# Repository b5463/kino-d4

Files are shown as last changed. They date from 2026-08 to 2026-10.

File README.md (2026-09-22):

<div align="center">
  <picture>
    <source media="(prefers-color-scheme: dark)" srcset="docs/assets/brand/kino-d4-white-on-dark.png">
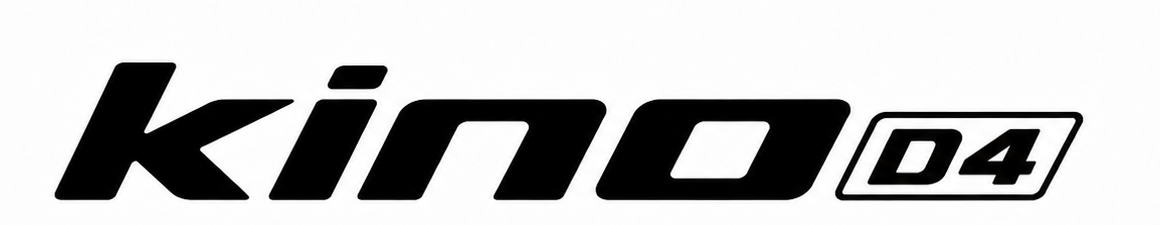
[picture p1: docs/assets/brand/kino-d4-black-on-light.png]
KINO D4
    
  </picture>

  <h3>Four cameras. One button. One moving photograph.</h3>

  <p>
    
    
    
  </p>

  <p>
    <a href="#try-studio">Try Studio</a> ·
    <a href="docs/HARDWARE.md">Hardware</a> ·
    <a href="firmware-contract/README.md">Firmware contract</a> ·
    <a href="https://github.com/users/b5463/projects/3">Project</a> ·
    <a href="docs/DEVELOPMENT.md">Build notes</a> ·
    <a href="docs/VERSIONING.md">Versions</a>
  </p>
</div>

KINO D4 is a handmade four-lens camera built for house parties. Press the shutter and four cameras fire from slightly different positions. The result can stay as four photographs or become a short, looping wiggle with real parallax.

Direct flash. 4:3 frames. Originals saved first. No cloud anywhere near the shutter.

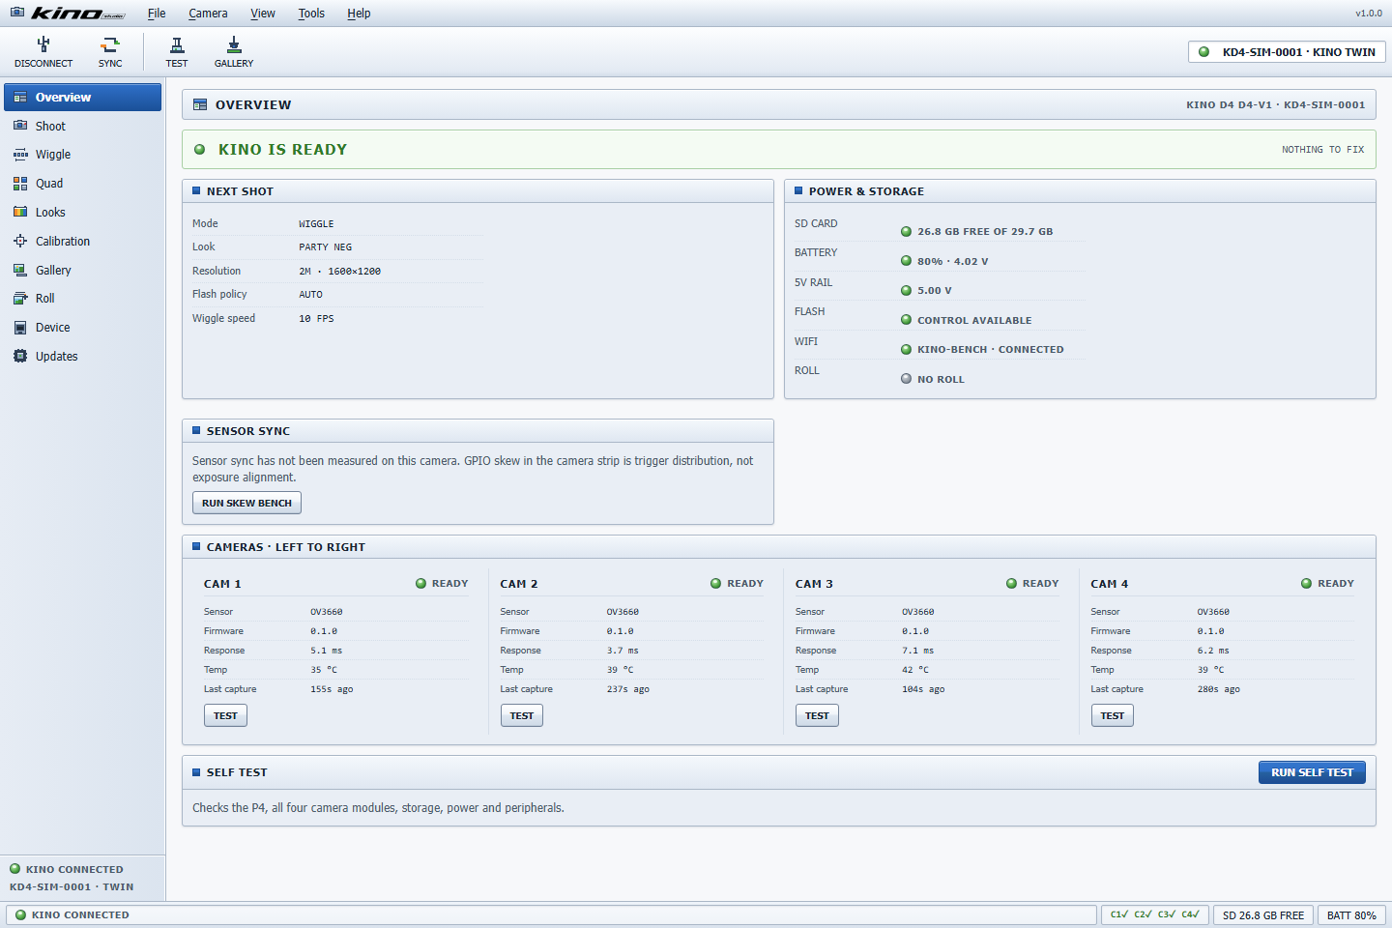
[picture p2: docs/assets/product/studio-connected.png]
KINO Studio connected to a simulated D4


<p align="center"><sub>The actual Studio overview, connected to KINO Twin — the simulated camera that ships in this repository.</sub></p>

## Why this repository exists

A five-controller camera is miserable to service with an IDE, five serial logs, and hand-edited JSON. KINO Studio puts the whole machine behind one USB cable: all four sensors, power, storage, recipes, calibration, firmware, logs, and recovery.

The repository contains that workbench, the wire protocol it speaks, the Roll backend used after capture, shared document schemas, and a reference camera that can fail on command.

> **Honest build status.** The software works against the simulated camera and is covered by tests that need no hardware. That is Studio, the protocol, the Roll backend and its workers, the guest client, and KINO Twin.
>
> There is a real camera now. Firmware 0.4.55 captures on all four cameras and writes the originals to the card. It draws its own screens. Since 0.4.4 it has uploaded to a Roll over Wi-Fi from the body itself. The body is released too: design 0.1.4, a printable PETG slab, measured rather than estimated.
>
> Three things are not finished, and it is worth naming them here rather than leaving a reader to find out.
>
> The camera has **no flash**. [`ECN-0003`](hardware/changes/ECN-0003-shutter-on-jp1-21.md) dropped the assembly and gave its enable pin to the shutter. A replacement module has not been chosen.
>
> **Exposure skew between the four cameras has never been measured.** That is the number the wiggle's quality actually rests on. Firmware reports the two skews it can observe and returns `null` for this one, with a reason.
>
> **There is no public front door yet.** The operator's line sits behind O2 carrier NAT, so `kino.acronym.sk` cannot point at the PC, and no ingress has been selected — see [the standing decision](docs/runbooks/public-ingress-options.md#standing-decision-2026-09-09). A party still works: the camera writes to its card first and uploads when it can.

## Try Studio

You need Node.js 22 or newer.

```bash
npm ci
npm run build -w @kino/studio -w @kino/twin
npm run preview:all
```

Open <http://localhost:4400/studio/>, then open <http://localhost:4400/dev/twin/> in a second tab and press **CONNECT KINO TWIN** back in Studio. KINO Twin is the simulated camera: it speaks the same protocol as hardware, so Studio exercises its full interface without a D4 on the bench.

Both apps must be served from one origin, as `preview:all` does — the bridge between them is a `BroadcastChannel`. To run them on separate dev servers instead, start `npm run twin:relay` and open Twin with `?ws=1`; Studio offers the bridge automatically in a dev build.

A physical D4 needs desktop Chrome or Edge for Web Serial.

Run the checks:

```bash
npm run lint
npm run test -w @kino/studio -w @kino/kdp -w @kino/schemas -w @kino/test-fixtures -w @kino/hardware-profiles -w @kino/simulator-engine -w @kino/three-assets -w @kino/twin -w @kino/design-system -w @kino/media -w @kino/roll-web
npm run build
```

That is every JavaScript suite that runs without Docker, and the same line CI runs. The API and worker also need PostgreSQL, Redis, and S3-compatible storage; their local stack and ports are documented in [the development guide](docs/DEVELOPMENT.md#api-stack).

Two suites are outside that line on purpose. The firmware's are C, built and run with `make -C firmware/p4/host_tests test-all` and `make -C firmware/components/kdp_core/host_tests` — 6,246 checks that need no camera, and the two that link cJSON need the IDF container. KINO Print's are Python (`npm run test -w @kino/print`), so a bare `npm test` at the root fails on a machine without Python.

## The three tools

Every screen below is a capture of the running application against the included simulator. No hardware was attached.

### KINO Studio

The workbench behind one USB cable: all four sensors, power, storage, recipes, calibration, firmware, logs, and recovery. Shown at the top of this page connected to KINO Twin.

### KINO Twin

A working 3D copy of the D4. It speaks the same KDP as real hardware: power it on, fire the shutter, watch the display, click any part for its dimensions and clearances. Measurement findings gate the enclosure lock.

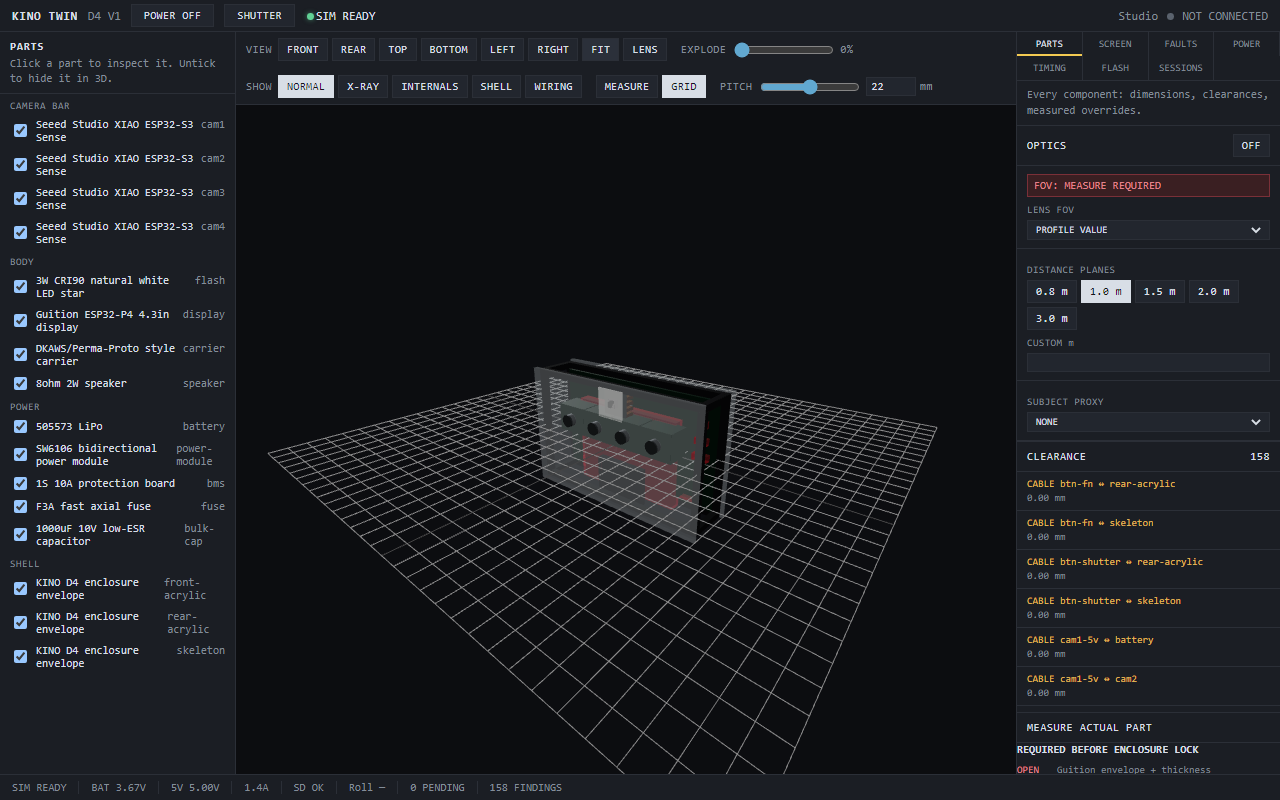
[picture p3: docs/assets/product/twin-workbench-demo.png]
KINO Twin with the simulated D4 powered on


<p align="center"><sub>KINO Twin, simulator powered on. Everything shown is simulated and labelled as such.</sub></p>

### KINO Roll

The shared album after the party. The camera uploads over Wi-Fi; guests open a link, watch photos arrive live, view the four frames behind each one, favourite and download. The client is a PWA that works on a phone at the event.

The host gets a separate surface on the same link: a dashboard that says which camera is uploading and which is stuck, hides or restores a photograph, clears the roll, and exports the lot as a ZIP. A roll can carry a PIN, and a trashed photograph stays recoverable for seven days. There is a third surface for a screen at the party — a projector page that cycles the newest captures and keeps the display awake.

The Roll is run for an event rather than hosted permanently: the origin is a laptop, reached through an outbound tunnel for the night, with no port forwarded. [`docs/runbooks/event-day.md`](docs/runbooks/event-day.md) is the procedure, and it ends by taking the tunnel down.

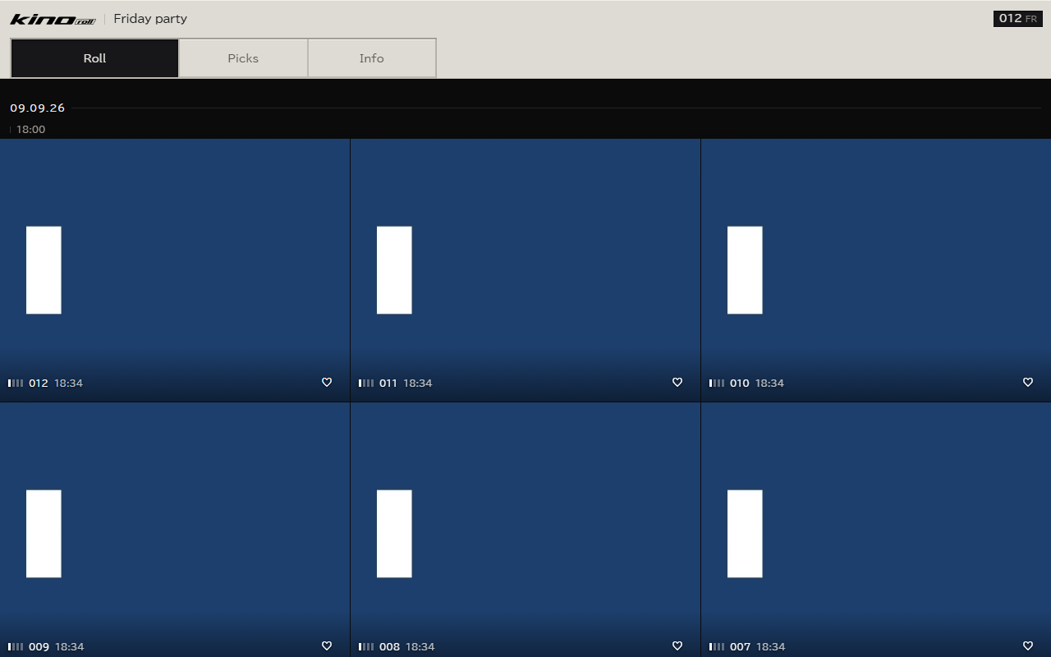
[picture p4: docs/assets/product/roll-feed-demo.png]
KINO Roll guest gallery with demo captures


<p align="center"><sub>The guest gallery with demo captures from the test uploader.</sub></p>

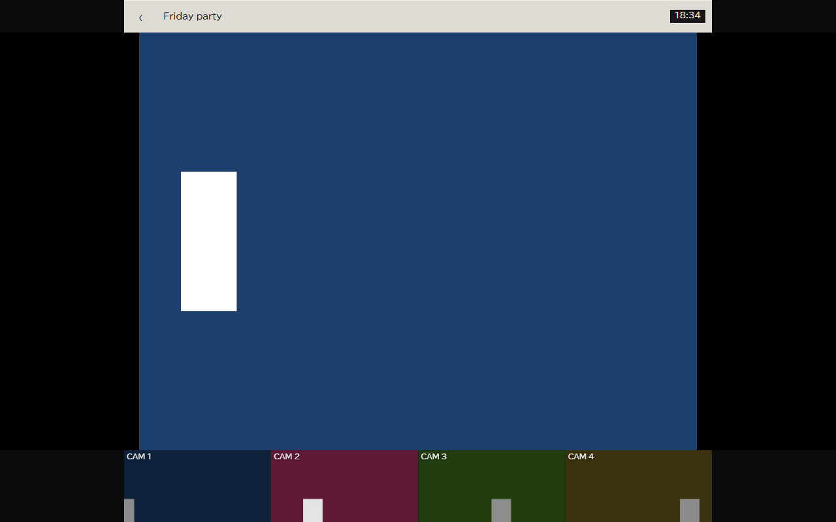
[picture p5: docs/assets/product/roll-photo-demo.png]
KINO Roll photo page with demo captures


<p align="center"><sub>One photo: the D4 frame strip switches the preview. Simulated captures.</sub></p>

### And one workshop tool

[KINO Print](apps/prusa-print-98/README.md) is not part of the camera. It is a local print host for the MK3S that prints the body, and it is here because the bodies in this repository kept failing on the bed for reasons a slicer does not warn about. It reads the PrusaSlicer metadata out of a `.gcode`, refuses to start until a person confirms the printer is physically clear, and streams the job itself. Its PETG preflight is the point: it catches a first layer that is too hot, full-temperature probing, a profile mismatch, and a nozzle that heats before the bed wait, then holds the nozzle at 170 °C through bed heating and mesh levelling and raises it just before the prime line. The source file is never modified.

## What comes out of the camera

### WIGGLE

Four matched frames play `1 → 2 → 3 → 4 → 3 → 2`. Nothing is synthesized between them. The movement comes from the four real viewpoints.

### QUAD

Each camera can use a different recipe on the same shutter press. A single capture might produce PARTY NEG, MOTION, RAW DIGI, and ACROS-ISH together.

Both modes obey the same boring, important rule: the microSD card gets the originals before anything is rendered, uploaded, cropped, or shared. Derivatives are disposable. Originals are not.

## The camera

| Part | D4 V1 hardware |
|---|---|
| Main unit | Guition JC4880P443C-I-W, ESP32-P4 + ESP32-C6, 4.3-inch 480 × 800 touch display |
| Camera row | 4 × Seeed XIAO ESP32-S3 Sense |
| Sensors | 4 × OV3660 rolling-shutter sensors, up to 2048 × 1536 |
| Storage | 32 GB microSD |
| Battery | 1S 3000 mAh LiPo |
| Flash | **Not fitted.** `ECN-0003` dropped the direct-flash assembly and gave its enable pin to the shutter; an external module will replace it and is not chosen |
| Sound | 8 Ω / 2 W speaker |
| Camera wiring | Four UART pairs plus one shared sync line |
| Body | Printed PETG slab, 131 × 90 × 65.5 mm, design 0.1.4 — two-part chassis, glued face shell, sliding lens cover, dovetail rear door |

The boards are ordinary, replaceable parts. The exact power limits, wire gauges, battery constraints, mechanical stack, and confidence level of every measurement live in [`docs/HARDWARE.md`](docs/HARDWARE.md).

Two printable bodies are released, and they are alternatives rather than versions of each other. [`KINO_FIELD_BODY`](hardware/cad/KINO_FIELD_BODY/README.md) is the one above: PETG on a desktop printer, support-free, and its release is gated by 82 automated checks over the actual meshes — that every part prints flat, and that both print jobs fit a 250 × 210 bed. [`KINO_RESIN_BODY`](hardware/cad/KINO_RESIN_BODY/README.md) is printed entirely through JLCPCB in three parts, with an MJF nylon skeleton carrying everything and a clear SLA shell that touches nothing electrical, so it can be reprinted in another colour without re-qualifying an optical dimension.

The camera knows when its cover is shut without a switch. The Hall sensor the shell used to be drilled for had to be fitted before the face shell was glued on — the one irreversible step in the assembly — so it is gone. Closed, all four lenses face an opaque plate 0.2 mm away; firmware reads a mean luminance off the frames the viewfinder already decodes and decides from all four together. It ships observing only: the two thresholds have to be read at the bench, because the sensors run auto-exposure and a covered one reports amplified noise rather than zero.

### The screen on the camera

The camera runs its own interface on the 4.3-inch panel. No phone, no laptop, nothing to pair. A card for the thing you came to do, and five rows for everything else.

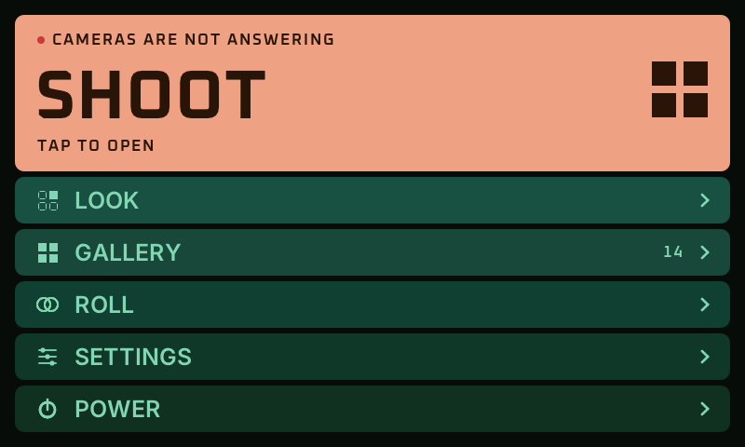
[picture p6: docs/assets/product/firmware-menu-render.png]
The D4 home screen, rendered by the firmware


<p align="center"><sub>The home screen at 800 × 480. Drawn by the firmware's own code through <code>firmware/p4/host_preview</code> — not a photograph of the panel. The chip above SHOOT is the conditions list: this render has two of its four camera stubs silent, and the screen says so before you ask it anything.</sub></p>

SHOOT is a card three times the height of anything else because the camera is not a sibling of SETTINGS. The geometry says the hierarchy, so the screen needs no status strip at all — the card carries the worst condition when there is one and how many photographs are left when there is not.

Type is Inter and Oxanium, rasterised to 8-bit coverage: Inter for everything a person reads as language, Oxanium for everything the camera says as a machine. Every corner, disc and chevron is drawn with per-pixel coverage rather than stamped from a bitmap, so no curve on the panel has a hard edge on it. The six menu marks are drawn too. No raster artwork is left in the interface.

#### It boots by showing you the camera

The startup screen is not a logo. It is a field of small glyphs on a square lattice, and both of the things it does carry a fact about the machine that is waking up.

<p align="center">
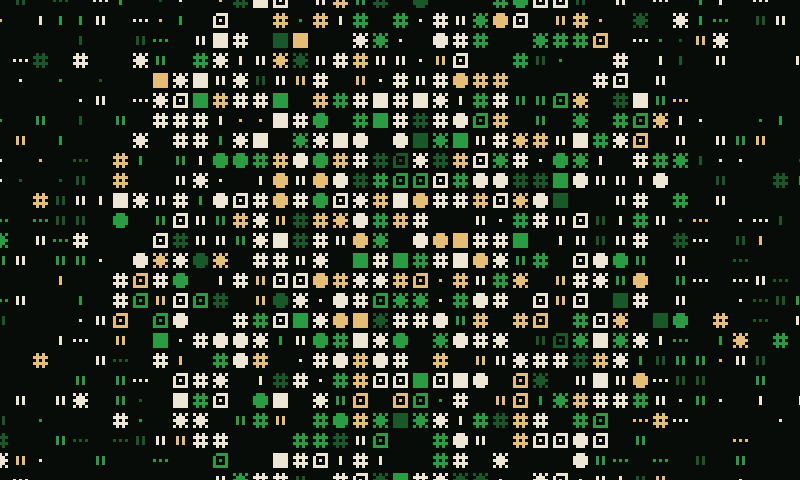
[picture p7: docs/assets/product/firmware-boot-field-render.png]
The boot field with all four cameras answering
  
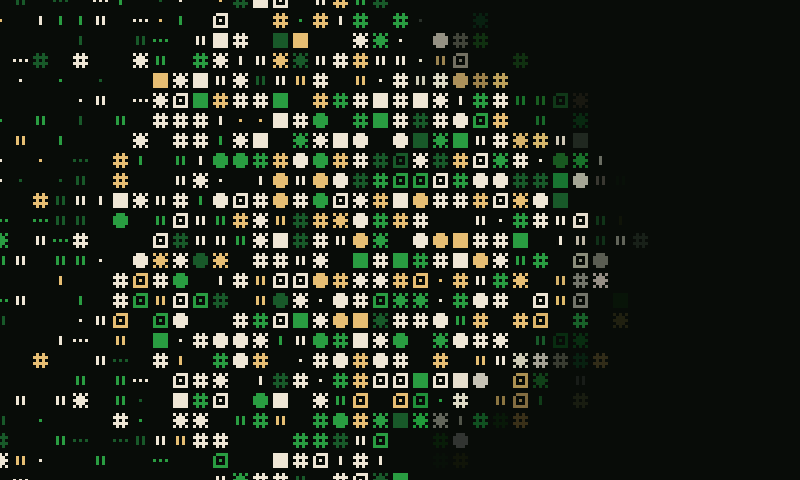
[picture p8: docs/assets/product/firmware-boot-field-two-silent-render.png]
The boot field with two cameras silent
  
</p>

<p align="center"><sub>Left: four cameras answering. Right: the same body with cameras 2 and 4 silent. Both are firmware renders.</sub></p>

**How far the field reaches is how many of the four cameras have answered** — one quadrant each, cam 1 top left, the way the four sit on the viewfinder and on the body. A node that answers part-way through the boot opens its quarter out instead of appearing. So a camera with a dead node says so on the first screen it shows, without a word of type, in the product's own mark.

**What colour it is, is the look it will shoot with.** The field comes up cold and travels to the look's own colours as the cameras answer. A given look brings the same colour up every time, so the way your camera starts becomes something you know about it.

#### The rest of it

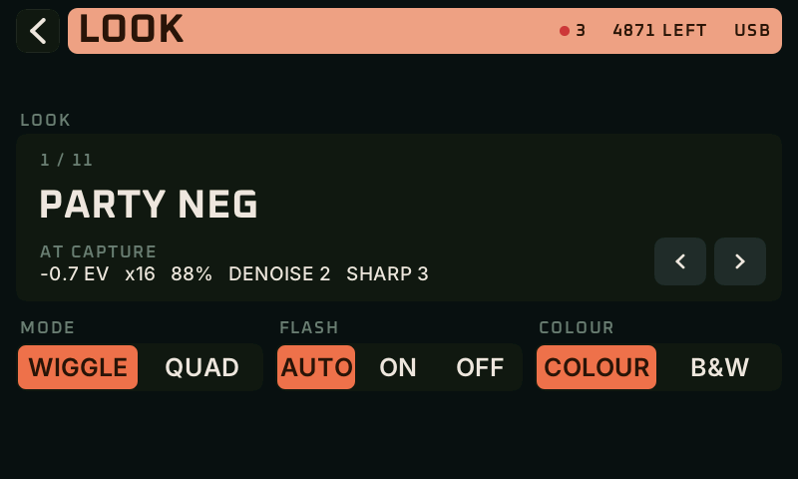
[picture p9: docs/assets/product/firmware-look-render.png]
The LOOK screen


<p align="center"><sub>LOOK: the recipe in force, what it does at capture, and the three things you can change about it.</sub></p>

ROLL is the screen that matters at a party. It shows the QR a guest scans, the address for anyone who would rather type it, one word for the connection, and a count that comes from the card rather than from the server.

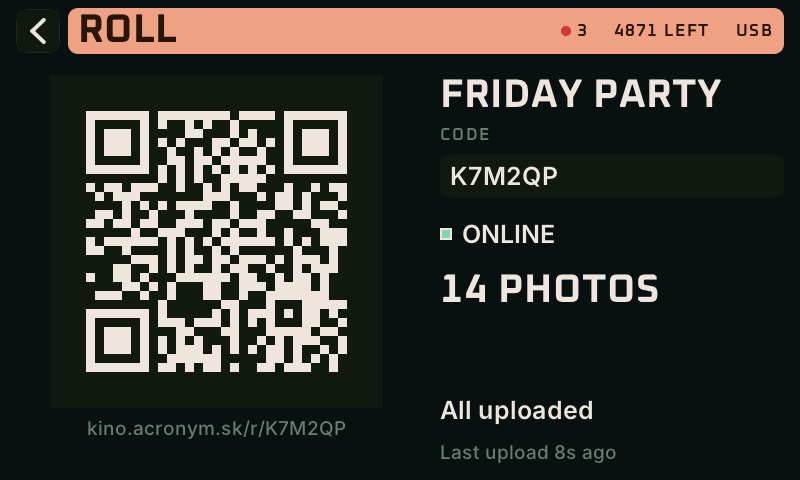
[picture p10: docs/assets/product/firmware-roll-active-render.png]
The ROLL screen with a QR code and upload state


<p align="center"><sub>Also a firmware render. The roll name and code are invented for the render.</sub></p>

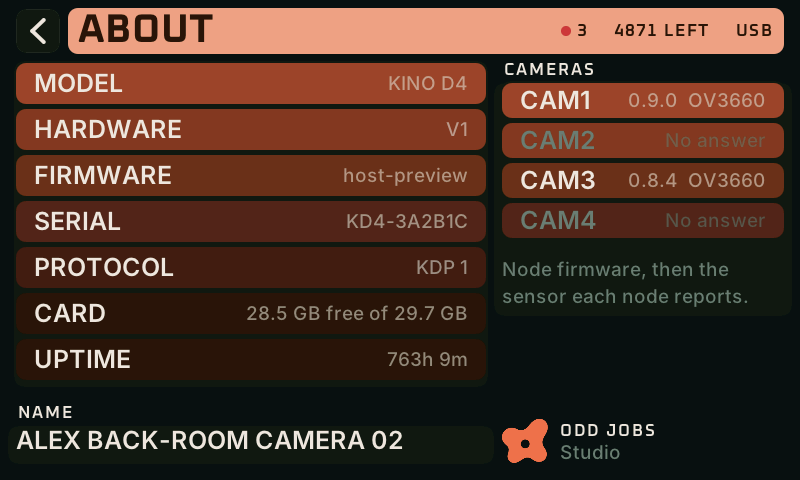
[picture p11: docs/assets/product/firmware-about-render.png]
The ABOUT screen


<p align="center"><sub>ABOUT: what this unit is, what each of the four cameras is running, and who made it.</sub></p>

All of these come out of a program that compiles `ui.c` and draws the screens on a workstation. It renders 190 of them, including every failure state — a card that will not mount, a server that has stopped answering, a capture that saved three frames out of four. Looking at the interface used to mean a build, a flash and a serial capture; now it is one command:

```bash
make -C firmware/p4/host_preview && firmware/p4/host_preview/preview out/
```

The same program is a gate, not just a viewer: it fails the run if any screen sets type outside the page margin. Clipping is the obvious fault, but the one an interface actually has is a sentence ending two pixels from the bezel — that does not look broken, it looks cheap, and it is much harder to catch by eye. It found four screens doing it the day it was written.

## One cable, five controllers

```mermaid
flowchart LR
    C1["CAM 1"] -->|"UART"| P4["ESP32-P4"]
    C2["CAM 2"] -->|"UART"| P4
    C3["CAM 3"] -->|"UART"| P4
    C4["CAM 4"] -->|"UART"| P4
    P4 --> SD["microSD originals"]
    P4 <-->|"KDP / USB"| Studio["KINO Studio"]
    P4 -->|"Wi-Fi after capture"| Roll["KINO Roll"]
    Twin["KINO Twin"] -.->|"the same KDP"| Studio
```

Feature code in Studio never reaches around the device API to poke a serial port. Real hardware, the test camera, and KINO Twin all go through the same framing, CRC checks, timeouts, commands, and capability negotiation.

That boundary matters. A simulator that gets special treatment is only a mockup. A simulator that speaks the real protocol can expose real bugs.

## The hard part is time

A shared GPIO edge does not make four rolling shutters expose at the same instant. KINO keeps three different measurements separate:

| Measurement | What it actually tells us |
|---|---|
| GPIO distribution skew | When each camera node handled the trigger |
| VSYNC phase skew | Where each sensor was in its rolling frame cycle |
| Effective exposure skew | When the scene was recorded |

A trigger spread under 100 µs can still hide 10 to 30 ms between real exposures. Studio reports the three values separately. If firmware cannot measure one of them, it returns `null` and says why.

## Repository map

| Path | Owns |
|---|---|
| [`firmware`](firmware/README.md) | What runs on the camera: the ESP32-P4 application, the four camera nodes, the C6 radio image, and the host test suites |
| [`apps/studio`](apps/studio) | Camera setup, shooting, looks, media, firmware, recovery, diagnostics |
| [`apps/api`](apps/api) | Rolls, authentication, uploads, object storage, live events |
| [`apps/worker`](apps/worker) | Derivative jobs, recaps, exports, trash purge |
| [`apps/roll-web`](apps/roll-web) | Public Roll guest PWA and private host dashboard |
| [`apps/twin`](apps/twin) | KINO Twin: 3D assembly, simulation, measurement, engineering exports |
| [`apps/prusa-print-98`](apps/prusa-print-98/README.md) | KINO Print: the local USB print host that prints the body, with the PETG preflight that stops a bad job |
| [`packages/kdp`](packages/kdp) | The KINO Device Protocol: frames, CRC, commands, transports, request lifecycle |
| [`packages/schemas`](packages/schemas) | Versioned `kino.*` documents shared across processes |
| [`packages/test-fixtures`](packages/test-fixtures) | Reference camera, recipes, media, and injected failures |
| [`packages/media`](packages/media) | Wiggle sequencing and playback, shared by the worker and the clients |
| [`packages/design-system`](packages/design-system) | The shared interface vocabulary |
| [`packages/hardware-profiles`](packages/hardware-profiles) | Board and sensor profiles the simulator and Studio read |
| [`packages/simulator-engine`](packages/simulator-engine) | The device simulation behind KINO Twin |
| [`packages/three-assets`](packages/three-assets) | Geometry and materials for the 3D twin |
| [`firmware-contract`](firmware-contract) | The contract camera firmware must implement, and every recorded deviation from it |
| [`hardware`](hardware) | BOM, wiring, assembly, acceptance tests, two released printable bodies, and the Rev1 mainboard schematic |
| [`infra`](infra/README.md) | Compose files, the deploy script, backups, and the load and latency harnesses |
| [`kino_dev_spec_pack`](kino_dev_spec_pack) | Permanent Studio and Roll product specifications |
| [`kino_twin_spec`](kino_twin_spec) | The 3D twin and virtual-device specification |

## Read the right thing

This project has history, and some old planning material is still useful. It is not always current. Start with [`docs/README.md`](docs/README.md), which says which source wins when code and prose disagree.

- [Hardware reference](docs/HARDWARE.md): parts, dimensions, power, wiring, and what still needs measuring
- [Architecture](docs/ARCHITECTURE.md): process boundaries, state ownership, uploads, and package relationships
- [Development](docs/DEVELOPMENT.md): setup, services, migrations, tests, and protocol changes
- [Troubleshooting](docs/TROUBLESHOOTING.md): browser, USB, protocol, power, sync, media, recovery, and API failures
- [Firmware contract](firmware-contract/README.md): the handoff extracted from working protocol source, and every deviation the firmware is allowed
- [Firmware](firmware/README.md): what runs on the camera, how to build all three configurations, and what each host suite covers
- [Hardware build package](hardware/README.md): BOM, wiring, assembly order, and acceptance sheet
- [Field body](hardware/cad/KINO_FIELD_BODY/README.md) and [resin body](hardware/cad/KINO_RESIN_BODY/README.md): the two printable bodies, their measured inputs, and the gates each release passes
- [Running an event](docs/runbooks/event-day.md): the whole night, from bringing the stack up to taking the tunnel down
- [Restoring from backup](docs/runbooks/restore.md) and [what to watch](docs/runbooks/observability.md): the two things needed when a party is already underway
- [Host guide](docs/roll/HOST_GUIDE.md): the Roll dashboard, written for whoever is running the camera rather than for a developer
- [Contributing](CONTRIBUTING.md): required contracts, tests, measurements, and pull request rules
- [Roadmap](ROADMAP.md): current work and the deliberately unfinished edges
- [Releasing](docs/RELEASING.md): independent versions, compatibility review, artifacts, and publishing
- [Versioning](docs/VERSIONING.md): software, protocol, schema, database, and hardware revision rules
- [Security](SECURITY.md): private reporting and the high-risk surfaces
- [Brand assets](docs/assets/brand/README.md): the four split D4 marks and where each belongs
- [Product media](docs/assets/product/README.md): real and simulated asset rules plus the physical shot list

The short version: tested protocol source beats old prose, unknown hardware measurements stay unknown, originals are immutable, and firmware changes are finished only when the contract and tests move with them.

## License

KINO software and general documentation use the [MIT License](LICENSES/MIT.txt). Physical design source uses [CERN-OHL-S-2.0](LICENSES/CERN-OHL-S-2.0.txt), which keeps distributed hardware modifications open. Logos, wordmarks, product media, and the unaudited recovery archive remain reserved.

[`LICENSE`](LICENSE) explains the boundary, [`REUSE.toml`](REUSE.toml) records it for SPDX tooling, and [`TRADEMARKS.md`](TRADEMARKS.md) keeps compatible forks distinct from official KINO releases.

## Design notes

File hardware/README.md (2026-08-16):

# KINO D4 hardware package

This directory holds the files needed to turn the D4 V1 parts list into a repeatable physical build.

## Build files

| File | Purpose |
|---|---|
| [`BOM.csv`](BOM.csv) | Parts, quantities, confidence, and unresolved purchasing details |
| [`WIRING.md`](WIRING.md) | Power topology, camera harnesses, signal directions, and the open GPIO map |
| [`ASSEMBLY.md`](ASSEMBLY.md) | Mechanical and electrical build order with checkpoints |
| [`TESTING.md`](TESTING.md) | Bring-up, load, sync, thermal, and final acceptance record |
| [`cad/`](cad/) | Mechanical source and exports once dimensions are measured |
| [`pcb/`](pcb/) | Carrier-board source if D4 moves beyond perfboard |

The maintained narrative reference remains [`docs/HARDWARE.md`](../docs/HARDWARE.md). The structured component list in [`kino_twin_spec/component-manifest.json`](../kino_twin_spec/component-manifest.json) feeds the digital twin. Keep all three aligned.

## Revision and license

[`REVISION`](REVISION) names the physical compatibility line. [`manifest.json`](manifest.json) gives the independently moving design-package version and artifact revisions. Every design change needs an [engineering change notice](changes/README.md) and a matching entry in [`CHANGELOG.md`](CHANGELOG.md).

This hardware source is licensed under CERN-OHL-S-2.0. The source location is <https://github.com/b5463/kino-d4>. See the root [`LICENSE`](../LICENSE), the unmodified [license text](../LICENSES/CERN-OHL-S-2.0.txt), and the machine-readable [`REUSE.toml`](../REUSE.toml).

## Confidence

A row in the BOM is not proof that a dimension fits. Dimensions and limits must carry one of the confidence labels from the hardware reference. `PROVISIONAL`, `CONFLICT`, and `MEASURE_REQUIRED` block final CAD.

## Revision rule

These files describe D4 V1. A change that breaks enclosure, wiring, firmware pin mapping, or replacement-part compatibility needs a new hardware revision. Do not edit V1 into a different camera while keeping the same name.

## Missing physical records

The repository still needs measured photographs, caliper records, final GPIO assignments, a locked carrier layout, and electrical test sheets from the assembled camera. The checklists here make those gaps visible. They do not claim the tests have been run.

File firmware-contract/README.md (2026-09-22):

# KINO firmware contract

The canonical reference the firmware team implements against.

Everything in these four files is **extracted from working source**, not designed here. Where the
implementation and the spec pack disagree, the implementation wins and the difference is recorded
under [Deviations](#deviations). No document in this directory introduces new protocol behavior.

| File | Contents |
|---|---|
| [`kdp-framing.md`](kdp-framing.md) | Byte layout, CRC, flags, sequence IDs, decoder requirements, payload limits |
| [`commands.md`](commands.md) | Every command and event with its numeric value, direction and payload shape; HELLO, NACK, session and job semantics |
| [`schemas.md`](schemas.md) | Portable document schemas (`kino.*`), envelope and migration rules, the timing-block contract |

## Source of truth

The prose here can rot. These files cannot — they are compiled, tested and shipped:

| Authority | Path | Covers |
|---|---|---|
| Framing | `packages/kdp/src/protocol/packet.ts` | Encoder, decoder, `MAX_PAYLOAD` |
| CRC | `packages/kdp/src/protocol/crc32.ts` | CRC-32 implementation |
| Command / event / flag values | `packages/kdp/src/protocol/commands.ts` | `Cmd`, `Evt`, `FrameFlags`, `PROTOCOL_VERSION` |
| Wire payload types | `packages/kdp/src/protocol/types.ts` | TypeScript interfaces for command payloads |
| Client semantics | `packages/kdp/src/protocol/KinoProtocolClient.ts` | Handshake, timeouts, event routing, job lifecycle |
| Timing vocabulary | `packages/kdp/src/protocol/timing.ts` | The three skew metrics and their grading bands |
| Portable document schemas | `packages/schemas/src/*.ts` | `kino.*` zod schemas, versions, migrations |
| Reference device | `packages/test-fixtures/src/MockKinoDevice.ts` | A working device-side implementation of everything below |

**If a payload shape appears in this contract but not in `types.ts`, it is marked "reference mock
only".** That means the shape is what `MockKinoDevice` produces and what Studio consumes today, but
it has no compile-time type behind it. Firmware should match it; treat it as slightly softer than
the typed surface.

Two distinct type systems are in play and must not be confused:

- **Wire payloads** (`@kino/kdp` `types.ts`) — what travels inside a KDP frame. Plain TypeScript
  interfaces, not versioned individually, covered by `PROTOCOL_VERSION`.
- **Portable documents** (`@kino/schemas`) — what gets persisted, exported, uploaded or backed up.
  Each carries `schema` + `version` and has its own migration path. See [`schemas.md`](schemas.md).

Firmware produces both. They overlap in subject (a capture, a device, a config) and differ in shape.

## What is not here: the camera's HTTP upload API

This directory covers **KDP only** — the framed protocol the camera speaks over USB-C and the
`kino.*` documents it produces. It does not describe how a capture reaches the KINO Roll server.

The camera's server-facing contract is HTTP, it is normative, and it lives in
[`docs/roll/ROLL_DEVICE_CONTRACT.md`](../docs/roll/ROLL_DEVICE_CONTRACT.md). Read it for device
registration and the bearer token, joining a roll, the multipart `init` / `part` / `complete`
sequence and its part size, the `<captureUuid>:<role>:<frameIndex>` idempotency key, resume after a
power loss, and which HTTP status the firmware must retry versus refuse.

Which document answers what:

| Question | Document |
|---|---|
| Frame layout, CRC, sequence ids, payload cap | [`kdp-framing.md`](kdp-framing.md) |
| Command and event ids, payload shapes, job semantics | [`commands.md`](commands.md) |
| `kino.*` document fields, versions, migrations | [`schemas.md`](schemas.md) |
| Any HTTP request the camera makes to a Roll server | [`docs/roll/ROLL_DEVICE_CONTRACT.md`](../docs/roll/ROLL_DEVICE_CONTRACT.md) |
| Whether a Roll upload behaviour is implemented, and where it stops | [`docs/roll/PHYSICAL_DEVICE_FLOW.md`](../docs/roll/PHYSICAL_DEVICE_FLOW.md) |

The upload contract is not copied here, and must not be: two copies of a retry rule is one copy
that is wrong. Its authority is the same as this directory's — `apps/api/src` and the committed
migrations — and it records its own deviations. The overlap between the two is only the
vocabulary: a role, a `frameIndex` and a `captureUuid` mean the same thing on both sides, and
[`schemas.md`](schemas.md) is where those are defined.

## Versioning

| Constant | Value | Where |
|---|---|---|
| `PROTOCOL_VERSION` | `1` | `commands.ts` — goes in the `VERSION` header byte and is negotiated by HELLO |
| `CONFIG_SCHEMA_VERSION` | `1` | `types.ts` — the config envelope's `schemaVersion` on the wire |
| All `kino.*` document schemas | `1` | `packages/schemas/src/*.ts` |

Rules:

- A **compatible** addition (new optional field, new command id, new capability flag) does not bump
  `PROTOCOL_VERSION`. Every parser on both sides tolerates unknown fields; unknown command ids get a
  `UNSUPPORTED_COMMAND` NACK. Gate new behavior behind a capability flag, never behind a version bump.
- A **breaking** change to framing or to an existing payload's meaning bumps `PROTOCOL_VERSION`, and
  the device must then accept the older version too for as long as it advertises it in HELLO's
  selected range.
- Document schema versions bump independently of `PROTOCOL_VERSION` and carry a migration function
  per step. See [`schemas.md`](schemas.md).

## Deviations

Recorded, not resolved. The implementation column is normative.

### D1 — Recipe vs Look: one concept, two names, split by layer

Spec 04§7 names the commands `GET_LOOKS` / `SET_LOOK` / `UPLOAD_LOOK` / `DELETE_LOOK`. Source names
them `GET_RECIPES` (0x22) / `SET_RECIPE` (0x23) / `UPLOAD_RECIPE` (0x24) / `DELETE_RECIPE` (0x25).

**The two names are not interchangeable — which one is correct depends on the layer:**

| Layer | Name | Where |
|---|---|---|
| KDP wire commands | **`*_RECIPE`** | `Cmd.GET_RECIPES` … `Cmd.DELETE_RECIPE`, `commands.ts` |
| KDP wire payload fields | **`recipe`** | `DeviceInfo.activeRecipe`, `CaptureSummary.recipeIds`, `WiggleConfig.recipeId`, `QuadSlotConfig.recipeId` — `types.ts` |
| `kino.capture` portable document | **`look`** | `look: z.string().optional()`, `packages/schemas/src/media.ts` |

Same value, two field names, and **crossing them fails silently.** `kino.capture` is a
`.passthrough()` schema and `look` is optional, so a device that writes `"recipe": "party-neg"` into a
capture document parses **clean** — no error, no warning. The unknown key is preserved verbatim, `look`
is simply absent, and every consumer that reads `look` sees a capture with no look reference. This is
a data-loss bug that validation cannot catch for you.

Firmware rules:

- Send `*_RECIPE` command ids and `recipe*` field names **on the wire**.
- Write `look` — never `recipe` — in a **`kino.capture`** document.
- The numeric command values are unambiguous either way; the document field name is not.

### D2 — `kino.device-info` vs `kino.device`

01§3 lists the schema identifier as `kino.device-info`; 05§19 prints the same example under
`"schema": "kino.device"`. `packages/schemas/src/device.ts` implements `kino.device-info`.

**Normative string: `kino.device-info`.** 05§19 is a spec inconsistency, not a second schema.

### D3 — Network / Roll / upload-queue numeric values

Spec 04§7 lists ten of these commands by name only and assigns no values. This repo allocated them,
plus `UPLOAD_ENQUEUE`, which 04§7 does not list at all — 02§16 requires a "push to Roll" gallery
action and no command existed to carry it, so it took the next free slot in the same block:

| Command | Value |
|---|---|
| `NETWORK_LIST` | `0xa0` | Optional request `{ "scan": true }` runs one bounded scan and adds `available[]` (`ssid`, `bssid`, `rssi`, `channel`, `security`, `hidden`), `scanMs` and `scanComplete` to the reply. Without it the reply is the saved `networks[]` only, unchanged. |
| `NETWORK_SET` | `0xa1` |
| `NETWORK_DELETE` | `0xa2` |
| `NETWORK_STATUS` | `0xa3` | Optional request `{ "probe": true }` adds `probe`: a timed DNS lookup of the API host (`dnsMs`, `dnsOk`, `family`) and one unauthenticated `GET /api/healthz` through the Roll HTTP client (`httpMs`, `httpStatus`, `totalMs`, `tls`, `detail`) - certificate verified, trusted clock required, no registration. Without it the reply is the saved status only, unchanged. |
| `SET_CONFIG` / `GET_CONFIG` | `network.apiBase` | Optional stored development override for the Roll API base, `http://host[:port]` or `https://host[:port]`, no path, no credentials. When set and valid it replaces the compiled production default (`https://kino.acronym.sk`) for every API request; `GET_CONFIG` shows it; `SAVE_CONFIG` persists it. This is the only way an `http://` base can reach the HTTP client. `C6_TLS` is never marked validated over an `http://` base, whatever the request succeeds at. |
| `ROLL_STATUS` | `0xa4` |
| `ROLL_CREATE` | `0xa5` |
| `ROLL_JOIN` | `0xa6` |
| `ROLL_LEAVE` | `0xa7` |
| `UPLOAD_QUEUE_STATUS` | `0xa8` |
| `UPLOAD_QUEUE_RETRY` | `0xa9` |
| `UPLOAD_ENQUEUE` | `0xaa` |

**These values are normative.** They sit deliberately above the `0x80`–`0x89` event range so a
command id and an event id can never collide in a protocol trace.

### D4 — `SYNC_BENCH` numeric value

Spec 04§7 lists `SYNC_BENCH` in the Diagnostics group and assigns no value. This repo allocated the
next free slot in KDP's diagnostics range (`0x40`–`0x45` were taken): `Cmd.SYNC_BENCH = 0x46` in
`packages/kdp/src/protocol/commands.ts`.

**`0x46` is normative.** Firmware implements `SYNC_BENCH` at `0x46`.

### D5 — Async job model additions

Spec 04§15 defines the job model in three bullets. Source adds concrete lifecycle rules that firmware
must respect on the wire — no events after `JOB_COMPLETE`/`JOB_FAILED`, no jobId reuse within a
session. Full wire expectations in [`commands.md § Async job model`](commands.md#async-job-model).

### D6 — Timing telemetry: all three keys required when the block is present

04§13 says "return null + reason" if a skew is unavailable. Source hardens this: when a
`kino.capture.timing` block is present, **all three** of `gpioTriggerSkewUs`, `vsyncPhaseSkewUs`,
`effectiveExposureSkewUs` must be present as `number | null`. Omitting a key is not a substitute for
`null` — an absent field reads as "this build has no such concept", `null` reads as "measured,
unavailable here". Only the whole block is optional. `unavailableReason` is optional and explains the
nulls. See [`schemas.md § Timing block`](schemas.md#timing-block).

### D7 — Payload cap is 16384, not ~4096

04§3 says "routine payload max ~4096 bytes" and "firmware chunk 4096–8192". `packet.ts` sets
`MAX_PAYLOAD = 16384` and the decoder rejects any declared length above it.

**16384 is the normative decoder limit.** The spec's figures are budget guidance, not a wire limit.
The reference device negotiates an 8192-byte chunk size for firmware and sound uploads.

### D8 — Command surface differs from spec 04§7's name lists

04§7 lists intended command groups. The implemented surface differs. Source is normative.

Spec commands **not implemented** — a firmware build may answer these with `UNSUPPORTED_COMMAND`
until they are added to `commands.ts`:

| Spec 04§7 name | Status in source |
|---|---|
| `GET_CONFIG_SCHEMA` | Not a command. `GET_CAPABILITIES` returns `configSchemaVersion` instead |
| `PATCH_CONFIG` | Not a command. `SET_CONFIG` takes a partial config and deep-merges it |
| `CAMERA_DISARM` | Absent (`CAMERA_ARM` 0x31 exists) |
| `CAMERA_PREVIEW_START` / `CAMERA_PREVIEW_STOP` | Replaced by a single-frame pull, `CAMERA_PREVIEW` 0x34 |
| `CAMERA_GET_TIMING` | Replaced by `CAMERA_CAPTURE` 0x33 with `{"action":"timing-test"}` |
| `GET_PROFILES` / `SET_PROFILE` | Absent |
| `GALLERY_LIST`, `CAPTURE_GET`, `ASSET_GET`, `ASSET_DELETE`, `CAPTURE_DELETE` | Replaced by the `MEDIA_*` group, `0x70`–`0x75` |
| `STORAGE_CHECK` / `STORAGE_FORMAT` | Absent (`GET_STORAGE_STATUS` 0x05 reports, does not act) |
| `UART_STRESS_TEST` | Named `LINK_BENCH` 0x44 |
| `FLASH_TEST` | Replaced by `CAMERA_CALIBRATE` 0x35 with `{"action":"flash-test"}` |
| `SPEAKER_TEST` / `BUTTON_TEST` | Absent — both are checks inside `SELF_TEST` 0x42 |
| `FW_ROLLBACK` | Allocated as `Cmd.FW_ROLLBACK` = `0x66` in `commands.ts` and reserved, but no firmware implements it — the D4 V1 P4 answers `UNSUPPORTED_COMMAND` from the dispatcher's default case (see [D15](#d15--targetid-gained-c6-and-fw_query-is-implemented-without-the-rest-of-fw_)). The reserved request/response shape is in `docs/RELEASE_TRUST.md`; `ROADMAP.md` carries it as future work. **The opcode is not free.** |

Source commands **not in spec 04§7** — repo additions, normative. Every opcode
here is allocated; none of them is a free slot:

| Command | Value | Note |
|---|---|---|
| `GET_SOUNDS` … `SOUND_DELETE` | `0x26`–`0x2b` | Custom shutter-sound storage, chunked upload |
| `CAMERA_PHASE` | `0x36` | VSYNC phase measurement and re-phasing (04§14 calls for it in prose) |
| `GET_RUNTIME_STATS` | `0x43` | Heap, temps, protocol counters |
| `SET_LINK_BAUD` | `0x45` | Camera UART baud switching |
| `SYNC_BENCH` | `0x46` | SYNC-line edge counter. Blocking, and it reports no skew — see [`commands.md`](commands.md#sync_bench--0x46) and [D4](#d4--sync_bench-numeric-value). Implemented |
| `STORAGE_SELF_TEST` | `0x47` | Non-destructive card round trip with a named failing phase. Milestone 1B (#66). Implemented |
| `CAMERA_LINK_STATS`, `CAMERA_LINK_STATS_RESET` | `0x48`, `0x49` | Per-channel UART counters. Milestone 1B (#66). Implemented |
| `CAMERA_SOAK_TEST` | `0x4a` | Async capture soak run. Milestone 1B (#66). Implemented |
| `GET_HW_VALIDATION` | `0x4b` | The runtime hardware-validation registry, 56 items. Milestone 1B (#66). Implemented |
| `STORAGE_BENCH` | `0x4c` | Sustained throughput and per-block write latency; `worstBlockMs` is the figure that decides a four-frame burst. Milestone 1B (#66). Implemented |
| `C6_RESET_BENCH` | `0x4d` | **Bench only, private.** One reset pulse to the C6 while the P4 keeps running, so ROLL-C test 3 can be run. Only a P4 built with `-DKINO_C6_RESET_BENCH=1` handles it; every other build NACKs `UNSUPPORTED_COMMAND` and moves no pin. Not gated by a capability, because no product client may send it |
| `MEDIA_THUMB`, `MEDIA_FAVORITE` | `0x72`, `0x75` | |
| `NETWORK_*`, `ROLL_*`, `UPLOAD_*` | `0xa0`–`0xaa` | Network, Roll membership and the upload queue (04§7 prose). Above the event range so a command id and an event id can never collide in a trace |

### D9 — Gallery cursor is a number, not an opaque string

04§9's example shows `"nextCursor": "opaque_cursor"` and a `filters` object in the request.
`MediaListResponse` in `types.ts` types `nextCursor` as `number | null`, and `MediaListRequest` has
`cursor?: number` and `limit?: number` with no `filters`. **Source is normative.** The reference
device caps `limit` at 100 and reports `total` and `hasMore` alongside.

### D10 — `PowerStatus.batteryV` / `batteryPct` are null on D4 V1: there is nothing to measure

`PowerStatus` in `types.ts` typed `batteryV: number` and `batteryPct: number` as required, and made
`busV`, `chargingA` and `fuse` optional with the note that a firmware without a rail ADC omits them
so *"Studio shows '—' rather than inventing 5.00"*.

**Resolved in the type, 2026-08-31.** Both fields are now `number | null`, and `batteryMeasured` and
`displayStage` are declared beside them. The deviation was one-sided: the firmware sent `null`, the
type promised a `number`, and every consumer that wrote `power.batteryV.toFixed(2)` compiled clean
and threw on a real body. A contract entry recording that the type is wrong is worth less than a
type that is right — the note stays because the *hardware* gap it describes has not closed.

**D4 V1 cannot measure the cell either.** The 505573 LiPo reaches the board through a protection
board and an SW6106 charger/boost carrier, and neither the pack nor the carrier routes a sense
divider or a fuel-gauge bus to the P4 — `docs/HARDWARE.md` §Battery and power describes the path and
no GPIO in the 2×13 header carries battery telemetry. Nothing in the camera knows the voltage.

The P4 firmware therefore sends **`null`** for both, not `0`:

| Field | 0.1.x value | Why |
|---|---|---|
| `batteryV` | `null` | `0` is a number a client draws as a flat battery. A wrong reading is worse than an absent one. |
| `batteryPct` | `null` | Same. |
| `batteryMeasured` | `false` | Added field, so a client need not infer intent from a null. |
| `state` | `"usb"` \| `"battery"` | Derived from whether a host is talking to us, **not** from the power path — the SW6106 feeds the same 5 V rail either way. |
| `charging` | `false` | Not sensable. Never reported true on this hardware. |

Clients must check `capabilities.powerTelemetry` before reading either field; 0.1.x reports it
`false`. `capabilities.powerManagement` is separately `true`, because the *other* half — `autoDimS`,
`sleepS` and `camIdleTimeoutS` from `BodyConfig` — is implemented and does work. Two flags, because
a client that wants to draw a battery and a client that wants to set a sleep timeout are asking
different questions.

This is a hardware gap, not a protocol one. It closes when the V2 carrier routes a divider or a
gauge; the field types do not need to change.

### D11 — `BodyConfig.brightness` and the dim stage have no hardware on D4 V1

`BodyConfig.brightness` is `1..10` and `autoDimS` implies a dimmed state between awake and asleep.
The Guition carrier drives the panel backlight from a plain GPIO, not a PWM channel, so the only
achievable states are lit and dark.

0.1.x therefore honours `sleepS` (backlight off) and `camIdleTimeoutS` (camera bank off via
`CAM_PWR_EN`) exactly, tracks and reports the `dim` stage in `GET_POWER_STATUS.displayStage` so a
client can show where the timeout has got to, and **ignores `brightness`**. The setting is stored and
returned unchanged rather than silently rewritten, so it is ready the moment the pin gets a
transistor.

### D12 — `jpegQuality` is a percentage on the wire and the inverse on the sensor

`jpegQuality` is documented `// 60..95` in `types.ts` and `recipeTypes.ts`, and Studio's sliders
present it that way: higher is better. `esp32-camera`'s `set_quality()` takes **5..63, where lower is
better**, and the camera node clamps to that range.

Nothing converted between them. A value of 85 sent down the node link arrived as a request for
quality 63 — the *worst* JPEG the sensor can produce — and 95 did the same. Both numbers are inside
the other scale's range, so neither end could detect it; the only symptom was that asking for better
quality made the picture worse.

0.3.0 converts in one place, `capture_quality_to_sensor()`, mapping 60..95 onto 20..5. The wire
contract is unchanged: the percentage is what Studio sends and what the settings envelope stores.

### D13 — the shared trigger wire is driven, and coordinates nothing yet

`GPIO32` (`BOARD_SYNC_OUT`, JP1 pin 19) is pulsed for 200 µs at the start of every capture, and the
pulse is timed and logged. **The camera nodes do not arm on that edge.** They expose when their
`NL_CMD_CAPTURE` arrives over their own UART, exactly as they did before the wire was driven.

The pulse exists so the trace is proven and the node-side arm becomes a node change alone. Until it
does, the four frames of a capture are separated by however long it takes to wake four workers and
put four commands on four UARTs. `kino.capture.timing` reports that figure as `dispatchSpreadUs`,
under its own name, and reports all three of `gpioTriggerSkewUs`, `vsyncPhaseSkewUs` and
`effectiveExposureSkewUs` as `null` with an `unavailableReason`.

Dispatch spread is not exposure skew and must never be presented as it: the sensors free-run with a
rolling shutter, so when a command arrived says nothing certain about when light was integrated (04
§14). `CAMERA_CAPTURE` with `action: "timing-test"` is refused with `UNSUPPORTED_COMMAND` rather than
answered, and `GET_CAPABILITIES` reports `vsyncTelemetry: false`.

`SYNC_OUT` is its own net (`GPIO32`, JP1 pin 19, in
`packages/hardware-profiles/src/profiles/d4-v1.json`). The C6 pins on JP1 (20, 22, 24, 26) stay
reserved and undriven. `FLASH_EN` **has no P4 GPIO in D4-V1**: since ECN-0003 `GPIO28`, JP1 pin 21,
carries `BTN_SHUTTER`, and `BOARD_FLASH_EN` in `firmware/p4/main/board_d4v1.h` is
`BOARD_GPIO_NONE`. Twelve P4 GPIOs reach the header — 52, 51, 50, 49, 35, 34, 32, 28 on the left
column and 33, 31, 30, 29 on the right — carrying eleven signals: the four TX/RX pairs, `SYNC_OUT`
(`GPIO32`, pin 19), `CAM_PWR_EN` (`GPIO31`, pin 10, since ECN-0002) and `BTN_SHUTTER` (`GPIO28`,
pin 21). GPIO35 on pin 15 is the one spare and must stay unconnected; it is the P4's
serial-bootloader strap, which is why the button could not have it.

A pin is not a flash, and this one was never anything else. `capture.c` configured `GPIO28` as an
output and held it low; no capture ever asserted it, so no meter ever caught an edge on it, and
`HWV_FLASH_EN_GPIO28` in `firmware/p4/main/hardware_validation.h` stayed **UNVALIDATED**. The
registry is append-only, so that row remains — as a record that the line was assigned and never
proven. It can no longer flip: nothing drives `GPIO28` as an output any more. The built-in
constant-current flash assembly is dropped from D4-V1 and an external module replaces it, with no
P4 pin in this revision and no chosen interface.

`flashControl` stays `true` and `flashHardware` stays `false`. `flashControl` describes the command
surface, which is unchanged; `flashHardware` describes a fitted flash, and there is none — now for
the plainer reason that there is no enable line either. The intended timing is recorded and not
implemented: asserted before the trigger and released as soon as every node reports its capture
finished, bounded at 900 ms, because without exposure sync a flash has to cover a window rather
than an instant, and at 350–500 mA the difference is worth bounding. Whatever the external module
turns out to be, it inherits that requirement.

### D14 — `capturedAt` is required, and the body has no clock

`kino.capture` requires `capturedAt`, an ISO 8601 timestamp. The D4 V1 has no RTC, no battery-backed
clock, and no network. A body that has never been told the time cannot produce a true timestamp, and
a *plausible* false one is worse than an obviously false one: it survives import, sorts into the
wrong place in someone's roll, and is never questioned.

So the timestamp always travels with its source. `HELLO` gained two optional additive request fields,
`hostEpochMs` and `hostUtcOffsetMin`, and answers with `clockSource`; `META.JSON` and
`CAMERA_CAPTURE` carry the same field:

| `clockSource` | What the timestamp is worth |
| --- | --- |
| `host` | A host set it this session. Trust it. |
| `persisted` | Restored across a power cycle as a lower bound. The shot happened at or after this. |
| `unset` | Never told. The reading is uptime since the epoch and is visibly not a date. |

Firmware refuses a host time outside 2020–2100, which is what a seconds-for-milliseconds mix-up
looks like, and only persists a time it was actually given.

### D15 — `TargetId` gained `c6`, and `FW_QUERY` is implemented without the rest of `FW_*`

Two changes, one cause: the D4 carries a sixth firmware image and the version model could not name
it.

`TargetId` was `CamId | 'p4'` — five images. The Guition carrier's ESP32-C6 runs a hosted-slave
image of its own, which is a second thing that can be stale in the field, and issue #133 requires it
to be reportable "alongside the P4 and nodes". So `TargetId` is now `CamId | 'p4' | 'c6'` and
`ALL_TARGETS` has six members. Purely additive: nothing reads a specific target by position, and
`ALL_TARGETS` had no consumers outside its own declaration.

`FW_QUERY (0x60)` is now implemented. Every other command in the group —
`FW_BEGIN`/`CHUNK`/`END`/`ABORT`/`STATUS`/`ROLLBACK` — still returns `UNSUPPORTED_COMMAND`, because
the shipped units still run the single `factory` slot. Since firmware 0.4.9
the repository carries `firmware/p4/partitions.csv` (issue #143): two 3072 KB
OTA slots (`ota_0` at 0x10000, where `factory` was, so older images still
flash there), `otadata`, a 256 KB NVS and a coredump partition — flashing it
erases NVS and is a bench decision, so a unit is on the new table only when
its `HARDWARE_VALIDATION.md` session says so. The FW_* transfer path now has
a real slot to land in once that flash happens. That split is deliberate: a
query is not an update path, `GET_CAPABILITIES` advertises no update capability, and version
discovery is useful long before an update mechanism exists.

Two conventions this establishes for the response:

- An empty `version` means the device could not read one — a node that has never answered, or a C6
  with no transport. It is **not** version zero and must not be rendered as one.
- `state` describes an update in progress, so an unreachable target is `idle` rather than `error`:
  nothing failed and nothing was attempted. `error` there would send someone to re-flash a chip that
  is merely unwired.

**Resolved at firmware 0.4.58: the transfer path exists.** `FW_BEGIN`, `FW_CHUNK`, `FW_END`,
`FW_ABORT` and `FW_STATUS` answer for `p4` and `cam1`..`cam4` (`firmware/p4/main/fw_update.c`), with
the shapes in [commands.md](commands.md#firmware--0x600x66) and Studio's updater as the client they
were written against. What the D4-V1 does differently from the reference device:

- No maintenance mode exists, so `MAINT_REQUIRED` is never sent. A `BEGIN` during a capture gets
  `INVALID_STATE`; a second `BEGIN` while a session is open gets `BUSY`.
- `chunkSize` is 8192 for every target. A camera image is forwarded down the node's UART in 2 KB
  `NL_CMD_FW_*` frames (`node_link.h`), each acknowledged, inside the host's 8 KB chunk.
- The P4 answers `FW_END` and restarts 0.8 s later; the link drops, which the updater already
  expects. A camera node verifies its own copy, answers, and restarts itself; the P4 reports it
  `rebooting` until its `HELLO` returns the version named at `BEGIN` (`ready`), and after 40 s of
  silence cycles the camera bank once so the node's bootloader can roll back; 95 s is `error`.
- Both images boot with rollback armed (`CONFIG_BOOTLOADER_APP_ROLLBACK_ENABLE`). The P4 confirms
  itself once the panel and the host link are up; a node confirms itself when it answers its first
  `HELLO`. An image that never gets there is rolled back on the next reset.
- `GET_CAPABILITIES` now reports `xiaoProxyUpdate: true` and, additively, `firmwareUpdate: true`.
- A node still on the single-app partition table has no slot to write and refuses `BEGIN` with
  `HARDWARE_ERROR`; the P4 relays that. Such a node is flashed once over its own USB with
  `firmware/camnode/partitions.csv`, and is updatable over the link from then on.
- `FW_ROLLBACK` stays reserved and unimplemented: the bootloader's rollback covers the case it was
  for, and a host-driven return to the previous slot is a release decision (`docs/RELEASE_TRUST.md`).
- `FW_QUERY` reported the nodes shifted by one (a 1-based loop against a 0-based accessor); fixed in
  the same change.

The `c6` target carries two additive booleans, `fitted` and `reachable`, for the same reason
`flashControl` and `flashHardware` are two flags. Without them a host sees an empty version and
cannot tell an absent chip from an unrouted one — which on the D4 V1 is exactly the distinction that
matters, since the chip is fitted and no P4-side transport pin for it is recorded anywhere
(`firmware/C6_HARDWARE_MAP.md`).

The reference device (`packages/test-fixtures/src/MockKinoDevice.ts`) reports all six targets. It
simulates no C6, so its `c6` entry carries an empty `version` and `state: "idle"` — the two
conventions above, applied: nothing could be read and nothing was attempted. (It reported five for a
while, which is why this paragraph once called that a known divergence.) Studio's `FW_QUERY`
conformance check asserts only that the five it knows are *present*, so an older body that omits
`c6` still passes; a host must therefore treat a missing `c6` key as "this body has no radio", not
as a protocol error.

### D16 — `clockSource` gains `network` in the radio build only

`types.ts` types `clockSource` as `'host' | 'persisted' | 'unset'` in both `HelloResponse` and
`DeviceInfo`, and `apps/studio/src/developer/conformance.ts` throws `ShapeError` on anything else.

The radio build adds a fourth value, `network`, because SNTP is a real and distinct source: it is
better than a value carried across a power cycle and worse than a time a bench operator typed in, and
`clock.c` needs the distinction to decide whether a certificate may be validated against the clock at
all. Collapsing it into `host` would claim a person set the time; collapsing it into `persisted` would
claim it drifts.

**Resolved in the type, 2026-09-01.** The union is `'host' | 'network' | 'persisted' | 'unset'` in
both `HelloResponse` and `CameraCaptureResult`, Studio's HELLO shape check accepts all four, and
`MockKinoDevice.setClockSource` can report `network` so a host is testable without a radio on the
bench. It was overdue rather than early: KD4-D121BC running 0.4.17 sends `clockSource: network` on
first association, and the shape check failed HELLO on a body that was behaving correctly
(`SHAPE HELLO — HELLO: unknown clockSource network`, 2026-09-01).

A consumer must keep the four distinct. Collapsing `network` into `host` claims a person set the
time; collapsing it into `persisted` claims it drifts. The default build still never emits it.

### D17 — 16 commands in `commands.ts` are not implemented by the D4 V1 P4 build

`commands.ts` declares **72** commands. The shipping P4 firmware dispatches
**56** and answers the rest with an `UNSUPPORTED_COMMAND` NACK from the
dispatcher's default case. That is the documented degradation path, and it is
exercised: no unimplemented command hangs, times out, or returns a malformed
frame.

Audited by comparing the `Cmd` enum against the `case KDP_CMD_*` labels in
`firmware/p4/main/kdp_server.c`. The count was 27 at 0.4.2; the looks and sounds
families left the table in 0.4.8 (see
[D18](#d18--set_recipe-takes-a-cam-and-the-two-families-that-left-d17)), and
`SYNC_BENCH` and `STORAGE_BENCH` left it after that. Re-count from the two
sources rather than trusting these numbers — they have been stale twice.

| Family | Commands | Roadmap |
|---|---|---|
| Camera control beyond capture | `CAMERA_ARM` `0x31`, `CAMERA_PREVIEW` `0x34`, `CAMERA_CALIBRATE` `0x35`, `CAMERA_PHASE` `0x36`, `CAMERA_FOCUS` `0x37` | Yes |
| Firmware update | `FW_ROLLBACK` `0x66` only. `FW_BEGIN`..`FW_STATUS` are implemented since 0.4.58 — see [D15](#d15--targetid-gained-c6-and-fw_query-is-implemented-without-the-rest-of-fw_) | Yes |
| Maintenance | `ENTER_MAINTENANCE` `0x50`, `EXIT_MAINTENANCE` `0x51`, `FACTORY_RESET` `0x53` | Yes |
| Bench | `LINK_BENCH` `0x44` | Yes |
| Link | `SET_LINK_BAUD` `0x45` | Yes |

`SYNC_BENCH` (`0x46`) is **dispatched** and used to sit in the Bench row above.
It is a blocking edge counter, not the async job the contract once described —
see [`commands.md`](commands.md#sync_bench--0x46). `STORAGE_BENCH` (`0x4c`) is
dispatched too.

Every family above is on `firmware/FIRMWARE_ROADMAP.md`. None is an accidental
omission, and none is a protocol disagreement — the wire contract is agreed,
the behaviour is simply not built yet.

**No capability flag covers the families that are left.** `GET_CAPABILITIES`
advertises `benchDiagnostics`, `configStore`, `customSounds`, `flashControl`,
`flashHardware`, `gallery`, `mediaIndex`, `network`, `powerManagement`,
`powerTelemetry`, `quad`, `radioFitted`, `radioRouted`, `recipes`, `roll`,
`rollUpload` and `wiggle`; there is still no `firmwareUpdate`, `maintenance`,
`calibration` or `preview` flag. A client discovers those four by sending and
reading the NACK rather than by asking first, which contradicts the rule in
[Versioning](#versioning) that new behaviour is gated behind a capability flag.

The fix was stated here as "a flag per family, with the first family to be
implemented" and that is what 0.4.8 did: `recipes` is new and `customSounds`
went true, both read off the same two predicates the dispatcher gates on
(`kdp_recipes_capable()`, `kdp_sounds_capable()`), so neither flag can claim
what the handler will refuse. `recipes` is optional in `Capabilities` because
firmware older than 0.4.8 omits it; an absent flag means the commands NACK,
not that the answer is unknown. The four families still listed above take the
same treatment when they land.

`benchDiagnostics` is honest: it gates `GET_STORAGE_STATUS`,
`CAMERA_LINK_STATS`, `CAMERA_LINK_STATS_RESET`, `GET_HW_VALIDATION`,
`STORAGE_SELF_TEST`, `STORAGE_BENCH`, `CAMERA_TEST` and `CAMERA_SOAK_TEST`, all
of which are implemented. `LINK_BENCH` and `SYNC_BENCH` are not behind it —
`LINK_BENCH` is the one `*_BENCH` command with no handler.

**Four cases in Studio's own conformance suite cannot pass against 0.4.17.**
Measured on KD4-D121BC, P4 0.4.17, 2026-09-01: 32 cases (8 active, 24 passive),
25 pass, 4 `UNSUPPORTED`, and one camera channel skipped because only CAM1 is
fitted on that unit.

| Case | Opcode | Why it cannot pass |
|---|---|---|
| `CAMERA_CALIBRATE (get)` | `0x35` | Not dispatched. Per-camera alignment calibration is not built; the D4 V1 body has no stored calibration to read back. |
| `CAMERA_PREVIEW frame` | `0x34` | Not dispatched, and **nothing replaces it**. There is no KDP way to get a preview frame off this body. |
| `MAINTENANCE enter/exit` | `0x50` | Not dispatched — the whole Maintenance family is on the roadmap, not in the build. |
| `FW_BEGIN gate (outside maintenance)` | `0x61` | Not dispatched. A near miss worth noting: the case expects a refusal citing maintenance and gets `UNSUPPORTED_COMMAND`, so the gate it tests is satisfied in substance while the assertion still fails. |

**There is no live-viewfinder KDP command.** This entry named
`CAMERA_VIEWFINDER` as "the live viewfinder path"; no such identifier exists in
`packages/kdp/src/protocol/commands.ts`, in
`firmware/components/kdp_core/include/kdp/protocol.h`, or in the dispatcher. The
viewfinder is **body-local**: `firmware/p4/main/viewfinder.c` pumps frames from
one camera over the node link's own `NL_CMD_CAPTURE` and draws them on the
panel. What reaches KDP is a read-only `camera.viewfinder` block in
`GET_CAMERA_INFO` (`{ frames, fpsX10, drops }`, firmware 0.4.18+) plus
`viewfinderFpsX10` — statistics, not pixels. `shoot.viewfinder` in the config
store chooses which camera feeds it. A host cannot start, stop or read the
finder, and `CAMERA_PREVIEW` — the one command that would hand over a frame —
is not dispatched. Do not build a Studio preview against this body.

All four are dispatcher-default NACKs, which is the documented degradation
path, so the run is what a correct 0.4.17 body looks like. A fifth status —
`error`, not `unsupported` — is a regression signal and not expected here: an
`UNSUPPORTED` case whose opcode is on the table above is an expected gap, and
anything else at those four names is new.

`CAMERA_TEST (CAM2)` used to report `ERROR — Camera node not connected` on a
one-camera bench unit. That was the hardware being honest, so the per-camera
cases now skip and name the channel (`camMissing` in `conformance.ts`, fed by
`GET_CAMERA_INFO`); an unfitted camera is not a firmware failure and must not
be printed as one. `CAMERA_PREVIEW frame` aims at the first fitted channel
instead of at CAM2 by name — the opcode is what it is testing, and on a
one-camera unit the hardcoded channel hid the `UNSUPPORTED_COMMAND` answer
behind "CAM2 is offline". `CAMERA_CAPTURE timing-test` skips on a body that
advertises `vsyncTelemetry` with fewer than four channels fitted: a spread
across four cameras cannot be measured with three, and 0.4.17 reports
`vsyncTelemetry: false` and takes the refusal branch whatever is populated.

`GET_RECIPES` left this list at 0.4.8 and a `GET_SOUNDS` case joined the suite
beside it; both are read-only, so both stay `active: false` — the flag marks a
case that changes device state, not a case that is switched on.

### D18 — `SET_RECIPE` takes a `cam`, and the two families that left D17

Firmware 0.4.8 implements the ten looks and sounds commands with the request
and response shapes `MockKinoDevice.ts` has always answered, so nothing on the
wire changed for a host that was already speaking to the mock. Four things are
decided here rather than inherited.

**`SET_RECIPE` gains an optional `cam`.** `SetRecipeRequest` in `types.ts` is
`{ id, cam? }` where `cam` is `CamId | 'all'`. Absence is the original
behaviour and not a default to be filled in: no `cam` writes
`wiggle.recipeId`, `"cam1"`..`"cam4"` write `quad.slots.<cam>.recipeId`, and
`"all"` writes all four slots and wiggle. The reply is
`{ ok: true, id, cam }`, echoing `cam` as sent so a host can see which target
was written. An unknown `id` — checked against factory and custom together —
is `NOT_FOUND` rather than stored; a config naming a look the device does not
have is how a slot ends up rendering as the wrong picture at import. A `cam`
that is neither a camera nor `all` is `INVALID_ARGUMENT`. `DELETE_RECIPE` of an
id the camera does not hold is `NOT_FOUND`. `NOT_FOUND` means the document is
not on the card. A delete that fails for any other reason — a card gone
read-only, a pulled card, an I/O error — is `STORAGE_ERROR` naming the errno
(firmware **0.4.10**), because the look is still there and a host told
`NOT_FOUND` would drop it from its list and see it return at the next
`GET_RECIPES`. A malformed id is `BAD_REQUEST`;
the mock answers `{ ok: true }` to any delete, and the firmware is the one to
follow — a retry after a lost ACK sees `NOT_FOUND` and knows the first delete
landed. Firmware older than
0.4.8 ignores the field, so a host that needs a per-slot write on an older
body sends `SET_CONFIG` instead.

**`SOUND_END` may NACK `BAD_FORMAT`.** The mock checks length only, and length
is not a format: it accepts any 44-byte-or-larger blob and stores it. Firmware
parses the RIFF/WAVE header and refuses anything that is not PCM, mono,
16-bit, 16 kHz, because the playback path has one sample rate and no
converter, and a clip that fails there fails at a shutter press rather than at
upload. This is a firmware code the mock does not raise; a host must handle
it, and the mock cannot be used to prove it never happens.

**The factory looks are one document with two copies, and they have to be
equal.** `firmware/p4/main/factory_recipes.json` is compiled into the P4
image; `packages/test-fixtures/src/factoryRecipes.ts` `FACTORY_RECIPES` is
what Studio and every test read. Neither is normative alone.
`packages/test-fixtures/tests/factoryRecipeParity.test.ts` compares them id by
id — eleven entries, `factory: true` on each, deep equality, order-insensitive
— so editing one and not the other is a red test. Without it the difference
would show as a picture on the bench that is not the picture in the app, which
is not a failure anything reports.

**Card paths.** Custom looks are `/sdcard/KINO/RECIPES/<id>.json`, custom
clips `/sdcard/KINO/SOUNDS/<id>.wav` with a sidecar for name and duration. An
upload is written to a temporary file and renamed at the end, so a power cut
mid-transfer leaves nothing half-written rather than a truncated look the
validator would then have to reject on every boot. Limits are the mock's:
eight custom clips, 128 KB each, 8192-byte chunks. Sound ids match
`^snd-[a-z0-9-]{1,19}$`; look ids are whatever `validateDeviceRecipe`
accepts (`^[a-z0-9][a-z0-9-]{0,47}$`), because the firmware validator mirrors
that function rather than restating it.

**What none of this does.** The camera stores and selects a look. It does not
apply one: no capture block reaches a sensor register, and a look is still
applied at import. `wiggle.recipeId` defaults to `party-neg`, which is the
mock's default and now the firmware's.

> **Superseded in part by [D19](#d19--nl_cmd_sensor-and-the-settings-that-finally-do-something)
> (firmware 0.4.9).** "No capture block reaches a sensor register" was true of 0.4.8 and is not true
> now: `NL_CMD_SENSOR` carries exposure bias, gain ceiling, denoise, sharpness and quality to the
> node, which clamps them and reports back what it set. What survives unchanged is the rest of the
> sentence — grading is still applied at import, and the sensor knobs a look can move are the five
> the driver exposes, not the look's colour science.

**`SOUND_BEGIN` validates the id and bounds the name.** The id must match
`^snd-[a-z0-9-]{1,19}$` (`BAD_ID`) because it becomes a path under
`/sdcard/KINO/SOUNDS`. The name is 1..32 characters (`SOUND_NAME_MAX` in
`types.ts`) and a longer one is `BAD_NAME`, not a truncation: a silently
shortened name returns on the next `GET_SOUNDS` as a clip the host did not
upload, and the host cannot tell that from a name it got wrong itself. The
mock enforced neither and now enforces both.

### D19 — `NL_CMD_SENSOR`, and the settings that finally do something

Firmware 0.4.9 changes no KDP command and no KDP payload. Everything here is
either behaviour behind a field that was already on the wire, or traffic on the
node link, which is not KDP and is not part of the host contract. A host that
was speaking to 0.4.8 needs no change to speak to 0.4.9; what changes is that
seven settings it could already write stop being decoration.

**`NL_CMD_SENSOR` (`0x15`) is a node-link command, not a KDP one.** Request
`{aeLevel?, gainCeiling?, denoise?, sharpness?, quality?}` — every field
optional, absence meaning "leave that knob alone", which is what the P4's
change-only cache depends on — reply
`{ok, applied:{…}}`. The node clamps each value to the driver's range and
reports what it set, not what it was asked for; `NL_CMD_STATUS` carries the
last applied set so a bench can read the sensor's state without taking a
photograph. The numbering is the node link's own and has no relationship to
the KDP command ids — `0x15` is `MEDIA_LIST` over KDP and means nothing here.

**The merge order is fixed and has three steps.** Before each capture the P4
builds one sensor request per camera: the mode's own defaults first, then the
active look's capture block (`jpegQuality`, `exposureBias`, `gainLimit`,
`denoise`, `sharpness`) where the look sets one, then — in QUAD only — that
slot's `exposureBias` and `gain` from `quad.slots.camN`. The slot wins because
it is the per-camera control and the look is the shared one; a look that sets
nothing changes nothing rather than resetting to a default. WIGGLE has no
slots, so the wiggle look's capture block is the last word there.

**The mappings are lossy in one direction and say so.** `exposureBias` is an EV
in `-2..+2` with one decimal; `set_ae_level()` takes an integer `-2..2`, so the
EV is rounded to the nearest step and -1.5 EV and -1.4 EV reach the same
sensor. `gain` is `auto` / `low` / `high`: `auto` leaves AGC untouched, `low`
sets a gain ceiling of 4x, `high` sets 32x. Both mappings are pure C and
host-tested; neither is applied on the P4's side of the link, so what a
photograph got is what the node reported back.

**`META.JSON` records what was applied, per frame.** Each entry in `frames[]`
gains an optional `sensor` object — `{aeLevel, gainCeiling, denoise,
sharpness, quality?}` — holding the node's echoed values. `quality` is on the
sensor's own 5..63 scale, not the 60..95 wire percentage; D12 is the conversion
and it happens before the link, not after. `quality` is the one field that
records what the frame was ENCODED at rather than what a sensor apply echoed:
`NL_CMD_CAPTURE` writes that register too when the request carries the field,
and so does every viewfinder frame, so the value META carries is the value the
register held at the exposure — the node's echo when `NL_CMD_SENSOR` still owns
it, otherwise the quality this capture's own command sent, after the node's
5..63 clamp.

**A sensor failure never blocks a capture.** A NACK, a clamp the P4 did not
expect, or a timeout on `NL_CMD_SENSOR` is logged and the trigger goes out
anyway. The frame's `sensor` object then records the sensor's STANDING values
— the last apply that camera accepted — because the sensor really does still
hold them, and recording them beats recording nothing.

The exception is `quality`, and the reason is the preview. The viewfinder has no
sensor command of its own: each preview frame is an `NL_CMD_CAPTURE` carrying
the finder's own quality, which the node applies before it exposes. So a preview
between two photographs leaves the preview's value standing, the P4's
change-only cache forgets its quality for that camera and re-sends it before the
next trigger, and if that send fails the frame records the quality its own
CAPTURE carried instead of the look's. Firmware 0.4.9 did neither: the second
and later captures after a preview were encoded at preview quality while META
reported the look's, and it never self-healed. Fixed in **0.4.10**.

The object is absent
only when nothing has ever been applied to that camera since its node booted,
or on firmware older than 0.4.9; neither means the frame is bad. The
alternative — refusing the capture over a settings write — is the wrong trade
in a camera.

**What still does not happen.** The rest of a look — contrast, saturation,
temperature, and the other grading fields — stays Studio's at import. No
grading runs on the camera. `colorMode: 'mono'` is still not applied on the
body: the slot stores it, `META.JSON` carries it, and the mono conversion
happens at import as it always has. That is a product decision still open, not
an oversight.

**`capabilities.brightnessControl`.** Optional boolean, `false` on D4-V1 for
the reason D11 already records: the backlight is on a plain GPIO and the only
states are lit and dark. It exists so a host can grey the slider honestly
instead of offering a control that writes a value nothing reads. Firmware older
than 0.4.9 omits the flag, and a host must read absence as "unstated", not as
"no" — Studio's `supports()` leaves the control live on a missing flag and
disables it only on an explicit `false`.

**`body.name`.** A string, 0..24 characters, default `""`, written with
`SET_CONFIG` like every other body field and shown on the body's About screen.
`config.device` is the serial and remains the identifier; this is the name a
person gives the unit. It is optional in `BodyConfig` because a `GET_CONFIG`
from a body older than 0.4.9 returns a `body` block without it; absent and `""`
mean the same thing.

### D20 — `CaptureFile.sha256` and `CaptureInfo.meta` are omitted by MEDIA_INFO

`CaptureFile` typed `sha256: string` and `CaptureInfo` typed `meta` as a required object. The P4
never sends the first and does not always send the second, so every `MEDIA_INFO` reply from real
firmware was a lie the compiler endorsed — the same shape as D10, and the same outcome: Studio's
`file.sha256.toLowerCase()` and `info.meta.batteryV.toFixed(2)` compiled clean and threw on the
first capture off a real card.

**Resolved in the type, 2026-09-01.** Both are optional now. The behaviour they describe is not a
bug and does not change:

| Field | 0.1.0+ | Why |
|---|---|---|
| `files[].sha256` | always absent | Hashing four multi-megabyte JPEGs on request blocks the KDP link for seconds. The key is omitted rather than filled with a wrong or empty digest — see the comment at `handle_media_info` in `firmware/p4/main/kdp_server.c`. |
| `meta` | absent when the capture's `META.JSON` did not parse | The handler attaches the block only when it read one (`if (meta)`). A folder written by a body that lost power mid-write, or assembled by hand, has frames and no document. |

A host must therefore:

- treat a missing digest as **unverified**, never as verified. `downloadCaptureFile` in Studio
  returns `{ data, verified }` and checks the bytes only against a digest that arrived; the
  inspector's TRANSFER CHECK row and the tether notice say which of the two happened. A download
  refused for want of a digest would make the gallery unusable on every shipped body, and a
  download called verified without one is worse than the crash it replaced.
- print a dash and the reason for every row `meta` would have filled. `0` there is not a neutral
  value: it reads as a simultaneous trigger and a flat cell.
- accept a `META.JSON` with neither field. Studio's folder import required both and reported the
  metadata of every tethered capture as unreadable; a malformed digest is still rejected, because a
  wrong digest is worse than none.

Verifying a transfer needs a digest the body can afford to produce — a CRC over the file as it is
read, or a digest computed once at capture and stored in `META.JSON`. Neither exists yet, and
neither is a protocol change: `sha256` stays optional and starts arriving when something computes it.

The reference device omitted nothing, which is why no test caught this. `scenarios.mediaInfoAsShipped`
answers `MEDIA_INFO` the way the firmware does — no digests, no `meta`, and `META.JSON` refused on
`MEDIA_READ` so the two agree.

## Decided — was "firmware team decision required"

Issue #5 closed the six open questions this section used to list. They were open because physical
firmware cannot guess them, and a bench is a bad place to discover a design question. Each decision
below is now source: `commands.ts`, `types.ts`, `packet.ts` and the reference device implement it,
and a test pins it.

Three of the six are ratifications rather than inventions. Where the client, the reference device
and the P4 dispatcher already agreed on a behavior, the decision is to keep that behavior and forbid
firmware from being stricter — changing it would break a host that is entitled to the old one.

1. **`STATUS` (0x81) and `FW_PROGRESS` (0x82) — reserved, not emitted.** Neither has a producer or a
   consumer, and neither is on the 1B path: firmware update is gated behind `xiaoProxyUpdate`, which
   0.1.x reports `false`. A 0.x device **must not** emit either id. The shape stays undefined on
   purpose — defining it now would be guessing at a payload for a feature whose flow does not exist,
   and a wrong guess is worse than a gap. When the update path lands, `FW_PROGRESS` takes the shape
   `FwStatusResponse` already has, and that is the moment to write it down. The host drops unknown
   events, so a stray one is survivable but out of contract.
2. **Sequence-ID wraparound — wrap to 1, never to 0.** `nextSeq()` in `packet.ts` is the rule, and
   firmware mirrors that one function. Sequence 0 is the events' sentinel; a uint32 counter left to
   overflow naturally would start minting requests that look like events to anything reading the
   field literally. No session runs long enough to reach it, which is exactly why both sides have to
   agree in advance instead of meeting the overflow separately.
3. **HELLO is not mandatory — and firmware must not make it so.** The client does not enforce
   ordering, the reference device answers any command without one, and `kdp_server.c` dispatches
   without checking. Three implementations already agree; a stricter firmware would reject hosts that
   are within contract. HELLO stays the only way to obtain a `sessionId`, and commands that need
   session state (sound upload, firmware sessions) keep answering `NO_SESSION` — that is a
   per-command precondition, not a connection-wide one. Because there is no such thing as a rejected
   pre-HELLO command, no rejection code is needed.
4. **Binary media resume — offset restart is the whole mechanism.** 04§10 asked for per-chunk CRC and
   a completion hash. The per-chunk CRC is the frame CRC, which already covers every byte of every
   chunk and is checked before the payload is handed up. There is no completion hash in v1: `MEDIA_INFO`
   carries the size, a short read is visible without one, and hashing a 4 MB JPEG on the P4 costs
   more than it proves. Resume is "ask for a different offset", and firmware must serve any valid
   offset into a file it listed.
5. **`GET_MODES` (0x20) and `CAMERA_ARM` (0x31) — the reference payloads are now the spec.**
   `GetModesResponse` = `{ modes: ShootMode[] }` and `CameraArmResponse` = `{ ok, armWindowMs }` live
   in `types.ts`, and the reference device is typed against them. `armWindowMs` is not optional: with
   no CAMERA_DISARM, the window is the only thing that tells a host when the sensors fall back to
   `ready`. Neither command is in the 1B set, so 0.1.x NACKs both `UNSUPPORTED_COMMAND` — the payload
   is decided for the firmware that implements them, not smuggled into this one.
6. **`JOB_PROGRESS` for a job this session never started — sanctioned, but only after a reconnect.**
   A host that reconnects mid-job legitimately receives progress for a job it did not start, so the
   client's bounded orphan map is contract, not tolerance. What a device must not do is invent jobs:
   every `jobId` it reports has to correspond to work some host asked for. Unbounded orphan traffic
   is a firmware bug, and the host's bound is what keeps it from being a host bug too.

**Compatibility.** None of the six bumps `PROTOCOL_VERSION`. Four are documentation of behavior that
already shipped, one adds response types for commands no 0.1.x device answers, and the wrap rule is
unreachable in any real session. KDP stays at **1** for all of 0.x, and `versions.json` keeps
`protocol.kdp: 1`. New behavior goes behind a capability flag; the version byte changes only when the
framing or an existing payload's meaning does.

### D21 — `GET_MODES` answered a shape this file never described, and lied about availability

Two defects in one reply, found on 2026-09-01 by the first run of the
conformance suite against real hardware (KD4-D121BC, P4 0.4.17) — the suite
was browser-only until issue #155 gave it a terminal runner, so nothing had
compared this reply to the contract since the capture pipeline shipped.

**The shape.** `GetModesResponse` in `packages/kdp/src/protocol/types.ts`
declared `{ modes: ShootMode[] }`, a bare array of strings. The P4 has answered
`{ active, modes: [{ id, name, available, unavailableReason }] }` since 0.3.0.
Nothing caught it: `MockKinoDevice` matched the stale type, so every test
passed, and the only reader was the conformance case, which failed with
`MODES: missing wiggle` the first time it met a real camera. **Resolved by
widening the type to the shape the firmware sends** — the richer form carries
the availability, which is the point — and by making the mock answer it too.

**The lie.** `available` and `unavailableReason` were compile-time constants:
`false` and `"No capture pipeline in this build"`, a string from the M1B era
that nobody revisited when capture landed. Measured in a single conformance
run: `GET_MODES` reported both modes unavailable for want of a capture
pipeline, and eleven cases later `CAMERA_CAPTURE` stored `CAP_000629`,
1 frame, `complete`, in 2980 ms. Every host asking this camera what it could
do was told it could not shoot.

**From firmware 0.4.18** both fields are derived from the predicate
`capture_fire()` itself uses, in its order — a mounted card first, then a
camera node that answered — so `available: true` means a capture requested at
that instant would be taken. `unavailableReason` is `null` when available and
always present. `SD_FULL` and `BUSY` are deliberately excluded: the first is
arithmetic about a capture nobody has requested, the second is a sample of a
state `capture_request()` re-checks, and either would make the field flicker.

**Both modes report identically, and that is the truth rather than the old
shortcut.** `capture_fire()` never consults the mode when deciding whether it
may shoot — only which look and exposure to send each sensor. A quad with one
camera stores one frame and commits `complete`. Availability is a property of
the body, not of the mode. Advertising "quad needs four cameras" would be the
same class of lie pointing the other way; a host that wants the pane count
reads `GET_CAMERA_INFO`.

`active` remains a stored selection that survives a reboot and may name an
unavailable mode. That pair is coherent — it is what the camera will shoot
once the reason clears — and the conformance case now asserts the coherence
in both directions.

### D22 — two additive fields the camera now reports about itself

Firmware 0.4.18, both optional, both absent on older bodies.

`GET_CAMERA_INFO` / `CAMERA_STATUS` gain `camera.viewfinder`
(`frames`, `fpsX10`, `drops` keyed by reason and cumulative for the session).
A preview frame the finder refused used to vanish silently, which made a
refused frame indistinguishable from a slow camera. `noLink` is counted and
never logged, because three channels are unwired on a V1 body and logging
them would flood the ring it exists to protect.

`GET_RUNTIME_STATS` gains `ui` (`passes`, `lastPassAgeMs`, `stalled`). There
is no watchdog on the display task, so a wedged UI was invisible to a host —
every other field answers from the KDP task and looks healthy. `stalled` is
not derived from the age: a loop that turns over without presenting has a
healthy age and a frozen panel, and separating those two is the point.

Both replace the same firmware's previous diagnostic, a once-a-second
`ui ... STALLED` klog line that fired on every idle screen and evicted real
evidence from a fixed-size ring. It now reports on the edge only, and only
when a frame was actually owed.

### D23 — `frameIndex` is the camera slot, and a capture's frames may be sparse

Firmware 0.4.29 (#164). `docs/roll/ROLL_DEVICE_CONTRACT.md` said original
frames carry `frameIndex` 1..N contiguous. The capture path never promised
that: a grouped capture stores the frames of the cameras that answered,
named by camera (`C3.JPG` is camera 3), and META.JSON's `frames` lists
exactly those, with `frameCount` their number. With camera 2 dark the set is
frames 1, 3 and 4 and `frameCount` is 3.

The Roll queue used to enumerate 1..`frameCount` from a count, so that set
was asked for `C2.JPG` until it parked (bench 2026-09-03, CAP_000263). It now
carries the camera list in `UPLOAD.JSON` (`frameSlots`, beside `frameDone`,
both positional and read together), takes it from the capture report at the
shutter and from META.JSON's `frames` at reconciliation, and never from a
count or a scan of the card. On the wire `frameIndex` is the camera slot;
the server's identity `captureUuid + role + frameIndex` and its
`alreadyComplete` replay are unchanged, and it accepts any positive
`frameIndex`. Records written before 0.4.29 have no `frameSlots`; the
reconciler adopts the list from META (an old `frameDone[i]` meant camera
i+1 and is read that way) and rewrites the record. A META with no usable
frame list parks the job with the reason, rather than guessing.

### D24 — the node reports the shared sync edge, and `META.JSON` frames carry it

Firmware 0.4.30 (#165). Additive, measurement only. `NL_CMD_CAPTURE`'s reply
gains `syncSeq` (rising edges the node has counted on `SYNC_IN` since its
boot - the generation id), and `syncEdgeUs`, `syncToCmdUs`, `syncToFrameUs`,
each null until that node has ever seen an edge. `NL_CMD_HELLO` and
`NL_CMD_STATUS` gain `syncSeq` and `syncInput`. All values are that node's own
`esp_timer` microseconds and share no epoch with the P4 or with another node;
only `syncToFrameUs = frameStartUs - syncEdgeUs` is comparable across nodes,
because every node measures its own frame against the same physical pulse.

`kino.capture` frame entries gain `syncClass` (`ok` | `unverified` |
`stale-generation` | `none`), `syncSeq`, `syncEdgeUs`, `syncToCmdUs`,
`syncToFrameUs` and `frameBeforeEdge`, the last four null when the node
reported no edge. A reader that ignores them still gets a valid
`kino.capture`. `frameBeforeEdge` true means the returned frame's DMA arm
preceded the pulse, which is the expected case with a free-running sensor and
marks the frame stale for timing purposes.

None of this is exposure timing. `timing.gpioTriggerSkewUs`,
`vsyncPhaseSkewUs` and `effectiveExposureSkewUs` stay null with their
`unavailableReason`, and `vsyncTelemetry` stays false: the edge is a common
time reference for frame-start measurement, not a trigger, and a rolling
shutter integrates per row where this firmware cannot observe.

### D25 — `body.hand` and `body.firstRunSeen` are firmware-only config keys

Firmware 0.4.58 (#177). `BodyConfig` in `packages/kdp/src/protocol/types.ts`
does not declare it, and `kino.device-config` (`packages/schemas/src/config.ts`)
passes unknown keys through, so it travels in `GET_CONFIG` / `SET_CONFIG`
untyped. Value `"right"` (default) or `"left"`: which hand holds the body, which
is the side the on-device UI puts its chrome on (`firmware/p4/main/ui.c`,
`from_hand()`). Studio shows no control for it. `body.firstRunSeen` (0.4.58) is the same kind of key: `false` until the
 `body.lastVersion` (0.4.58, #190) is the same kind: the firmware version the body last booted, so the first boot after an update shows one UPDATED note. Not a setting; Studio shows no control for it.
first boot's note has been shown once, then `true`; the UI writes it, nothing reads it but the UI. The key is written into
`default_config()` so a fresh camera reports it; an older stored envelope reads
as `right` through the accessor's fallback. Promote it into `BodyConfig` when a
Studio control exists.

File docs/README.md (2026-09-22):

# KINO documentation

Start with the question you need answered. The repository contains working contracts, current product notes, design specifications, and old implementation plans. They do not carry equal authority.

## Find the answer

| Question | Read |
|---|---|
| What is KINO? | [Project README](../README.md) |
| What hardware is in D4 V1? | [Hardware reference](HARDWARE.md) |
| How do I wire, assemble, and accept a physical unit? | [Hardware build package](../hardware/README.md) |
| How do the applications and packages fit together? | [Architecture](ARCHITECTURE.md) |
| How do I install, run, test, or change it? | [Development guide](DEVELOPMENT.md) |
| Something failed. Where do I start? | [Troubleshooting](TROUBLESHOOTING.md) |
| How should I contribute a change? | [Contributing](../CONTRIBUTING.md) |
| What is being built next? | [Roadmap](../ROADMAP.md) |
| What is actively planned or in progress? | [GitHub Project workflow](PROJECT.md) |
| How is a version released? | [Release guide](RELEASING.md) |
| How is KINO Roll deployed to a server, backed up, restored? | [Infrastructure](../infra/README.md), [relay deployment](runbooks/production-relay-deploy.md), [restore runbook](runbooks/restore.md), [observability](runbooks/observability.md) |
| A change landed that only new captures benefit from. How is the backlog re-derived? | [Thumbnail backfill](runbooks/thumbnail-backfill.md) |
| Which version changes when? | [Versioning](VERSIONING.md) |
| Which license applies to a path? | [Root license map](../LICENSE) and [`REUSE.toml`](../REUSE.toml) |
| How do I report a vulnerability? | [Security policy](../SECURITY.md) |
| What must camera firmware implement? | [Firmware contract](../firmware-contract/README.md) |
| How is the D4 firmware built and what exists? | [Firmware tree](../firmware/README.md) and [start plan](../firmware/FIRMWARE_START_PLAN.md) |
| What does the camera say on its own screen, and when? | [Device copy](DEVICE_COPY.md) |
| How do Studio, Twin and the firmware work as one system? | [Integration audit](audit/STUDIO_TWIN_FIRMWARE_INTEGRATION_AUDIT.md), [device integration](STUDIO_DEVICE_INTEGRATION.md), [acceptance tests](STUDIO_TWIN_ACCEPTANCE_TESTS.md) |
| How does Studio build and flash firmware? | [Firmware builder](FIRMWARE_BUILDER.md) |
| How does Twin model firmware and photograph a scene? | [Twin firmware model](TWIN_FIRMWARE_MODEL.md), [Twin virtual camera](TWIN_VIRTUAL_CAMERA.md) |
| What should Studio and Roll become? | [Platform spec pack](../kino_dev_spec_pack/00_README.md) |
| How does a camera upload to Roll, and how does Twin stand in today? | [Device contract](roll/ROLL_DEVICE_CONTRACT.md), [Twin integration](roll/ROLL_TWIN_INTEGRATION.md), and the other guides in [`docs/roll/`](roll/) |
| What happens on an event day, from starting the PC to shutting it down? | [Event day](runbooks/event-day.md) |
| How does kino.acronym.sk get a public front door from a machine behind carrier NAT? | [Public ingress options](runbooks/public-ingress-options.md) |
| What would the Pinggy paid plan actually give us, and what would we be agreeing to? | [Pinggy plan facts](runbooks/pinggy-plan-facts.md) |
| How does production move to a dedicated machine without changing the URL? | [Origin machine move](runbooks/origin-machine-move.md) |
| How does someone run a party with KINO Roll, from provisioning to the export? | [Host guide](roll/HOST_GUIDE.md); when photographs are not appearing, the Roll ladder in [Troubleshooting](TROUBLESHOOTING.md) |
| How is the guest app accepted on a real phone? | [Roll mobile PWA acceptance](roll/ROLL_PWA_MOBILE_ACCEPTANCE.md) |
| What does the physical camera's Roll path look like, and where does it stop? | [Physical device flow](roll/PHYSICAL_DEVICE_FLOW.md) |
| Why has the ESP32-C6 radio not been brought up? | [C6 hardware map](../firmware/C6_HARDWARE_MAP.md) for the blocking evidence, [C6 bring-up](../firmware/C6_BRINGUP.md) for the procedure once it is unblocked |
| How should the digital twin behave? | [Twin simulator spec](../kino_twin_spec/KINO_TWIN_SIMULATOR_SPEC.md) |
| Which product voice and UI rules apply to Studio? | [Product register](../PRODUCT.md) |
| What remains out of line with the Studio specification? | [Studio spec audit](studio-spec-audit.md) |
| How compliant is the system with the master hardware/software spec? | [Master audit](audit/AUDIT.md) and the per-domain documents in [`docs/audit/`](audit/) |
| What must be measured on the physical D4? | [Hardware validation plan](audit/HARDWARE_VALIDATION_PLAN.md) |

## Authority order

When two documents disagree, use this order:

1. Tested source in `packages/kdp/src/protocol/` and `packages/schemas/src/` defines the current protocol and portable schemas.
2. `firmware-contract/` explains that source for firmware work and records known deviations from the original spec.
3. `apps/*/src` and committed database migrations define current application behavior.
4. `docs/HARDWARE.md` and `kino_twin_spec/SOURCES.md` hold the current hardware snapshot and source confidence.
5. `kino_dev_spec_pack/` defines product intent and acceptance goals.
6. `docs/superpowers/plans/` records implementation history. A plan can explain a decision. It cannot overrule shipped code.

`PRODUCT.md` began as the Studio product register. Its local-first rule still governs direct device work. Its sentence saying that no backend exists describes Studio's device path, not the whole repository. KINO Roll now has an API and storage stack.

## Document families

### Maintained guides

- `README.md`
- `docs/README.md`
- `docs/HARDWARE.md`
- `docs/ARCHITECTURE.md`
- `docs/DEVELOPMENT.md`
- `docs/PROJECT.md`
- `docs/TROUBLESHOOTING.md`
- `docs/RELEASING.md`
- `docs/VERSIONING.md`
- `docs/FIRMWARE_BUILDER.md`
- `docs/TWIN_FIRMWARE_MODEL.md`
- `docs/TWIN_VIRTUAL_CAMERA.md`
- `docs/STUDIO_DEVICE_INTEGRATION.md`
- `docs/STUDIO_TWIN_ACCEPTANCE_TESTS.md`
- `CONTRIBUTING.md`
- `ROADMAP.md`
- `CHANGELOG.md`
- `SECURITY.md`
- `hardware/*`
- `LICENSE`, `LICENSES/*`, `REUSE.toml`, and `TRADEMARKS.md`
- `firmware-contract/*`
- `firmware/README.md`
- `apps/api/README.md`
- `docs/roll/*`
- `infra/README.md` and `docs/runbooks/*`

Update these when behavior changes.

### Product specifications

The files under `kino_dev_spec_pack/` describe the intended permanent platform. They include features that have not landed on the current branch. Preserve the distinction between a specified behavior and an implemented one.

### Twin specifications

The files under `kino_twin_spec/` contain the mechanical model, component manifest, source notes, and simulator handoff. Dimensions carry confidence labels. A provisional body size cannot become a measured fact through repetition.

### Historical plans

The files under `docs/superpowers/plans/` are dated work records. Keep them intact unless a link is broken. Write current instructions in a maintained guide instead of editing history into a new shape.

## Writing rules

Use the names KINO D4, KINO Studio, KINO Roll, KINO Twin, and KINO Device Protocol. Keep units attached to values. Use `µs`, `mm`, `V`, `A`, `mAh`, and `Wh` where they belong.

State whether a feature exists, is specified, or is provisional. Skip launch copy. Skip vague praise. A useful sentence names the part, the behavior, and the limit.

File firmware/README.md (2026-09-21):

# KINO D4 firmware

Production firmware for the KINO D4 camera: one ESP32-P4 main controller
(`p4/`), one ESP32-S3 binary shared by all four camera nodes (`camnode/`), and
the ESP32-C6 radio coprocessor image (`c6/`).
Both implement the contract in [`firmware-contract/`](../firmware-contract/README.md).
The plan and audit behind this tree is [`FIRMWARE_START_PLAN.md`](FIRMWARE_START_PLAN.md);
the current milestone is [`MILESTONE_1B_PLAN.md`](MILESTONE_1B_PLAN.md), its bench
procedure [`BENCH_M1B.md`](BENCH_M1B.md), and the bench record
[`HARDWARE_VALIDATION.md`](HARDWARE_VALIDATION.md).

## Layout

| Path | Contents |
|---|---|
| `components/kdp_core/` | Portable C99 KDP framing: CRC-32, encoder, stream decoder. No ESP-IDF dependency |
| `components/kdp_core/host_tests/` | Contract-fixture tests, run under plain gcc |
| `p4/host_tests/` | Nine host test binaries for P4 logic that needs no board: pure helpers, the Roll upload queue, the C6 state model, the radio report seam, the QR encoder, the META.JSON and UPLOAD.JSON mappings, `board_d4v1.h` against the measured JP1 header, and the hardware-validation predicates |
| `p4/host_preview/` | Renders the P4's UI screens to a file on the host, so layout and the QR can be looked at without a panel |
| `components/node_link/` | P4↔XIAO command namespace on the same framing |
| `p4/` | ESP-IDF app, target `esp32p4` — Guition JC4880P443C-I-W |
| `camnode/` | ESP-IDF app, target `esp32s3` — XIAO ESP32-S3 Sense |
| `c6/` | ESP-IDF app, target `esp32c6` — the radio coprocessor on the Guition carrier. Espressif's official ESP-Hosted coprocessor image, not KINO networking code: the C6 is a radio, not a second application brain. Flashed and running on `KD4-D121BC` since 2026-08-29 — read [`c6/README.md`](c6/README.md) before writing C6 flash on any other board |
| `uvc-preview/` | Bench tool, target `esp32s3` — makes one XIAO a USB webcam so a camera module can be judged before any harness exists. Never ships in a camera |
| `VERSION` | The firmware version, checked by `npm run version:check` |
| `C6_HARDWARE_MAP.md` | The P4↔C6 routing, its evidence chain, and what is still unmeasured |
| `C6_BRINGUP.md` | The order to bring the radio up in, and the recovery drills that get skipped |

Pin maps live in exactly two files: `p4/main/board_d4v1.h` and
`camnode/main/board_xiao_s3.h`. `c6/` declares none — the C6's SDIO slave pads
are fixed in silicon and its own transport config comes from the ESP-Hosted
component, so a second copy would only be somewhere to drift. `uvc-preview` includes the latter rather than
declaring pins of its own — a bench tool that disagreed with the product
firmware about a GPIO would be worse than no bench tool. Assignments are PROVISIONAL until issue #2
locks them electrically.

## Build

Toolchain: ESP-IDF v5.5.1. Building needs no local install — the Docker image
is the canonical build environment (run from the repo root):

```
docker run --rm -v "$PWD:/project" -w /project/firmware/p4      espressif/idf:v5.5.1 idf.py build
docker run --rm -v "$PWD:/project" -w /project/firmware/camnode espressif/idf:v5.5.1 idf.py build

# The radio coprocessor image. Flashed and running on KD4-D121BC since
# 2026-08-29 — see the table above and c6/README.md. Read c6/README.md before
# writing C6 flash on any OTHER board: the module's flash size is not known
# for every carrier, and an oversized FLASHSIZE flashes and then fails to boot.
docker run --rm -v "$PWD:/project" -w /project/firmware/c6      espressif/idf:v5.5.1 idf.py build

# Bench tool, same container (see uvc-preview/README.md before flashing it: the
# USB-C port becomes a webcam, so reflashing needs BOOT + RESET).
docker run --rm -v "$PWD:/project" -w /project/firmware/uvc-preview espressif/idf:v5.5.1 idf.py build
```

On Linux add `--user "$(id -u):$(id -g)"` or `build/` ends up root-owned.
Studio can drive the same build through `npm run firmware:daemon`
(docs/FIRMWARE_BUILDER.md).

`p4` and `camnode` build at `-O2` (`CONFIG_COMPILER_OPTIMIZATION_PERF`). For a
debugger-friendly `-Og` image add the overlay; nothing else differs:

```
idf.py -DSDKCONFIG_DEFAULTS="sdkconfig.defaults;sdkconfig.debug" build
```

A `sdkconfig` generated before firmware 0.4.2 keeps `-Og` until it is
regenerated (`idf.py fullclean`, or delete `sdkconfig`). Timing measured on a
debug build is not product timing; say which one a bench record came from. The
same applies to the partition table: a `sdkconfig` generated before 0.4.9 still
selects the old built-in single-app table. Since 0.4.10 the build refuses that
state (`CONFIG_PARTITION_TABLE_CUSTOM` guard in `p4/main/CMakeLists.txt`)
instead of silently putting the app in a `factory` partition. Delete
`sdkconfig` after pulling the repartition and rebuild.

`camnode` pulls `espressif/esp32-camera` (pinned 2.1.7, resolved versions in
the committed `dependencies.lock`) from the component registry on first build
(network required once; `managed_components/` is git-ignored).

## Flashing the P4

Flashing DOES need a local ESP-IDF (or esptool) install — the container
cannot reach the serial port on Windows/macOS. From a machine with the board
attached and IDF v5.5.1 installed:

```
idf.py -p <port> flash monitor
```

or with a standalone esptool: `esptool.py --chip esp32p4 -p <port> write_flash
"@build/flash_args"` from `firmware/p4/build`.

### Offsets

`firmware/p4/partitions.csv` (16 MB part) puts four images on the chip:

| Offset | Image |
|---|---|
| `0x2000` | `bootloader/bootloader.bin` |
| `0x8000` | `partition_table/partition-table.bin` |
| `0xa000` | `ota_data_initial.bin` |
| `0x10000`  | `kino-p4.bin` |

Written out, from `firmware/p4/build`:

```
esptool.py --chip esp32p4 -p <port> write_flash \
  0x2000 bootloader/bootloader.bin \
  0x8000 partition_table/partition-table.bin \
  0xa000 ota_data_initial.bin \
  0x10000 kino-p4.bin
```

`0xa000` is new. The old built-in table had no `otadata`; the new one has two
OTA slots and the bootloader reads `otadata` to pick between them.
`ota_data_initial.bin` is 8 KB of `0xff` — "neither slot selected", which makes
the bootloader fall through to `ota_0`. Skip it on a unit that has been flashed
before and the bootloader reads whatever bytes were already at `0xa000` (on
this board, old NVS) and may refuse to boot.

The app offset did not change. `ota_0` starts at `0x10000`, where the old
`factory` partition started, so a `kino-p4.bin` built before the repartition
still flashes and boots there.

### Updating over KDP, and the nodes' one-time flash

Since 0.4.58 the P4 writes its own updates (`FW_BEGIN`..`FW_END`, `main/fw_update.c`)
and forwards a node's image down its UART. From the bench:

```
npx tsx scripts/kino-fw-update.mjs --port COM8 --target p4 --image firmware/p4/build-hand-radio/kino-p4.bin
npx tsx scripts/kino-fw-update.mjs --port COM8 --target cam2 --image firmware/camnode/build/kino-camnode.bin
```

Both images boot with rollback armed; the P4 confirms itself once the panel and the
host link are up, a node when it answers its first HELLO. `--corrupt` flips a byte
after hashing: `FW_END` must answer `CHECKSUM_FAILED` and the old slot keeps booting.

A node can only be updated over the link once it is on `camnode/partitions.csv` (two
OTA slots; the app moves from `0x10000` to `0x20000`). That first flash is over the
node's own USB, from `firmware/camnode/build`:

```
esptool.py --chip esp32s3 -p <port> write_flash   0x0 bootloader/bootloader.bin   0x8000 partition_table/partition-table.bin   0x10000 ota_data_initial.bin   0x20000 kino-camnode.bin
```

A node still on the single-app table refuses `FW_BEGIN` with `HARDWARE_ERROR`, and the
P4 relays that verbatim.

### A partition table change erases NVS

Not a warning about what might happen — it is what happens. The old table put
NVS at `0x9000`; the new one puts `phy_init` and `otadata` there and NVS at
`0x610000`. Everything the camera had stored is gone:

- **config** — the whole config document (`kino` namespace), plus the boot and
  capture counters.
- **hwv rows** — all 56 validation items, both keys each (`hwv`).
- **saved Wi-Fi networks** — up to 8 SSIDs and passphrases (`kino_wifi`).
- **the Roll device credential** — the identity this unit registered with on
  the LAN backend (`kino_roll`).
- **the clock** — last known epoch and UTC offset (`clock`). The unit comes up
  without a wall clock until something sets it.

What brings each back:

- config, sounds and recipes: Studio's backup/restore. Take the backup BEFORE
  flashing; there is no way to read it off the unit afterwards.
- hwv rows: re-earned, not restored. Each item is a measurement and has to be
  taken again on the bench. Record the session in `HARDWARE_VALIDATION.md`.
- Wi-Fi: `NETWORK_SET` per network. Passphrases are not in the Studio backup by
  design (`main/wifi_creds.h`), so have them to hand.
- Roll: the unit re-registers with the LAN backend on its next connection and
  gets a new device credential. The old registration is stale on the backend
  side; clean it up there.

### Does it need a full erase?

`erase_flash` is not required by ESP-IDF. Writing the four images above is the
complete set: the new NVS region at `0x610000` was never addressed by the old
table so it reads as erased, and `nvs_flash_init()` in `main.c` already erases
and re-initialises on `ESP_ERR_NVS_NO_FREE_PAGES`.

Do it anyway on the first unit. The old NVS occupied `0x9000`–`0xf000`, which
is now `phy_init` and `otadata`. `ota_data_initial.bin` covers `0xa000`, but
nothing in the four-image set writes `0x9000`, so `phy_init` would be left
holding stale NVS bytes. That is recoverable — the PHY checks the format
version and the MAC in its stored calibration and recalibrates on a mismatch —
but NVS is lost either way, so the erase costs nothing that was not already
gone and removes the question:

```
esptool.py --chip esp32p4 -p <port> erase_flash
```

then the four-image write above.

## Protocol tests

Runs on the host with make + gcc (Windows: inside WSL), from the repo root:

```
make -C firmware/components/kdp_core/host_tests test
```

Runs the framing contract fixtures (HELLO CRC `0x149bdd86`, minimum-frame CRC
`0x82d816e4`), split/coalesced frames, boot spew, CRC corruption, oversized
length, and trailing-magic resync cases under plain gcc.

## P4 host tests

The same shape, one level up: P4 logic that needs no board, nine binaries.

```
make -C firmware/p4/host_tests test-all
```

`test`, `test-queue`, `test-net`, `test-report`, `test-qr`, `test-pins` and
`test-hwv` need only a C compiler. `test-meta` and `test-store` compile against
ESP-IDF's own cJSON rather than a vendored copy that could drift from the one
the firmware links, so they want `IDF_PATH` set — run them inside the
`espressif/idf:v5.5.1` container, which is where CI builds the firmware anyway.
`make -C firmware/p4/host_tests test` is the subset that runs with nothing
installed. The Makefile header says what each target covers and why it is its
own target.

`firmware/p4/host_preview/` is next to them and is half a test: `make -C
firmware/p4/host_preview && ./preview out/` renders all 190 of the camera's
screens with the firmware's own drawing code - every failure state, and the
frames of every transition - so a layout, a join QR or a move can be looked at
without a panel.

The half that IS a test is the safe-area audit: the run exits non-zero if any
screen sets type outside the page margin, naming the string and the screen it
was on. Clipping is the obvious fault, but the one an interface actually has is
a sentence ending two pixels from the bezel - it does not look broken, it looks
cheap, and it is much harder to see than a missing word. It found four screens
doing it on the day it was written.

## Milestone state

This section described Milestone 1B (issue #66) and was left at it: seven
commands plus the bench group, "everything else answers
`UNSUPPORTED_COMMAND`", "every other capability flag is `false`", and "CAM1 is
the only wired node". None of that is the shipping firmware. Read
[`firmware-contract/README.md`](../firmware-contract/README.md#d17--72-commands-declared-56-dispatched)
for the authoritative allocation, and `GET_CAPABILITIES` on a body for what
that body can do — a count in prose here is a number that rots.

Where it actually stands at 0.4.55: the dispatcher answers **56** of the 72
commands `commands.ts` declares, and NACKs the rest from its default case. The
config store, the whole `MEDIA_*` group, `CAMERA_CAPTURE`, the `SOUND_*` group
and the eleven `0xa0`–`0xaa` network and Roll commands are all served. Eleven
capability flags report true. All four camera nodes are wired and answer;
captures land in `/KINO/CAPTURES/<uuid>/` with a `kino.capture` META.JSON, and
since 0.4.4 they reach a Roll from the body itself.

The bench diagnostics group, gated by the `benchDiagnostics` capability, is
`CAMERA_TEST` (measured stages, three agreeing CRC-32 checksums, memory
stats), `STORAGE_SELF_TEST`, `STORAGE_BENCH`, `CAMERA_LINK_STATS(_RESET)`,
`CAMERA_SOAK_TEST` (async job) and `GET_HW_VALIDATION` (per-unit runtime
registry, 56 items, persisted in NVS). `GET_RUNTIME_STATS` (real on-chip
temperatures or null, live protocol counters), `GET_LOGS`/`CLEAR_LOGS` + `LOG`
events (200-entry structured ring) and a six-check `SELF_TEST` with events are
implemented outside that gate.

Much of this is bench-validated. [`HARDWARE_VALIDATION.md`](HARDWARE_VALIDATION.md)
is the record and the only authority on which row is which; as of 2026-08-29 it
carries the panel, touch, I²C bus and audio codec; the whole CAM1 path from
`CAM1_TX_GPIO52`/`CAM1_RX_GPIO51` at 921600 through sensor detect, capture,
JPEG transfer and SD write with matching CRCs; the SD card on slot 0; KDP over
USB-Serial-JTAG; and the C6 transport — SDIO enumeration, the `GPIO54` enable
line on the meter, the version gate at 3.0.6, Wi-Fi scan, association, DHCP,
DNS and SNTP, and `ROLL_CREATE` against a real backend.

What stays **UNVALIDATED**: inter-camera
exposure skew and everything else behind the sync gate, `SYNC_TRIGGER_GPIO32`
(driven, and since node firmware 0.4.30 the nodes DO count edges and report
`syncSeq`/`syncEdgeUs`, which `handle_sync_bench` polls — what no node does is
*arm* on the edge), `FLASH_EN_GPIO28` (no longer routed at all:
`board_d4v1.h` leaves `BOARD_FLASH_EN` as `BOARD_GPIO_NONE` and gives
GPIO28/JP1-21 to `BOARD_BTN_SHUTTER` under ECN-0003, so probing that pin for a
flash enable finds a button), the shutter and Fn buttons (no switch fitted),
`C6_TLS` (the API is not deployed) and `SD_C6_COEXIST`.

CAM2–CAM4 came off that list: all four nodes are wired and answer. The record
below has a pre-check reading 4x READY, grouped shutters carrying all four
frames, and a controlled-loss test that powers CAM2 down mid-session and
brings it back — which is also what proved nothing is hard-coded to camera 2,
because the same test on CAM3 leaves a different hole with the same result.

`C6_ROLL_UPLOAD` is no longer in that list: 0.4.4 is the first firmware whose
photographs reached a Roll from the body, 0.4.6 closed the local gate
(**LOCAL ROLL E2E GO**, **GATE F GO** for the connected single-camera path),
and every ROLL session since has uploaded. It was still written here as "no
capture has reached a Roll from this body".

These are per-unit runtime rows, so what a given body has validated is what
`GET_HW_VALIDATION` says about that body. Read the validation file, or the
camera, rather than this paragraph before making a claim.

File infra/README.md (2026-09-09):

# KINO environments

KINO keeps development, staging, and production isolated. They do not share credentials, databases, object buckets, Compose project names, or persistent volumes.

## Local development

The development stack exposes PostgreSQL, Redis, and MinIO to the host for the test suite:

```sh
docker compose -f infra/docker-compose.dev.yml up -d
npm run db:migrate --workspace @kino/api
```

Its committed credentials are disposable and must never be reused elsewhere.

## Staging

1. Copy `infra/.env.staging.example` to `infra/.env.staging`.
2. Replace every `change-me` value with independently generated credentials.
3. Ensure passwords used inside `DATABASE_URL` and `REDIS_URL` are URL-safe or percent encoded.
4. Point the staging DNS name at the host.
5. Start the isolated stack:

```sh
docker compose --env-file infra/.env.staging -f infra/docker-compose.prod.yml up -d --build
```

The `KINO_ENV=staging` value gives the stack its own Compose project and therefore its own volumes. The sample maps staging to ports 8080/8443 so it cannot take over production listeners on the same host.

## Windows server (deploy.ps1)

`infra/deploy.ps1` wraps the production Compose stack for a Windows server running Docker with Compose v2. PowerShell 5.1 is enough.

```powershell
powershell -ExecutionPolicy Bypass -File infra\deploy.ps1 init    # env file + generated secrets
# edit infra\.env.production: KINO_SITE_ADDRESS, PUBLIC_BASE_URL
powershell -ExecutionPolicy Bypass -File infra\deploy.ps1 check   # docker, placeholders, interpolation
powershell -ExecutionPolicy Bypass -File infra\deploy.ps1 up      # build, start, wait for healthy
powershell -ExecutionPolicy Bypass -File infra\deploy.ps1 update  # git pull --ff-only + up
powershell -ExecutionPolicy Bypass -File infra\deploy.ps1 status
powershell -ExecutionPolicy Bypass -File infra\deploy.ps1 logs -Service api
powershell -ExecutionPolicy Bypass -File infra\deploy.ps1 backup  # pg_dump to infra\backups\
powershell -ExecutionPolicy Bypass -File infra\deploy.ps1 drain -Roll amber-001 -Expect 137
powershell -ExecutionPolicy Bypass -File infra\deploy.ps1 event-backup -Roll amber-001 -BackupRoot D:\kino-backups
powershell -ExecutionPolicy Bypass -File infra\deploy.ps1 down    # volumes preserved
```

`drain` and `event-backup` exist for the on-demand event model below. `drain`
answers "is it safe to shut this PC down yet" in one command: it reads each
camera's last heartbeat and this server's own rows out of PostgreSQL, counts the
objects in the bucket, and exits 0 only on `SAFE TO SHUT DOWN`. `event-backup`
takes one snapshot of **both** stores into
`<BackupRoot>\events\<yyyy-MM-dd>-<slug>` and verifies it — it is
`backup-task.ps1 run` plus `verify` with a per-event root, not a third backup
implementation. Both are documented step by step in
[`docs/runbooks/event-day.md`](../docs/runbooks/event-day.md).

`init` replaces every `change-me` placeholder with a generated secret, keeping the same token identical everywhere it appears (so `DATABASE_URL`/`REDIS_URL` stay consistent with the passwords). `-EnvName staging` targets `infra/.env.staging` instead. `backup` covers the database only; the MinIO volume follows `infra/scripts/backup.sh`.

`-Relay` adds `infra/relay/docker-compose.relay.yml` to the file list and must be passed on **every** action of a relay deployment, `down` and `logs` included. Without it the file list is the production file alone: the frpc container is dropped and 80/443 are republished on the host, which is exactly what the relay exists to avoid. `check` also refuses to be quiet about a port that is already held - see "Ports 80 and 443 on the PC are taken" below.

## Production (manual steps)

1. Copy `infra/.env.prod.example` to `infra/.env.production`.
2. Replace every placeholder with production-only credentials. Generate `COOKIE_SECRET` from at least 32 random bytes.
3. Point `KINO_SITE_ADDRESS` and `PUBLIC_BASE_URL` at the production DNS name.
4. Start the stack:

```sh
docker compose --env-file infra/.env.production -f infra/docker-compose.prod.yml up -d --build
```

Only Caddy publishes host ports. PostgreSQL, Redis, MinIO, the API, the worker, and the static web service remain on the private Compose network. Caddy obtains and renews TLS automatically for a public hostname, streams server-sent events without buffering, sends `/api/*` to the API, and serves Studio at `/studio/` with Roll everywhere else. Roll invitation and host pages receive an `X-Robots-Tag: noindex, nofollow, noarchive` header.

Server-sent events need two things from every Caddy hop, not one. `flush_interval -1` on the `/api/*` proxy is the first. The second is that `text/event-stream` is never compressed: Caddy's default `encode` match includes `text/*`, which covers SSE, and a compressor in front of a long-lived stream delivers a batch of events minutes late instead of one event now. All three Caddyfiles (`Caddyfile`, `Caddyfile.tunnel`, `relay/vps/Caddyfile`) therefore replace the default with an explicit eight-entry Content-Type allow list that omits it. Verified by adapting each file with the pinned `caddy:2.10.2-alpine` image: the JSON matcher lists the eight types and the string `event-stream` does not appear anywhere in the adapted config.

Production sets `OBJECT_DELIVERY=proxy`: media and firmware bytes pass through the authorized API rather than exposing an internal MinIO URL. Local development retains short-lived presigned URLs.

Production also defaults to `DEVICE_REGISTRATION_MODE=first-write-wins`. Re-submitting a serial can never rotate a deployed device's credential. If a physically verified device loses its token, first restrict public access to the registration endpoint, set `DEVICE_REGISTRATION_MODE=rotate` for a maintenance restart, register that one device, then restore `first-write-wins` and public access immediately. Never leave rotation enabled on an internet-reachable API.

The migration container must finish successfully before the API and worker start. A failed migration leaves the application stopped instead of booting against a partial schema.

`JOB_QUEUE_PREFIX` must have the same value in the API and worker. Compose supplies it through their shared environment; changing it on only one process writes jobs to a queue no worker consumes.

## Verification

Validate interpolation without starting services:

```sh
docker compose --env-file infra/.env.prod.example -f infra/docker-compose.prod.yml config --quiet
```

After startup, verify `https://<host>/api/healthz`, `/`, and `/studio/`. The complete upload-to-gallery staging exercise is automated by the Task 37 test uploader.

### Camera-simulating uploader

The uploader exercises the same HTTP contract as a camera, including multipart resume semantics and the real background worker. It never prints device or host credentials.

For a fresh disposable device and Roll:

```sh
npm run test:uploader -- --base-url https://staging.kino.acronym.sk --serial KD4-STAGING-0001 --drop-part 3 --dup-retry --slow 200ms --close
```

`--drop-part 3` treats the third successful part response as lost and sends that numbered part again. `--dup-retry` replays capture creation, upload completion, completed asset initialization, and capture completion. The command succeeds only after every capture is `ready`, appears in the guest feed, and—when `--close` is set—the Roll is closed.

For an already registered device, keep its bearer token out of shell history and process listings:

```sh
export KINO_DEVICE_ID=dev_example
export KINO_DEVICE_TOKEN=kdt_example
npm run test:uploader -- --base-url https://staging.kino.acronym.sk --join ABC123
```

Load mode uses the same upload path and can add concurrent, fully paginated guest readers. Start below the production budgets and increase deliberately while watching queue depth and error rate:

```sh
npm run test:uploader -- --base-url https://staging.kino.acronym.sk --serial KD4-LOAD-0001 --captures 4 --viewers 24 --viewer-polls 2
```

The upload budget is 120 requests per minute per device token **per route** for a registered camera (`deviceUpload` in `apps/api/src/plugins/rateLimits.ts`; 60 is only the fallback for a bearer the `devices` table does not know). The counter is keyed by method and route pattern, so the five upload routes each carry their own 120 and the budgets are not pooled. One four-frame capture spends seventeen mutations — 1 capture create, 5 `assets/init`, 5 part `PUT`, 5 upload complete, 1 capture complete — so the busiest route is 5 per capture and the sustained ceiling is 24 captures a minute, one every 2.5 s.

For a hundreds-of-captures endurance run, pace one camera with `--slow 1s` or run multiple physically distinct test-device credentials. Do not weaken the production budget merely to make a benchmark finish sooner.

`--concurrency N` runs N captures in flight at once (default 1, clamped to `--captures`). It multiplies the per-route spend, so raise it only when you are measuring the limiter itself. `--title TEXT` names the Roll the run creates; the default is `KINO uploader acceptance`, so set it when a staging run has to be findable afterwards on the host dashboard.

Run `npm run test:uploader -- --help` for fixture, timeout, and pacing options. Production registration is first-write-wins, so reuse `KINO_DEVICE_ID` and `KINO_DEVICE_TOKEN` after the initial physically controlled registration instead of attempting to register the serial again.

### Per-camera thumbnail backfill

`infra/scripts/backfill-thumbnails.ts` re-queues `generate-thumbnail` for captures processed before the worker started writing one thumbnail per camera. Those captures still make a capture page fetch four full originals — 754 kB instead of 293 kB. Nothing is migrated: the job is idempotent, so the tool only queues work.

```sh
npx tsx infra/scripts/backfill-thumbnails.ts --roll RRG8AZ            # dry run, writes nothing
npx tsx infra/scripts/backfill-thumbnails.ts --roll RRG8AZ --apply    # queue it, 100 captures at a time
```

Dry run is the default and reports how many captures are affected and how much storage the run would add. It is safe to run twice, and re-running it is the resume. A backfill raises the host dashboard's Pending count for as long as it runs, so do not start one during a live party. Procedure, measured costs and the interruption behaviour are in [the thumbnail backfill runbook](../docs/runbooks/thumbnail-backfill.md).

## PC-hosted production behind a tunnel (first production phase)

> **This phase is ON-DEMAND EVENT HOSTING, not a 24/7 service.** The stack runs
> on event days and long enough afterwards for the upload queue to drain and one
> backup to finish; then the PC may sleep or be shut down. The event workflow —
> the twelve-check pre-event list, what to say when the origin disappears
> mid-party, the drain gate, the event backup, and how to disable sleep for one
> evening and put the setting back — is
> [`docs/runbooks/event-day.md`](../docs/runbooks/event-day.md). The move to a
> dedicated always-on machine is
> [`docs/runbooks/origin-machine-move.md`](../docs/runbooks/origin-machine-move.md),
> and that is where a permanent sleep disable, unattended availability and
> constant Docker uptime become requirements. They are not requirements here.

> **Deployment day is written out step by step in
> [`docs/runbooks/production-relay-deploy.md`](../docs/runbooks/production-relay-deploy.md)**:
> what to provision, the one Websupport record, the commands on the VPS and on
> the PC in order, verification through the canonical URL, how to tell a dead
> tunnel from a dead stack, rollback, the Windows sleep/reboot remedies, and a
> gate list that ends in a yes/no. This section is the design; that document is
> the procedure.

The canonical product URL is `https://kino.acronym.sk`. For the first
production phase the stack runs on the operator's Windows PC, and the public
hostname reaches it through an **outbound** tunnel. Clients never learn a LAN
address, a PC name or a temporary IP: the D4's stored `network.apiBase`, the
PWA's same-origin API and `PUBLIC_BASE_URL` all say `kino.acronym.sk`, so a
later move to a server is a DNS/tunnel change and nothing else.
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

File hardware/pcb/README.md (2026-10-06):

# Carrier-board source

D4 V1 currently uses a perfboard or Perma-Proto-style carrier. No production PCB is released.

A component-level [carrier A0.2 draft](kino-d4-carrier-a0/README.md) now exists, with four sockets at 22 mm pitch and the P4 mounting pattern. Its working PCB has components on both faces and partial routing. The [strict release review](kino-d4-carrier-a0/A02-REVIEW.md) rejects it for fabrication pending electrical, routing and mechanical resolution.

Before a PCB release, commit:
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

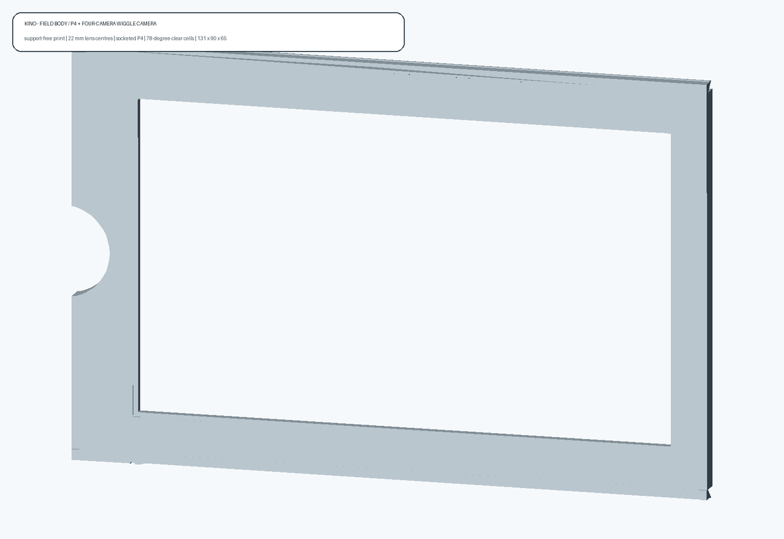
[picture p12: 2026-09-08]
hardware/cad/KINO_FIELD_BODY/previews/KINO_FIELD_BEZEL_FRONT.png

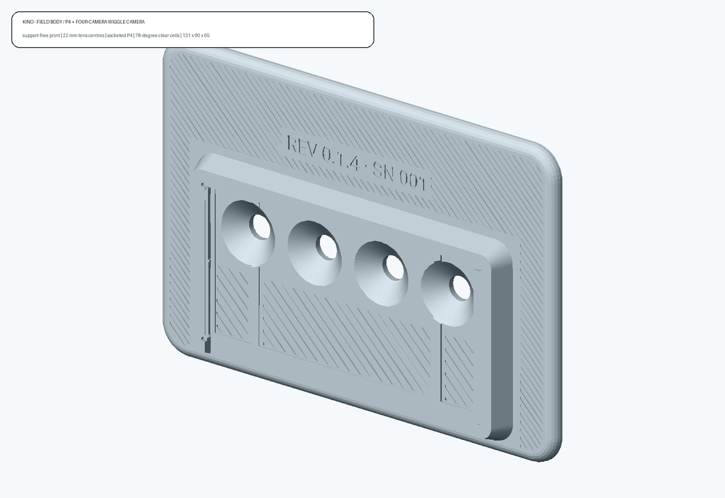
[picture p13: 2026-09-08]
hardware/cad/KINO_FIELD_BODY/previews/KINO_FIELD_FACE_PREVIEW.png

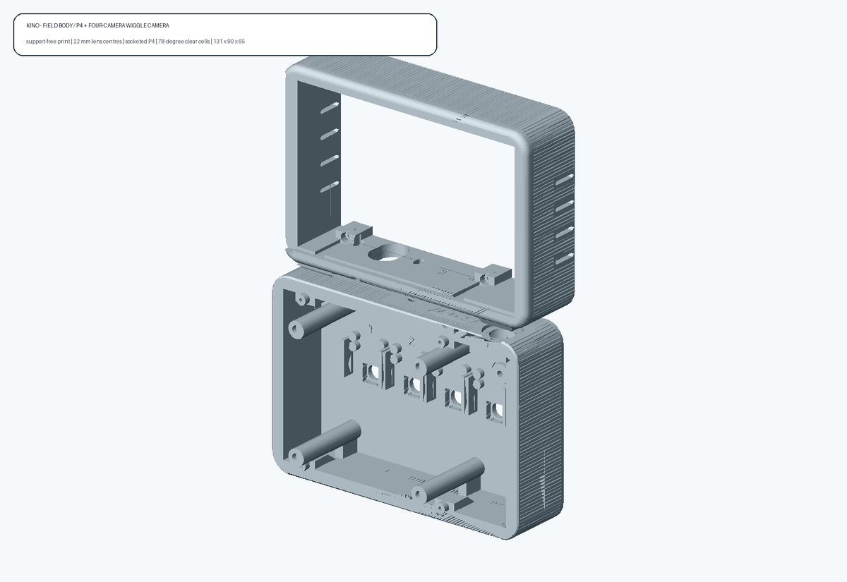
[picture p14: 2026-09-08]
hardware/cad/KINO_FIELD_BODY/previews/KINO_PLATE_1_CHASSIS_PREVIEW.png

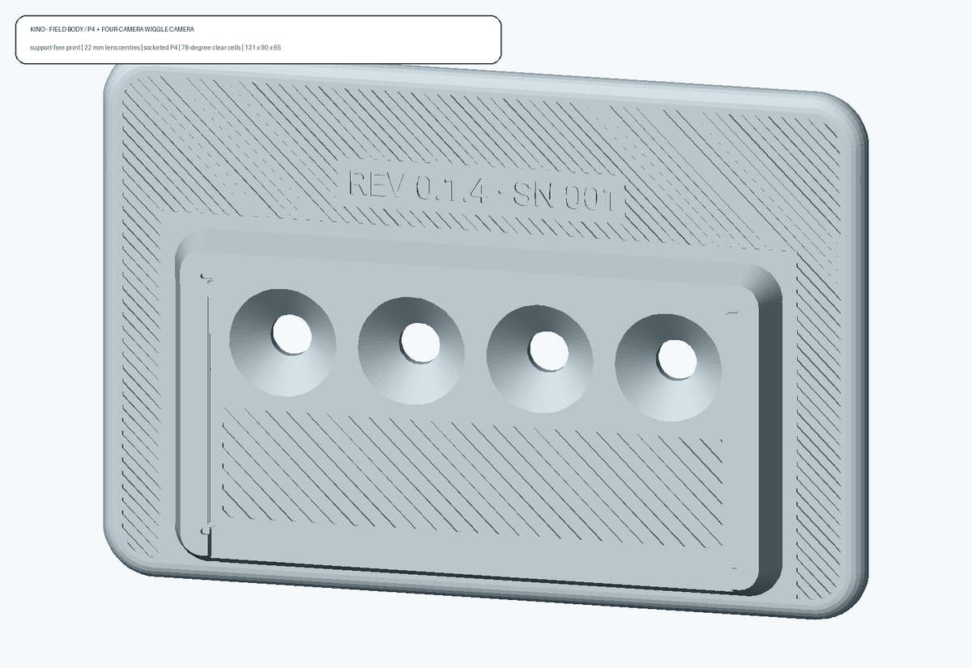
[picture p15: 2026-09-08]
hardware/cad/KINO_FIELD_BODY/previews/KINO_FIELD_FACE_FRONT.png

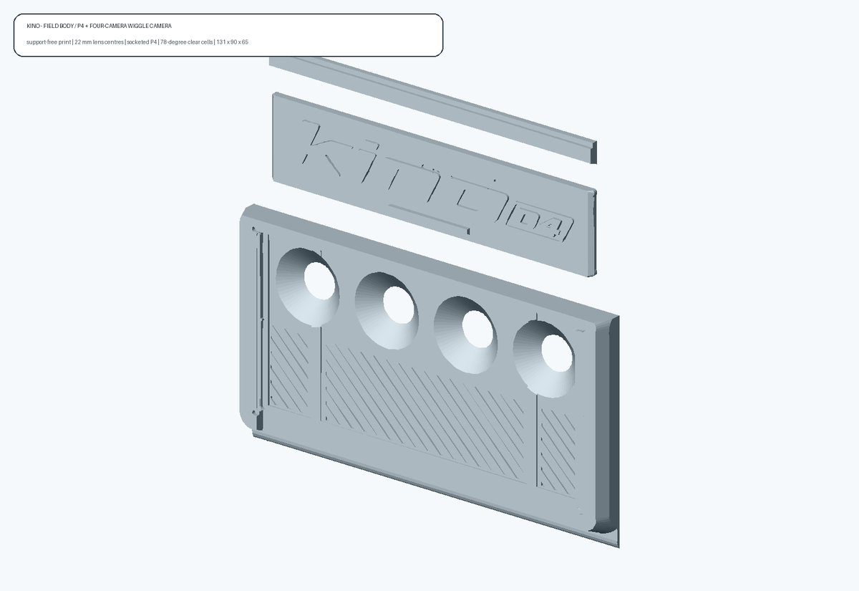
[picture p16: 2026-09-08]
hardware/cad/KINO_FIELD_BODY/previews/KINO_SLIDER_TRACK_COUPON_PREVIEW.png

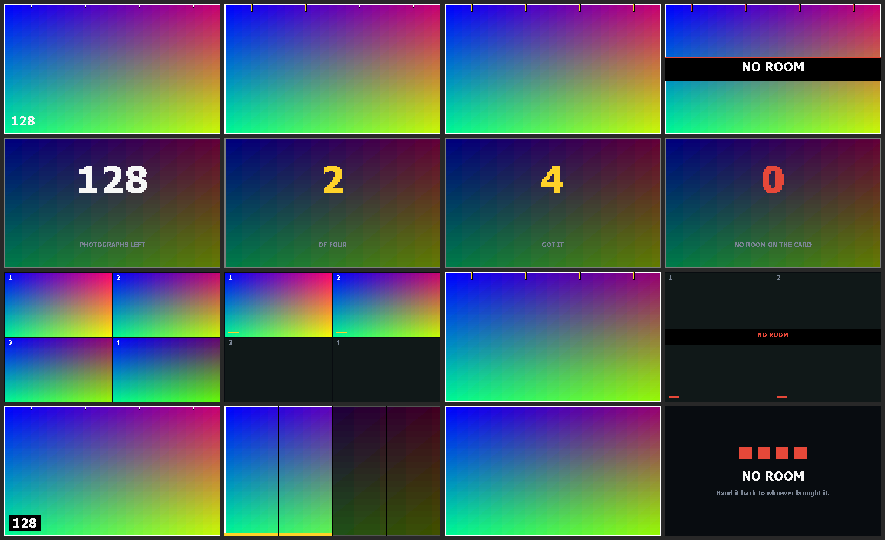
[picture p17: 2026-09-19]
firmware/p4/host_preview/specimen/SPECIMEN.png

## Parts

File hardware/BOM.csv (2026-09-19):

id | qty | part | model_or_value | confidence | notes
main-display | 1 | ESP32-P4 display module | Guition JC4880P443C-I-W | OFFICIAL_SPEC_CONFLICT | ESP32-P4 + ESP32-C6; 4.3in 480x800; measure exact board envelope
camera-node | 4 | Camera controller and sensor | Seeed XIAO ESP32-S3 Sense with OV3660 | OFFICIAL_SPEC | 21.0x17.8x15.0mm module envelope
battery | 1 | LiPo battery | 505573 1S 3.7V 3000mAh 11.1Wh | PROVISIONAL_SIZE_CODE_MEASURE_ACTUAL | PH2.0-3P; 3A sustained harness limit; measure pouch and lead exit
fuse | 1 | Fast axial fuse | F3A 3A | SELLER_SPEC | Place near battery positive
bms | 1 | LiPo protection board | 1S 10A | MEASURE_REQUIRED | System sustained rating remains limited by battery harness
power-module | 1 | Bidirectional charger and boost module | SW6106 18W class | SELLER_SPEC_PROVISIONAL | Approx. 28x28x11.36mm; produces 5V rail
camera-switch | 4 | High-side camera power channel | AO4407 or AO4407A + 2N3904 | PCB_LAYOUT_DEPENDENT | Per channel: SOP8 adapter; 4.7k; 100k gate pull-up; 100k base pull-down; 1N5819
speaker | 1 | Speaker | 8ohm 2W approx. 25x35mm | SELLER_SPEC_MEASURE_THICKNESS | 1.25mm 2-pin plug
micro-sd | 1 | microSD card | SanDisk Ultra 32GB | STANDARD | Central original-frame storage
p4-ribbon | 1 | IDC ribbon | 26-pin 2x13 2.54mm approx. 100mm | SELLER_SPEC | Mark pin 1 and preserve bend radius
camera-harness | 4 | Detachable camera harness | PH2.0 4-pin approx. 100mm | SELLER_SPEC | 5V; GND; P4 TX to XIAO RX; P4 RX from XIAO TX
sync-wire | 4 | Shared-sync branch wire | 28AWG | KNOWN_WIRE_GAUGE | One separate branch per camera node
main-power-wire | as-routed | Silicone power wire | 20AWG | KNOWN_WIRE_GAUGE | Battery; 5V rail; main ground
bulk-cap | design-dependent | Bulk capacitor | 1000uF 10V low-ESR | MEASURE_REQUIRED | Quantity and placement depend on measured rail transients
bypass-cap | design-dependent | Ceramic bypass capacitor | 100nF 50V | PACKAGE_MEASURE_REQUIRED | Place locally at switched loads
tact-switch | design-dependent | Tactile switch | 6x6x4.3mm | SELLER_SPEC | Controls pending final carrier layout
slide-switch | 1 | SPDT slide switch | MSK-22D14 | MEASURE_REQUIRED | Logic input only
perfboard | 1 | Main carrier | DKAWS or Perma-Proto style | MEASURE_REQUIRED | V1 carrier; do not carry high current on thin traces
field-body | 1 | Camera body | KINO_FIELD_BODY 0.1.4 (PETG; two chassis halves; face shell; sliding lens cover + keeper; rear door; XIAO clamps; shutter button) | OFFICIAL_CAD | hardware/cad/KINO_FIELD_BODY; 131x90x65.5mm; USB-C powered fixture - no pack bay (ECN-0004)

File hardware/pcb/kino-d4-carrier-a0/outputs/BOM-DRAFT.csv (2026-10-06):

Reference | Value | MPN_candidate | Footprint | DNP | Status | Design_note | Source
J100 | P4 JP1 - 26 pin IDC | Wurth Elektronik 61202621621 | Connector_IDC:IDC-Header_2x13_P2.54mm_Vertical | False | A02_RELEASE_CANDIDATE | 1:1 electrical pin numbering; verify cable and mating views. | https://www.we-online.com/components/products/datasheet/61202621621.pdf
J101 | C6 service - 3V3 sense only | Wurth Elektronik 61300611121 | Connector_PinHeader_2.54mm:PinHeader_1x06_P2.54mm_Vertical | False | A02_RELEASE_CANDIDATE |  | https://www.we-online.com/components/products/datasheet/61300611121.pdf
U100 | TCA9517ADGKR | TCA9517ADGKR | Package_SO:VSSOP-8_3x3mm_P0.65mm | False | A02_RELEASE_CANDIDATE | A side is local: its hard low suits the STUSB4500 (VIL 0.35 V), BQ25798 (0.4 V), DRV2605L and BQ27441. B side (buffered low 0.45-0.6 V) faces the P4 bus (P4 VIL 0.825 V). No other offset buffer or rise-time accelerator on the P4 bus. | https://www.ti.com/lit/ds/symlink/tca9517a.pdf
R100 | 2.2k | RC0603FR-072K2L | Resistor_SMD:R_0603_1608Metric | False | A02_RELEASE_CANDIDATE | With R101: EN 3.0 V with the P4 on; 0.66 V worst case with JP1 pin 1 open against the TCA9517 EN pull-up (30 uA max), under its 0.99 V VIL and the TXU0304 OE 0.89 V VT- min. | https://www.yageogroup.com/component-documentation/download/specsheet/RC0603FR-072K2L
R101 | 22k | RC0603FR-0722KL | Resistor_SMD:R_0603_1608Metric | False | A02_RELEASE_CANDIDATE |  | https://www.yageogroup.com/component-documentation/download/specsheet/RC0603FR-0722KL
R102 | 4.7k | RC0603FR-074K7L | Resistor_SMD:R_0603_1608Metric | False | A02_RELEASE_CANDIDATE |  | https://www.yageogroup.com/component-documentation/download/specsheet/RC0603FR-074K7L
R103 | 4.7k | RC0603FR-074K7L | Resistor_SMD:R_0603_1608Metric | False | A02_RELEASE_CANDIDATE |  | https://www.yageogroup.com/component-documentation/download/specsheet/RC0603FR-074K7L
R105 | 100k | RC0603FR-07100KL | Resistor_SMD:R_0603_1608Metric | False | A02_RELEASE_CANDIDATE | P4 GPIO32 is Hi-Z from reset until firmware drives it; holds the shared sync (and the J601 flash option) low. ODD JOBS 116/117. | https://www.yageogroup.com/component-documentation/download/specsheet/RC0603FR-07100KL
C100 | 100n 50V | YAGEO CC0603KRX7R9BB104 | Capacitor_SMD:C_0603_1608Metric | False | A02_RELEASE_CANDIDATE |  | https://www.yageogroup.com/component-documentation/download/specsheet/CC0603KRX7R9BB104
R104 | 100k | RC0603FR-07100KL | Resistor_SMD:R_0603_1608Metric | False | A02_RELEASE_CANDIDATE |  | https://www.yageogroup.com/component-documentation/download/specsheet/RC0603FR-07100KL
J102 | 3V3 I2C accessory | JST BM04B-GHS-TBT(LF)(SN) | Connector_JST:JST_GH_BM04B-GHS-TBT_1x04-1MP_P1.25mm_Vertical | False | A02_RELEASE_CANDIDATE |  | https://www.jst-mfg.com/product/pdf/eng/eGH.pdf
F100 | PTC 100mA | Bel Fuse 0ZCJ0010FF2E | Fuse:Fuse_1206_3216Metric | False | A02_RELEASE_CANDIDATE | Accessory protection and ESD review open. | https://www.belfuse.com/media/datasheets/products/circuit-protection/ds-cp-0zcj-series.pdf
TP100 | P4_3V3_TEST | PCB feature - no fitted component | TestPoint:TestPoint_Pad_D1.5mm | False | A02_RELEASE_CANDIDATE
TP101 | SYNC_MASTER | PCB feature - no fitted component | TestPoint:TestPoint_Pad_D1.5mm | False | A02_RELEASE_CANDIDATE
TP102 | P4_5V | PCB feature - no fitted component | TestPoint:TestPoint_Pad_D1.5mm | False | A02_RELEASE_CANDIDATE
J200 | XIAO ESP32-S3 Sense socket | 2 x Wurth Elektronik 61300711821 | KINO_A0:XIAO_Socket_15.24mm | False | A02_RELEASE_CANDIDATE | Two 1x07 sockets; 22 mm camera pitch. 5V shared with node USB; isolate via the 0 ohm link for USB service. | https://www.we-online.com/components/products/datasheet/61300711821.pdf
J201 | GPIO breakout - SD/strap restrictions | Wurth Elektronik 61301021121 | Connector_PinHeader_2.54mm:PinHeader_2x05_P2.54mm_Vertical | False | A02_RELEASE_CANDIDATE |  | https://www.we-online.com/components/products/datasheet/61301021121.pdf
JP200 | 0R LINK - REMOVE FOR NODE USB | Vishay CRCW12060000Z0EAHP | KINO_A0:R_1206_3216Metric_Vishay_CRCW-HP | False | A02_RELEASE_CANDIDATE | 0 ohm link, fitted for camera operation. Desolder before connecting node USB; refit after. Flat on the front: the XIAO stays the tallest part there. | https://www.vishay.com/docs/20043/crcwhpe3.pdf
U200 | TXU0304PWR | TXU0304PWR | Package_SO:TSSOP-14_4.4x5mm_P0.65mm | False | A02_RELEASE_CANDIDATE |  | https://www.ti.com/lit/ds/symlink/txu0304.pdf
R200 | 33 | RC0603FR-0733RL | Resistor_SMD:R_0603_1608Metric | False | A02_RELEASE_CANDIDATE |  | https://www.yageogroup.com/component-documentation/download/specsheet/RC0603FR-0733RL
R201 | 33 | RC0603FR-0733RL | Resistor_SMD:R_0603_1608Metric | False | A02_RELEASE_CANDIDATE |  | https://www.yageogroup.com/component-documentation/download/specsheet/RC0603FR-0733RL
R202 | 33 | RC0603FR-0733RL | Resistor_SMD:R_0603_1608Metric | False | A02_RELEASE_CANDIDATE |  | https://www.yageogroup.com/component-documentation/download/specsheet/RC0603FR-0733RL
C200 | 100n 50V | YAGEO CC0603KRX7R9BB104 | Capacitor_SMD:C_0603_1608Metric | False | A02_RELEASE_CANDIDATE |  | https://www.yageogroup.com/component-documentation/download/specsheet/CC0603KRX7R9BB104
C201 | 100n 50V | YAGEO CC0603KRX7R9BB104 | Capacitor_SMD:C_0603_1608Metric | False | A02_RELEASE_CANDIDATE |  | https://www.yageogroup.com/component-documentation/download/specsheet/CC0603KRX7R9BB104
U201 | TPS2553DBVR | TPS2553DBVR | Package_TO_SOT_SMD:SOT-23-6 | False | A02_RELEASE_CANDIDATE |  | https://www.ti.com/lit/ds/symlink/tps2553.pdf
R203 | 25.5k 1% | RC0603FR-0725K5L | Resistor_SMD:R_0603_1608Metric | False | A02_RELEASE_CANDIDATE | Approx. 1A target; verify min/max and startup before release. | https://www.yageogroup.com/component-documentation/download/specsheet/RC0603FR-0725K5L
R204 | 10k | RC0603FR-0710KL | Resistor_SMD:R_0603_1608Metric | False | A02_RELEASE_CANDIDATE |  | https://www.yageogroup.com/component-documentation/download/specsheet/RC0603FR-0710KL
R205 | 100k | RC0603FR-07100KL | Resistor_SMD:R_0603_1608Metric | False | A02_RELEASE_CANDIDATE |  | https://www.yageogroup.com/component-documentation/download/specsheet/RC0603FR-07100KL
RS200 | 0.020 1% 1W | Vishay Dale WSLP1206R0200FEA | Resistor_SMD:R_1206_3216Metric | False | A02_RELEASE_CANDIDATE | Kelvin pair to U700 from the pad inner corners (route_a02_kelvin.py). | https://www.vishay.com/docs/30122/wslp.pdf
D200 | SS34 | Diodes Incorporated B340A-13-F | Diode_SMD:D_SMA | False | A02_RELEASE_CANDIDATE | Reverse node USB-to-carrier isolation; does not prevent carrier-to-host VBUS feed without removing the link. | https://www.diodes.com/datasheet/download/B340A.pdf
C202 | 1u 50V | Samsung Electro-Mechanics CL10A105KB8NNNC | Capacitor_SMD:C_0603_1608Metric | False | A02_RELEASE_CANDIDATE |  | https://weblib.samsungsem.com/mlcc/mlcc-ec-data-sheet.do?partNumber=CL10A105KB8NNN
C203 | 22u 10V | Samsung Electro-Mechanics CL21A226MAQNNNE | Capacitor_SMD:C_0805_2012Metric | False | A02_RELEASE_CANDIDATE |  | https://weblib.samsungsem.com/mlcc/mlcc-ec-data-sheet.do?partNumber=CL21A226MAQNNN
C204 | 100n 50V | YAGEO CC0603KRX7R9BB104 | Capacitor_SMD:C_0603_1608Metric | False | A02_RELEASE_CANDIDATE |  | https://www.yageogroup.com/component-documentation/download/specsheet/CC0603KRX7R9BB104
TP200 | CAM1_5V | PCB feature - no fitted component | TestPoint:TestPoint_Pad_D1.5mm | False | A02_RELEASE_CANDIDATE
TP201 | CAM1_SYNC | PCB feature - no fitted component | TestPoint:TestPoint_Pad_D1.5mm | False | A02_RELEASE_CANDIDATE
J300 | XIAO ESP32-S3 Sense socket | 2 x Wurth Elektronik 61300711821 | KINO_A0:XIAO_Socket_15.24mm | False | A02_RELEASE_CANDIDATE | Two 1x07 sockets; 22 mm camera pitch. 5V shared with node USB; isolate via the 0 ohm link for USB service. | https://www.we-online.com/components/products/datasheet/61300711821.pdf
J301 | GPIO breakout - SD/strap restrictions | Wurth Elektronik 61301021121 | Connector_PinHeader_2.54mm:PinHeader_2x05_P2.54mm_Vertical | False | A02_RELEASE_CANDIDATE |  | https://www.we-online.com/components/products/datasheet/61301021121.pdf
JP300 | 0R LINK - REMOVE FOR NODE USB | Vishay CRCW12060000Z0EAHP | KINO_A0:R_1206_3216Metric_Vishay_CRCW-HP | False | A02_RELEASE_CANDIDATE | 0 ohm link, fitted for camera operation. Desolder before connecting node USB; refit after. Flat on the front: the XIAO stays the tallest part there. | https://www.vishay.com/docs/20043/crcwhpe3.pdf
U300 | TXU0304PWR | TXU0304PWR | Package_SO:TSSOP-14_4.4x5mm_P0.65mm | False | A02_RELEASE_CANDIDATE |  | https://www.ti.com/lit/ds/symlink/txu0304.pdf
R300 | 33 | RC0603FR-0733RL | Resistor_SMD:R_0603_1608Metric | False | A02_RELEASE_CANDIDATE |  | https://www.yageogroup.com/component-documentation/download/specsheet/RC0603FR-0733RL
R301 | 33 | RC0603FR-0733RL | Resistor_SMD:R_0603_1608Metric | False | A02_RELEASE_CANDIDATE |  | https://www.yageogroup.com/component-documentation/download/specsheet/RC0603FR-0733RL
R302 | 33 | RC0603FR-0733RL | Resistor_SMD:R_0603_1608Metric | False | A02_RELEASE_CANDIDATE |  | https://www.yageogroup.com/component-documentation/download/specsheet/RC0603FR-0733RL
C300 | 100n 50V | YAGEO CC0603KRX7R9BB104 | Capacitor_SMD:C_0603_1608Metric | False | A02_RELEASE_CANDIDATE |  | https://www.yageogroup.com/component-documentation/download/specsheet/CC0603KRX7R9BB104
C301 | 100n 50V | YAGEO CC0603KRX7R9BB104 | Capacitor_SMD:C_0603_1608Metric | False | A02_RELEASE_CANDIDATE |  | https://www.yageogroup.com/component-documentation/download/specsheet/CC0603KRX7R9BB104
U301 | TPS2553DBVR | TPS2553DBVR | Package_TO_SOT_SMD:SOT-23-6 | False | A02_RELEASE_CANDIDATE |  | https://www.ti.com/lit/ds/symlink/tps2553.pdf
R303 | 25.5k 1% | RC0603FR-0725K5L | Resistor_SMD:R_0603_1608Metric | False | A02_RELEASE_CANDIDATE | Approx. 1A target; verify min/max and startup before release. | https://www.yageogroup.com/component-documentation/download/specsheet/RC0603FR-0725K5L
R304 | 10k | RC0603FR-0710KL | Resistor_SMD:R_0603_1608Metric | False | A02_RELEASE_CANDIDATE |  | https://www.yageogroup.com/component-documentation/download/specsheet/RC0603FR-0710KL
R305 | 100k | RC0603FR-07100KL | Resistor_SMD:R_0603_1608Metric | False | A02_RELEASE_CANDIDATE |  | https://www.yageogroup.com/component-documentation/download/specsheet/RC0603FR-07100KL
RS300 | 0.020 1% 1W | Vishay Dale WSLP1206R0200FEA | Resistor_SMD:R_1206_3216Metric | False | A02_RELEASE_CANDIDATE | Kelvin pair to U700 from the pad inner corners (route_a02_kelvin.py). | https://www.vishay.com/docs/30122/wslp.pdf
D300 | SS34 | Diodes Incorporated B340A-13-F | Diode_SMD:D_SMA | False | A02_RELEASE_CANDIDATE | Reverse node USB-to-carrier isolation; does not prevent carrier-to-host VBUS feed without removing the link. | https://www.diodes.com/datasheet/download/B340A.pdf
C302 | 1u 50V | Samsung Electro-Mechanics CL10A105KB8NNNC | Capacitor_SMD:C_0603_1608Metric | False | A02_RELEASE_CANDIDATE |  | https://weblib.samsungsem.com/mlcc/mlcc-ec-data-sheet.do?partNumber=CL10A105KB8NNN
C303 | 22u 10V | Samsung Electro-Mechanics CL21A226MAQNNNE | Capacitor_SMD:C_0805_2012Metric | False | A02_RELEASE_CANDIDATE |  | https://weblib.samsungsem.com/mlcc/mlcc-ec-data-sheet.do?partNumber=CL21A226MAQNNN
C304 | 100n 50V | YAGEO CC0603KRX7R9BB104 | Capacitor_SMD:C_0603_1608Metric | False | A02_RELEASE_CANDIDATE |  | https://www.yageogroup.com/component-documentation/download/specsheet/CC0603KRX7R9BB104
TP300 | CAM2_5V | PCB feature - no fitted component | TestPoint:TestPoint_Pad_D1.5mm | False | A02_RELEASE_CANDIDATE
TP301 | CAM2_SYNC | PCB feature - no fitted component | TestPoint:TestPoint_Pad_D1.5mm | False | A02_RELEASE_CANDIDATE
J400 | XIAO ESP32-S3 Sense socket | 2 x Wurth Elektronik 61300711821 | KINO_A0:XIAO_Socket_15.24mm | False | A02_RELEASE_CANDIDATE | Two 1x07 sockets; 22 mm camera pitch. 5V shared with node USB; isolate via the 0 ohm link for USB service. | https://www.we-online.com/components/products/datasheet/61300711821.pdf
J401 | GPIO breakout - SD/strap restrictions | Wurth Elektronik 61301021121 | Connector_PinHeader_2.54mm:PinHeader_2x05_P2.54mm_Vertical | False | A02_RELEASE_CANDIDATE |  | https://www.we-online.com/components/products/datasheet/61301021121.pdf
JP400 | 0R LINK - REMOVE FOR NODE USB | Vishay CRCW12060000Z0EAHP | KINO_A0:R_1206_3216Metric_Vishay_CRCW-HP | False | A02_RELEASE_CANDIDATE | 0 ohm link, fitted for camera operation. Desolder before connecting node USB; refit after. Flat on the front: the XIAO stays the tallest part there. | https://www.vishay.com/docs/20043/crcwhpe3.pdf
U400 | TXU0304PWR | TXU0304PWR | Package_SO:TSSOP-14_4.4x5mm_P0.65mm | False | A02_RELEASE_CANDIDATE |  | https://www.ti.com/lit/ds/symlink/txu0304.pdf
R400 | 33 | RC0603FR-0733RL | Resistor_SMD:R_0603_1608Metric | False | A02_RELEASE_CANDIDATE |  | https://www.yageogroup.com/component-documentation/download/specsheet/RC0603FR-0733RL
R401 | 33 | RC0603FR-0733RL | Resistor_SMD:R_0603_1608Metric | False | A02_RELEASE_CANDIDATE |  | https://www.yageogroup.com/component-documentation/download/specsheet/RC0603FR-0733RL
R402 | 33 | RC0603FR-0733RL | Resistor_SMD:R_0603_1608Metric | False | A02_RELEASE_CANDIDATE |  | https://www.yageogroup.com/component-documentation/download/specsheet/RC0603FR-0733RL
C400 | 100n 50V | YAGEO CC0603KRX7R9BB104 | Capacitor_SMD:C_0603_1608Metric | False | A02_RELEASE_CANDIDATE |  | https://www.yageogroup.com/component-documentation/download/specsheet/CC0603KRX7R9BB104
C401 | 100n 50V | YAGEO CC0603KRX7R9BB104 | Capacitor_SMD:C_0603_1608Metric | False | A02_RELEASE_CANDIDATE |  | https://www.yageogroup.com/component-documentation/download/specsheet/CC0603KRX7R9BB104
U401 | TPS2553DBVR | TPS2553DBVR | Package_TO_SOT_SMD:SOT-23-6 | False | A02_RELEASE_CANDIDATE |  | https://www.ti.com/lit/ds/symlink/tps2553.pdf
R403 | 25.5k 1% | RC0603FR-0725K5L | Resistor_SMD:R_0603_1608Metric | False | A02_RELEASE_CANDIDATE | Approx. 1A target; verify min/max and startup before release. | https://www.yageogroup.com/component-documentation/download/specsheet/RC0603FR-0725K5L
R404 | 10k | RC0603FR-0710KL | Resistor_SMD:R_0603_1608Metric | False | A02_RELEASE_CANDIDATE |  | https://www.yageogroup.com/component-documentation/download/specsheet/RC0603FR-0710KL
R405 | 100k | RC0603FR-07100KL | Resistor_SMD:R_0603_1608Metric | False | A02_RELEASE_CANDIDATE |  | https://www.yageogroup.com/component-documentation/download/specsheet/RC0603FR-07100KL
RS400 | 0.020 1% 1W | Vishay Dale WSLP1206R0200FEA | Resistor_SMD:R_1206_3216Metric | False | A02_RELEASE_CANDIDATE | Kelvin pair to U700 from the pad inner corners (route_a02_kelvin.py). | https://www.vishay.com/docs/30122/wslp.pdf
D400 | SS34 | Diodes Incorporated B340A-13-F | Diode_SMD:D_SMA | False | A02_RELEASE_CANDIDATE | Reverse node USB-to-carrier isolation; does not prevent carrier-to-host VBUS feed without removing the link. | https://www.diodes.com/datasheet/download/B340A.pdf
C402 | 1u 50V | Samsung Electro-Mechanics CL10A105KB8NNNC | Capacitor_SMD:C_0603_1608Metric | False | A02_RELEASE_CANDIDATE |  | https://weblib.samsungsem.com/mlcc/mlcc-ec-data-sheet.do?partNumber=CL10A105KB8NNN
C403 | 22u 10V | Samsung Electro-Mechanics CL21A226MAQNNNE | Capacitor_SMD:C_0805_2012Metric | False | A02_RELEASE_CANDIDATE |  | https://weblib.samsungsem.com/mlcc/mlcc-ec-data-sheet.do?partNumber=CL21A226MAQNNN
C404 | 100n 50V | YAGEO CC0603KRX7R9BB104 | Capacitor_SMD:C_0603_1608Metric | False | A02_RELEASE_CANDIDATE |  | https://www.yageogroup.com/component-documentation/download/specsheet/CC0603KRX7R9BB104
TP400 | CAM3_5V | PCB feature - no fitted component | TestPoint:TestPoint_Pad_D1.5mm | False | A02_RELEASE_CANDIDATE
TP401 | CAM3_SYNC | PCB feature - no fitted component | TestPoint:TestPoint_Pad_D1.5mm | False | A02_RELEASE_CANDIDATE
J500 | XIAO ESP32-S3 Sense socket | 2 x Wurth Elektronik 61300711821 | KINO_A0:XIAO_Socket_15.24mm | False | A02_RELEASE_CANDIDATE | Two 1x07 sockets; 22 mm camera pitch. 5V shared with node USB; isolate via the 0 ohm link for USB service. | https://www.we-online.com/components/products/datasheet/61300711821.pdf
J501 | GPIO breakout - SD/strap restrictions | Wurth Elektronik 61301021121 | Connector_PinHeader_2.54mm:PinHeader_2x05_P2.54mm_Vertical | False | A02_RELEASE_CANDIDATE |  | https://www.we-online.com/components/products/datasheet/61301021121.pdf
JP500 | 0R LINK - REMOVE FOR NODE USB | Vishay CRCW12060000Z0EAHP | KINO_A0:R_1206_3216Metric_Vishay_CRCW-HP | False | A02_RELEASE_CANDIDATE | 0 ohm link, fitted for camera operation. Desolder before connecting node USB; refit after. Flat on the front: the XIAO stays the tallest part there. | https://www.vishay.com/docs/20043/crcwhpe3.pdf
U500 | TXU0304PWR | TXU0304PWR | Package_SO:TSSOP-14_4.4x5mm_P0.65mm | False | A02_RELEASE_CANDIDATE |  | https://www.ti.com/lit/ds/symlink/txu0304.pdf
R500 | 33 | RC0603FR-0733RL | Resistor_SMD:R_0603_1608Metric | False | A02_RELEASE_CANDIDATE |  | https://www.yageogroup.com/component-documentation/download/specsheet/RC0603FR-0733RL
R501 | 33 | RC0603FR-0733RL | Resistor_SMD:R_0603_1608Metric | False | A02_RELEASE_CANDIDATE |  | https://www.yageogroup.com/component-documentation/download/specsheet/RC0603FR-0733RL
R502 | 33 | RC0603FR-0733RL | Resistor_SMD:R_0603_1608Metric | False | A02_RELEASE_CANDIDATE |  | https://www.yageogroup.com/component-documentation/download/specsheet/RC0603FR-0733RL
C500 | 100n 50V | YAGEO CC0603KRX7R9BB104 | Capacitor_SMD:C_0603_1608Metric | False | A02_RELEASE_CANDIDATE |  | https://www.yageogroup.com/component-documentation/download/specsheet/CC0603KRX7R9BB104
C501 | 100n 50V | YAGEO CC0603KRX7R9BB104 | Capacitor_SMD:C_0603_1608Metric | False | A02_RELEASE_CANDIDATE |  | https://www.yageogroup.com/component-documentation/download/specsheet/CC0603KRX7R9BB104
U501 | TPS2553DBVR | TPS2553DBVR | Package_TO_SOT_SMD:SOT-23-6 | False | A02_RELEASE_CANDIDATE |  | https://www.ti.com/lit/ds/symlink/tps2553.pdf
R503 | 25.5k 1% | RC0603FR-0725K5L | Resistor_SMD:R_0603_1608Metric | False | A02_RELEASE_CANDIDATE | Approx. 1A target; verify min/max and startup before release. | https://www.yageogroup.com/component-documentation/download/specsheet/RC0603FR-0725K5L
R504 | 10k | RC0603FR-0710KL | Resistor_SMD:R_0603_1608Metric | False | A02_RELEASE_CANDIDATE |  | https://www.yageogroup.com/component-documentation/download/specsheet/RC0603FR-0710KL
R505 | 100k | RC0603FR-07100KL | Resistor_SMD:R_0603_1608Metric | False | A02_RELEASE_CANDIDATE |  | https://www.yageogroup.com/component-documentation/download/specsheet/RC0603FR-07100KL
RS500 | 0.020 1% 1W | Vishay Dale WSLP1206R0200FEA | Resistor_SMD:R_1206_3216Metric | False | A02_RELEASE_CANDIDATE | Kelvin pair to U700 from the pad inner corners (route_a02_kelvin.py). | https://www.vishay.com/docs/30122/wslp.pdf
D500 | SS34 | Diodes Incorporated B340A-13-F | Diode_SMD:D_SMA | False | A02_RELEASE_CANDIDATE | Reverse node USB-to-carrier isolation; does not prevent carrier-to-host VBUS feed without removing the link. | https://www.diodes.com/datasheet/download/B340A.pdf
C502 | 1u 50V | Samsung Electro-Mechanics CL10A105KB8NNNC | Capacitor_SMD:C_0603_1608Metric | False | A02_RELEASE_CANDIDATE |  | https://weblib.samsungsem.com/mlcc/mlcc-ec-data-sheet.do?partNumber=CL10A105KB8NNN
C503 | 22u 10V | Samsung Electro-Mechanics CL21A226MAQNNNE | Capacitor_SMD:C_0805_2012Metric | False | A02_RELEASE_CANDIDATE |  | https://weblib.samsungsem.com/mlcc/mlcc-ec-data-sheet.do?partNumber=CL21A226MAQNNN
C504 | 100n 50V | YAGEO CC0603KRX7R9BB104 | Capacitor_SMD:C_0603_1608Metric | False | A02_RELEASE_CANDIDATE |  | https://www.yageogroup.com/component-documentation/download/specsheet/CC0603KRX7R9BB104
TP500 | CAM4_5V | PCB feature - no fitted component | TestPoint:TestPoint_Pad_D1.5mm | False | A02_RELEASE_CANDIDATE
TP501 | CAM4_SYNC | PCB feature - no fitted component | TestPoint:TestPoint_Pad_D1.5mm | False | A02_RELEASE_CANDIDATE
U600 | TCA9539PWR | TCA9539PWR | Package_SO:TSSOP-24_4.4x7.8mm_P0.65mm | False | A02_RELEASE_CANDIDATE | TCA9539 PW pin map verified against TI; address 0x74 candidate. Port 1 (pins 13-20, P1.0-P1.7): IMU_INT, RTC_INT_N, SOFT_KILL, unused, POWER_INT_N, FN_N, HAPTIC_EN, COVER_N; P1.3 (pin 16) is not connected (no layout path from the charger on the far side of the board): firmware reads the charge state from the BQ25798 status registers over I2C; configure P1.3 as an input. Order set by the layout: the lines leaving south take pins 13-17 in the order they reach their parts. | https://www.ti.com/lit/ds/symlink/tca9539.pdf
R600 | 10k | RC0603FR-0710KL | Resistor_SMD:R_0603_1608Metric | False | A02_RELEASE_CANDIDATE |  | https://www.yageogroup.com/component-documentation/download/specsheet/RC0603FR-0710KL
C600 | 100n | YAGEO CC0603KRX7R9BB104 | Capacitor_SMD:C_0603_1608Metric | False | A02_RELEASE_CANDIDATE |  | https://www.yageogroup.com/component-documentation/download/specsheet/CC0603KRX7R9BB104
C601 | 100n 50V | YAGEO CC0603KRX7R9BB104 | Capacitor_SMD:C_0603_1608Metric | False | A02_RELEASE_CANDIDATE |  | https://www.yageogroup.com/component-documentation/download/specsheet/CC0603KRX7R9BB104
U601 | SN74LVC08APWR | SN74LVC08APWR | Package_SO:TSSOP-14_4.4x5mm_P0.65mm | False | A02_RELEASE_CANDIDATE |  | https://www.ti.com/lit/ds/symlink/sn74lvc08a.pdf
C602 | 100n 50V | YAGEO CC0603KRX7R9BB104 | Capacitor_SMD:C_0603_1608Metric | False | A02_RELEASE_CANDIDATE |  | https://www.yageogroup.com/component-documentation/download/specsheet/CC0603KRX7R9BB104
R601 | 100k | RC0603FR-07100KL | Resistor_SMD:R_0603_1608Metric | False | A02_RELEASE_CANDIDATE |  | https://www.yageogroup.com/component-documentation/download/specsheet/RC0603FR-07100KL
R602 | 100k | RC0603FR-07100KL | Resistor_SMD:R_0603_1608Metric | False | A02_RELEASE_CANDIDATE |  | https://www.yageogroup.com/component-documentation/download/specsheet/RC0603FR-07100KL
R603 | 100k | RC0603FR-07100KL | Resistor_SMD:R_0603_1608Metric | False | A02_RELEASE_CANDIDATE |  | https://www.yageogroup.com/component-documentation/download/specsheet/RC0603FR-07100KL
R604 | 100k | RC0603FR-07100KL | Resistor_SMD:R_0603_1608Metric | False | A02_RELEASE_CANDIDATE |  | https://www.yageogroup.com/component-documentation/download/specsheet/RC0603FR-07100KL
J600 | POGO TEST - SENSE ONLY | PCB feature - no fitted component | KINO_A0:Pogo_12_Asymmetric | False | A02_RELEASE_CANDIDATE | 1.5mm ENIG pads, no paste. Pad 1 offset for fixture orientation. Measure enables; do not drive against U601. Rails are sense points, not a power injection connector. Pads 9-11 are unconnected: CAM2-CAM4_EN have no layout path down to the field, so they are probed at TP600-TP602 beside their lines at the top of the board.
TP600 | CAM2_EN | PCB feature - no fitted component | TestPoint:TestPoint_Pad_D1.5mm | False | A02_RELEASE_CANDIDATE
TP601 | CAM3_EN | PCB feature - no fitted component | TestPoint:TestPoint_Pad_D1.5mm | False | A02_RELEASE_CANDIDATE
TP602 | CAM4_EN | PCB feature - no fitted component | TestPoint:TestPoint_Pad_D1.5mm | False | A02_RELEASE_CANDIDATE
J601 | EXTERNAL FLASH LOGIC | JST BM05B-GHS-TBT(LF)(SN) | Connector_JST:JST_GH_BM05B-GHS-TBT_1x05-1MP_P1.25mm_Vertical | True | A02_RELEASE_CANDIDATE | Logic-only internal interface. External driver must arm via I2C and gate shared SYNC. No dedicated FLASH_EN is available in the retained P4 map. Flash load requires its own qualified supply; AUX_3V3 is behind the accessory PTC. | https://www.jst-mfg.com/product/pdf/eng/eGH.pdf
R605 | 33 | RC0603FR-0733RL | Resistor_SMD:R_0603_1608Metric | True | A02_RELEASE_CANDIDATE | Fit with J601 only after external flash-driver timing/loading review. | https://www.yageogroup.com/component-documentation/download/specsheet/RC0603FR-0733RL
U700 | PAC1954T-E/4MX | PAC1954T-E/4MX | KINO_A0:VQFN-16-1EP_3x3mm_P0.5mm_EP1.1x1.1mm_Pin1Corner | False | A02_RELEASE_CANDIDATE | ADDRSEL tied to GND (pin 6 to the exposed pad) gives 7-bit 0x10 (Microchip evaluation guide section 4.6); the only PAC1954 on the bus, so no strap resistor. PWRDN high enables; SLOW low gives default sample rate. | https://ww1.microchip.com/downloads/en/DeviceDoc/PAC195X-Data-Sheet-20006539.pdf
C700 | 100n 50V | YAGEO CC0603KRX7R9BB104 | Capacitor_SMD:C_0603_1608Metric | False | A02_RELEASE_CANDIDATE |  | https://www.yageogroup.com/component-documentation/download/specsheet/CC0603KRX7R9BB104
C701 | 1u | Samsung Electro-Mechanics CL10A105KB8NNNC | Capacitor_SMD:C_0603_1608Metric | False | A02_RELEASE_CANDIDATE |  | https://weblib.samsungsem.com/mlcc/mlcc-ec-data-sheet.do?partNumber=CL10A105KB8NNN
U701 | BQ27441DRZR-G1A | BQ27441DRZR-G1A | Package_SON:Texas_S-PDSO-N12 | False | A02_RELEASE_CANDIDATE | TI SLUSBH1C pin table: SRP (8) Kelvin to RS700 pack side, SRN (7) Kelvin to RS700 system side, BAT (6) Kelvin to pack positive. GPOUT must not float. | http://www.ti.com/lit/ds/symlink/bq27441-g1.pdf
C702 | 470n | Samsung Electro-Mechanics CL10B474KA8NNNC | Capacitor_SMD:C_0603_1608Metric | False | A02_RELEASE_CANDIDATE |  | https://weblib.samsungsem.com/mlcc/mlcc-ec-data-sheet.do?partNumber=CL10B474KA8NNN
C703 | 1u 50V | Samsung Electro-Mechanics CL10A105KB8NNNC | Capacitor_SMD:C_0603_1608Metric | False | A02_RELEASE_CANDIDATE | TI: 1 uF from BAT to VSS, close to the gauge.
R701 | 10k | RC0603FR-0710KL | Resistor_SMD:R_0603_1608Metric | False | A02_RELEASE_CANDIDATE | Embedded pack: BIN 10k to VSS per TI. | https://www.yageogroup.com/component-documentation/download/specsheet/RC0603FR-0710KL
R702 | 10k | RC0603FR-0710KL | Resistor_SMD:R_0603_1608Metric | False | A02_RELEASE_CANDIDATE | TI: GPOUT must not float; 10k pull-up to the gauge VDD, which stays up with the camera off. | https://www.yageogroup.com/component-documentation/download/specsheet/RC0603FR-0710KL
RS700 | 0.005 1% 1W | Vishay Dale WSLP12065L000FEA | Resistor_SMD:R_1206_3216Metric | False | A02_RELEASE_CANDIDATE | High side after F1100. 4.4 A = 22 mV (gauge range 25 mV), 97 mW. Kelvin taps from the pad inner edges. | https://www.vishay.com/en/product/30122/
U800 | LSM6DSOXTR | LSM6DSOXTR | Package_LGA:LGA-14_3x2.5mm_P0.5mm_LayoutBorder3x4y | False | A02_RELEASE_CANDIDATE |  | https://www.st.com/resource/en/datasheet/lsm6dsox.pdf
C800 | 100n 50V | YAGEO CC0603KRX7R9BB104 | Capacitor_SMD:C_0603_1608Metric | False | A02_RELEASE_CANDIDATE |  | https://www.yageogroup.com/component-documentation/download/specsheet/CC0603KRX7R9BB104
C801 | 100n 50V | YAGEO CC0603KRX7R9BB104 | Capacitor_SMD:C_0603_1608Metric | False | A02_RELEASE_CANDIDATE |  | https://www.yageogroup.com/component-documentation/download/specsheet/CC0603KRX7R9BB104
U801 | RV-3028-C7 | Micro Crystal RV-3028-C7 32.768kHz 1ppm TA QC | Package_SON:MicroCrystal_C7_SON-8_1.5x3.2mm_P0.9mm | False | A02_RELEASE_CANDIDATE |  | https://www.microcrystal.com/fileadmin/Media/Products/RTC/Datasheet/RV-3028-C7.pdf
C802 | 100n 50V | YAGEO CC0603KRX7R9BB104 | Capacitor_SMD:C_0603_1608Metric | False | A02_RELEASE_CANDIDATE |  | https://www.yageogroup.com/component-documentation/download/specsheet/CC0603KRX7R9BB104
R800 | 10k | RC0603FR-0710KL | Resistor_SMD:R_0603_1608Metric | False | A02_RELEASE_CANDIDATE |  | https://www.yageogroup.com/component-documentation/download/specsheet/RC0603FR-0710KL
J800 | 3V PRIMARY RTC BACKUP | JST BM02B-GHS-TBT(LF)(SN) | Connector_JST:JST_GH_BM02B-GHS-TBT_1x02-1MP_P1.25mm_Vertical | False | A02_RELEASE_CANDIDATE | Insulated remote backup cell holder; disable RTC trickle charging in hardware configuration/firmware. | https://www.jst-mfg.com/product/pdf/eng/eGH.pdf
U802 | TMP117AIDRVR | TMP117AIDRVR | Package_SON:WSON-6-1EP_2x2mm_P0.65mm_EP1x1.6mm | False | A02_RELEASE_CANDIDATE |  | https://www.ti.com/lit/ds/symlink/tmp117.pdf
C803 | 100n 50V | YAGEO CC0603KRX7R9BB104 | Capacitor_SMD:C_0603_1608Metric | False | A02_RELEASE_CANDIDATE |  | https://www.yageogroup.com/component-documentation/download/specsheet/CC0603KRX7R9BB104
U900 | DRV2605LDGSR | DRV2605LDGSR | Package_SO:TSSOP-10_3x3mm_P0.5mm | False | A02_RELEASE_CANDIDATE |  | http://www.ti.com/lit/ds/symlink/drv2605l.pdf
C900 | 1u | Samsung Electro-Mechanics CL10A105KB8NNNC | Capacitor_SMD:C_0603_1608Metric | False | A02_RELEASE_CANDIDATE |  | https://weblib.samsungsem.com/mlcc/mlcc-ec-data-sheet.do?partNumber=CL10A105KB8NNN
C901 | 1u | Samsung Electro-Mechanics CL10A105KB8NNNC | Capacitor_SMD:C_0603_1608Metric | False | A02_RELEASE_CANDIDATE |  | https://weblib.samsungsem.com/mlcc/mlcc-ec-data-sheet.do?partNumber=CL10A105KB8NNN
C902 | 10u | Samsung Electro-Mechanics CL21A106KAYNNNE | Capacitor_SMD:C_0805_2012Metric | False | A02_RELEASE_CANDIDATE |  | https://weblib.samsungsem.com/mlcc/mlcc-ec-data-sheet.do?partNumber=CL21A106KAYNNN
R900 | 100k | RC0603FR-07100KL | Resistor_SMD:R_0603_1608Metric | False | A02_RELEASE_CANDIDATE |  | https://www.yageogroup.com/component-documentation/download/specsheet/RC0603FR-07100KL
J900 | HAPTIC MOTOR | JST BM02B-GHS-TBT(LF)(SN) | Connector_JST:JST_GH_BM02B-GHS-TBT_1x02-1MP_P1.25mm_Vertical | False | A02_RELEASE_CANDIDATE | Matched LRA/ERM selection and calibration open. | https://www.jst-mfg.com/product/pdf/eng/eGH.pdf
J901 | COVER HALL SENSOR | JST BM03B-GHS-TBT(LF)(SN) | Connector_JST:JST_GH_BM03B-GHS-TBT_1x03-1MP_P1.25mm_Vertical | False | A02_RELEASE_CANDIDATE | External 3.3V open-drain Hall sensor; select magnet/threshold and serviceable mount. | https://www.jst-mfg.com/product/pdf/eng/eGH.pdf
R901 | 1k | RC0603FR-071KL | Resistor_SMD:R_0603_1608Metric | False | A02_RELEASE_CANDIDATE |  | https://www.yageogroup.com/component-documentation/download/specsheet/RC0603FR-071KL
R902 | 10k | RC0603FR-0710KL | Resistor_SMD:R_0603_1608Metric | False | A02_RELEASE_CANDIDATE |  | https://www.yageogroup.com/component-documentation/download/specsheet/RC0603FR-0710KL
C903 | 10n | Samsung Electro-Mechanics CL10B103KB8NNNC | Capacitor_SMD:C_0603_1608Metric | False | A02_RELEASE_CANDIDATE |  | https://weblib.samsungsem.com/mlcc/mlcc-ec-data-sheet.do?partNumber=CL10B103KB8NNN
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

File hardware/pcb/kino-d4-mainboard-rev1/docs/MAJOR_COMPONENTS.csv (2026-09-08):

Function | Manufacturer | Preferred_MPN | Package_or_family | Status | Rationale | Freeze_gate
USB_PD_sink | STMicroelectronics | STUSB4500QTR | QFN-24 | PROVISIONAL_SELECTED | Standalone dead-battery PD sink with NVM PDO profiles | NVM image and 5V/9V interoperability test
Battery_charger_power_path | Texas Instruments | BQ25798RQMR | VQFN-HR-29_4x4mm | PROVISIONAL_SELECTED | 1-4S buck-boost charger with NVDC BATFET TS input ADC and 5A class path | Final cell data thermal layout and autonomous defaults
Main_5V_boost | Texas Instruments | TPS61288LRQQR | VQFN-HR-11_2p5x3mm | PROVISIONAL_SELECTED | 15A switch class gives 5V 4A rail design margin | WEBENCH/datasheet component calculation and thermal test
Mainboard_3V3 | Texas Instruments | TPS62162DSGR | WSON-8_2x2mm | PROVISIONAL_SELECTED | Fixed 3.3V 1A efficient rail from SYS_5V | Logic load calculation and PCBWay assembly
Fuel_gauge | Texas Instruments | BQ27441DRZR-G1A | VSON-12_4x2p5mm | PROVISIONAL_SELECTED | 4.2V 1S system-side impedance-track gauge with 10mR shunt | Production cell chemistry and gauge learning cycle
Total_SYS5V_monitor | Texas Instruments | INA228AIDGSR | VSSOP-10 | PROVISIONAL_SELECTED | 20-bit bidirectional power energy and charge monitor | Address and 5mR Kelvin shunt review
Four_camera_monitors | Microchip Technology | PAC1954T-E/4MX | VQFN-16_3x3mm | PROVISIONAL_SELECTED | Four high-side channels with power accumulator | Address and 20mR Kelvin shunt review
Camera_load_switch_x4 | Texas Instruments | TPS2553DRVR | WSON-6_2x2mm | PROVISIONAL_SELECTED | Adjustable current limit reverse blocking and FAULT output | Measured inrush and ILIM resistor
Camera_enable_AND | Texas Instruments | SN74LVC08APWR | TSSOP-14 | PROVISIONAL_SELECTED | Combines GPIO31 global gate with four expander enables | Truth-table and reset-state review
GPIO_expander | Texas Instruments | TCA9539PWR | TSSOP-24 | PROVISIONAL_SELECTED | 16 I2C GPIO with RESET for enables faults and power-control status | Shared-bus address and firmware driver
SYNC_fanout | Texas Instruments | SN74LVC125APWRG3 | TSSOP-14 | PROVISIONAL_SELECTED | Four independently isolatable 3.3V buffers | Edge integrity and branch resistor test
Board_ID_EEPROM | Microchip Technology | 24AA025E48T-I/OT | SOT-23-6 | PROVISIONAL_SELECTED | 2Kbit EEPROM plus factory EUI-48 | Record format and write-protect plan
Power_button_controller | Analog Devices | LTC2955CTS8-1#TRMPBF | TSOT-23-8 | PROVISIONAL_SELECTED | Graceful firmware shutdown plus capacitor-set forced off | 1.8uF timer tolerance and 8-10s bench test
Side_power_switch | C&K | KT11B0SAM35LFG | Right_angle_SMT_6p3x6p3mm | PROVISIONAL_SELECTED | Side actuated IP57 3N and 100k-cycle class | Controlled mechanical drawing and enclosure opening
P4_mainboard_header | Molex | 5054482651 | Micro-Lock_Plus_1p25_dual_row_RA_26 | PROVISIONAL_SELECTED | Keyed latched 1.5A/contact 26-circuit compact header | Mating 5054322601 harness availability and continuity sample
P4_harness_housing | Molex | 5054322601 | Micro-Lock_Plus_1p25_dual_row_26 | PROVISIONAL_SELECTED | Positive-lock housing for motherboard end | Contact crimp and Guition 2x13 transition drawing
Battery_mainboard_header | Molex | 5055780341 | Micro-Lock_Plus_2p0_RA_3 | PROVISIONAL_SELECTED | Keyed positive-lock 3-circuit battery entry | Mating 5055700301 and final pack supplier approval
Battery_harness_housing | Molex | 5055700301 | Micro-Lock_Plus_2p0_3 | PROVISIONAL_SELECTED | Supports 22-26AWG family and locked polarity | Crimp/contact current and production harness qualification
Shutter_header | JST | SM02B-SRSS-TB(LF)(SN) | SH_1p0_side_entry_2 | PROVISIONAL_SELECTED | Compact polarized short signal harness | Mating SHR-02V-S-B and enclosure routing
Camera_connector_x4 | TBD | JST_GH_or_Molex_Micro-Lock_10pos | Locking_10_position | UNRESOLVED | Two 5V and two GND contacts plus UART sync reset boot | Placement wire gauge and node interposer review
USB_C_receptacle | TBD | GCT_USB4105-GF-A_or_equivalent | USB-C_24pin_mid_or_top_mount | UNRESOLVED | Common compact 3A family candidate | Enclosure datum durability and PCBWay sourcing
USB_CC_ESD | TBD | TBD | Two_line_low_capacitance_ESD | UNRESOLVED | Protect both CC pins without disturbing PD signalling | STUSB4500 reference design and surge review
USB_VBUS_TVS | TBD | TBD | At_least_12V_standoff_TVS | UNRESOLVED | Must survive normal 9V PD and clamp connector transients | Surge target and BQ25798/STUSB limits
Battery_reverse_and_protection | TBD | TBD | Bidirectional_low_loss_FET_solution | UNRESOLVED | Coordinate reverse connection OVP UVP OCP and pack PCM | Final production pack/PCM datasheet

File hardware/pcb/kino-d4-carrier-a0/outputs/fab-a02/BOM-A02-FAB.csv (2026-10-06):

Quantity | Comment | Designator | Footprint | Manufacturer Part | LCSC Part #
27 | 100n 50V | C100,C1106,C1110,C1116,C1119,C1205,C1300,C200,C201,C204,C300,C301,C304,C400,C401,C404,C500,C501,C504,C601,C602,C700,C800,C801,C802,C803,C905 | C_0603_1608Metric | YAGEO CC0603KRX7R9BB104 | C14663
1 | 1u 50V | C1000 | C_0805_2012Metric | Samsung Electro-Mechanics CL21B105KBFNNNE | C28323
5 | 1u | C1001,C1002,C701,C900,C901 | C_0603_1608Metric | Samsung Electro-Mechanics CL10A105KB8NNNC | C15849
1 | 1n 50V | C1100 | C_0603_1608Metric | Samsung Electro-Mechanics CL10B102KB8NNNC | C1588
1 | 4.7u 10V | C1101 | C_0805_2012Metric | Samsung Electro-Mechanics CL21A475KAQNNNE | C1779
2 | 47n 16V | C1102,C1103 | C_0603_1608Metric | Samsung Electro-Mechanics CL10B473KB8NNNC | C1622
12 | 10u 50V X7R | C1104,C1105,C1107,C1108,C1109,C1111,C1112,C1113,C1114,C1115,C1117,C1118 | C_1206_3216Metric | Samsung Electro-Mechanics CL31B106KBHNNNE | C89632
1 | 3.3n 50V | C1200 | C_0603_1608Metric | Samsung Electro-Mechanics CL10B332KB8NNNC | C1613
1 | 4.7u 16V | C1202 | C_0603_1608Metric | Samsung Electro-Mechanics CL10A475KO8NNNC | C19666
3 | 100n | C1203,C600,C904 | C_0603_1608Metric | YAGEO CC0603KRX7R9BB104 | C14663
7 | 22u 10V | C1204,C1206,C1207,C1208,C1209,C1210,C1211 | C_1206_3216Metric | Samsung Electro-Mechanics CL31A226KAHNNNE | C12891
2 | 10u | C1212,C902 | C_0805_2012Metric | Samsung Electro-Mechanics CL21A106KAYNNNE | C15850
1 | 22u | C1213 | C_0805_2012Metric | Samsung Electro-Mechanics CL21A226MAQNNNE | C45783
1 | 1.5u 16V | C1301 | C_0603_1608Metric | Samsung Electro-Mechanics CL10A155KO8NNNC
5 | 1u 50V | C202,C302,C402,C502,C703 | C_0603_1608Metric | Samsung Electro-Mechanics CL10A105KB8NNNC | C15849
4 | 22u 10V | C203,C303,C403,C503 | C_0805_2012Metric | Samsung Electro-Mechanics CL21A226MAQNNNE | C45783
1 | 470n | C702 | C_0603_1608Metric | Samsung Electro-Mechanics CL10B474KA8NNNC | C1623
1 | 10n | C903 | C_0603_1608Metric | Samsung Electro-Mechanics CL10B103KB8NNNC | C1589
1 | BZT52C10 | D1000 | D_SOD-123 | Diodes Incorporated BZT52C10-7-F | C155227
1 | SMF22A | D1001 | D_SOD-123F | Vishay General Semiconductor SMF22A-E3-08
2 | PESD24VL1BA | D1002,D1003 | D_SOD-323 | Nexperia PESD24VL1BA,115
5 | SS34 | D1200,D200,D300,D400,D500 | D_SMA | Diodes Incorporated B340A-13-F | C85098
1 | LED GREEN | D1300 | LED_0603_1608Metric | Wurth Elektronik 150060VS75000 | C6848499
4 | PESD5V0S1BA | D900,D901,D902,D903 | D_SOD-323 | Nexperia PESD5V0S1BA,115 | C19224
1 | PTC 100mA | F100 | Fuse_1206_3216Metric | Bel Fuse 0ZCJ0010FF2E | C194142
1 | 7A fast 1206 | F1100 | Fuse_1206_3216Metric | Bourns SF-1206F700-2 | C1972769
1 | P4 JP1 - 26 pin IDC | J100 | IDC-Header_2x13_P2.54mm_Vertical | Wurth Elektronik 61202621621 | C17586777
1 | USB4105-GF-A | J1000 | USB_C_GCT_USB4105_KINO_GND0.05 | GCT USB4105-GF-A | C3020560
1 | C6 service - 3V3 sense only | J101 | PinHeader_1x06_P2.54mm_Vertical | Wurth Elektronik 61300611121 | C5444523
1 | 3V3 I2C accessory | J102 | JST_GH_BM04B-GHS-TBT_1x04-1MP_P1.25mm_Vertical | JST BM04B-GHS-TBT(LF)(SN) | C161692
1 | PROTECTED 1S PACK / NTC | J1100 | JST_VH_B3P-VH_1x03_P3.96mm_Vertical | JST B3P-VH(LF)(SN) | C160316
1 | POWER PUSHBUTTON | J1300 | JST_GH_BM02B-GHS-TBT_1x02-1MP_P1.25mm_Vertical | JST BM02B-GHS-TBT(LF)(SN) | C161690
4 | GPIO breakout - SD/strap restrictions | J201,J301,J401,J501 | PinHeader_2x05_P2.54mm_Vertical | Wurth Elektronik 61301021121 | C5343117
1 | 3V PRIMARY RTC BACKUP | J800 | JST_GH_BM02B-GHS-TBT_1x02-1MP_P1.25mm_Vertical | JST BM02B-GHS-TBT(LF)(SN) | C161690
1 | HAPTIC MOTOR | J900 | JST_GH_BM02B-GHS-TBT_1x02-1MP_P1.25mm_Vertical | JST BM02B-GHS-TBT(LF)(SN) | C161690
1 | COVER HALL SENSOR | J901 | JST_GH_BM03B-GHS-TBT_1x03-1MP_P1.25mm_Vertical | JST BM03B-GHS-TBT(LF)(SN) | C161691
1 | LOCAL SHUTTER | J902 | JST_GH_BM02B-GHS-TBT_1x02-1MP_P1.25mm_Vertical | JST BM02B-GHS-TBT(LF)(SN) | C161690
1 | REMOTE DRY CONTACT | J903 | JST_GH_BM02B-GHS-TBT_1x02-1MP_P1.25mm_Vertical | JST BM02B-GHS-TBT(LF)(SN) | C161690
1 | FUNCTION BUTTON | J904 | JST_GH_BM02B-GHS-TBT_1x02-1MP_P1.25mm_Vertical | JST BM02B-GHS-TBT(LF)(SN) | C161690
1 | 0R LINK - REMOVE FOR P4 USB SERVICE | JP1200 | R_1206_3216Metric_Vishay_CRCW-HP | Vishay CRCW12060000Z0EAHP | C844862
4 | 0R LINK - REMOVE FOR NODE USB | JP200,JP300,JP400,JP500 | R_1206_3216Metric_Vishay_CRCW-HP | Vishay CRCW12060000Z0EAHP | C844862
1 | 1.0uH 14.1A Isat | L1100 | L_TDK_SPM6530 | SPM6530T-1R0M120
1 | 2.2uH 19.6A Isat | L1200 | L_Coilcraft_XAL7070-XXX | XAL7070-222MEC
1 | 2.2uH 1.5A | L1201 | L_Taiyo-Yuden_NR-30xx | Taiyo Yuden LSXND3030QKT2R2MNG | C6980123
4 | AO4409 | Q1000,Q1001,Q1200,Q1201 | SOIC-8_3.9x4.9mm_P1.27mm | Alpha & Omega Semiconductor AO4409 | C347462
1 | PMV16UN | Q1202 | SOT-23 | Nexperia PMV16UN
2 | 2N7002 | Q1300,Q900 | SOT-23 | Nexperia 2N7002,215 | C65189
2 | 2.2k | R100,R1303 | R_0603_1608Metric | RC0603FR-072K2L
19 | 100k | R1000,R1003,R104,R105,R1102,R1203,R1204,R1300,R1301,R205,R305,R405,R505,R601,R602,R603,R604,R900,R905 | R_0603_1608Metric | RC0603FR-07100KL
1 | 470 | R1001 | R_0603_1608Metric | RC0603FR-07470RL
2 | 1k | R1002,R901 | R_0603_1608Metric | RC0603FR-071KL
13 | 10k | R1004,R1302,R204,R304,R404,R504,R600,R701,R702,R800,R902,R903,R906 | R_0603_1608Metric | RC0603FR-0710KL
1 | 22k | R101 | R_0603_1608Metric | RC0603FR-0722KL
2 | 4.7k | R102,R103 | R_0603_1608Metric | RC0603FR-074K7L
1 | 3.00k 1% | R1100 | R_0603_1608Metric | RC0603FR-073KL
1 | 100 | R1101 | R_0603_1608Metric | RC0603FR-07100RL
2 | 30.1k 1% | R1104,R1107 | R_0603_1608Metric | RC0603FR-0730K1L
1 | 10k 1% | R1105 | R_0603_1608Metric | RC0603FR-0710KL
1 | 5.23k 1% | R1106 | R_0603_1608Metric | RC0603FR-075K23L
1 | 0 | R1108 | R_0603_1608Metric | RC0603JR-070RL
1 | 110k 0.1% | R1200 | R_0603_1608Metric | RT0603BRD07110KL
1 | 15k 0.1% | R1201 | R_0603_1608Metric | RT0603BRD0715KL
1 | 20.5k 1% | R1202 | R_0603_1608Metric | RC0603FR-0720K5L
12 | 33 | R200,R201,R202,R300,R301,R302,R400,R401,R402,R500,R501,R502 | R_0603_1608Metric | RC0603FR-0733RL
4 | 25.5k 1% | R203,R303,R403,R503 | R_0603_1608Metric | RC0603FR-0725K5L
1 | 47k | R904 | R_0603_1608Metric | RC0603FR-0747KL
4 | 0.020 1% 1W | RS200,RS300,RS400,RS500 | R_1206_3216Metric | Vishay Dale WSLP1206R0200FEA | C441558
1 | 0.005 1% 1W | RS700 | R_1206_3216Metric | Vishay Dale WSLP12065L000FEA
1 | TCA9517ADGKR | U100 | VSSOP-8_3x3mm_P0.65mm | TCA9517ADGKR
1 | STUSB4500QTR | U1000 | QFN-24-1EP_4x4mm_P0.5mm_EP2.7x2.7mm | STUSB4500QTR
1 | BQ25798RQMR | U1100 | Texas_RQM0029A_VQFN-29_4x4mm_P0.4mm | BQ25798RQMR
1 | TPS61288LRQQR | U1200 | TPS61288_RQQ0011A_DRAFT | TPS61288LRQQR
1 | TPS62162DSGR | U1201 | Texas_DSG0008A_WSON-8-1EP_2x2mm_P0.5mm_EP0.9x1.6mm_ThermalVias | TPS62162DSGR
1 | LTC2955ITS8-1 | U1300 | TSOT-23-8 | Analog Devices LTC2955ITS8-1#TRMPBF
4 | TXU0304PWR | U200,U300,U400,U500 | TSSOP-14_4.4x5mm_P0.65mm | TXU0304PWR
4 | TPS2553DBVR | U201,U301,U401,U501 | SOT-23-6 | TPS2553DBVR
1 | TCA9539PWR | U600 | TSSOP-24_4.4x7.8mm_P0.65mm | TCA9539PWR
1 | SN74LVC08APWR | U601 | TSSOP-14_4.4x5mm_P0.65mm | SN74LVC08APWR
1 | PAC1954T-E/4MX | U700 | VQFN-16-1EP_3x3mm_P0.5mm_EP1.1x1.1mm_Pin1Corner | PAC1954T-E/4MX
1 | BQ27441DRZR-G1A | U701 | Texas_S-PDSO-N12 | BQ27441DRZR-G1A
1 | LSM6DSOXTR | U800 | LGA-14_3x2.5mm_P0.5mm_LayoutBorder3x4y | LSM6DSOXTR
1 | RV-3028-C7 | U801 | MicroCrystal_C7_SON-8_1.5x3.2mm_P0.9mm | Micro Crystal RV-3028-C7 32.768kHz 1ppm TA QC | C3019759
1 | TMP117AIDRVR | U802 | WSON-6-1EP_2x2mm_P0.65mm_EP1x1.6mm | TMP117AIDRVR
1 | DRV2605LDGSR | U900 | TSSOP-10_3x3mm_P0.5mm | DRV2605LDGSR
1 | SN74LVC1G14DBVR | U901 | SOT-23-5 | SN74LVC1G14DBVR

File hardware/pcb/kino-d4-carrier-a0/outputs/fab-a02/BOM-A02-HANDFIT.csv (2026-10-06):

Quantity | Comment | Designator | Manufacturer Part | Fit
8 | XIAO ESP32-S3 Sense socket | J200,J300,J400,J500 | Wurth Elektronik 61300711821 | two 1x07 sockets per position, hand-soldered from the front after assembly

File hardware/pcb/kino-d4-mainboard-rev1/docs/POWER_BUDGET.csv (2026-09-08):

Category | Load_or_scenario | Voltage_V | Typical_current_A | Design_current_A | Typical_power_W | Design_power_W | Assumption_or_action | Status
Load | Guition_JC4880P443C-I-W | 5.0 | 0.320 | 1.000 | 1.600 | 5.000 | 1A is transient allocation not measured steady state | MEASURE_REQUIRED
Load | CAM1_XIAO_S3_plus_OV3660 | 5.0 | 0.140 | 0.350 | 0.700 | 1.750 | Branch supports 0.6A continuous and about 1A short fault limit | MEASURE_REQUIRED
Load | CAM2_XIAO_S3_plus_OV3660 | 5.0 | 0.140 | 0.350 | 0.700 | 1.750 | Branch supports 0.6A continuous and about 1A short fault limit | MEASURE_REQUIRED
Load | CAM3_XIAO_S3_plus_OV3660 | 5.0 | 0.140 | 0.350 | 0.700 | 1.750 | Branch supports 0.6A continuous and about 1A short fault limit | MEASURE_REQUIRED
Load | CAM4_XIAO_S3_plus_OV3660 | 5.0 | 0.140 | 0.350 | 0.700 | 1.750 | Branch supports 0.6A continuous and about 1A short fault limit | MEASURE_REQUIRED
Load | Mainboard_logic_and_monitors | 5.0 | 0.100 | 0.200 | 0.500 | 1.000 | Allowance excludes conversion loss | ESTIMATE
Total | Typical_system | 5.0 | 0.980 | 0.980 | 4.900 | 4.900 | Sum of typical allocations | ESTIMATE
Total | Simultaneous_capture_allocation | 5.0 | 2.600 | 2.600 | 13.000 | 13.000 | Guition transient plus four 350mA captures plus mainboard | ESTIMATE
Total | Conservative_continuous_design | 5.0 | 3.650 | 3.650 | 18.250 | 18.250 | 1A Guition plus four 0.6A branches plus 0.25A board | DESIGN_CAPACITY
Rail | SYS_5V_converter_capability | 5.0 | 0.000 | 4.000 | 0.000 | 20.000 | Silicon and copper target; not battery-harness continuous capability | DESIGN_TARGET
Source | USB_PD_preferred | 9.0 | 2.000 | 2.000 | 18.000 | 18.000 | About 16.2W after representative 90 percent whole-path efficiency | REQUIRED
Source | USB_C_fallback_max | 5.0 | 3.000 | 3.000 | 15.000 | 15.000 | Only after 3A advertisement or PD contract | REQUIRED
Charge | Cell_charge_target_at_4p2V | 4.2 | 1.000 | 1.500 | 4.200 | 6.300 | Reduce dynamically as system load rises | CELL_DATASHEET_BLOCKER
Battery | Battery_harness_continuous_nominal | 3.7 | 3.000 | 3.000 | 11.100 | 11.100 | About 10W SYS_5V after 90 percent boost efficiency | CONNECTOR_AND_CELL_BLOCKER
Battery | Battery_harness_short_pulse_nominal | 3.7 | 6.000 | 6.000 | 22.200 | 22.200 | Duration and temperature require cell/PCM/harness validation | CONNECTOR_AND_CELL_BLOCKER
Estimate | Typical_runtime_3Ah | 3.7 | 1.505 | 1.505 | 5.568 | 5.568 | About 1.8h using 90 percent usable energy and 88 percent conversion; values are battery-side input | ESTIMATE

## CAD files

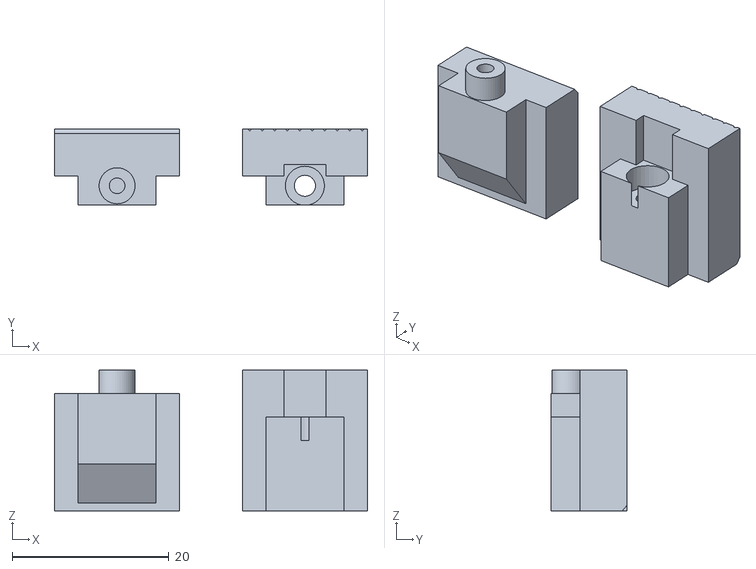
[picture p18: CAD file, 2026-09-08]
hardware/cad/KINO_FIELD_BODY/coupons/KINO_SPLIT_JOINT_COUPON.stl
40.0 x 9.70 x 18.0

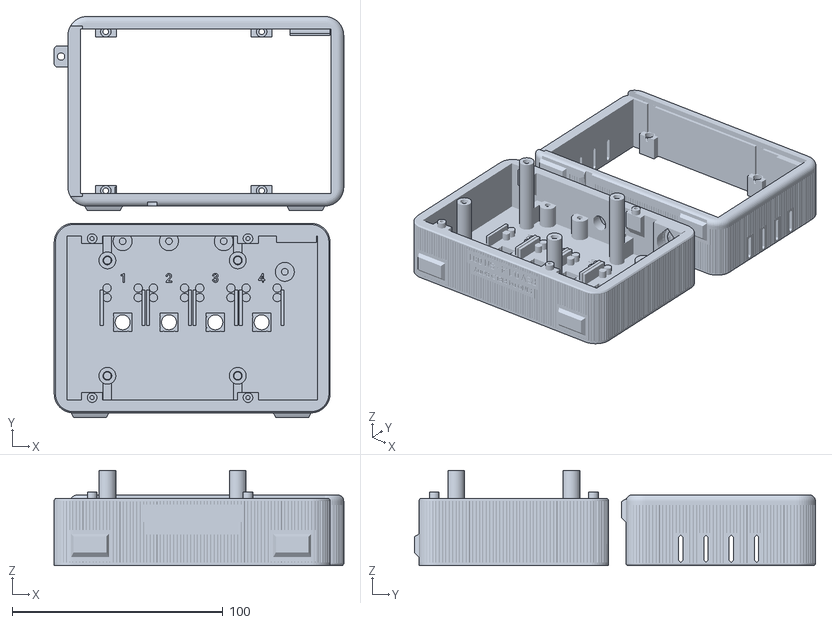
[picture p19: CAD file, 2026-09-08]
hardware/cad/KINO_FIELD_BODY/plates/KINO_PLATE_1_CHASSIS.stl
137.5 x 190.4 x 45.2

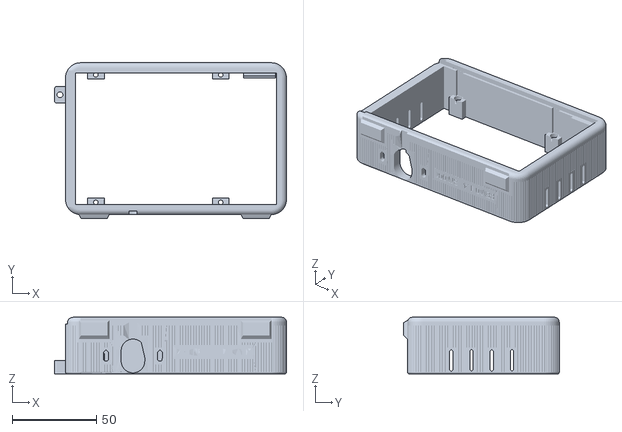
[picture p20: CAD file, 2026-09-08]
hardware/cad/KINO_FIELD_BODY/print/KINO_FIELD_BODY_REAR_PRINT.stl
137.5 x 92.2 x 33.6

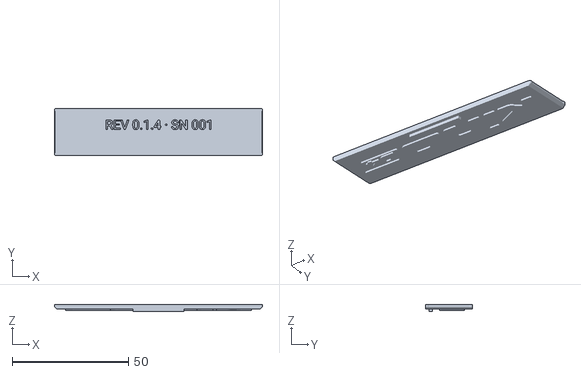
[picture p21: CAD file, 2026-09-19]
hardware/cad/KINO_FIELD_BODY/twin/KINO_TWIN_LENS_COVER.stl
89.4 x 20.4 x 3.00

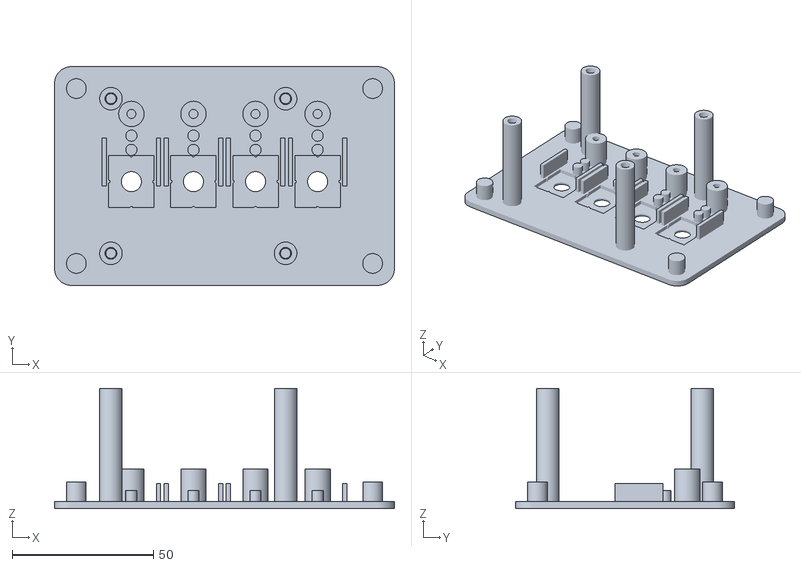
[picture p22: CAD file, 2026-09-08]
hardware/cad/KINO_RESIN_BODY/print/KINO_RESIN_SKELETON.stl
120.5 x 77.5 x 42.7

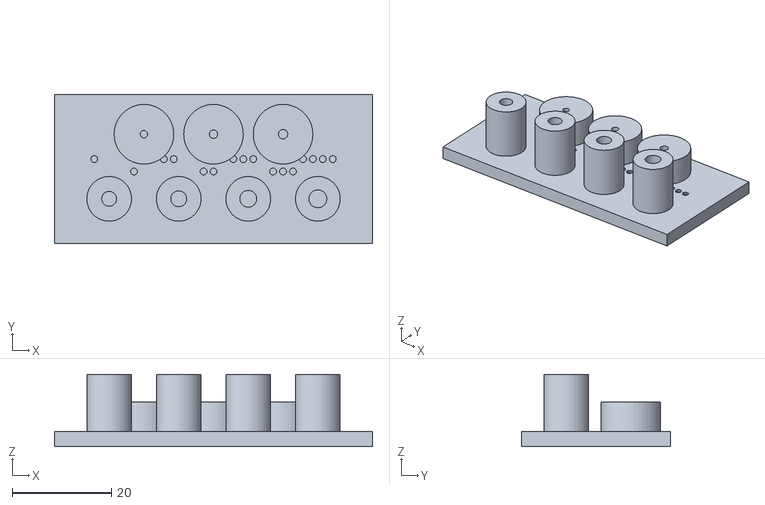
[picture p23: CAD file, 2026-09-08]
hardware/cad/KINO_FIELD_BODY/coupons/KINO_INSERT_PILOT_COUPON.stl
64.0 x 30.0 x 14.5

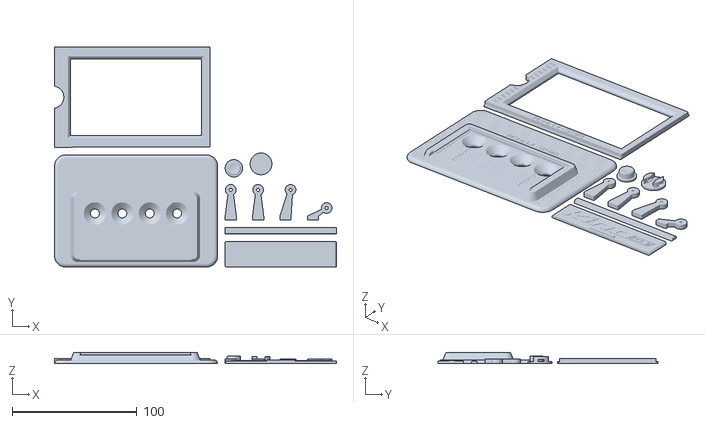
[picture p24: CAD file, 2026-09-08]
hardware/cad/KINO_FIELD_BODY/plates/KINO_PLATE_2_FACE_DOOR_COVER.stl
226.4 x 176.7 x 9.00

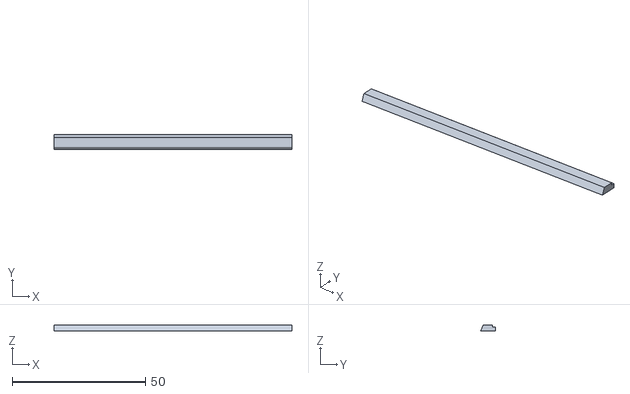
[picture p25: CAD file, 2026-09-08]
hardware/cad/KINO_FIELD_BODY/print/KINO_FIELD_SLIDER_KEEPER.stl
89.4 x 5.52 x 2.20

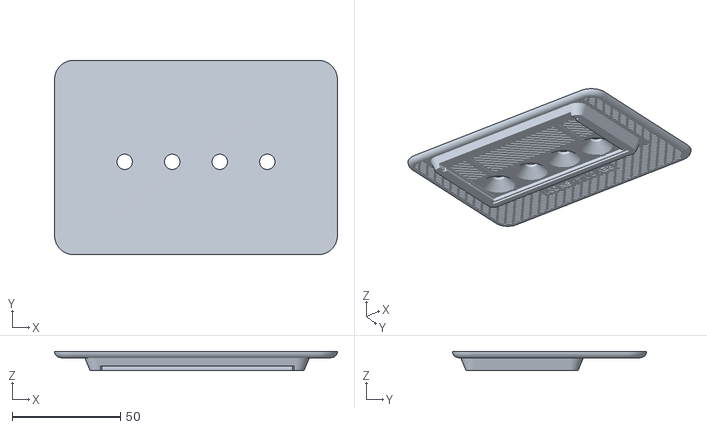
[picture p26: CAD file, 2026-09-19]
hardware/cad/KINO_FIELD_BODY/twin/KINO_TWIN_FACE.stl
131.0 x 90.0 x 9.00

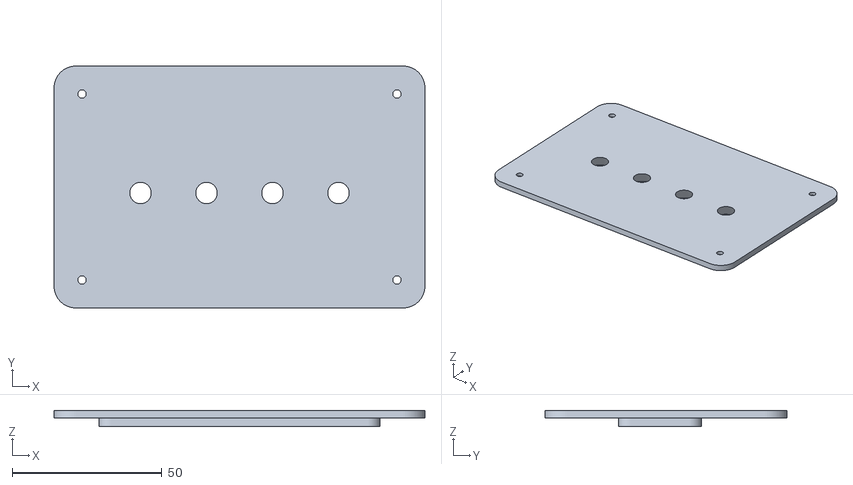
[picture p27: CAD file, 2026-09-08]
hardware/cad/KINO_RESIN_BODY/print/KINO_RESIN_FACE.stl
123.7 x 80.7 x 5.50

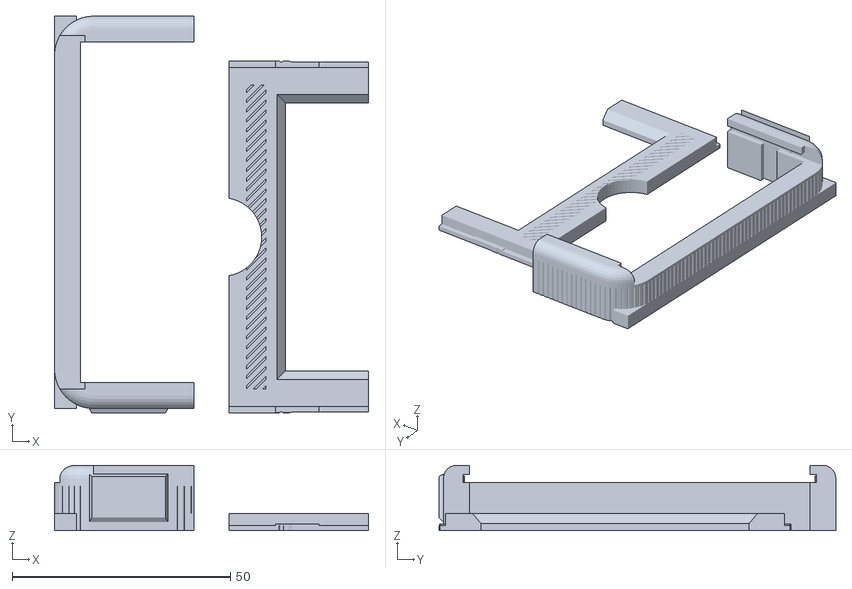
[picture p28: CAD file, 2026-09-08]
hardware/cad/KINO_FIELD_BODY/coupons/KINO_DOOR_JOINT_COUPON.stl
72.0 x 91.0 x 15.0

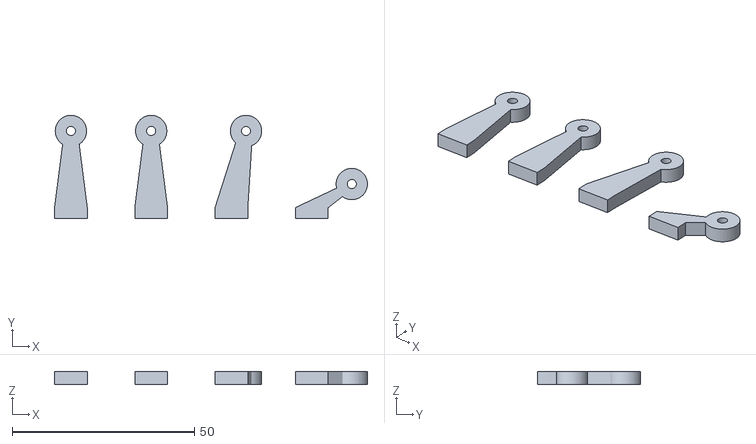
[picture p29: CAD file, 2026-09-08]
hardware/cad/KINO_FIELD_BODY/print/KINO_FIELD_XIAO_CLAMPS.stl
85.8 x 28.4 x 3.60

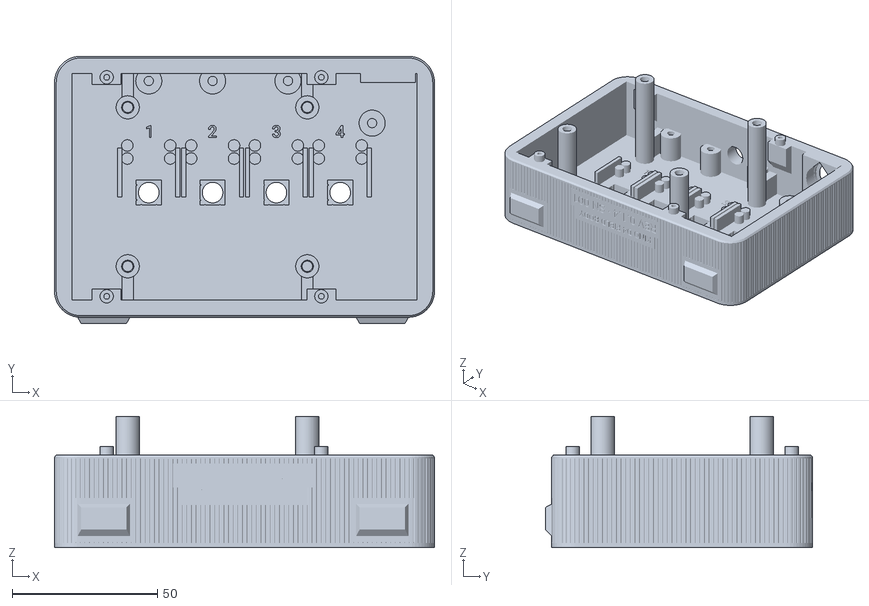
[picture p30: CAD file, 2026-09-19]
hardware/cad/KINO_FIELD_BODY/twin/KINO_TWIN_CHASSIS_FRONT.stl
131.0 x 92.2 x 45.2

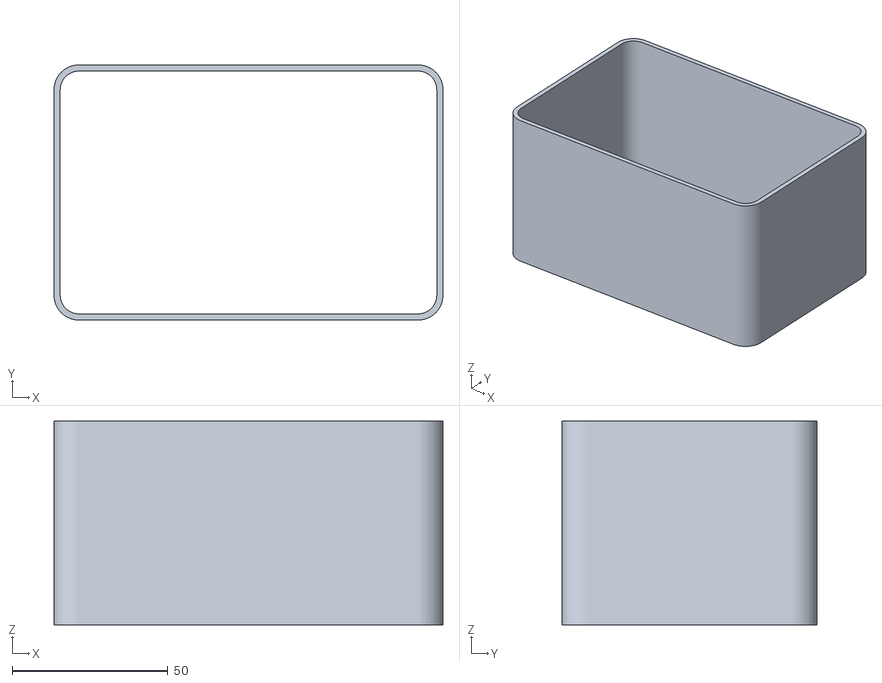
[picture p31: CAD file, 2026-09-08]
hardware/cad/KINO_RESIN_BODY/print/KINO_RESIN_SHELL.stl
125.0 x 82.0 x 65.5

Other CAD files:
hardware/cad/KINO_FIELD_BODY/coupons/KINO_WIGGLE_TEST_RIG.stl
hardware/cad/KINO_FIELD_BODY/print/KINO_FIELD_SHUTTER_BUTTON.stl
hardware/cad/KINO_FIELD_BODY/twin/KINO_TWIN_DOOR.stl
hardware/cad/KINO_FIELD_BODY/coupons/KINO_SHUTTER_COUPON.stl
hardware/cad/KINO_FIELD_BODY/coupons/KINO_CAM_FIT_COUPON.stl
hardware/cad/KINO_FIELD_BODY/coupons/KINO_FACE_ALIGN_TOOL.stl
hardware/cad/KINO_FIELD_BODY/coupons/KINO_P4_POST_SCREW_TEST.stl
hardware/cad/KINO_FIELD_BODY/coupons/KINO_SLIDER_TRACK_COUPON.stl
hardware/cad/KINO_FIELD_BODY/coupons/KINO_WIGGLE_RIG_SKELETAL.stl
hardware/cad/KINO_FIELD_BODY/coupons/KINO_XIAO_STACK_COUPON.stl
hardware/cad/KINO_FIELD_BODY/print/KINO_FIELD_BEZEL_PRINT.stl
hardware/cad/KINO_FIELD_BODY/print/KINO_FIELD_BODY_FRONT_PRINT.stl
hardware/cad/KINO_FIELD_BODY/print/KINO_FIELD_FACE_PRINT.stl
hardware/cad/KINO_FIELD_BODY/print/KINO_FIELD_LENS_SLIDER.stl
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

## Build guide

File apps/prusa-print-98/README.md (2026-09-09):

# KINO Print

A print host for an Original Prusa i3 MK3S, running locally on Windows. It exists because the bodies in this repository kept failing on the bed for reasons the slicer does not warn about.

Electron, React, Tailwind. The interface is Windows 98, scaled to be readable on a 4K monitor.

## Start

Double-click `KINO Print.cmd`, or run `release-final/KINO Print/KINO Print.exe`. The folder is self-contained and can be copied anywhere on this PC.

Open a `.gcode` and it reads the PrusaSlicer metadata out of the file. It finds the Prusa's serial port itself. Before anything heats up it asks a person to confirm the printer is physically clear. Then it streams the job at 115200 baud.

The print worker is a separate process. Close the window and the print carries on, and Windows stays awake until it finishes.

## The PETG detector

This is the part that earns the application. It looks for four things:

- a first layer hotter than it should be;
- probing done at full temperature;
- a printer profile that does not match the machine;
- a nozzle that starts heating before the bed wait.

The repair plan drops a hot PETG job to 230 °C. It holds the nozzle at 170 °C while the bed heats and mesh levelling runs, then raises it just before the prime line.

The source `.gcode` is never modified. Repairs go into the stream.

## Safety

- Keep the PC powered and the cable connected for the whole print.
- Watch the heating, the homing and the first layer.
- Stop sends heaters off, fans off, motors disabled.
- If the stream dies, the worker runs the same cooldown.
- Pause stops sending moves and deliberately leaves the heaters on, so the nozzle does not cool into the part.

The View menu offers 100%, 125% and 150%. The default is 125%.

Runtime state and logs sit in the Electron user-data folder for `KINO Print`.

## Development

```bash
corepack npm run dev   -w @kino/print
corepack npm test      -w @kino/print     # Python, not vitest
corepack npm run build -w @kino/print
corepack npm run dist:win -w @kino/print
```

The test suite is `unittest` over the gcode reader and the printer read-only check, so a machine without Python cannot run it — which also means a bare `npm test` at the repository root fails there.

The bundled W95FA typeface is Alina Sava's, under OFL-1.1. Its notice and licence travel with it in `public/fonts/`; see [`THIRD_PARTY_NOTICES.md`](../../THIRD_PARTY_NOTICES.md).

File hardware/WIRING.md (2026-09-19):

# D4 V1 wiring

This file defines logical connections and wire classes. Final ESP32-P4 GPIO numbers remain unassigned until hardware validation.

## Power path

```text
505573 LiPo positive
  → F3A fuse near the pouch
  → 1S protection board
  → SW6106 charger / boost module
  → 5 V main rail
      → ESP32-P4 display module
      → four switched camera channels
```

Battery return, power-module return, display ground, all camera grounds, and signal ground share the system ground. Route main power in 20 AWG silicone wire. Keep high current off thin perfboard traces.

The battery harness is rated at no more than 3 A sustained. A 10 A marking on the protection board does not raise that system limit.

## Camera harnesses

Each camera node has one detachable four-pin harness and one separate sync wire.

| Net | Direction | Gauge | Provisional color |
|---|---|---:|---|
| `CAMn_5V` | switched 5 V rail to XIAO | 24 AWG | red |
| `CAMn_GND` | system ground to XIAO | 24 AWG | black |
| `CAMn_TX` | P4 TX to XIAO RX | 28 AWG | blue |
| `CAMn_RX` | XIAO TX to P4 RX | 28 AWG | green |
| `CAMn_SYNC` | shared P4 sync output to XIAO sync input | 28 AWG | yellow |

The colors are the current harness convention, not an electrical property. Label both ends. Confirm connector orientation with continuity before plugging in a camera.

## Camera power switch

One high-side channel controls each camera:

```text
P4 CAM_PWR_n high
  → 4.7 kΩ base resistor
  → 2N3904 on
  → P-channel MOSFET gate pulled low
  → camera 5 V on
```

Each channel uses an AO4407 or AO4407A P-channel MOSFET, a 100 kΩ gate pull-up, a recommended 100 kΩ base-to-ground resistor, and a 1N5819 series Schottky diode. Confirm the adapter pinout against the exact MOSFET datasheet before soldering.

## GPIO map

| Function | P4 pin | Status |
|---|---|---|
| `CAM_PWR_1` | `GPIO_TBD` | bench validation required |
| `CAM_PWR_2` | `GPIO_TBD` | bench validation required |
| `CAM_PWR_3` | `GPIO_TBD` | bench validation required |
| `CAM_PWR_4` | `GPIO_TBD` | bench validation required |
| `CAM1_TX` / `CAM1_RX` | `GPIO_TBD` / `GPIO_TBD` | bench validation required |
| `CAM2_TX` / `CAM2_RX` | `GPIO_TBD` / `GPIO_TBD` | bench validation required |
| `CAM3_TX` / `CAM3_RX` | `GPIO_TBD` / `GPIO_TBD` | bench validation required |
| `CAM4_TX` / `CAM4_RX` | `GPIO_TBD` / `GPIO_TBD` | bench validation required |
| `SYNC_OUT` | `GPIO_TBD` | bench validation required |
| `FLASH_EN` | none in D4-V1 | external module, ECN-0003 |
| `CAM_PWR_EN` | `GPIO_TBD` | bench validation required |
| `BTN_SHUTTER` | `GPIO28` / JP1 21 | validated 2026-08-30 — `HWV_BTN_SHUTTER` earned on the first press, `firmware/HARDWARE_VALIDATION.md` |
| `BTN_FN` | `GPIO_TBD` | bench validation required |
| `SLIDE_MODE` | `GPIO_TBD` | unassigned. ECN-0006 proposed it as the guest lock and was withdrawn when the guest half of the interface was dropped; no firmware reads this signal. |

The `PROVISIONAL` candidate for each row lives in `packages/hardware-profiles/src/profiles/d4-v1.json` (`gpio`, with the JP1 pin for each signal) and `firmware/p4/main/board_d4v1.h`. A row here moves off `GPIO_TBD` only with bench evidence.

The P4's `JP1` header (26-pin, 2×13) exposes twelve P4 GPIOs, measured on the board (ECN-0002). Eleven carry signals: the four UART pairs take 8, `SYNC_OUT` takes `GPIO32` on pin 19, `CAM_PWR_EN` takes `GPIO31` on pin 10, and `BTN_SHUTTER` takes `GPIO28` on pin 21 (ECN-0003). `GPIO35` on pin 15 is the twelfth and stays unconnected: it is the serial-bootloader strap. `BTN_FN`, `SLIDE_MODE` and the four `CAM_PWR_n` lines have no header pin on this carrier; their route is an open M2 question, the standing candidate being an I²C GPIO expander on pins 23/25.

`BTN_SHUTTER` is wired as a 6 × 6 × 4.3 mm tactile switch between JP1 pin 21 and GND on JP1 pin 6 or pin 16. No external pull-up and no debounce capacitor: the P4's internal pull-up holds the pin high, the input is active low, and firmware debounces 25 ms. `HWV_BTN_SHUTTER` was earned on the first debounced press on 2026-08-30 (unit `KD4-D121BC`, firmware 0.4.7), and that press took a photograph; with a meter against pin 6 the pin reads 3.3 V idle and 0 V held.

Locking this table requires a pin-capability review, continuity check, single-camera bring-up, and a four-camera load test. Update firmware, the twin profile, and this file in the same change.

## Display ribbon

The main module uses a 26-pin, 2×13, 2.54 mm female-to-female IDC ribbon about 100 mm long. Mark pin 1 at both ends. Keep the red stripe visible after assembly. Do not fold the ribbon hard against the connector body.

## Flash

D4-V1 has no built-in flash. The constant-current direct-flash assembly was dropped in design package 0.1.3 (ECN-0003) when its enable pin, `GPIO28` on JP1 21, went to the shutter button. The P4 controls no flash enable line in this revision.

A separate external flash module is intended instead. Its part, drive current, and control interface are not chosen, so nothing here specifies how it connects. Do not wire a flash enable to JP1 pin 21; that pin is an input with a pull-up on it now.

## Before power

1. Disconnect the battery and USB.
2. Check every rail for a short to ground.
3. Confirm battery, diode, capacitor, and MOSFET polarity.
4. Confirm connector pin 1 and UART direction.
5. Power the unloaded rail from a current-limited bench supply.
6. Add the display, then one camera, then the remaining cameras.

Record the final continuity map and GPIO assignments with the build. A photograph alone is not a wiring record.

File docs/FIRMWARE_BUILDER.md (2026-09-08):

# Firmware builder

How Studio builds the real firmware (issue #72). One canonical environment,
no second build system.

## Pieces

| Piece | Path | Role |
|---|---|---|
| Build daemon | `scripts/firmware-daemon.mjs` | Localhost HTTP service (127.0.0.1:5177) wrapping `docker run espressif/idf:v5.5.1 idf.py build` on `firmware/p4` and `firmware/camnode` — the same pinned image CI uses (CI enters it via `export.sh`, the daemon via the image entrypoint) |
| Studio panel | `apps/studio/src/pages/Updates/FirmwareBuildPanel.tsx` | FIRMWARE BUILDER on the Updates page (developer mode) |
| Daemon client | `apps/studio/src/firmware/daemonClient.ts` | Typed client + package assembly with SHA-256 re-verification |

## Running it

```bash
npm run firmware:daemon     # terminal 1 — requires Docker
npm run dev -w @kino/studio # terminal 2
```

Studio → Updates → FIRMWARE BUILDER (developer mode on). The panel probes the
daemon every 5 s and says plainly when it is offline.

## Build pipeline (per target)

1. `version check` — `node scripts/check-versions.mjs`. **Drift refuses the
   build** (`VERSION_DRIFT`); the only way past is the explicit
   skip-checks override, and the artifact then carries `checksRun: false`
   which the panel prints as `CHECKS SKIPPED`.
2. `kdp host tests` — the framing and protocol contract suite
   (`firmware/components/kdp_core/host_tests/test_kdp.c`) under plain gcc. The
   check count is not quoted here on purpose; it grows with the suite and the
   runner prints it.
3. `idf.py build (espressif/idf:v5.5.1)` — real output streamed to the panel:
   status, per-step elapsed time, warning/error counts, binary size,
   partition usage line, artifact path.
4. `artifact + manifest` — SHA-256 of the binary, and a real
   `kino.firmware-manifest` (channel `dev`, versions from `firmware/VERSION`
   and `versions.json`, never invented) with provenance passthrough fields:
   `espIdfVersion`, `chip`, `sizeBytes`, `partitionUsage`, `gitCommit`,
   `gitDirty`, `builtAt`, `checksRun`. Written next to the binary as
   `kino-<target>-manifest.json`.

One build at a time; a second POST answers 409.

## Artifact library

The daemon serves the latest built artifact + manifest per target
(`/api/artifact/<target>/bin|manifest`); the manifests on disk under
`firmware/<target>/build/` are the local library. `GET /api/builds` lists the
session's build history with manifests.

## Flash

**KINO Twin** — LOAD BUILT PACKAGE assembles both targets (releases must
match; images re-hashed against their manifests) into the standard update
package; the existing UPDATE panel then flashes it over KDP
`FW_BEGIN/CHUNK/END` with device-side SHA-256 verification, reboot, and
health check. Installing a `0.1.0` P4 image switches the Twin to the honest
current-firmware profile (`TWIN_FIRMWARE_MODEL.md`).

**Physical hardware** — BLOCKED_BY_HARDWARE for the in-Studio path: M1B
firmware has no `FW_*` surface (OTA is milestone 7), and this machine has no
host esptool. Direct development flashing stays `idf.py -p <port> flash`
per `firmware/README.md`. When OTA lands, the same package flows through the
same updater.

## Failure behavior (brief §39)

Compiler errors → `BUILD_FAILED` with the real log. Version drift →
`VERSION_DRIFT`, refused. Failing host tests → `HOST_TESTS_FAILED`, refused.
Corrupt/mismatched image → the loader's SHA-256 check or the device's
`SHA256_MISMATCH` NACK. Wrong hardware → `checkCompatibility` blocks the
UPDATE panel. Nothing shows "Done" without the underlying operation.

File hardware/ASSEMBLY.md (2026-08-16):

# D4 V1 assembly

This is the intended build order for a bench prototype. Stop at each checkpoint. A later stage assumes the earlier measurement was recorded.

## Tools

- current-limited bench supply;
- digital multimeter;
- oscilloscope or logic analyser for UART and sync work;
- temperature probe or thermal camera for the flash and power path;
- calipers;
- soldering and rework tools suited to the carrier;
- eye protection and a non-flammable LiPo work surface.

## 1. Record the loose parts

Check every line in [`BOM.csv`](BOM.csv). Photograph both sides of each board beside a scale. Record exact markings, connector orientation, and measured dimensions. Seller photos do not settle the part you received.

Reject a swollen, punctured, hot, or damaged LiPo. Keep its leads insulated while working.

**Checkpoint:** the component manifest identifies the actual parts on the bench and every unresolved dimension remains marked unresolved.

## 2. Dry-fit the mechanical stack

Arrange the display module, battery, power board, carrier, speaker, flash thermal stack, and camera bar without wiring them. Check USB-C access, microSD access, ribbon bend radius, battery lead exit, and service access to connectors.

The acrylic panels are skins and windows. The PETG skeleton carries the camera bar and fasteners.

**Checkpoint:** no board or pouch is forced into the provisional 126 × 80 × 36 mm envelope.

## 3. Build the protected power path

Install the F3A fuse near battery positive, then the 1S protection board and SW6106 module. Use 20 AWG silicone wire for the main path. Keep exposed battery conductors short and insulated.

Leave the display, cameras, and flash disconnected. Power from a current-limited bench supply first. Verify polarity and the unloaded 5 V rail.

**Checkpoint:** record input voltage, rail voltage, idle current, and protection behavior.

## 4. Bring up the main controller

Connect the display module and its ribbon with pin 1 visible. Keep both USB-C ports and the microSD slot accessible. Confirm stable boot, touch input, storage detection, and USB communication before adding camera loads.

**Checkpoint:** Studio can connect, identify the main unit, and read power and storage status without resets.

## 5. Build one camera channel

Assemble one high-side switch and one PH2.0 camera harness. Check MOSFET orientation, NPN pinout, diode direction, pull resistors, UART crossover, and connector polarity.

Fit one XIAO ESP32-S3 Sense to the rigid camera bar. Power-cycle it through the P4-controlled channel. Establish UART communication before adding shared sync.

**Checkpoint:** CAM1 can power on, identify its sensor, answer repeated requests, capture one frame, and power off cleanly.

## 6. Replicate the camera channel

Build CAM2 through CAM4 from the proven channel. Label every harness at both ends. Mount the lenses at the current 22 mm default pitch, keeping the bar adjustable from 20 to 24 mm until the optical setup is measured.

Bring up each camera alone, then all four together. Record rail sag and boot behavior.

**Checkpoint:** all four cameras remain addressable during repeated status reads and parallel transfers.

## 7. Add shared sync

Route one 28 AWG sync branch to each camera node. Keep this line separate from the four-pin UART and power harnesses. Verify the edge at every node with a scope or logic analyser.

Run the sync bench. Record GPIO distribution, VSYNC phase, and effective exposure separately. A tight GPIO result does not pass exposure alignment.

**Checkpoint:** at least 250 triggers complete with the three timing fields reported or explicitly unavailable with reasons.

## 8. Add controls, storage, and sound

Install the tactile switches, mode slide switch, speaker, and final microSD card. Exercise every control in Studio or firmware diagnostics. Format and destructive storage tests require an expendable card.

**Checkpoint:** the self-test and a complete capture-to-card cycle pass without loose connections or unexpected resets.

## 9. Add the flash last

Assemble the LED star, 0.5 mm thermal pad, 20 × 20 × 7 mm copper heatsink, diffuser, and constant-current driver. Set the driver to 350 mA before connecting the LED. Confirm the P4 only controls enable.

Begin with short pulses. Record rail sag, LED current, heatsink temperature, nearby plastic temperature, and recovery between flashes. Do not test 500 mA until the 350 mA record is stable.

**Checkpoint:** the flash test completes without rail collapse, thermal damage, banding claims, or resets.

## 10. Close the enclosure

Add strain relief, insulation, service loops, and labels. Confirm the fuse, battery connector, microSD card, and USB ports remain serviceable. Keep screws and sharp printed edges away from the LiPo pouch.

Run the final acceptance sheet in [`TESTING.md`](TESTING.md) after the enclosure is closed. Thermal and radio behavior can change after the open-bench test.

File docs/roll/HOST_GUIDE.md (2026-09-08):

# Running a party on KINO Roll

For the person throwing the party. Start to finish, in the order the evening happens.

This describes what the software does today. Where it does not do something, the sentence says so. Every behaviour below has been read back out of the code; the file names in brackets are where.

---

## 1. Before anyone arrives

Three things must be true. None of them can be fixed at the party.

**The camera is provisioned.** Connect the D4 to a computer with a data-capable USB-C cable and open KINO Studio. Studio registers the camera against the server and writes the device credential into the camera's NVS. The camera cannot register itself in the field: registration needs the server's provisioning token, and without it the server answers `401 PROVISIONING_TOKEN_REQUIRED`. Registration is first-write-wins per serial in production — a second attempt on the same serial gets `409 DEVICE_ALREADY_REGISTERED`, not a fresh token.

**Wi-Fi is saved on the camera.** The camera joins the network on its own at power-on. Save the network you will actually use at the venue, on the camera, before the day. A guest network with a captive portal will not work: the camera has no browser.

**The server is reachable from that network.** Open `https://<your host>/api/healthz` from a phone on the venue Wi-Fi. It must answer `200` with `db`, `redis` and `storage` all true. A `503` names which of the three is down.

Also check the camera's compiled API base matches the server you intend to use. `GET_CONFIG network.apiBase` in Studio shows it. A bench camera often still points at a development API.

---

## 2. Create the roll

Two ways, same result:

- **From the camera, through Studio.** `ROLL_CREATE` with a name. The camera becomes the host device for that roll.
- **From the web.** `POST /api/host/rolls` from the site.

Either way the answer contains four things: `rollId`, `slug`, `guestUrl`, `hostUrl` — and `hostToken`, once.

### The host link, and the one copy problem

The host link looks like:

```
https://<your host>/host#token=<hostToken>
```

The server stores only a SHA-256 hash of that token. **It cannot be shown to you again.** There is no "resend host link", no email, no account to recover it from. Nothing in the product can reissue it.

What the host link is the only key to:

- the dashboard for that roll;
- hiding, trashing and restoring captures;
- setting or clearing the PIN;
- closing the roll;
- exporting the photographs.

If you lose it, the roll keeps running and guests keep seeing photographs. You lose moderation and export for that roll, permanently, unless an operator with database access intervenes.

So, before you do anything else: copy it out of the browser and paste it somewhere that survives the evening. A note on your own phone, a password manager entry, a message to yourself. Not just the open browser tab.

The dashboard has a **copy host link** button for exactly this (`apps/roll-web/src/components/host/HostLink.tsx`).

There is also an optional **keep me signed in on this device** on the dashboard. Turning it on stores the token in that browser so a reload does not lock you out. It is a convenience on *that* device only; it is not a backup of the token, and it is not a way to get the token back if you never copied it.

---

## 3. Join the cameras

The camera that created the roll is already on it.

**A second camera joins by code.** In Studio, connected to that camera over USB-C, send `ROLL_JOIN` with the roll's six-character code. The camera's own screen has no join control — there is no keyboard on the body — so this is a USB-C step, not a party step. Join the second camera before the party.

Ten wrong codes in a row lock joining for that device (`429 JOIN_LOCKED`).

After a reboot a camera finds its rolls again by itself.

---

## 4. How guests get in

A roll code is **six characters** from `23456789ABCDEFGHJKMNPQRSTUVWXYZ`. There is no `0`, `O`, `1`, `I` or `L` in the alphabet, so a code read off a screen across a room cannot be mistyped into a different roll. Codes are case-insensitive on the way in; the site upper-cases what is typed.

Four routes in, all equivalent:

| Route | What the guest does |
|---|---|
| Camera screen | Scans the QR block on the D4's ROLL screen, under **SCAN TO JOIN**. If the join URL is too long to encode, the camera shows the six-character code large instead, with "Enter this code to join". |
| Printed card | Scans the QR on a card you printed from the dashboard (`apps/roll-web/src/components/host/QrCard.tsx`). |
| TV display | Scans from a screen showing `/r/<CODE>/display` — the display page, meant for a television or a projector, which also shows photographs as they land. |
| Typing | Goes to the site root and types the six characters into the roll-code box. |

The camera screen is the reliable one: it needs no printer, no television, and it is where guests already are.

---

## 5. Setting a PIN

A roll with no PIN is *unlisted*: anyone holding the code can see it. Setting a PIN makes it *pin* privacy — the code alone is no longer enough.

Set or change it from the dashboard.

**Changing the PIN logs every guest out.** This is deliberate and it is not configurable. The guest's session cookie is a fingerprint of the stored PIN hash, and setting a PIN always re-hashes with a fresh salt — even to the same PIN. So every guest currently browsing is bounced back to the PIN gate and must type the new PIN. If you change the PIN at 23:00, forty people have to be told the new one at 23:00.

Clearing the PIN does the same thing: sessions issued under the old hash stop working.

The PIN itself is never written to the audit log — only that it changed.

If the *code* leaked rather than the PIN, rotate the code instead (**regenerate guest link** on the dashboard). Every copy of the old code stops resolving the moment it lands, and any signed media URLs handed out under the old code stop working too. Both cameras and both kinds of link have to be re-shown to guests afterwards.

---

## 6. During the party

You have two screens telling you two different things. They are not redundant.

### The camera's ROLL screen — the truth about the camera

One word for the connection:

| Word | Meaning | What it rules out |
|---|---|---|
| **ONLINE** | Wi-Fi is up and the server answered the last request. | Nothing is wrong with the network path. |
| **OFFLINE** | The camera has no network. | Not a server problem. Wi-Fi, range, or the venue's router. |
| **KINO NOT ANSWERING** | Wi-Fi is up; the server did not answer. | Not the camera's Wi-Fi. The server, the tunnel, or the internet between them. |
| **UPLOAD PAUSED** | The queue has stopped itself. Credentials or roll association were refused. | Not transient. It will not fix itself; the camera says "Check the roll in Studio." |

Under the connection word, the card count as one big number, then at most three lines:

- **"N waiting to upload"** with **"Saved safely on camera"** — the photographs exist on the SD card. They are not lost. They are waiting for a way out.
- **"N waiting to upload"** with a progress bar and "Uploading now" — work is moving right now.
- **"COUNTING THE CARD"** — the camera is still reading the card after boot. It does not yet know how many are waiting. This lasts seconds. A zero seen during this is not a real zero.
- **"All uploaded"** with **"Last upload Ns ago"** (or `Nm`, `Nh`) — nothing is owed.

### The dashboard — the truth about the server

Capture counts, live guest count, the moderation list, and a camera panel showing each joined camera: when it was last heard from, and how much it still owes. A camera that has joined but never sent a heartbeat shows as never heard from rather than as zero pending — those are different facts and the panel keeps them different (`apps/roll-web/src/components/host/CameraPanel.tsx`).

### Which to trust for what

- **"Are the photographs safe?"** — the camera. Originals land on the SD card before anything else. "Saved safely on camera" means exactly that.
- **"Can guests see them?"** — the dashboard. A photograph on the card that has not uploaded does not exist for guests.
- **"Is the network broken?"** — the camera's connection word. It is the only place that distinguishes *no Wi-Fi* from *server not answering*.
- **"Is anybody actually looking?"** — the dashboard's guest count. If Redis is down it reports 0 guests rather than failing; `/api/healthz` is where that outage is visible.

If the two disagree about a count, the camera is ahead of the server, not the other way round. Uploads lag; they do not run backwards.

---

## 7. Moderation

Two different actions on the dashboard, and they are not the same:

**Hide.** The photograph stops appearing to guests. Nothing is deleted. Unhide puts it straight back. Use this for the ordinary case: someone's eyes shut, a bad frame, a photo the subject asked you to take down for now.

**Trash.** The photograph goes into the trash and stops appearing to guests. The bytes are *not* removed immediately: they survive a grace period of **7 days**, and the dashboard shows each trashed capture with the date its bytes will actually go. Within that window, **restore** brings the capture back intact. The control is on the dashboard and it calls `POST /api/host/captures/:captureId/restore` (`apps/api/src/routes/host-captures.ts`). A trashed photograph is recoverable for those 7 days — do not treat one as lost.

After the 7 days a purge job removes the objects. There is no undo past that point.

**Clear roll** trashes every capture not already trashed, in one action. It is the same 7-day grace, applied to everything at once.

---

## 8. Closing the roll

Set the roll to **closed** on the dashboard. What changes:

- The gallery stays readable. Guests keep their link and keep seeing the photographs.
- New uploads are refused with `409 ROLL_CLOSED`.
- An upload session already open when you closed the roll is allowed to finish — closing does not strand half-transferred bytes.

**Close it after the cameras have drained, not before.** A camera still holding captures for a closed roll gets `409` on every attempt, treats it as a transient fault, backs off up to 30 s, and after 12 attempts parks the job as failed. The photographs are still on the SD card and can be recovered, but they will not upload themselves to a closed roll. Watch for **"All uploaded"** on both cameras' ROLL screens first.

From closed you can reopen (back to live) or archive. **Archive is terminal** — an archived roll cannot be reopened.

---

## 9. Exporting

Export gives you one ZIP of the whole roll: every original frame of every capture.

**Size.** Ask the dashboard for the size estimate before you start. A 300-capture party is on the order of four gigabytes. The dashboard reads `GET /api/host/rolls/:rollId/export/estimate` (`apps/api/src/routes/host-export.ts`).

**It is prepared once.** Starting an export queues a background job. While that job is running, asking again joins the same job rather than starting a second one. When it finishes, the dashboard gives you a download.

**Re-exporting makes another copy.** Once an export has finished, a new export request is a new job and a new ZIP, built from the roll as it is *now* — so a photograph you trashed between the two exports is in the first ZIP and not the second. Each ZIP occupies storage on the server.

**Where it goes.** The dashboard hands you a download link. In production the bytes come back through the API rather than from an internal storage URL, so the link works from outside the server's network. The signed link is good for 24 hours; after that, ask the dashboard for the export again. Production runs `OBJECT_DELIVERY=proxy`, which is what routes the bytes through the API (`apps/api/src/routes/host-export.ts`, `apps/api/src/exports/exports.ts`).

Turning off guest downloads does not lock *you* out of your own export.

---

## 10. After the party

Say this plainly, because guests will ask.

**Nothing expires.** There is no retention policy in the product today. A roll does not close itself, does not archive itself, and does not delete itself. Photographs stay on the server until somebody removes them. "Somebody" is an operator with access to the deployment — it is not a scheduled job and it is not something a guest can trigger.

What *is* automatic is one thing only: a capture you put in the trash has its bytes purged 7 days later. Nothing else.

To have a roll's photographs removed:

1. Trash them yourself. **Clear roll** on the dashboard trashes every capture in one action. Seven days later the objects are purged. This is the only self-service path, and it needs the host link.
2. For anything beyond that — the roll row itself, an export ZIP, a roll whose host link was lost — ask the operator of the deployment. It is a manual action against the database and the object store. There is no request form and no automatic route.

Tell guests the honest version: the photographs stay up until the host clears them or the operator removes them, and the host link is what makes the first of those possible. That is why section 2 spends so long on not losing it.

---

## Related

- [Roll device contract](ROLL_DEVICE_CONTRACT.md) — what the camera does on the wire.
- [Troubleshooting](../TROUBLESHOOTING.md) — the "photos are not appearing" ladder.
- [Infrastructure](../../infra/README.md) — deployment, backups, restore.

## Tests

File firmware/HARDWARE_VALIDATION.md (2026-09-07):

# D4-V1 hardware validation record

The source of truth for what has actually been bench-proven on physical D4-V1
hardware. The firmware keeps a live per-unit registry of the same items
(`p4/main/hardware_validation.[ch]`, readable over KDP with
`GET_HW_VALIDATION`); this file is the human record across units and time.

Rules:

- `VALIDATED` means the operation ran on our physical board and was observed.
  A datasheet, a community field note, or a compiling `#define` is never
  validation.
- Firmware auto-marks only `UNVALIDATED → VALIDATED`, from real events. It
  never auto-marks `FAILED` — software cannot tell a wrong pin from an empty
  SD slot or an unplugged harness. A failure is diagnosed at the bench and
  recorded here with the measured replacement.
- Do not rewrite history. A failed assumption keeps its row, marked `FAILED`,
  with the replacement in a new row.

## Status — updated 2026-09-02, firmware 0.4.28

One D4 shutter produces a truthful, durable four-frame set: 20 of 20 grouped
captures complete 4/4 on the fixed image, every frame CRC-checked to the card,
unique per set, correctly named, with the partial-status invariant holding
("One shutter, four frames", below). A four-way transfer defect found there -
the largest frame abandoned to 1000 ms tail-loss retry stalls - is fixed in
e08fb47. Two things block a full four-camera transport GO: C6 reset now panics
the P4 (issue #162, a radio internal-DMA regression, not the capture path), and
the connected/upload/Roll sections need an operator re-provision after a
partition-table reflash wiped NVS. The 0.4.19 status paragraph follows.

All four camera nodes are wired and proven: each XIAO+OV3660 answers on its
own UART, captures a checksummed 1600x1200 frame to the card individually,
and all four stay visible together across 23 discovery sweeps with zero link
errors - the basic four-camera hardware proof ("Four nodes on four wires",
below). The grouped shutter (#132) and exposure quality (#156) remain open.

0.4.11-0.4.13 landed in one bench day. 0.4.11 gives the gallery a persisted
order index and DELETE ALL PHOTOS; its first session on the 527-capture card
found three interleaving defects no host test could reach, fixed in 0.4.12
("The quality flip", below, carries the session). The same session surfaced
the real defect behind a "glitched, horrid" photograph: a quality register
write landing mid-readout corrupts the bottom of the frame the sensor is
encoding at that moment - present since the sensor path went live at 0.4.9,
invisible until someone looked at the pixels. 0.4.13 fixes it on the node:
a photograph is served only from a frame armed after the last encoding
register change. Reproduced and verified end to end over KDP, no hands on
the unit. The P4 on the bench runs 0.4.12 (no P4 code changed in 0.4.13);
the CAM1 node runs 0.4.13.

## Status — updated 2026-08-30, firmware 0.4.9

0.4.9 makes the settings real: per-camera exposure, gain and look quality
reach the sensors over `NL_CMD_SENSOR` and META records what was applied,
including the `recipeIds` nothing had ever stamped ("The sensor obeys the
slot", below); previewQuality, hold-after-shot, the warning tone, favourites
on the body, `body.name` and the new DISPLAY rows all act. The custom
partition table (#143) is in the repository and both variants build against
it; it is deliberately on no unit yet, because flashing it erases NVS.

0.4.8 holds looks and custom sounds on the card and answers every recipe and
sound command Studio sends; proving it on the bench found and fixed the
reason no KDP reply over 4 KB had ever reached a host ("Looks and sounds on
the card", below).

0.4.7 is the first firmware with a physical shutter: GPIO28 on JP1 21, the
pin ECN-0003 took back from the flash, validated on the bench the same day
with two photographs taken by the button ("The shutter has a pin", below).
0.4.7 also takes the background node sweep off the shutter's lock: 200 idle
`CAMERA_CAPTURE` requests, 0 false BUSY, a genuine second capture still
refused ("Shutter availability", below).

0.4.4 is the first firmware whose photographs have reached a Roll on a real
backend: capture, thumbnail-first upload, byte-identical original, worker jobs
settled, one row per photograph - on the repository's own API over the LAN, not
the production host. The session is recorded below ("The first photographs reach
a Roll"). Two application defects were found and fixed on the way; both are
measured there. 0.4.5 added a bench-only C6 reset and with it the finding
that a C6 reset was not recovered without a P4 reboot; 0.4.6 recovers it -
five times in a row on the bench, and under a pending upload - and closes
the local Roll gate: **LOCAL ROLL E2E GO** ("The radio recovers from a C6
reset", below). The same day, 0.4.6 was measured against Gate F on the one
camera attached: capture timing and CRC unchanged within noise with the
radio idle, uploading, draining a backlog and recovering, every accepted
photograph byte-identical on the card, in the object store and in the
database - **GATE F GO for the connected single-camera path** ("Gate F -
photography wins", below), with the four-camera case, the radio-off
baseline and current draw still unmeasured. Two upload-queue defects that
parked good photographs were found and fixed on the way. The 0.4.0
paragraph that follows is history.

## Status — updated 2026-08-27, firmware 0.4.0

0.4.0 added the network, Roll and upload-queue surface. It earned **no rows**:
the ESP32-C6 has no recorded transport route from the P4, so nothing in it has
been exercised on hardware. The rows it owes are listed in
[`C6_HARDWARE_MAP.md`](C6_HARDWARE_MAP.md) so they exist before the bench run
rather than after it. The live bench session below is 0.3.0's and is unaffected.

**Nothing below was inferred from code.** A row moves on an observed event on a
physical unit, and the firmware auto-marks only `UNVALIDATED → VALIDATED`. The
registry grew from 23 to 41 items in 0.3.0 (CAM2–4, sync trigger, `FLASH_EN`,
shutter) so the four-camera bring-up has somewhere to record its answers; all
18 new rows are `UNVALIDATED` and will stay so until the harness exists.

### The one thing to read first

**No camera node has ever been connected to a P4.** Everything in the camera
column below is either standalone-module evidence or unvalidated. The entire
capture pipeline — four-camera coordination, CRC verification, card write,
thumbnails, gallery, `EVT_CAPTURE`, `MEDIA_READ` — is `CODE DONE` and has never
photographed anything.

### Firmware 0.2.0 / 0.3.0 evidence, recorded late

The 0.1.0 sections below were written at the time. The display and touch runs
were recorded only in commit messages and are transcribed here now; that gap
was itself a process failure, since this file is the declared source of truth
and it sat two minor versions behind the firmware.

| Subsystem | Evidence | Source | Status |
|---|---|---|---|
| ST7701S panel over MIPI-DSI | *"First light… five colour bands on the screen, confirmed on hardware"* — after three faults each hiding the next: PSRAM at 20 MHz (DPI underrun), 800 async draw calls, and a panel-specific init table | commit `b8dff7a` | **VALIDATED** |
| Backlight GPIO23 | Driven with the panel; plain GPIO, not LEDC | commit `b8dff7a` | **VALIDATED** |
| GT911 touch | *"GT911 touch and a first on-screen UI, both verified on hardware"* | commit `8b4ddf3` | **VALIDATED** |
| Shared I²C bus | Scan reported 0x14, 0x18, 0x5d; codec must be brought up before the touch poll or every transaction NACKs | commit `8b4ddf3` | **VALIDATED** |
| ES8311 codec + NS4150 amp | Answered at 0x18; amp enable GPIO11 drives a speaker. Shutter/tick levels chosen from measured output | 0.2.0 audio work | **VALIDATED** |
| MSM381 microphone | reg 0x44 `ADCDAT_SEL` = 5 is a digital DAC loopback, not the mic; a volume sweep produced bit-identical output. Analog front end unconfigured | 0.2.0 audio work | **FAILED — not usable** |
| `CAM_PWR_EN` GPIO31 | Pin driven both ways for the camera bank. Whether the AO4407 channels downstream follow it is still a scope job | 0.2.0 power work | ~~VALIDATED (pin only)~~ **VOID** — GPIO31 is not a JP1 header pin (silkscreen check, commit `944b68e`). Toggling it proved the GPIO cell works and nothing about the camera bank, which was never connected. `CAM_PWR_EN` is now `BOARD_GPIO_NONE`; registry row `CAM_PWR_EN_GPIO31`, UNVALIDATED |
| Config persistence | A setting survived a real power cycle over the live link | 0.2.0 | **VALIDATED** |
| UI on the panel | 8 screens render on hardware; boot dissolve measured at 26 frames in 452 ms (≈57 fps) via the PPA | 0.2.0/0.3.0 | **VALIDATED** |
| Icon expansion | 575 ms for six icons, streamed; icons ready at t=2984 ms against a boot dissolve at t=4974 | commit `5768d3c` | **VALIDATED** |

### First camera on the wire, 2026-08-28

A XIAO ESP32-S3 (MAC `68:EE:8F:47:0B:6C` — a different unit from the module in
the 0.1.0 section) with an OV3660, wired to CAM1 on the measured header:
GND on JP1 5, `CAM1_TX` GPIO52 on JP1 7 to the node's D7, `CAM1_RX` GPIO51 on
JP1 9 from the node's D6. Both boards on their own USB; ground shared through
the single GND wire. `SYNC_OUT`, `FLASH_EN` and `CAM_PWR_EN` unwired.

| Item | Evidence | Status |
|---|---|---|
| `CAM1_TX_GPIO52` / `CAM1_RX_GPIO51` (JP1 7/9) | First traffic on the link: `rxBytes` 285, `crcErrors` 0, `decoderResyncs` 0, `connected: true`. The pins the per-pin scan measured are the pins a node answers on | **VALIDATED** |
| `CAM1_BAUD_921600` | The whole session ran at 921600 with 0 CRC errors and 0 resyncs | **VALIDATED** |
| `CAM1_NODE_LINK` | The P4 read the node's own session, firmware 0.4.1, reset reason, heap 8076 KB, PSRAM 7808 KB and chip revision across the UART | **VALIDATED** |
| `CAM1_SENSOR_DETECT` | `sensorPid 0x3660`, `sensor: OV3660`, `state: ready`, reported through the P4 rather than from the node's own console | **VALIDATED** |
| `CAM1_CAPTURE` | `CAMERA_TEST` repeatedly returns a frame; UXGA at quality 95 measured 108,567 B | **VALIDATED** |
| `CAM1_JPEG_TRANSFER` | Node CRC == transfer CRC on every completed capture, 5/5 in a controlled run | **VALIDATED** |
| `CAM1_SD_WRITE` | Stored-file CRC read back off the card == node CRC, 5/5. `MEDIA_READ` then reassembled 49,740 B host-side, SOI/EOI intact, and the image opened as a correct coherent scene | **VALIDATED** |

Node standalone before wiring: `Detected OV3660 camera`, SCCB `0x3c`, 8 MB
octal PSRAM at 80 MHz with `SPI SRAM memory test OK`, and the driver's own PLL
report — `VCO 128 MHz, PLLCLK 128 MHz, SYSCLK 32 MHz, PCLK 8 MHz` — which is
the arithmetic the Phase 1 audit derived from source and the driver's own
"40MHz SYSCLK / 10MHz PCLK" comment contradicts. The silicon agrees with the
audit.

### THUMB.JPG is written, 2026-08-29

`thumb_write` had never once succeeded in this project. It does now, at both
capture sizes, and `MEDIA_THUMB` reads the file back off the card in ~13.7 ms.

**Why it never worked.** `ppa_do_scale_rotate_mirror` checks the destination
against the cache line and rejects both a misaligned pointer and a size that
is not a multiple of it:

    ((uint32_t)out.buffer & 63) == 0 && (out.buffer_size & 63) == 0

The scale target came from `jpeg_alloc_encoder_mem(..., JPEG_ENC_ALLOC_INPUT_BUFFER)`,
and IDF's input branch is a plain `heap_caps_calloc` - no alignment, no
rounding, because the encoder only ever READS that buffer. The PPA writes it.
A PSRAM block lands on 64 about one time in sixteen, so the call returned
`ESP_ERR_INVALID_ARG` almost always. `thumb_load` had worked all along because
its destination is a gallery tile allocated with `heap_caps_aligned_calloc(64,
...)` and sized by `THUMB_TILE_BYTES`.

This is the third time PPA alignment has cost this project a bug. The rule is
now in one place: `ensure_ppa_dst()`.

**The second fault, behind the first.** With the scale fixed, the encoder step
ran for the first time. It is configured `JPEG_DOWN_SAMPLING_YUV420`, whose MCU
is 16x16, and IDF neither validates nor pads the dimensions. 2048x1536 reduces
to 256x192 and is whole; 1600x1200 reduces to 300x225 and is whole in neither
axis.

Trimming the output to a multiple of 16 alone does not work, and the bench said
so: 2048x1536 wrote and 1600x1200 did not. The PPA also checks the SCALED
source block against the destination picture - `(uint32_t)(scale_x *
in.block_w) <= out.pic_w` - and a full 1600-wide block at 3/16 still scales to
300, which no longer fits the 288 the rounding left. The source block is now
cropped to match the trimmed output, satisfying both rules.

| Capture size | reduction | thumbnail |
|---|---|---|
| 2048x1536 | 2/16 -> 256x192 | **written, readable** |
| 1600x1200 | 3/16 -> 300x225, trimmed to 288x224 | **written, readable** |

A `MEDIA_THUMB` immediately after a capture can time out; the device is
finishing its gallery refresh. Re-read a moment later and it is 13.5-13.8 ms.

### Capture works: the compositor was blacking out the link ISR, 2026-08-29

The product capture path is **VALIDATED**. It had never completed reliably.

| Configuration | Result |
|---|---|
| `CAMERA_CAPTURE`, 1600x1200 | **5/5**, 1.7-2.5 s, zero retries |
| `CAMERA_CAPTURE`, 2048x1536 (sensor native) | **6/6**, 2.5-3.5 s, zero retries |
| `CAMERA_TEST`, 1600x1200 (control) | 12/12, zero read timeouts |

**The fault.** A capture lost 14-73 bytes out of nearly every chunk, with zero
CRC errors, while `CAMERA_TEST` moved the same frame over the same wire
perfectly. The arithmetic identified it: past a 128-byte FIFO at 921600 baud,
losing that many bytes means interrupts were off for **1.5-2.2 ms**. Far too
short for a flash erase, which would have cost thousands of bytes, and exactly
the length of a cache writeback.

`capture_fire` sets `s_stage`; `run_capture` never does. `ui_task` treats a
non-idle capture stage as busy and repaints and presents every 60-90 ms for the
whole transfer, where `CAMERA_TEST` leaves it idle presenting nothing.
`gfx_present` does a blocking PPA rotate and a DPI handoff across two 768 KB
PSRAM framebuffers, and the cache maintenance under it runs in a critical
section - interrupts off on the running core. Tasks were unpinned and
`camlink_init` runs from `app_main` on CPU0, so about half the presents landed
on the core owning the link interrupts. The retry landed in a different phase
on a different core and succeeded, which is why every chunk after the first
failed exactly once.

Pinning `ui_task` to CPU1 fixes it with no trade-off: preview and shutter both
run at full rate.

Two contributing faults were fixed with it. `cam_probe` greets cam0..cam3
serially at 3000 ms each holding the channel mutex, walks the same order
`capture_fire` does so the two could lockstep, and slipped HELLO frames -
each opening with `uart_flush_input` - between chunk reads; it now stands down
while a capture runs. And `camlink_get_info_ch` read a cached struct under that
same mutex with `portMAX_DELAY`, turning "which cameras are online" into a
multi-second wait on the shutter path.

### Tried and rejected, so it is not tried again

Everything below was measured, not reasoned about, and none of it is kept.
Several were measured while the compositor fault was still present, which is
the honest reason they looked inconclusive at the time.

| Change | Result |
|---|---|
| `CONFIG_UART_ISR_IN_IRAM=y` | **Made it worse.** 0/5 with, 12/12 without. The stated reason in `sdkconfig.defaults` was later shown wrong; the measurement stands, the explanation does not |
| UART driver event queue | Added to name the overrun, which it did; more ISR work is the wrong direction and it is removed |
| Capture workers at priority 8 instead of 5 | No change. Task starvation cannot lose bytes - the RX ring is 33 KB, about 360 ms of wire. Only an ISR blackout can |
| `NL_CHUNK_MAX` 8192 -> 2048 | Worse: overruns track request turnarounds, not bytes. 4 overruns became 30 |
| `NL_DEFAULT_BAUD` 921600 -> 460800 | Fewer overruns, not zero, and doubles every transfer |
| `LINK_RX_BUF` 33 KB -> 66 KB | No change. This is what ruled out the reader being outrun |
| Node `fb_count` 2 -> 1 | No change to the link; brings back the preview beat |
| Drain-to-silence after a timeout | Markedly worse; written for a cascade the measurements contradicted |
| `CHUNK_READ_TIMEOUT_MS` 800 | Captures failed. Sized against a link that was already broken |

Budgets after the fix, sized for the wire rather than the fault: chunk timeout
1000 ms (eleven times a chunk's 89 ms), 2 retries, 8000 ms per frame.

### Capture at 2048x1536, and the UART overrun that limits it, 2026-08-29

One camera on CAM1, stills at the sensor's native 2048x1536 - the largest size
the OV3660 produces without interpolation, so the largest that does not cost
image quality. Frames measured 91-170 KB.

The product capture path completes where it previously never did: **2 of 5**,
about 20 s each, carried over lost chunks by retries. The remaining failures
are all one fault.

| Configuration tried | Overruns per capture | Result |
|---|---|---|
| 8 KB chunks, 921600, 4000 ms | 4-5 (good runs), ~30 (bad) | **2/5 pass** — kept |
| 8 KB chunks, 921600, 800 ms | same | 0/4 — budget too short for a retry to be worth taking |
| 2 KB chunks, 460800 | ~30 | 1/4 — four times the requests, four times the overruns |
| 8 KB chunks, 460800 | 1-4 | 0/4 — fewer overruns, still fatal |
| RX ring 33 KB -> 66 KB | unchanged | no effect |

**The fault.** `UART_FIFO_OVF` on the P4's link UART. The RX FIFO is 128 bytes,
which at 921600 baud is 1.39 ms of tolerance, and the ESP-IDF driver resets the
FIFO when it overflows - so the entire frame in flight is lost, not corrupted.
A whole 8210-byte chunk dies to one momentary window. The link carried 452 KB
with **zero CRC errors** across the same session, so this is not signal
integrity and not the cable.

Two measurements pin down what it is not:

- Doubling the driver's ring buffer changed nothing, which rules out the reader
  being outrun and leaves the ISR being held off.
- Overruns scale with the number of request/response turnarounds rather than
  with bytes carried: quartering the chunk size quadrupled the request count
  and took a capture from 4 overruns to 30.

`CONFIG_UART_ISR_IN_IRAM=y` is set and did help - it moved the first failure
from chunk 0 to chunk 1 - so a disabled flash cache was part of it but is not
the whole story. Roughly a fifth of chunk requests still lose bytes.

**Hardware flow control is not available.** It would end this outright, but JP1
has twelve free GPIOs and eleven are committed (eight CAM TX/RX, `SYNC_OUT`,
`FLASH_EN`, `CAM_PWR_EN`). The twelfth is GPIO35, a boot strapping pin that
must stay unconnected. There is no room for four RTS/CTS pairs, so the four-
camera rig should not be wired differently on account of this.

The remaining lead is UART DMA. The ESP32-P4 has UHCI, which moves UART RX into
a DMA descriptor chain and removes the per-byte ISR deadline that this fault is
made of. That is the fix worth trying next; everything above only manages the
symptom.

### No camera attached at all, 2026-08-28

The state every unit boots into on a bench, and the one most likely to be met
by someone who has not wired anything yet. P4 alone on COM8, no node on any
channel.

| Check | Result |
|---|---|
| `CAMERA_CAPTURE` with nothing attached | NACK `CAMERA_OFFLINE` "No camera answered" in **1.7 s**, plus a `LOG` event. Refused, not hung |
| Sanity sweep — `HELLO`, `GET_DEVICE_INFO`, `GET_CAPABILITIES`, `GET_STORAGE_STATUS`, `GET_RUNTIME_STATS`, `GET_HW_VALIDATION`, `GET_LOGS` | 7/7 OK, 1.1–9.3 ms each |
| Framing across the session | 8 frames, **0 CRC failures, 0 resyncs** |
| Task watchdog | None. `resetReason: power-on`, uptime 75 s, free heap 23408 KB |
| `taskmon` | 18 tasks, `tasksUnmeasured: 0` |
| Host clock | `clock set to 2026-08-28T22:02:46+02:00 by host (moved +88865 s)`, `t` a real epoch — the clock unification holding |

Four channels each cost `DEFAULT_TIMEOUT_MS` on the probe, serialised, so a
full probe round with nothing attached is about 12 s and repeats. It starves
nothing since the poll was fixed, but it is a lot of link time spent proving
absence, and it delays boot.

Note for the open `xfer` jitter question: the runtime reports **eight**
camera-related tasks, `cap1`–`cap4` in cam_link and `vf_cam1`–`vf_cam4` in the
viewfinder, not the four assumed when the priority-3 round-robin was proposed
as the cause. Whatever that contention is, there is twice as much of it.
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

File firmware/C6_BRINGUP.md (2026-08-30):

# ESP32-C6 bring-up

How to take the KINO D4's radio from "fitted but unreachable" to "uploading to
Roll", and what is already done.

Read [`C6_HARDWARE_MAP.md`](C6_HARDWARE_MAP.md) first. Step 1 below is a
hardware task and everything after it is blocked on it.

## Where this stands

| Stage | State |
|---|---|
| C6 slave image builds reproducibly | see [`c6/README.md`](c6/README.md) |
| P4 transport routing known | **BENCH DONE 2026-08-29** — slot 1 on GPIO14–19 enumerated the C6, three boots, two witnesses; GPIO54 confirmed as `CHIP_PU` on the meter (B2 PASS) — [`C6_HARDWARE_MAP.md`](C6_HARDWARE_MAP.md) |
| P4 transport driver | **BENCH DONE 2026-08-29** — `net_hosted.c`; it had been calling `esp_hosted_init()` without `esp_hosted_connect_to_slave()`, so enumeration was never attempted (`a2ab8ef`). Still a build-time opt-in, OFF by default |
| Version gate | **BENCH DONE 2026-08-29** — refused the factory 2.3.2 (`C6_BAD_FIRMWARE`, no reset loop), then **passed the rewritten 3.0.6**: `link ready, C6 3.0.6 against host 3.0.6`, `C6_SLAVE_VERSION` validated, state `WIFI_IDLE`. Compared the wrong constant at first (`ESP_HOSTED_VERSION_*_1` = 2.12.6); now uses `PROJECT_VERSION_*_1` like the component |
| Network state model | CODE DONE, host-tested (127 + 75 checks) |
| Wi-Fi scan / associate / DHCP | **BENCH DONE 2026-08-29** — six networks scanned, `BRCD` joined at -77 dBm, lease `10.20.80.181`, wrong passphrase refused with `AUTH_FAILED`, reconnect after reboot |
| SNTP as a clock source | **BENCH DONE 2026-08-29** — `clockSource network` on first association; the stale `CLOCK_UNTRUSTED` hold that would have blocked TLS is released on adoption (`172966f`) |
| Wi-Fi credential store | CODE DONE |
| `NETWORK_*` KDP commands | CODE DONE — answer honestly, refuse what needs a radio |
| `ROLL_*` KDP commands | **BENCH DONE 2026-08-29** — `ROLL_CREATE` registered the device and created roll `RRG8AZ` on the local backend; `ROLL_DEVICE_REGISTER` earned |
| Durable upload queue | **BENCH DONE 2026-08-30** — a capture reaches a Roll on the LAN backend: document 201, thumbnail first, original byte-identical, one row; survives the API going away (retry landed 13.5 s after it returned) and a P4 reboot with the upload pending (5.9 s, on 0.4.4 — 0.4.3 waited on the previous boot's clock, fixed `ec22ea3`). 34 stale records on the bench card retired, none relabelled. Capture wins the card over an upload. **C6-only reset: on 0.4.5 the link was never re-established (ROLL-C test 3 FAIL); 0.4.6 recovers it without a P4 reboot - `radio_recovery.c`, five consecutive recoveries in 9.8-21.8 s (one 122.9 s in the component's own deinit), and ROLL-C test 3 PASS with the same UUID uploaded once, byte-identical. LOCAL ROLL E2E GO** |
| Roll HTTP client | **BENCH DONE 2026-08-29** — against the production host: DNS, verified TLS, 404 (not deployed). Against the real backend on the LAN (`network.apiBase`, D18): health 200 with body, register 200, create roll 201. It had never read a response body until `90b8d74` |
| Radio variant in CI | CODE DONE — `p4-radio` job, its own 1440 KB guard |
| microSD on slot 0 (prerequisite) | **BENCH DONE 2026-08-28** — the slot move is proven on `KD4-D121BC`; see `HARDWARE_VALIDATION.md` |
| Any of it on hardware | **Transport and version gate, yes.** The coprocessor was rewritten to the pinned 3.0.6 from a verified 4 MB backup (`HARDWARE_VALIDATION.md`), boots cleanly, enumerates, and passes the gate. The link sits in `WIFI_IDLE` waiting for a network. Scan and association are next |

Every "BENCH DONE 2026-08-29" above is a session recorded in
[`HARDWARE_VALIDATION.md`](HARDWARE_VALIDATION.md), which owns the bench state
for this repository: transport, version gate, association, DHCP, SNTP, DNS, a
verified TLS session, and `ROLL_CREATE` against a real backend on the LAN. Every
"CODE DONE" means only that the code exists and compiles — nothing about it has
been observed on a board. Where a row here and `HARDWARE_VALIDATION.md` disagree,
that file wins and this one is stale.

## Bench baseline, 2026-08-28

The exact images for the next attempt. Built from a clean `git archive` of the
commit below plus the pinned `dependencies.lock`, never from a working tree,
and each built twice from scratch to prove the hash is a property of the source
rather than of the build directory.

| Image | Bytes | SHA-256 |
|---|---|---|
| `kino-p4.bin` default, no radio | 822 160 | `8d168da6edff9c049b2aebeb6bfda915bfc20885ee65475a379381562afbf624` |
| `kino-p4.bin` radio | 1 419 920 | `3b07e25e7de98933a0f7930bfe10f6c8c221ceb7f11c4148134f8249a095c49d` |
| `kino-c6.bin` slave | 1 105 872 | `3616fe6e6e6329f7443dce0f19232bb6aded9091801db874f150a18a1baaee61` |

All three are byte-identical across two clean builds. The C6 hash also matches
the one recorded before this session, so the slave image is stable across
environments and not merely repeatable inside one.

Baseline: HEAD `3a1073e`, `espressif/idf:v5.5.1`, `esp_hosted` 3.0.6
(`component_hash 1b1c2aa8…`), `esp_wifi_remote` 1.6.4
(`component_hash 50d3beaf…`). The lockfile now pins the resolved artifacts
by hash rather than only by version constraint, so a clean checkout fetches the
same bytes.

The radio image leaves 116 080 bytes (7.6%) of the 1 536 000-byte `factory`
partition. It fits; it will not fit two OTA slots, which is an M8 input and not
a bench blocker.

**The default image is the recovery baseline.** Keep it flashable: it boots,
mounts the card, runs KDP and answers `STORAGE_SELF_TEST` and `STORAGE_BENCH`
with the radio absent entirely, which is what makes it possible to tell a radio
fault from a board fault.

## Why the order is this order

The camera has to keep working throughout. Networking is additive: a dead
radio, a missing C6, or a failed handshake may cost uploads and must never
cost a photograph. So the transport comes up asynchronously, after the UI and
the capture pipeline are already usable, and every stage below fails into a
reported state rather than a retry loop or a reset.

## 1. Establish the routing — DONE, AND MEASURED

The mapping is in [`C6_HARDWARE_MAP.md`](C6_HARDWARE_MAP.md) with its evidence
chain: SDMMC slot 1 on `GPIO14`-`GPIO19`, `EN` on `GPIO54`, identified from
Guition documentation (E2) and corroborated pin-for-pin by Espressif's own
ESP-Hosted defaults for a P4 host with a C6 coprocessor (E3, E4), where min
equals max for every pin.

That was the paper argument. It has since been measured:
`HARDWARE_VALIDATION.md` records `C6_SDIO_PINS` and `C6_LINK_HANDSHAKE`
**VALIDATED 2026-08-29** — `sdmmc_card_init()` enumerated the C6 on slot 1 with
`rx_ready && tx_ready`, twice, witnessed from the C6's own console — and
`C6_EN_GPIO54` **VALIDATED 2026-08-29** on the meter.

What is still open, and it is what step 5 is for:

- `GPIO54`'s polarity on this carrier. ESP-Hosted defaults to active-low and
  carries an explicit active-high override because boards with a
  transistor-buffered `EN` invert it. Ours is unmeasured.
- whether any P4 GPIO reaches `C6_U0RXD`, `C6_U0TXD`, `C6_IO9` (JP1 pins 20,
  22, 24). None of the eleven P4 GPIOs on JP1 is known to, so C6 flashing is
  an external-adapter operation.
- the C6 SDIO IO power rail, and whether it needs an LDO channel of its own.

Buzz the module out or get the schematic before the first bench run. The SD map
came from a community field note and was still re-measured on our own unit
before its rows moved.

## 2. Add the pin block — DONE

`firmware/p4/main/board_d4v1.h` carries `BOARD_C6_SLOT`, `BOARD_C6_D0`-`D3`,
`BOARD_C6_CLK`, `BOARD_C6_CMD`, `BOARD_C6_EN` and `BOARD_C6_EN_ACTIVE_LOW`.
Every P4 pin assignment lives in that file and nowhere else, which is what
makes a pin change reviewable — `net_hosted.c` hands them to ESP-Hosted at
runtime rather than duplicating them in `sdkconfig.radio`.

Two `_Static_assert`s in `net_hosted.c` hold the invariants a comment cannot:

- `BOARD_C6_SLOT != BOARD_SD_SLOT`. One SDMMC controller serves both slots, and
  a collision presents as a card that stops mounting when the radio comes up.
- `BOARD_C6_EN_ACTIVE_LOW` equals `CONFIG_ESP_HOSTED_SDIO_RESET_ACTIVE_LOW`.
  Two places name that polarity and the bench will flip it; flipping only one
  of them must not compile.

The registry rows exist. Thirteen were appended to `hwv_item_t` — appended, not
inserted, because the enum ordinal is the NVS key and shifting it would make a
unit flashed across the change read its old evidence against the wrong rows.
They are ordered the way this procedure runs, so a bench session that stops
halfway leaves an obvious high-water mark, and a `_Static_assert` keeps the
name table in step with the enum.

Only `SD_SLOT0` can flip in the default build — the other twelve need a radio
that no build links by default.

## 3. Flash the slave image

`firmware/c6/README.md` has the command. The C6's SDIO slave pins are fixed in
silicon (CLK `GPIO19`, CMD `GPIO18`, DAT0–3 `GPIO20`–`GPIO23`), so the slave
image needs nothing from step 1 — which is why it could be built first.

Flashing needs `C6_U0RXD`/`C6_U0TXD`/`C6_IO9`/`C6_CHIP_PU`. Whether the P4 can
drive them — the flashing proxy that would make this a one-cable operation —
depends on the same GPIO numbers step 1 produces. Until then it is an external
USB-serial adapter on the header.

## 3a. The coprocessor image, and the procedure that waits on a divider

Status 2026-08-29. The factory coprocessor was ESP-Hosted 2.3.2 against a
3.0.6 host; the transport worked and the version gate refused, so the
coprocessor had to be updated. **It has been.** `HARDWARE_VALIDATION.md`
records the write on `KD4-D121BC`: a verified full 4 MB factory backup read
twice to the same SHA-256, then the four images written and esptool-verified,
then an independent read-back of 0x0-0x120000 matching byte for byte, with
`nvs` and `phy_init` unchanged against the backup. The C6 now boots, enumerates
and passes the gate at 3.0.6.

The two gates below stood in front of that write, one of them physical. They
are kept because they apply again to any other board.

**The image.** Built from a clean archive of `551e281`, twice, byte-identical:
`kino-c6.bin` **1 105 872 B**,
`3616fe6e6e6329f7443dce0f19232bb6aded9091801db874f150a18a1baaee61` - the same
hash recorded on 2026-08-28, so it is stable across environments as well as
repeatable. `esp_hosted` 3.0.6 (`component_hash 1b1c2aa8...`), ESP-IDF v5.5.1,
4 MB flash, custom table `partitions_eh_cp_ota_4m.csv`:

| Partition | Offset | Size | Factory equivalent |
|---|---|---|---|
| `nvs` | 0x9000 | 16 K | same offset |
| `otadata` | 0xd000 | 8 K | same offset |
| `phy_init` | 0xf000 | 4 K | same offset |
| `ota_0` | 0x10000 | 1792 K | factory: 0x10000, 1536 K |
| `ota_1` | 0x1d0000 | 1792 K | factory: 0x190000, 1536 K |

Generated flash set (`flash_args`): bootloader at 0x0, partition table at
0x8000, `ota_data_initial.bin` at 0xd000, `kino-c6.bin` at 0x10000. **Migration
review:** `nvs`, `otadata` and `phy_init` keep the factory offsets, so the
write set never touches the factory NVS or PHY calibration; only the OTA slots
grow, and the 1.1 MB image ends well inside factory `ota_0`. The factory table
is replaced by ours, which is intended.

**Gate one - physical.** CH340G TXD idles at **4.7 V**, measured. It may not be
connected to `C6_U0RXD` until a 1 k / 2 k divider is fitted and its midpoint is
measured at 3.0-3.3 V with TXD idle. RX-only wiring stays as it is. No adapter
VCC to the board, ever.

**Gate two - the P4 must be inert.** A normal radio build pulses GPIO54 once
for the operator and again inside `connect_to_slave()`, which would pull the
C6 out of its bootloader mid-write. So the recovery image
(`-DKINO_C6_RECOVERY=1`, built: `33a2a9b62dc989eadd9f7b2074660a65407d8a070eea4de9f926fed5db72bd0e`,
1 172 400 B) announces, waits five seconds for the strap, pulses GPIO54 low for
500 ms, releases, and never touches the C6 again - no SDIO pin, no ESP-Hosted.

**The sequence, once both gates clear** (nothing below has been run):

1. Flash the recovery image to the P4 on COM8. Wait for `RECOVERY: hold JP1 pin 24 (C6_IO9) LOW now`.
2. Operator holds pin 24 to GND; the P4 pulses reset; `RECOVERY: released`. Release pin 24 after the ROM banner shows `boot:0x... (DOWNLOAD...)` on COM9, or after ~2 s.
3. Identify, write nothing: `esptool --port COM9 --chip esp32c6 --before no_reset --after no_reset chip_id`. Require ESP32-C6, revision ~v0.2; record MAC.
4. Confirm geometry: `... flash_id`. Require 4 MB. Record manufacturer and device ID.
5. Back up everything: `... read_flash 0 0x400000 factory-c6-kd4-d121bc.bin`; SHA-256 it; keep it local, not in the repository; record size, hash, date, MAC, factory version 2.3.2.
6. Decode the factory table from the backup (`gen_esp32part.py` on the 0x8000 region) and record it beside ours.
7. Write per the generated `flash_args`, `--flash_size 4MB`, then `verify_flash` - or rely on esptool's write verification and read back the app region hash.
8. Release IO9, pulse reset once more (the recovery image is still on the P4 - a P4 `REBOOT` repeats its single pulse), capture the whole COM9 boot. Require a clean boot, our partition table, `ESP-Hosted-MCU Slave FW version :: 3.0.x`, SDIO slave up.
9. Flash the normal radio image back to the P4. Camera-first baseline first; then require rx_ready and tx_ready again, then the version RPC.

## 4. Turn on the host — DONE, and OFF BY DEFAULT

### The command

```
cd firmware/p4
rm -f dependencies.lock
idf.py -DSDKCONFIG_DEFAULTS="sdkconfig.defaults;sdkconfig.radio" \
       -DKINO_ROLL_API_BASE=https://<the API host> \
       build
```

`rm -f dependencies.lock` matters: a lock the component manager considers up to
date makes it download nothing, and the build then fails in confusing ways.
Delete `build/` too when switching between the two variants — the sdkconfig is
cached there.

`KINO_ROLL_API_BASE` has no default. This repository records no public KINO API
hostname, and a plausible wrong one compiled into a binary is worse than a
refusal that says the address is missing; without it every Roll call refuses
with exactly that. `KINO_SNTP_SERVER` overrides `pool.ntp.org` the same way,
for a bench with no route to the public pool.

### Why it is an opt-in and not a `#define`

Espressif's own P4 host configuration sets
`CONFIG_ESP_HOSTED_AUTO_CALL_INIT_BEFORE_APP_MAIN=y`, which installs an
`__attribute__((constructor))` that calls `esp_hosted_init()` **before**
`app_main()`. With `CONFIG_ESP_HOSTED_HOST_CP_RESET_STRATEGY_ALWAYS=y` beside
it, enabling the component drives `GPIO14`-`GPIO19` and `GPIO54` on every boot,
before a single line of KINO firmware runs — before the display, the card and
the capture pipeline exist, so a fault would present as a dead camera rather
than a dead radio.

The routing is corroborated and unmeasured, and `GPIO54`'s polarity is
unconfirmed. Shipping that on by default would drive unproven pins on every
power-up of every unit.

So:

| | default build | `sdkconfig.radio` |
|---|---|---|
| `CONFIG_ESP_HOSTED` | `n`, explicitly in `sdkconfig.defaults` | `y` |
| radio sources | not compiled | `net_hosted.c`, `net_wifi.c`, `net_time.c`, `roll_http.c` |
| `net_link` reports | `NET_C6_NOT_ROUTED` | the real state |
| pins driven | none | GPIO14-19, GPIO54 |
| `kino-p4.bin` | 800 KB | 1384 KB |

`sdkconfig.radio` also sets `AUTO_CALL_INIT_BEFORE_APP_MAIN=n`, so even in the
radio build nothing is driven until `net_hosted_start()` says so — which
`main.c` calls last, after the UI and the capture pipeline are already usable.
That is also what allows the runtime pin configuration: with the constructor on,
ESP-Hosted's shadow config is locked and every setter returns
`ESP_TRANSPORT_ERR_ALREADY_SET`.

The two halves are cross-checked in `main/CMakeLists.txt`. Naming the fragment
without `CONFIG_ESP_HOSTED=y`, or setting `CONFIG_ESP_HOSTED=y` without the
fragment, is a `FATAL_ERROR` — the second case is the dangerous one, because it
would drive the C6 pins with no driver compiled behind them.

Note on CMake: the switch is read from `SDKCONFIG_DEFAULTS`, not from
`CONFIG_ESP_HOSTED`. ESP-IDF processes a component's `CMakeLists.txt` twice —
once to expand `REQUIRES`, once to build — and `CONFIG_*` is not populated in
the first pass. Measured: `if(CONFIG_ESP_HOSTED)` around
`list(APPEND kino_reqs ...)` compiled the radio sources with none of their
include directories and failed on `esp_crt_bundle.h: No such file or directory`
while every other component resolved fine.

### What the sequence does

`net_hosted.c`:

```
hold GPIO54 at the reset level         -> NET_C6_BOOTING   (counts a reset)
release it, settle
hand ESP-Hosted our pins, esp_hosted_init()
    -> SDIO enumerates on slot 1
version exchange (a GATE, see below)   -> NET_C6_LINK_READY
esp_netif + esp_wifi_init + STA start  -> NET_RADIO_READY
                                       -> NET_WIFI_IDLE
auto-join the stored network, if there is one
```

Failures map onto reasons that already existed, so `NETWORK_STATUS`, the RADIO
screen and Studio need no change:

| Failure | Reason |
|---|---|
| SDIO does not enumerate | `NET_REASON_C6_NO_RESPONSE`, state `C6_ABSENT` |
| the version RPC times out | `NET_REASON_C6_NO_RESPONSE` |
| the coprocessor version is incompatible | `NET_REASON_C6_BAD_FIRMWARE` |
| the link drops after coming up | `NET_REASON_C6_LINK_LOST` |
| `esp_wifi_init` fails | `NET_REASON_RADIO_FAILURE` |
| wrong passphrase | `NET_REASON_AUTH_FAILED`, and it does **not** retry |
| no address | `NET_REASON_DHCP_TIMEOUT` |
| no trustworthy clock, so no TLS | `NET_REASON_CLOCK_UNTRUSTED` (new enumerator) |

A wrong passphrase deliberately does not retry: the access point counts the
attempts and a camera that hammers it gets blacklisted, which then looks like a
hardware fault. Everything else lets the driver's own retry do the work rather
than stacking a second loop on top.
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

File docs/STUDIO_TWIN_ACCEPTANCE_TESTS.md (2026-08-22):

# Studio + Twin acceptance tests

Issue #72. Two layers: the automated contract test, and the no-code virtual
walk. Labels: REAL (works now, verified), SIMULATED (works now, simulation
clearly labeled), FUTURE (waits on a later firmware milestone),
BLOCKED_BY_HARDWARE (waits on the physical bench).

## Automated contract test — REAL

`packages/test-fixtures/tests/firmwareIntegration.test.ts` (runs in CI):

1. Pin the device to the current-firmware profile (`d4-m1b`).
2. HELLO — product, protocol, nonce echo, session id.
3. GET_DEVICE_INFO / GET_CAPABILITIES / GET_STORAGE_STATUS /
   GET_CAMERA_INFO — the honest M1B shapes (CAM2–4 offline, one capability).
4. Unimplemented commands NACK with the firmware version.
5. CAMERA_TEST — checksummed capture result.
6. A frame-source capture produces REAL bytes: `MEDIA_READ` returns exactly
   the rendered JPEG, `MEDIA_THUMB` the rendered thumb, `CAMERA_PREVIEW`
   the rendered preview; all four cameras rendered.
7. REBOOT → reconnect → session changed.
8. OTA install of a `0.1.0` image over `FW_BEGIN/CHUNK/END` (SHA-256
   verified) switches the device to the honest M1B profile.

Plus: 42 kdp_core host checks (framing), Twin's 112 unit tests, Studio's 220
(incl. the conformance suite's six capability-gated bench cases).
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

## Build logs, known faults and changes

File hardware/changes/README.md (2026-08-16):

# Engineering change notices

Every accepted change to the BOM, wiring, mechanical interfaces, power limits, GPIO assignments, CAD, PCB, or physical acceptance criteria gets a numbered ECN.

Use [`../ECN_TEMPLATE.md`](../ECN_TEMPLATE.md). Name files `ECN-NNNN-short-name.md`. Numbers never move or get reused. Rejected and superseded notices stay in history with their final status.

An ECN states the design-package bump:

- patch for clarified source or a compatible production correction;
- minor for a backward-compatible physical capability or new artifact;
- major for a compatibility break inside a stable hardware line.

Before design version `1.0.0`, the package is still a prototype. A breaking prototype change may use a minor bump, but the ECN must describe the break.

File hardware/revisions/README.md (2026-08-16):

# Hardware revisions

A hardware revision identifies physical compatibility. It is separate from the design-package version in [`../manifest.json`](../manifest.json).

`D4-V1` means the first D4 electrical and mechanical architecture. The design package can move from `0.1.0` to `0.2.0` while it remains D4 V1. A change becomes D4 V2 when an existing V1 unit cannot accept it without electrical, mechanical, harness, or firmware-pin changes.

Each revision record must state:

- lifecycle status;
- physical interfaces;
- protocol compatibility;
- unresolved measurements;
- accepted engineering change notices;
- first and last design-package versions;
- migration or service implications.

The current record is [`D4-V1.md`](D4-V1.md).

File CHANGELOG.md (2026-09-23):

# Changelog

KINO has no published release yet. Changes intended for the first release collect under **Unreleased**. Git remains the record for work completed before this file existed.

## Unreleased

### Changed

- **Firmware 0.4.59: the log ring keeps evidence instead of telemetry (#202, #207).**
  Measured on a bench body: 158 entries over 148 s, of which 121 were per-camera
  preview timings and 37 were cover brightness means. Not one line was anything
  else. At 1.07 lines a second the 200-entry ring held 3.1 minutes, so any fault
  older than that was gone before anyone could ask about it, and
  `/KINO/LOGS/BOOT-nnnnn.TXT` - the file an owner is asked to send - was the
  same content at length. klog now has two channels: `klog()` for what a person
  needs when a camera misbehaved, and `klog_tel()` for a number that is worth
  having on a bench and is noise in a fault report. Telemetry is off unless
  `body.log.telemetry` is set, which Studio can do without a reflash. The
  viewfinder's timing report, the cover watcher's calibration line, the gallery's
  once-per-photograph index line and the per-press touch line all moved to it.
  Two recovery lines stopped repeating: "viewfinder live" was cleared by any
  failed pump, so a camera dropping one frame in six logged it on every
  recovery, and the link's recovery line fired for a run of one timeout while
  its failure side was throttled to 30 s. The ring is 600 entries now, 72 KB of
  PSRAM. And CLEAR_LOGS no longer stops the field log: it used to reset the
  count while the card writer kept its own cursor, so one press in Studio left
  that cursor permanently past the end and the file never gained another line.
- **Firmware 0.4.59: a warning fails the build, and three NUL bytes are gone (#201).**
  `firmware/p4/host_preview/preview.c`, `firmware/p4/twin_ui/twin_ui.c` and
  `firmware/p4/main/gallery.c` each held a raw zero byte inside a character
  constant that was meant to be an escaped zero. It compiled as zero, so
  nothing misbehaved; what broke was searching, because grep and ripgrep
  classify a file with a NUL in it as binary and skip it without saying so.
  Two audits of this tree were given wrong answers by it, one of them a false
  report that the host preview was broken. Our own components now compile with
  `-Werror`, scoped so that `managed_components` is still not ours to fix - and
  the gate found the third NUL byte on its first run, in a file the host
  preview does not compile. The other three warnings the build had been
  printing for days are gone with it: two dead functions, and the deprecated
  `esp_lcd_touch_get_coordinates`, now `esp_lcd_touch_get_data`.
  Removed with them: five uncalled functions and three orphaned doc comments in
  `gfx.c`, thirteen dead symbols in `ui.c`, five leftovers in the Twin shim, and
  the comments that described a guest mode, an icon builder, a six-tile menu and
  a `tile_rect()` that have not existed since the shell rewrite. Fourteen
  triple-encoded dashes in `ui.c` comments are readable again. The LOOK picker
  and the SOUND volume band now derive their rectangles from one helper each
  instead of computing them once in the draw and again in the hit test, which
  is the convention every other screen already kept; all 206 rendered screens
  are byte-identical before and after.
- **The device copy table is checked, not promised (#204).** `docs/DEVICE_COPY.md`
  opens by saying it holds every line the body says on its own screen, and said
  it was checked against the source when a line changed. Nothing enforced that,
  and it had drifted to 43 of the 93 lines the camera can actually draw. Missing
  were things a person reads and quotes back on a support call: "The camera has
  no complaints.", "Press the shutter to take one.", "No radio on this body.
  Photos leave over USB-C.", the whole of the ROLL screen's empty state, and
  every row of SOUND and POWER. `npm run copy:check` now walks the drawing and
  toast calls in `ui.c`, `conditions.h` and `capture.c` with comments stripped,
  and fails when a line they can draw is not in the table. It runs in CI beside
  `version:check` and `license:check`. The table gained a section per screen; a
  string that is genuinely not copy goes in the script's short NOT_COPY list
  with the reason, so the exceptions are visible rather than assumed.
- **Both rehearsal surfaces compile the build that ships (#203).** The image
  customers get is the radio build, and neither the host preview nor the Twin
  defined `KINO_RADIO`. The only UI-visible thing behind that flag is the STATUS
  row 0.4.59 added for a Roll with no server (#198) - so the two tools whose
  whole purpose is looking at every screen before it ships could not show one of
  them. Turning the flag on was not enough on its own: both stubbed the server
  lookup as present-but-empty and returned true, which is a state no camera can
  be in, and the condition fires when that call returns false. The stub now
  reports an absent base, the preview renders `status_roll_no_server` and
  `roll_no_server`, and the Twin's page can drive it through
  `kui_set_roll_server`.
- **Firmware 0.4.59: one number for the largest preview frame (#208).** The node
  treated anything above 32 KB as a photograph-sized leftover and took the next
  frame; the body refused anything above 24 KB by size. A 320x240 frame of a
  detailed scene at the highest preview quality lands between the two, so the
  node kept it and the body dropped it, and the pane blinked on a camera that
  was working - which is the symptom the node's guard exists to prevent. The
  ceiling is `NL_PREVIEW_MAX_BYTES` in the header both ends read, at the larger
  value, so there is no band where a frame is acceptable at one end and not the
  other. The body's buffer is in PSRAM, so matching costs 8 KB a channel.
- **Firmware 0.4.59: two ways a photograph was lost (#205, #206).** A settings
  write from Studio during a shutter press could panic the capture task:
  `cfg_num()` walked the live cJSON document with no lock, on a different task
  from the one that relinks it, which `config_store.c` describes as a
  use-after-free waiting for its moment and which `config_str()` had already
  been fixed for. It goes through a locked `config_num()` now, and the borrowed
  pointer says in its header that it is only safe on the writing task. And a
  camera node could still be working on a photograph the body had given up on:
  `CAPTURE_BUDGET_MS` was read only at the top of the freshness loop, so it
  bounded neither the first fetch nor the mode-change drain in front of it, and
  each of those blocks for the driver's 4000 ms - the whole of the body's
  `NODE_CAPTURE_TIMEOUT_MS`. The node now waits for the driver to queue a frame
  rather than blocking inside the fetch, so every fetch is bounded by one
  deadline taken at the top of the handler, and the held frame is released
  before the resolution changes so the drain is not waiting on the last free
  buffer.
- **Firmware 0.4.59: the cover watcher has a switch (#169).** `lid_set_acting()`
  was defined, declared and called from nowhere, so the watcher could only ever
  observe and the sleep-on-cover-close behind it could not happen on any body.
  It now reads `body.coverWatch` at boot and on every accepted SET_CONFIG. The
  default is still false, for the reason `lid.h` gives - the two thresholds are
  unmeasured and the mistake this feature makes is putting the camera to sleep
  in the middle of a party - but measuring them and trying the result no longer
  needs a reflash.
- **Firmware 0.4.59: the card self-test stops racing itself (#210).** The card
  watcher runs a write self-test on a card that has just mounted, under the
  card lock. Studio's STORAGE_SELF_TEST took only the capture lock, which says
  nothing about the card, so running it inside that window put two tasks
  through one fixed path and one shared static buffer - and the loser reported
  VERIFY_FAILED on a healthy card, latched the write test to "fail", and the
  camera told its owner the card could not hold a photograph. Both that and
  STORAGE_BENCH now take the card lock, and `storage.c` says why the shared
  buffer is only safe while they do.
- **Firmware 0.4.59: a shutter that cannot work says so (#210).** If
  `capture_init()` failed part way - some workers created, the request queue
  created, and no capture task to drain it - nothing downstream could tell.
  `capture_request()` queued into a queue nobody reads and returned true, so
  the first press was swallowed and every later one was refused as "a capture
  is already running", which was not true. The shutter was dead and the camera
  said nothing. The pipeline now reports whether it came up, a part-built one
  refuses instead of swallowing, and the shutter says "The cameras did not
  start. Restart the camera" rather than inventing a reason.
- **Firmware 0.4.59: the camera link runs at 3 Mbaud by default, and finds its
  nodes wherever they are (#221, #228).** #218 measured the rates and left the
  default at 921600; this is the decision. Once the body has found its nodes it
  drives all four channels to 3000000. Measured on KD4-D121BC, same scene: a
  four-camera capture goes from 4237 ms to 1642 ms, each link from 86.7 KB/s to
  276 KB/s.
  `NL_DEFAULT_BAUD` does not move and is a different thing: a node powers on at
  921600 and both ends fall back to it when a switch fails, so that path has to
  work with no negotiation behind it. `NL_BAUD_PREFERRED` is the new rate, and
  `body.linkBaud` still overrides it; a stored value that is not a rate a node
  accepts means the preferred rate and says so once, rather than being handed to
  every channel to refuse.
  All four together on purpose. A capture ends when its slowest link ends, so
  one camera left at 921600 makes the whole shutter as slow as it was and the
  other three gain nothing. A channel whose node answers and will not hold the
  rate puts all four back on the default and logs it; a channel with nothing
  fitted answers at no rate at all and is not a failure.
  The nodes do not share the body's reset, so after a restart the body's UARTs
  are at 921600 while the nodes are wherever they were left, and nothing
  recovers that on its own - a node's revert arms only when a switch happens, so
  one sitting at 3 Mbaud has no deadline running. `camlink_resync_baud_ch()`
  tries the intended rate first, which is one HELLO on every boot where nothing
  moved, and otherwise walks the other supported rates at a 250 ms probe and
  moves the node it finds. Bench: a body reset comes back with all four at
  3 Mbaud, and a node stranded at another rate is found and moved 1.1 s after
  the first timeout.
  `SET_LINK_BAUD` takes `persist`, default true. `scripts/kino-baud-ramp.mjs`
  sends `persist: false` throughout, including in its own tidy-up, so walking
  the rates changes the wire and never what the body comes up at.
- **Firmware 0.4.59: the camera link can change speed (#218).** Measured on the
  bench, a four-camera capture moves 686 KB in a 2.75 s transfer window with
  every link holding 86.5 to 86.9 KB/s, which is 96% of a 921600-baud wire. The
  body is not the constraint and the four transfers do overlap; what sets the
  shutter-to-ready time is the largest JPEG divided by the line rate, and on
  that capture the four lenses produced 114 KB to 224 KB. So the only lever
  that does not trade picture quality for time is the wire itself.
  `SET_LINK_BAUD` now exists end to end - a new `NL_CMD_SET_BAUD` on the node,
  `camlink_set_baud_ch()` on the body, and the KDP command that was reserved
  at 0x45 and never implemented - accepting 921600, 1.5M, 2M and 3M.
  The link is two wires with no flow control and none is possible on V1, so
  neither end can report that the two disagree about the rate. Both therefore
  treat a switch as provisional: the node returns to 921600 unless a frame
  decodes at the new rate within 2.5 s, and the body waits longer than that
  before giving up, so a failed switch always settles back on its own without a
  power cycle. The finder is held across the change, because it talks to the
  same four channels and a capture lock does not stop it.
  `scripts/kino-baud-ramp.mjs` walks the rates in one session and reports
  throughput and the CRC, resync and timeout counters at each, and puts the
  link back on 921600 whatever happens.
  Measured on KD4-D121BC with all four cameras: 87.0 KB/s per link at 921600,
  139.9 at 1.5M, 185.6 at 2M and 274.9 at 3M, with zero CRC failures, resyncs
  and timeouts at every rate over 24 captures and six switches in both
  directions. Shutter-to-ready goes from 3716 ms to 1755 ms. The FIFO headroom
  argument against 3 Mbaud did not survive contact with the bench.
- **Firmware 0.4.59: the camera stops saying a deleted photograph was saved
  (#210).** When META.JSON would not commit, the capture said "Card error.
  Photo saved without its notes" and then deleted the folder, because a set of
  unexplained JPEGs is worse than none - the right policy, and the words were
  wrong. The outcome is the same as a folder that could not be made, so it says
  the same thing: "Card error. Photo not saved." The error code and the log
  still separate the two causes.
- **Firmware 0.4.59: uploads with nowhere to go are said (#198).** A body with a Roll joined but no Roll server - no compiled API base and no `network.apiBase` from Studio - parked every upload as FAILED while ROLL said Online. STATUS now carries "Uploads have no server. Set the Roll server in Studio. Photos stay on the card." Found on the 0.4.58 release soak: 40 captures, 34 uploads parked for that one reason.
- **Twin: a viewfinder pane that stops receiving frames stops being live.**
  The firmware shim marked a pane live for ever once its buffer pointer had
  been fetched, so SCREEN VIEW showed four black panes under a lit 4/4 when
  the preview feed stalled - the rig's timer stops with a hidden tab, and
  nothing noticed. The page now reports each landed frame (`kui_vf_landed`)
  and the shim ages them on its virtual clock with the driver's own two-second
  rule: NO RECENT FRAME, and out of the strip's count, exactly as
  `viewfinder.c` reports it on the camera.
- **Twin: the stage starts as the party scene, not as a void.** The stage
  store began with no subjects and no room, so the virtual sensors
  photographed nothing: four pure-black panes on SHOOT under a lit 4/4, and a
  black JPEG from every capture, until someone found PARTY TEST SCENE on the
  STAGE tab. The scene the brief asks for as the one useful default is now
  the start state; CLEAR STAGE still empties it. Found by sampling every 2D
  canvas the rig writes - the 320x240 preview was all zeros in both views.
- **A frame is drawn once, and a move is a state rather than a loop.** Four
  things were wrong with the interface's motion and only one of them was the
  easing curve. They were found by counting, not by looking: the renderer now
  reports what each frame costs, in units of full 800x480 screens, and the
  camera's own budget makes that number a time - the canvas is in PSRAM at
  160 MB/s, the DPI panel eats 46 MB/s of that continuously whatever else is
  happening, and 114 MB/s is 1.9 MB per frame at 60 Hz.

  **A blocking move cannot survive the Twin.** Every animation was a `for(;;)`
  that read the clock, drew, and presented until its time was up. The Twin
  runs this same code as WebAssembly and a pass is ONE call: whatever it
  presents lands in a ring of 40 frames and is played back afterwards. The
  boot sequence presented about 119. Seventy-nine of them went into the same
  slot, so the splash played its first third and snapped to its end - the
  frames were computed and thrown away, and no easing curve was ever going to
  fix that. Moves are state now, and `anim_tick()` advances one frame per UI
  pass: measured on the shipping wasm, a menu open is 35 passes of exactly one
  frame each, and the splash never puts more than two in a pass. The camera
  gets the same fix for a different reason - a 2.1 s splash no longer owns the
  UI task while a shutter press waits behind it.

  **A frame that only moves should not be drawn again.** `gfx_layer_keep()` /
  `gfx_layer_blit()` keep a second retained surface, and the menu's open move
  carries its six cards as two blits instead of redrawing them. That took the
  move from 1.38 screens a frame to 1.09, and - the part that matters - its
  spread from 2.1x to 1.5x. Even frames are what the eye reads as smooth, more
  than fast ones, and the old move was slowest at its start, which is exactly
  where the eye is following it.

  **And it ended with a hitch.** Every transition finished by calling
  `draw_screen()` on the destination - up to 3.12 screens on GALLERY against
  about 1.0 for a composited frame - to produce a picture the card was already
  showing. Opening, the last frame is composited now; going back it is still a
  real draw, because going back the stash holds the screen being left.

- **The boot screen is the reference's field, traced frame by frame, and it
  is the only thing on the screen.** The first attempt copied the wrong clip -
  the round device's concentric bloom, which the reference does do and is not
  what its startup is. The startup is a **square lattice of small glyphs**
  that grows out of a seed of about four cells, fills the panel, holds, and
  draws back in. Four things make it read the way it does and only the last is
  a colour choice. Cells sit on a regular pitch in rows and columns, so the
  diagonals you see are the lattice and not something drawn diagonally. Each
  cell holds a mark from an alphabet rather than a dot, which is what stops
  900 cells reading as noise. Weight falls with distance - hashes, discs and
  solid squares in the middle, single dots and short runs at the rim - and
  that gradient is why it looks like something radiating instead of a texture
  somebody tiled. And **every cell changes what it is while you watch**: a
  cell holds a mark for about 190 ms and then is a different one. Not off a
  global counter, which makes the whole panel blink at once and reads as a
  glitch, but off a clock offset per cell, so the changes scatter. Whether a
  cell is lit at all is fixed by position and never re-rolled - a field whose
  cells appear and vanish twinkles, and the reference's does not.

  **Nine glyphs, and they are the reference's nine.** The first read of the
  alphabet had a plus and a pair of HORIZONTAL bars where the reference draws
  vertical ones - a mark turned ninety degrees is a different mark - and folded
  the asterisk into the hash, which are the two commonest things on that screen
  and are not the same shape: the hash has a dark centre and dark corners, the
  asterisk is solid through the middle with its four diagonal points detached.
  Most of the rim turns out to be pairs of short uprights. So: hash, asterisk,
  a square ring broken at one corner with a dot inside, a stepped circle, a
  solid square, two uprights, one upright, a short run of dots and a dot -
  every one of them a 5x5 bitmap at three pixels to the bit.

  **Nothing in the field is a drawn shape.** The circle and the square were
  going through `disc()` and `round_rect()`, which put the one antialiased
  curve in the whole picture - a smooth circle among nine pixel forms, which
  is as wrong as a smooth letter in a bitmap font. Blown up twenty times the
  reference's own circles step: a flat top a few pixels wide, out one, out
  again. It is drawing a pixel circle, so this draws a pixel circle, and the
  two forms differ only by whether the corner bits are set - which at three
  pixels to the bit is the whole difference between a round thing and a square
  one. The arrival is carried entirely in the ink now, which is where a bitmap
  can carry it.

  **And it is drawing this camera, not somebody else's lamp.** The reference
  is a light remote, and both quantities in its display are facts about a
  lamp: the field's size is how bright the light is, and its colour is the
  colour the light is being set to under your finger. That is why it holds
  attention - it is not decoration, it is the instrument's read-out. Copying
  the picture without the meaning would have given us a screensaver.

  A D4 is the opposite instrument: it does not emit light, it gathers it,
  through four lenses. So the two quantities carry the two things that are
  actually true about this machine while it wakes up.

  **How far the field reaches is how many of the four cameras have answered.**
  One quadrant each - cam 1 top left, running across then down, which is how
  the four sit on the viewfinder, in the gallery's mark and on the body -
  eased rather than switched, so a node answering part-way through the boot
  opens its quarter out instead of making it appear. A camera that has not
  answered holds its quarter at 42% rather than blacking it out, so the shape
  stays a field instead of a pie chart with a slice missing, and the
  quadrants blend across their axes because a hard quarter boundary draws a
  cross through the middle and the reference's field has no cross in it. What
  this buys: **a body with a dead node says so on the first screen it shows**,
  without a word of type, in the product's own mark, which is four.

  **What colour it is, is the look it will shoot with.** The lamp's colour is
  the light; a camera's colour is its look, which is the recipe every
  photograph gets graded through - the same role in the same grammar. The
  field comes up cold and travels to the look's own colours as the cameras
  answer: the camera finding what it is shooting with. The look is hashed to
  one of four palettes rather than tabulated, because looks are the operator's
  and are made in Studio, so there is no list here to colour by hand; what
  matters is that it is stable, so a given look brings the same colour up
  every time and the way your camera starts becomes something you know about
  it. The palettes are the camera's own - the reference's hues where they fit
  the product and dropped where they did not, because a camera that boots
  violet is a camera pretending to be somebody else's object.

  **The two snaps were the re-roll clock, not the motion.** The field's
  geometry was provably continuous across its phases - the reach curve, and
  the lit-pixel count measured off the rendered frames, show no step at either
  boundary - and it still visibly hitched twice. Each cell picks its mark from
  a generation counter derived from elapsed milliseconds, staggered by a
  per-cell offset so the changes scatter; but that number was measured from
  the start of the current PHASE, and starting a phase resets it. So at each
  of the two internal boundaries the counter went back to zero and every cell
  in the field re-rolled on the same frame. Three phases, two boundaries, two
  whole-field flashes, in exactly the two places the motion was smoothest. It
  runs off the start of the whole sequence now. Counting the interior pixels
  that change per frame is what found it and is what shows it gone: flat at
  about 1,500 through the hold, where it had been spiking threefold.

  **And the motion itself is one motion.** The growth had been two eased
  beats glued end to end - a seed easing out to a stop at 132 px and a bloom
  easing back in from rest - and smootherstep has zero velocity at both ends,
  so the field visibly stalled a third of the way out and set off again. It is
  one curve now, 0 to 590 px. The retreat used `1 - smootherstep`, which
  flattens as it finishes: the last of the field crept away over a third of a
  second and then the panel sat empty waiting for the phase to end. Something
  leaving should gather speed, so it is `1 - t^2` and hits nothing exactly as
  the menu arrives. The field also starts at a 52 px seed rather than zero,
  because smootherstep has moved six per cent a fifth of the way through and
  the first four hundred milliseconds were a black screen; the reference's
  first frame already has cells in it. The frontier is soft and ragged rather
  than a hard expanding circle - each cell arrives at its own radius and comes
  up out of the ground over 66 px of travel - and the jitter grows with
  distance, because a thing spreading out is tight at its origin and ragged at
  its edge. The whole sequence is 3.76 s, and it is centred on the panel: it
  had been sitting 32 px high, holding a gap for a wordmark that is no longer
  on this screen.

  **Nothing else is on the boot screen.** It had carried the studio's disc at
  its centre and the camera's wordmark under it with a four-cell mark under
  that; the reference's startup carries none of it, and it is one thing
  happening, which is why it holds attention for two seconds. Both marks keep
  the place that is theirs: the studio signs the ABOUT screen, and the
  wordmark is what the camera shows when it is **going away**. Shutting down
  and restarting now put `kino D4` in the middle of the screen and then let go
  of it, fading through the ground rather than cutting to black - the backlight
  is still on for a moment after that returns, and a hard cut leaves an empty
  lit rectangle. The old shutdown took the four cells out one at a time, which
  is a sentence about the four cameras: the right thing to say while a capture
  is happening and the wrong thing to say while the camera is switching off.

- **The renderer fails a run that sets type outside the safe area, and it
  found four screens doing it.** `text()` reports any string drawn outside the
  page margin, deduped and named by the screen it happened on. Clipping is the
  obvious fault, but the one the interface actually had is a sentence ending
  2 px from the bezel: it does not look broken, it looks cheap, and it is much
  harder to catch by eye. The viewfinder's status bar is exempt by saying so
  at the bar, not by a magic range in the checker. What it caught: the About
  screen's camera note running off the right of the panel and over the bezel
  (the break was chosen by hand for the old bitmap face and never revisited
  when the type changed - notes wrap on a measurement now, `text_block()`);
  the ROLL screen's "Wi-Fi is up. They go when KINO answers." doing the same,
  386 px in a 344 px column, on the one screen a guest reads at a party; the
  Storage screen's two readings sitting 1 px past the bottom of the panel with
  their descenders in the bezel, because 406 px of content was being asked to
  fit a 401 px body; and the ABOUT name box overrunning by a pixel while the
  maker's plate opposite it was already on the margin - the two columns of a
  two-column screen were ending on rules 9 px apart. ABOUT lays its left
  column from the margin back up now, and ROLL anchors the block whose height
  depends on the camera's situation to the margin so its slack comes out of
  the middle of the column, where nobody can see it move.

- **The photograph screen's column had two grammars.** Bare type on bare
  ground at the top, three rounded controls at the foot, 114 px of nothing
  between them. The facts go in a well on the same rail as the buttons, and
  CAMERAS sits above the mark it names rather than under it - every other
  label on this interface is over the thing it labels. `PH_LINE` was also
  still 18, the old bitmap face's line height, so the one assert standing
  between the caption and the buttons had been measuring a column a third
  shorter than the one being drawn.

- **The guest half is gone from the records too.** `D4_INTERACTION.md` argued
  for a guest/owner split behind a physical switch and was still telling
  readers the shell is a Windows-era placeholder, the register is undecided,
  and to build a specimen next - none of which is true. It records what
  replaced it, and why the argument lost, and keeps the production-state list,
  which was the most useful page in it and is not about guests. `ECN-0006`
  asked hardware for a pin to switch a UI that no longer exists and is
  withdrawn, with its reasoning kept: a lock that is a config key is not a
  lock, and that should not have to be worked out twice. `hardware/WIRING.md`
  says `SLIDE_MODE` is unassigned again. The renderer's `KINO_GUEST_PREVIEW`
  flag was dead and is removed.

- **The studio is named.** Odd Jobs makes this camera, and the firmware
  carries its mark - baked from the studio's own artwork by `tools/mklogo.swift`
  into a 160x160 coverage map that `ui.c` samples, at the centre of the boot
  bloom and at the foot of ABOUT. It is a trade mark and not source:
  `firmware/**` is MIT and that grant does not reach it, so REUSE.toml, LICENSE
  and THIRD_PARTY_NOTICES all say whose it is, and `license:check` fails if any
  of the three stops saying so.

- **The camera stops being a Windows 98 desktop.** The interface was the 1998 shell - four-tone bevels, a navy title bar, six icon tiles, 1-bit Tahoma baked through a headless browser, and a composite-video filter that band-limited the chroma of anything with colour in it so the artwork would resolve the way it did on a CRT. All of it is gone, and what replaced it is one register with a short vocabulary: a near-black ground, one warm card, one warm accent, one mint, a single 10 px corner on every surface, and no edges at all. `W_FACE`, `W_WINDOW`, `W_SEL` and the rest keep their names because the *structure* those tokens describe - a face, a window, a selection - was never the problem; only what they are worth changed.

  **Nothing is baked any more.** `icons_w98.h` (Microsoft's shell artwork, and the licence question that blocked every firmware release - #134), `ui_labels.h` (eleven screen titles stamped to bitmaps by a tool needing Playwright and a Windows path that only existed on one machine), `icons.c`, `tools/mktext.mjs`, `scripts/bake-w98-icons.mjs` and the Twin's second private wasm variant all go together. A screen title is one word in the interface's own voice; there was never a reason for it to be a different kind of object, and the reason it was is that the type could not draw it well enough.

  **The type is Inter and Oxanium, at coverage rather than one bit.** Inter carries everything a person reads as language - the rows, the values, the sentences - and Oxanium, a chamfered techno face, carries everything the camera says as a machine: the screen titles, the technical caps, the word on the card. Both OFL, rasterised to 8-bit coverage by `tools/mkfont.swift` (CoreText, greyscale, never subpixel), so every glyph blends into whatever is behind it. The old header was thresholded to one bit and every diagonal on the panel was a staircase; at 19 px the difference between a stem 1.4 px wide and one rounded to 1 or 2 is most of what makes a face legible. Rounded rectangles, discs and the chevron are sampled the same way, so nothing on the interface has a hard edge on a curve.

  **And it moves.** `gfx.c` gained three motions that ride the PPA the dissolve already used. `gfx_open()` is a row becoming a screen: the list parts (each row accelerating out of frame, the nearest first), the row lifts and grows in both directions, keeping its own face, its own word and its own corners the whole way, and the destination pours into it from the top edge once the card has been itself long enough to be recognised. `gfx_slide()` pushes one screen off another with the outgoing frame travelling three-eighths as far as the arriving one, because two sheets locked together read as one sheet. `gfx_cascade()` lands a list one row at a time. All three ease on smootherstep - no speed and no acceleration at either end - and run 340-700 ms, which is long enough to read; the first cut ran at 160-220 ms and was over before the eye found what had moved.

  Two bugs in the Twin's own playback were fixed on the way, and they were most of what "choppy" meant. Its frame queue timed a pass's frames from the moment the pass *started*, so every frame computed while the CPU was busy arrived late and was dropped - the first half of every transition was computed and thrown away. And it allocated a 1.5 MB `ImageData` per frame, putting 20 MB through the collector during the animation it was allocating for; there is a pool now.

  **The move is drawn, not composited.** The first cut of `gfx_open()` slid two
  finished frames around each other, which is all a compositor can do, and it
  is why the word on the card stopped following it: a rectangle of pixels cut
  out of a 50 px row cannot become a 40 px title, because by the time it is a
  picture the letters are the size they are. So the renderer keeps the one
  thing it is good at - holding a frame (`gfx_stash`/`gfx_stash_blit`) - and
  `open_anim()` in `ui.c` draws every frame of the move with the real fonts.
  The word travels from where it sat in the row to where the screen's title
  will be, changing face on the way, and arrives a moment before the title is
  drawn there, so the eye follows one continuous object from the row it touched
  to the screen it is looking at. The card's target is carried as an offset
  INSIDE the card rather than as a screen position, which is the bug that had
  the word reach the top of the panel long before the card did and land on the
  menu row above it.

  **And the register reaches the whole product, not the half of it that was
  easy.** `draw_row_at()` is now one row grammar - a position, a name, and what
  the name is set to - and every list on the camera is made of it: SETTINGS,
  DISPLAY, SOUND, CONNECTION, STORAGE, ABOUT and POWER, at each one's own pitch,
  with a one-line fallback for the narrow second column ABOUT keeps. The
  confirmation dialogs and the toast were the last two objects still built out
  of the 1998 grammar - a raised window with a caption bar, and a square
  INFOBK plate - which is the worst place for an inconsistency, because
  "delete this photograph" is the moment a person most needs to know what they
  are looking at. Both are cards now. The last five bevel primitives have no
  callers and are gone; there is no `bevel4` left in the file.

  Three collisions the typeface change caused and the first pass shipped
  unlooked-at are fixed, each at its cause rather than by nudging a number:
  the camera column on ABOUT measured its two columns against the face it used
  to be set in and now truncates against the space it actually has; the sound
  picker was drawn through its own row's title and is now the row's value with
  the buttons at the end; and the photograph's readout ran off the left edge of
  the panel, so `chrome_state()` takes a left bound and drops a reading rather
  than drawing past it - the condition chip is laid last and survives longest,
  because it is the only part of that strip a person has to act on.

  **The open, third time, and the sentence it finally makes: the row IS the
  screen's header.** The destination is revealed inside the growing card,
  cropped to it and hung from its top edge, so the first frame fills the row's
  own rectangle with the top 50 px of the screen it opens - which is that
  screen's header, with its title already in it. Nothing has to travel and
  nothing has to be re-typeset, because the title was always in the right
  place: the card's top edge is where a header lives. The row's colour washes
  off over the first third, so the card visibly starts as the thing that was
  touched and becomes the thing that was opened. The version before this flew
  the word to where the title would be and left a large empty rectangle of the
  pressed row's orange behind it for ten frames, which is the loudest thing an
  interface can put on a panel. The per-row stagger went too: a near row
  starting before a far one overtook it, so the card clipped the menu's own
  card and the gaps went uneven; the list parts as two rigid blocks on the
  card's curve now, because this is one gesture.

  Going back was drawing the wrong frame entirely - the stash was taken after
  the redraw, so the card shrinking into the GALLERY row contained the top of
  the menu. The caller stashes whichever end of the move the card holds.

  **And the animation is a sequence of stills you can hold up against each
  other.** `prev_vclock_us` lets the host renderer own the clock and step it
  once per presented frame, so `anim_open_00..27.ppm` and `anim_back_*` come
  out of `npm run preview` like every other screen. The open could only be
  judged by watching it in a browser before, which meant it could only be
  judged carelessly.

  **One page margin.** Measured on LOOK, a single screen had four left edges
  and four right ones - 7, 16, 19, 24 and 775, 780, 783, 792. Nothing lined up
  with anything, and that wobble down both sides of every detail screen is the
  loudest thing on an interface that says nobody drew it. `PAGE_M` is 16 and
  the header plate, the back button, the list cards, the group fields, the
  segment tracks, the LOOK detail strip, the gallery grid, the viewfinder's
  status panels and the photograph's column and well all sit on it. The
  gallery's gutters gave way instead of its tiles (6 across, 8 down) because
  the tile size is the decoder's; a static assert now fails if that grid stops
  ending on the margin.

  **The menu had no floor.** The row ramp ran to 0B1A15 against an 0B0D0C
  ground - a summed channel distance of 20, where the top row has 129 - so the
  bottom two rows had no container and the list appeared to fade out through
  the foot of the panel. The ramp is shallower and stops well clear of the
  page (68 at the darkest). With it: one left rule and one right rule for the
  card and the rows, `text_ink()` so a 74 px headline and a 17 px caps line
  share a left edge rather than differing by their side bearings, a chevron on
  every row because every row opens a screen and that is what a chevron means
  everywhere else in the product, the gallery count in the face every other
  reading uses, and the severity dot on the card's state line so a fault and
  an instruction are not in the same voice.

  Four more, each measured rather than noticed: the viewfinder's status
  readings were the last Inter on a strip of technical caps; the gallery's
  `quad` badge was set in the near-black an accent plate is written in, on a
  near-black strip, so the one word that tells two kinds of photograph apart
  was the least legible thing on the screen; the photograph's capture id did
  not fit its column at any size worth reading, and cutting it produced
  "CAP_0000..." - the prefix every capture shares - so the number takes the
  billing and the prefix drops to the line below; and `menu_word_at`,
  `bevel4`, `bevel_raised`, `bevel_sunken`, `bevel_sunken_dark` and
  `bevel_etched` have no callers left.

  **The last four Windows 98 constructions, found by looking rather than by
  grepping for the word.** The caption plate on every screen was a `fill()` -
  a square-cornered rectangle, the one surface in the product without the
  product's corner - and the gallery then painted a second square rectangle of
  the page colour back over its right end to make room for the page buttons,
  which left that plate with a rounded left edge and a hard-cut right one.
  Patching a shape to the size you wanted is a habit from an interface made of
  rectangles; `head_plate_right()` draws it at the width it needs instead. The
  keyboard focus mark was a rectangle on alternating pixels - Win98's dotted
  focus - which around a rounded card is two shapes disagreeing about what the
  control is; it is a two-pixel rounded ring now. And the capture banner was a
  full-bleed strip with a square corner, a hairline across the top and a
  five-pixel tab down its left edge, sitting on the one screen whose other
  chrome had just moved onto the page margin; it is a card on that margin, the
  accent kept as a bar at its left end because a colour with no shape to hold
  it is a stripe.

  Two comment blocks went with them: the chrome section still opened with a
  paragraph explaining the two-pixel 3D edge and why it reads as a physical
  control, and the flash glyph still said every other icon came from the
  Windows 98 archive. Both were true and neither is; a comment describing a
  grammar the file no longer speaks is worse than no comment at all.

  **The header bar had no rhythm, and the readout is now one layout with a
  stated priority.** Measured on the gallery: six readings separated by gaps of
  14, 34, 39 and 22 px, where the gap between two WORDS of one reading is 10.
  A 14 px separator is four pixels wider than a word space, so "GALLERY" and
  "2 OF 3" read as a single phrase and the whole bar collapsed into a run of
  type nobody could parse. Two gaps now - `BAR_READ_GAP` between readings and
  `BAR_GROUP_GAP` between the title and the group - and `chrome_state()` lays
  every reading on the bar rather than two functions each spacing by eye.
  It also measures everything first and keeps by importance rather than
  position: the first version dropped whatever it reached when it ran out of
  room, which cost the gallery its photograph count - the one reading that
  screen exists to show - by two pixels. The page position moved to the bar's
  right end, beside the buttons that change it.

  **And three contradictions that rounding the corners had papered over.**
  Making everything the same shape is not a design system; a system is roles
  with consistent treatment, and the product was breaking its own:

  - **Three radii calling themselves one.** 10 everywhere, 14 on the menu, 14
    again on the dialog, under a comment that said "the product's one radius".
    One now, with a stated rule: anything inset by n uses UI_R - n so the
    curves stay concentric, which is geometry rather than a second radius.
  - **`button()` and `well()` were byte-identical** - same fill, same corner -
    so a control and a readout were the same object until you touched one. A
    button carries a keyline one step off its ground; a well stays flat.
  - **The confirm dialog was a rounded outsider.** Two chips side by side in a
    card, which is what a dialog looks like everywhere else and is exactly the
    problem: nothing else on this camera asks you to choose between two things
    laid out that way. Its answers are `draw_row_at()` rows now - the same
    function the settings list is made of - which also replaces a pair of
    148 px targets with full-width ones.

  Building it out of rows exposed a fourth, and it was the serious one:
  **focus and selection rendered identically** (`focused || pressed` filled a
  row with the accent), so the delete confirmation opened with CANCEL painted
  as the brightest object on the panel. A press changes the face; focus only
  adds the ring.

  **And the screens compose.** Measured across all 64 renders: POWER was 54%
  bare ground, the roll's empty state 71%, and DISPLAY, SOUND and CONNECTION
  between 45 and 46% - three rows hanging from the top of a panel with two
  hundred pixels of black under them. A screen that stops halfway down reads
  as unfinished whatever is on it, because the eye takes the void as something
  that failed to load. `body_top()` centres a body that does not fill the page
  and leaves one that does at the top, and each list screen states the height
  of its own content - rows, the block under them, and the line under that -
  rather than being centred by eye.

  It is one variable set by the draw and read by the hit test, the way
  `s_head_state_left` already works, because a layout the touch map derives
  separately is the bug this file keeps finding. `draw_screen()` resets it
  before every screen: ABOUT, DISPLAY and ROLL read the value and never set
  it, so without the reset they would have drawn at the previous screen's
  offset and the hit test with them.

  **The conditions got a screen, because they were information nobody could
  reach.** They lived in a panel at the foot of SETTINGS that had room for two
  of them however many there were, so a body with four things wrong showed two
  and the words "and 2 more" - and there was nowhere in the product to read
  the rest. `D4_INTERACTION.md` called that out before it was built: the
  conditions are a list, and a list belongs on a screen. SETTINGS grows a
  sixth row when there is something to say, carrying the worst one by name
  ("Cameras are not answering, and 2 more") rather than a count somebody has
  to open the screen to understand, and SCR_STATUS lists them all with their
  severity and what to do about each.

  **The focus ring is compiled out until something can move it.** Nothing on
  this body can: the shutter fires, touch acts on what it lands on, and BTN_FN
  has no pin until the expander ECN-0003 deferred arrives. A ring marking a
  position no input can move is not a focus indicator, it is a decoration that
  looks like a selection - and it was appearing on the last row anyone
  touched. The ring, the focus array and all eighteen call sites stay; one
  `#if` turns it back on the day that pin exists.

  **The menu has its six marks, drawn rather than sourced.** The reference
  carries a pictogram beside each row; this menu had none, because the icons
  it used to have were tile artwork drawn for a 250 x 205 tile and at a 50 px
  row they were twice the height of it. They are built here out of the same
  primitives every other shape uses - a filled rectangle, a disc, a stroke -
  so there is no file, no licence and nothing to bake, and they antialias with
  everything else. One construction rule is what makes six drawings read as a
  set: LOOK is the four frames with one picked, GALLERY the four as a grid,
  ROLL two rings, SETTINGS three tracks with their knobs apart, POWER the
  power mark.

  **And the roll's empty state composes.** It was 71% bare ground - the most
  of any screen - with its heading, its two lines and the card fact spaced by
  three separate calculations, leaving 90 px of nothing above the heading and
  95 more below the lines. One measured block, centred like every other body.

  What is NOT here, and why: **undo on delete.** `storage_capture_delete()`
  unlinks the files, so a grace period is a trash in storage.c rather than a
  UI timer - and a UI that delays the call would show a photograph as deleted
  while it is still on the card, with no persistence across a power cut. The
  confirmation says it cannot be undone because it cannot.

  **The unity audit, and the one it found that mattered.** Extracting every
  typeface and colour token used by every draw function turned up five
  all-caps labels set in the reading face, four different sizes for the one
  role "this screen has nothing on it", and four colours outside the palette.
  The last of those was the serious one: **the four-mark was blue.** It is the
  product's signature - on the gallery tiles, the viewfinder's status bar, the
  photograph's column, the capture banner and the boot screen - and it was
  drawn in `2F70C9` with a yellow cell for the frame just taken, in a camera
  whose palette is a near-black ground, one terracotta and one mint. Blue
  appeared nowhere else, which made the one shape that says "this is a KINO"
  the one shape that did not look like it. Mint for a frame in hand, the
  accent for the one that just arrived, red when a lens lost it.

  With it: the favourite star was yellow and is the accent, because a
  favourite is not a warning; the capture banner's accent was blue and the
  "saved" state green, and both are mint; `C_WELL` was a second name for
  `W_WINDOW` and `W_LIGHT` a bevel token doing duty as a tile fill, and both
  are gone with `C_BLUE` and `C_GREEN`. The sound picker's pressed state was
  `MZ_CARD` where every other pressed state in the product is `W_SEL`.

  And the type roles hold now: caps belong to the display face (SCAN TO JOIN,
  CODE, NO IMAGE, RESTARTING were set in Inter), sentences to the reading
  face, and an empty screen states itself at one size everywhere rather than
  at 40, 26, 25 and 19 px on four different screens.

  Still a documented divergence, not an oversight: the guest half
  (`guest.h`) keeps the palette `D4_GUEST.md` specifies - `FFD22A` on near
  black - which was written before this register existed. It is unreachable
  until `SLIDE_MODE` gets a pin, and changing a written spec silently is worse
  than carrying the difference.

  P4 image 0x12a5f0, 61% of the app partition free, no warnings. `license:check`
  and `twin:ui:check` green; all 65 host renders and both 28-frame transitions
  inspected.

- **The reference device answers like firmware 0.4.55 on D4-V1 hardware.** An audit of `packages/test-fixtures/src/MockKinoDevice.ts` against `firmware/p4/main/kdp_server.c` found the mock still describing the demo body in a dozen places; each is now the firmware's answer on every profile that pins a real build, with `d4-sim-full` the only place a simulated future remains (and only where labelled). `GET_POWER_STATUS` sends `batteryV: null`, `batteryPct: null`, `batteryMeasured: false`, `charging: false`, `state` from USB presence, plus `displayStage`, `idleSeconds`, `displayOn`, `cameraBankPowered` — the pack figures go on the wire only when the effective `powerTelemetry` capability is true, which no profile (the firmware hardcodes it false) but a Twin override can make it; the internal pack model stays for the Twin's own POWER tab. `SELF_TEST` runs the firmware's six checks by name and order (`P4 heap`, `PSRAM`, `SD card`, `SD write`, `CAM1 link`, `CAM1 sensor`) with its detail strings, and no gauge/flash/speaker rows. The base capability object states `flashHardware: false` (no emitter since ECN-0003), `powerTelemetry: false`, `configStore`, `mediaIndex`, `powerManagement`, `radioFitted`, `radioRouted`; the top-level `firmwareMismatch` field, which nothing consumed and no firmware sends, is gone. `SYNC_BENCH` on a real profile is one blocking `SyncBenchResponse` of per-camera edge counts (`pulses` 1–200, `gapMs` 20–1000, `poll`; `INVALID_ARGUMENT` / `BUSY`; an unwired camera is `watched: false`, not a refusal) and leaves the network/roll gate; the async-job form survives on `d4-sim-full` only. `CAMERA_TEST` answers `CAMERA_OFFLINE` / `SENSOR_NOT_DETECTED`; `DELETE_RECIPE` of an unknown id is `NOT_FOUND`; `SOUND_END` checks the WAV header (16 kHz mono 16-bit PCM, `BAD_FORMAT` with `wav_probe`'s reason); `GET_RUNTIME_STATS` adds `ui{}` and `protocol.droppedTxFrames` and nulls the die temperature of a node that is not answering; `GET_CAMERA_INFO` / `CAMERA_STATUS` carry `viewfinder{frames,fpsX10,drops}` and `CAMERA_LINK_STATS` `viewfinderFpsX10`; `NETWORK_LIST {scan:true}` and `NETWORK_STATUS {probe:true}` answer the D3 blocks; `ROLL_STATUS` carries `serverState`, `ROLL_CREATE` answers the full `RollView` beside the flat five fields Studio reads; `UPLOAD_QUEUE_STATUS` returns all nine fields; `STORAGE_BENCH` clamps instead of refusing, accepts `sizeKB`, takes the capture lock and returns `ok`/`failedPhase`/`passes`/`totalMs`/`cleanupOk`/`sustained{}`/`small{}`; `GET_HW_VALIDATION` mirrors all 56 rows of `hwv_item_t` (wire ids without the enum's `HWV_` prefix, `FLASH_EN_GPIO28` permanently unvalidated); `SET_CONFIG` validates `network.apiBase` per README D3; `MEDIA_INFO` omits digests and `meta` by default (`mediaInfoAsShipped` now starts ON; switching it off opts a suite into digests). A latent `hex8()` sign bug that could emit a negative "CRC" is fixed on the way.
- `packages/test-fixtures/src/firmwareProfiles.ts`: `d4-settings-0-4-9` (0.4.9..0.4.56) uses a new `SETTINGS_0_4_9_COMMANDS` whitelist — 0.4.8's surface plus `SYNC_BENCH` (0x46, dispatched since 0.4.31) and `STORAGE_BENCH` (0x4c, whose handler has been in the tree since firmware/VERSION 0.3.0) — so the profile stops refusing two commands today's dispatcher answers. `PROFILE_FOR_VERSION` gains `0.4.56`. Real profiles no longer state a `syncBench: false` flag the firmware never emits.
- `@kino/kdp` types: `PowerStatus` gains optional `idleSeconds`/`displayOn`/`cameraBankPowered`; `StorageBenchResult` gains the firmware's additive fields and a `StorageBenchPass` type; `KinoConfig` gains `network?: { apiBase?: string }`.
- `@kino/schemas` `kino.device-config` mirrors the wire envelope — `config.mode` plus passthrough `wiggle`/`quad`/`shoot`/`body` and optional `roll`/`network` — instead of a top-level `resolution` and string `flash` that matched nothing a camera sends.
- `firmware-contract/commands.md`: `SET_RECIPE` row carries `cam` and `{ok,id,cam}`; `DELETE_RECIPE`, `SOUND_END`, `NETWORK_LIST`, `NETWORK_STATUS`, `ROLL_CREATE` rows and the `RuntimeStats` example match the firmware; the `CAMERA_TEST` "known drift" note and the `GET_CAPABILITIES` `firmwareMismatch`/`syncBench` notes are updated. README D15's "five targets" clause is retired (the reference device reports six). `docs/studio-spec-audit.md` D-2 records that 02 §30 time sync is met through `HELLO` `hostEpochMs`/`hostUtcOffsetMin` + `clockSource` (D14), no `SET_TIME` needed.
- **The Twin's cameras sit on the body's lens cells, and the external light is on its stud.** The XIAO envelope was drawn landscape with its lens at the board centre; in the field body the board stands portrait (17.8 across, 21 tall) with the camera 6.95 mm below its centre, so every barrel missed its cell by 7 mm and the virtual sensors photographed from the board centre. The proxy now draws the lens at the instance's optical offset, `sensorPoses()` puts each eye at the lens, and the profile's envelope is the portrait one. The 1/4-20 light stud (measured: 25 mm, 18 mm base) is placed from the CAD datums and carries an external constant light whose envelope is PROVISIONAL until the unit is measured; it is now the flash emitter the virtual sensors see, with a TOP LIGHT mode in STAGE - OFF, FLASH (fires for a capture the device asks a flash for), CONSTANT (on for every preview and capture, the video light that is fitted).
- `kino.hardware-profile` instances gain an optional `opticalCenterConfidence` (a source kind: OFFICIAL_CAD, MEASURED, ...). Schema version unchanged: absent means what it meant before, PROVISIONAL. Studio's bench worksheet keys "measure the optical centres" on it instead of on the offsets being zero, because the CAD-derived offsets are non-zero and still not a measurement.
- **KINO Twin is the field body.** The 3D twin used to be a provisional 126 x 80 x 36 acrylic-and-skeleton box with the boards guessed inside it; the released camera body (ECN-0004) is 131 x 90 x 65.5 with two chassis halves, a face shell, a sliding lens cover and a rear door. The CAD generator now writes those six shells assembled (`hardware/cad/KINO_FIELD_BODY/twin/`) and a datum manifest, the Twin loads the shells as Tier A meshes straight from the release folder, and `npm run twin:body:bake` places the P4 module, the four camera stations, the hub board and the shutter switch from the datums into `d4-v1.json` - the profile is derived from the CAD, not typed. Two consequences worth reading twice: camera 1 is now at +X (the CAD puts the shutter at high body-X, the photographer's right, so camera 1 is on the photographer's left), and the battery, fuse, BMS, SW6106, speaker and bulk capacitor are no longer placed - the field body is a USB-C powered fixture with no bay for them; they stay in the BOM and the power model. The LENS view reads camera 2's lens from the profile instead of a constant.
- **KINO Twin's screen is the camera's own firmware.** The rear display used to be a TypeScript sketch of the 0.4.0 viewfinder; the camera had since grown a launcher, SHOOT, LOOK, GALLERY, PHOTO, ROLL, SETTINGS and POWER, and a Twin next to a camera showed a different product. `firmware/p4/twin_ui` now compiles the P4's `ui.c` to WebAssembly the way `host_preview` compiles it natively - the file is #included, nothing in it knows - and the Twin steps its real loop, feeds it the simulated device's state, hands it the touch point and plays back every frame it presents at the virtual time it was presented. Tap the glass in the 3D view or the SCREEN panel; a setting written on the body reaches the mock's config store, the shutter tile runs the capture pipeline, DELETE deletes, FAVOURITE stars, RESTART reboots. The committed `kino-ui.wasm` carries placeholder menu glyphs, because the menu's Windows 98 artwork is Microsoft's (#134, `THIRD_PARTY_NOTICES.md`); `npm run twin:ui:bake -- --w98` builds the private variant with the real artwork into `apps/twin/public/` (gitignored), which the Twin prefers when present. One firmware refactor made this possible and is behaviour-preserving: `ui_task()`'s loop body is `ui_pass()`, returning the sleep it used to take, and the task is `for (;;) vTaskDelay(ui_pass())`. All 59 `host_preview` renders are byte-identical before and after.
- **The Twin's current-firmware profiles report the current firmware.** `d4-settings-0-4-9` covers every release from 0.4.9 to today's `firmware/VERSION` and was pinned to report `0.4.9`; it and the SIMULATED FUTURE profile now report `0.4.56`, which is what a body flashed with today's build answers. Bump alongside `firmware/VERSION`.
- **The nine-track audit, and what it fixed.** A read-only sweep of the whole platform - API, worker, both web apps, the P4 and camera-node firmware, the KDP core, the contracts and the CI gates - found 84 items; this is the determinate half of them. The one that had been losing data since the first photograph: the camera wrote its active look into `kino.capture` as `recipeIds` while the schema and the API read `look`, and because that document is a passthrough schema it parsed clean every time, so `captures.look` was NULL for every capture ever taken and the guest app printed "KINO standard" over a photograph shot with `party-neg`. `firmware-contract/README.md` (D1) predicted it in those words - "a data-loss bug that validation cannot catch for you" - and the rule was crossed anyway; the document now carries both, because `recipeIds` is what the body's own MEDIA_LIST reads. Two more that could lose a photograph: a capture could be marked `ready` while an asset was still pending, because the recompute read assets and jobs on two connections and wrote unguarded, and `ready` is settled so convergence never revisited it - both reads and the write are one transaction now and the write carries the status it decided on in its WHERE clause; and a job's `queued` row was never retired on success, so the partial unique index that makes a second capture-complete a no-op also blocked every re-render, which meant a frame arriving after `complete` was baked out of the photograph permanently and both documented recovery paths were silent no-ops. Two security fixes: the host-log buffer clamped its copy length against the destination and never against the 192-byte source, so any ESP-Hosted line over 191 characters copied up to 5.9 kB of adjacent stack into a buffer `GET_LOGS` serves; and the production TLS switch the source told you to set did not exist in any build file, so every image accepted an `http://` API base out of NVS and put the device token on the air - it is plumbed now and fails secure, an image has to ask for cleartext with `-DKINO_ALLOW_HTTP_API_BASE=1` and CMake says so while it builds. The host dashboard's thumbnails could not authenticate at all: tile URLs were built as bare strings with no bearer, so every hidden or trashed tile 404'd and every tile on a PIN roll 401'd - the exact photographs the moderation grid exists to show. Upload completion no longer holds a row lock across two S3 round trips and a full sha256 re-stream on a ten-connection pool; the API has an error handler, so record ids stop reaching clients in 500 bodies and every error answers one envelope; Redis roll streams expire; the render endpoint and four unmetered host routes have their own budgets. Firmware: a camera abandoned at its capture timeout is released rather than left holding a frame mid-encode, which is the state that made a camera read offline on the next capture; the KDP decoder stops memmoving its whole buffer onto itself on every partial read, which was 8.5x amplification and ~5 MB of PSRAM traffic per four-camera set generated inside the window the validation record blames for tail loss; it counts one resync per discarded frame the way the normative decoder does, so every link-health figure in the bench record stops reading 2x pessimistic; the CRC table is `static const` rather than lazily built behind an unsynchronised flag; and the card-yield mismatch that charged a correct yield to the shutter as a failed upload attempt is gone, replaced by an out-parameter rather than two string literals that had to agree. Records: `infra/.env.staging.example` was missing the provisioning token that `docker-compose.prod.yml` refuses to start without, so the documented staging bring-up ended in a hard refusal; the device upload limit was documented as 60/minute in four places against a real 120/minute per route - 24 captures a minute, not four - and two reference load runs were sized off the wrong figure; the contract called two closed enums free strings, so a document its own prose endorsed would throw at parse time; and the host guide marked six shipped features "unverified", including restore, which told a host a recoverable photograph was gone. `version:check` now refuses a version that goes backwards, checks the migration journal for a file per entry and contiguous indices, and derives its workspace set from the root `package.json` so a new workspace cannot be silently unchecked - the monotonicity gate caught a real regression on its first run. 1,182 tests green across six workspaces (api 348, studio 301, roll-web 224, worker 132, schemas 95, kdp 82) and 6,246 firmware host checks across fifteen suites. Held for the bench, because they change measured-good behaviour on evidence the audit itself called insufficient: the L2 cache split, the per-channel UART receive ring size, the UHCI DMA migration, execute-in-place from PSRAM, the chunk-size raise, task stacks in PSRAM, and the UI redraw rework.

- **KINO Roll web + backend: the phone test, 2026-09-06.** Four defects from the first real phone session on a 1,900-capture roll and one from the desktop. (1) The capture page on a phone drew a quad as four ~150 px thumbnails in the top-left corner with the look floating beside them: the hero was a row flexbox and the grid, the look and the chip were three of its items. One child now, a column, the quad edge to edge at each frame's own ratio from the asset row, the look a caption row under it; landscape and desktop cap the block by height. (2) "Image quality is horrid": the hero could fall back to the 480 px feed tile and the feed tile itself was the camera's 288 px THUMB.JPG, because a device-uploaded `thumb` suppressed the worker's `generate-thumbnail`. The hero now uses `enhanced-still` → `kino-still` → the middle original and never a thumb; the worker always makes the thumb (720 px, q82, was 480 px q70) and upserts it over the device's placeholder row; the feed tile carries `srcset` so a 3× phone takes the 1280 px still. (3) Order: the feed and its cursor page on `(captured_at, id)` instead of upload time, so a camera that spent an evening offline no longer lands two hundred old shots on top of the party; live arrivals are filed by shutter time too. New index `captures_roll_captured`, migration 0012. (4) A way to clear the roll: `POST /api/host/rolls/:rollId/clear` trashes every live capture in one statement (same `deleted_at` the single delete sets, same 7-day purge), writes one audit row per capture plus `roll.cleared`, emits ONE `roll.cleared` event; the dashboard's Danger panel requires the roll code typed back. (5) On a desktop the whole feed sat in the left third of the page at 159 px a tile: a stale `.k-stream` grid rule from before the virtualised rows made each row one cell of a three-column grid. Removed; a fourth column at 1600 px. Tests: roll-web 145, API 292, worker 102.

- **Release closure, 2026-09-05.** C6 reset resume re-proven on 0.4.43 (two cycles, +17 s and +18 s to IP_READY, same P4 session, capture during recovery, pending upload drained by itself); the recovery reserve is not re-armed after 3.5 h of uptime (largest DMA block 15 KB) and is flagged as a #162 watch item, not redesigned. The host preview renderer builds again (its `upload_queue_enqueue` stub had drifted) and its renders of the 0.4.43 ROLL and STORAGE screens were checked. `infra/README.md` gains a pre-deploy checklist and states plainly that `deploy.ps1 backup` is PostgreSQL only and that no object-storage backup runs on the Windows host until `backup.sh` is scheduled. Operator decision recorded: the Windows 98 icons stay for private builds (#134). Remaining gates are operator gates: destructive delete tests on an expendable card, the panel glance, mobile PWA, production deployment and its E2E. `firmware/HARDWARE_VALIDATION.md`.

- **KINO Roll web: a capture is shown by camera, not by position, and a guest who installs the app lands somewhere.** Frame labels, the frame strip and the playhead now read `frameIndex` (the 1-based camera number) so a sparse capture from cameras 1, 3 and 4 says CAM 1 / CAM 3 / CAM 4 and matches the `cam-NN` download names; the feed's four bars are one per camera slot with the missing one dark, and `capture.status` is finally read: `partial` shows "3 OF 4", `failed` shows FAILED and mounts no player. A landing page at `/` takes a six-character Roll code (normalised to the slug alphabet) and remembers the last Roll; the PWA `start_url` points at it instead of a 404. An error boundary wraps the routes, feed pages drop a malformed capture instead of blanking the gallery, every image has an "Image unavailable" fallback with a one-shot retry on the detail page, the grid no longer preloads full-resolution originals before the bake lands, `WigglePlayer` takes the capture's `direction` (the saved file and the live player could run opposite ways) and renders one frame as a still instead of throwing, the display page passes fps/loop/direction like the other callers, a load failure shows "Could not reach the roll" with Retry and an offline banner follows `navigator.onLine`, and an archived Roll says so. roll-web tests 94 -> 127.

- **KINO Roll backend: statuses that settle, jobs that end, and a sweeper for the row that pinned a capture in `processing`.** A render enqueued lazily from the guest or host routes now recomputes the capture status (the trap `uploads.ts` warned about and both sites fell into); a worker job whose capture row is gone is dropped with one warning instead of failing to record its own failure five times (the dev log showed exactly this for `render-social-formats`); the gallery still is the lower-median stored frame by camera number, so a sparse capture no longer switches viewpoint; a five-minute sweeper re-submits `queued` processing rows with no live BullMQ job (audit API-14, the "stuck in processing" cause when a submit failed after the row committed); device status and current-roll reads carry a 120/min limit; the guest Roll read gets the same ten-misses-then-lock treatment as device join, so a 29.7-bit slug is not an open oracle; incomplete multipart uploads are expired by MinIO's own stale-upload sweep (24 h / 6 h, pinned in both compose files - the pinned release rejects an abort-only lifecycle rule, verified). worker tests 90 -> 102; api 289 tests, of which five in `uploads.test.ts` fail only while a dev worker is consuming the shared queue.

- **V2 hardware accessibility audit: FSIN is not on the Sense board, PWDN and RESET are strapped through 10 k and reachable only at fine pitch or through an FPC adapter.** Documentation only; nothing driven, written or soldered. From the official Seeed v1.0 expansion schematic: the 24-pin camera connector carries RESET on pin 6 (10 k to 3.3 V) and PWDN on pin 8 (10 k to GND), neither crossing the board-to-board connector, which is the physical reason for `pin_pwdn = -1` / `pin_reset = -1`; no FSIN or STROBE net exists, and pin 1 is the only floating pad a module could carry FSIN on. The OV3660 datasheet gives FSIN register bits (0x3835, 0x3836, 0x3016[2], 0x3019[2]) and no timing semantics; its v1.2 revision removed the frame-synchronisation feature claim. Hardware standby via PWDN is documented to reset counters and keep registers; 3.3 V drive on the 2.8 V-domain pads is inside the VDD-IO + 1 V absolute maximum. Classification PATH F (module-side FSIN routing unknown); next gate ACCESS-1, a 24-pin FPC pass-through adapter on one camera to measure pins 1, 6, 8 idle. `firmware/SYNC_HARDWARE_ACCESS.md` (#165).

- **V2-A: the sensor restart primitive is NOT PROVEN, and the audit found a better mechanism the project did not know about.** No code changed and nothing was written to any sensor. Against the OV3660 datasheet (PRELIMINARY SPECIFICATION v1.3), `0x3008` is confirmed as SYSTEM CTROL0 with bit 7 software reset and bit 6 software power down, default **0x02** - so standby entry and exit are `0x42` and `0x02`, not `0x40` and `0x00`. Software standby is documented to be cheap and to keep configuration ("all register content is maintained"), but it is **not** documented to reset the frame timing counters, and the datasheet attributes counter reset only to *hardware* standby ("the internal device clock is halted and all internal counters are reset"). Re-phasing is the entire purpose of the primitive, so its central property is unsupported and the register was left alone. The same audit corrects a figure this study had been quoting: a software reset needs **~2 ms** settling per the datasheet, and the >200 ms is the esp32-camera driver's own two 100 ms delays plus a full default-register reload. **The finding that matters: the OV3660 has a dedicated frame-sync input.** Pin E3 `FSIN`, an input out of reset (`0x3016` default 0x22 leaves the FSIN-output bit clear), enabled by `0x3835[0]` with polarity in `0x3835[1]`, and drivable as an output via `0x3016[2]` plus `0x3836`'s output width - so master/slave frame sync between sensors is a documented configuration. That is purpose-built for what V2 needs, it keeps configuration, and it takes the SCCB write out of the critical path: the write becomes setup and the already-proven `SYNC_OUT` edge (1000/1000 accepted) carries the timing. The blocking question is now hardware and not firmware - whether FSIN is routed to the camera module's FPC, which the standard 24-pin DVP set does not normally carry and neither this repository's DVP record nor Seeed's published material resolves. Also measured rather than estimated: SCCB runs at **100 kHz** (`CONFIG_SCCB_CLK_FREQ=100000` in the node's resolved sdkconfig, range allows 400 kHz), a 16-bit-addressed four-byte register write is about **380 us**, and each node drives its own I2C controller so four writes are genuinely parallel rather than serialised through the P4. V2-B not run, as it is gated on V2-A. `firmware/SYNC_FEASIBILITY.md`.

- **The sensors were never drifting: they are rate-locked to 1.6 ppm, and that changes the V2 plan.** No code changed. The 69 us frame-period spread this study has carried since 0.4.30 - and the three-minute phase-decay conclusion built on it - was measured in the finder-live condition, where the returned frame is chosen by preview-pump timing rather than by the sensor's phase. Measuring the sensors against each other instead, as the difference of their `syncToFrameUs` against the one shared edge, over the 0.4.31 finder-idle run of 99 shutters and 17.6 minutes: **relative rate 0.4 to 1.6 ppm**, split halves agreeing within 0.4 ppm, an outlier-proof median-of-pairwise-slopes estimator reproducing least squares to two decimals, and a worst residual of 243 us against a 112,387 us period. A one-time phase alignment therefore holds 2 ms for about 21 minutes and 10 ms for about 1.7 hours, not three minutes. So **phase alignment is a one-shot problem, not a control problem** - which is also why every rejected idea here (phase-aware scheduling, static delays, VTS chasing, a shutter-sampled loop) had the wrong shape: they tracked something that does not move. The V2 recommendation is no longer a shared XCLK: it is to align once on the `SYNC_OUT` edge that is already wired and already proven at 1000/1000, by arming all four nodes and letting each node's existing sync ISR trigger the sensor restart, which replaces four independent UART commands (212 us median, 412 us worst) with an ISR and an SCCB write. Shared XCLK becomes necessary only if relative rate rises materially when warm or if the restart proves non-deterministic; on the XIAO Sense it would also mean contending with a module-internal XCLK net, since the 16 MHz clock is LEDC-generated on GPIO10 inside the module and no XCLK input is exposed. Recorded with the OV3660 controls that actually exist in the pinned driver - `SYSTEM_CTROL0` 0x3008 bit 7 software reset, `set_reg`/`get_reg` exposed so a node needs no fork, and **no hardware reset or power-down line at all** (`pin_reset = -1`, `pin_pwdn = -1`) - and with the standby bit marked as inference pending the datasheet. Also documented: **freshness currently depends on the viewfinder**, because one `discard_queued()` is one frame short of a guarantee and the preview pump supplies the missing drain, so 98% of finder-idle photographs predate their own shutter edge; the fix belongs in the node's capture predicate, not in a new product state. `firmware/SYNC_FEASIBILITY.md`, `firmware/CAM3_SWAP_MATRIX.md`. Nothing in the sync path ships.

- **CAM3 measured rather than suspected, and it is not a streaming outlier.** 10 minutes of live viewfinder with no captures: about 8,000 preview frames per camera and **zero** shortRead, oversize, noLink, decode, timeout, retry and CRC on all four, cam3 within 1.5% of cam1 on frame count. Then 100 grouped captures: 100 of 100 accepted, 99 sets of four, and cam3 the worst channel but only mildly - 4 shortReads and 8 timeouts against 0-1 and 2-4 - with no CRC error anywhere, no node reset, and every failure recovered by a retry. The lifetime figure that started the hunt (297 against 53-94) is contaminated by a bench error of ours and is withdrawn: opening the four node USB consoles to watch for a dropout reset three nodes, because the XIAO's native USB CDC re-straps on open, and the resulting link storm is in that count. Root cause **not isolated** - separating the P4 UART channel from the XIAO, the module, the ribbon and the connector needs physical swaps one variable at a time, and `firmware/CAM3_SWAP_MATRIX.md` gives the procedure with one command per configuration. `firmware/HARDWARE_VALIDATION.md`.

- **The viewfinder is the synchronization variable, measured at 100 shutters a side.** No code changed: 0.4.37's sync path is 0.4.31's, on camnode 0.4.31, and this is the run that makes the earlier two comparable. With the finder live, **every one of 397 usable frames started after the shutter's own edge** and the frame-start spread across a set is 42.0 ms median / 102.8 ms p95; with it idle, the command lands in 2.1 ms instead of 17.1 ms but **385 of 393 frames started before the edge** - the driver hands back the buffer it already had, so the photograph predates the shutter - and the spread doubles to 85.9 ms. 0.4.37 finder-live reproduces 0.4.30 finder-live (42.0 against 46.6 ms median, 0% stale in both, 17.1 against 18.6 ms to the command), so the session's queue work did not perturb the sync path and the 0.4.31 figures were a different experiment rather than a regression. Dispatch spread is 212 us median and 412 us max against a 100-400 us target, which is 0.2-0.4% of the 112.4 ms frame period, while sensor phase is 37-91% of it: the dominant term was never the command side. Verdict **SYNC BASELINE MEASURED**, and the `gradeSkew()` exposure bands stay unreachable on free-running OV3660s. `firmware/SYNC_FEASIBILITY.md` now records the architecture as SOFTWARE_DISPATCH_ONLY with the three terms sized, and the design-only conclusion on registers: the four sensors' frame periods differ by 69 us, so any one-time alignment decays by a full period in about three minutes, `VTS` phase-chasing should not be built (its error signal arrives only when the user presses the shutter), and the step that attacks the dominant term is one oscillator feeding four XCLK pins - a V2 hardware decision. Nothing in the sync path ships. `firmware/HARDWARE_VALIDATION.md`.

- **A four-camera capture no longer loses its largest frame to a retry stall.** The four-camera transport bench (2026-09-02, #132) found 6 of 20 grouped sets short a frame: under four concurrent transfers the RX FIFO drops the tail of a READ chunk near the 8192-byte boundary (the historical offset-8192 loss, no hardware flow control), and each loss waited out the full 1000 ms per-chunk timeout before a retry that then succeeded - enough 1000 ms stalls on cam2's ~458 KB frame to blow the 8000 ms whole-frame budget at 98%. `CHUNK_READ_TIMEOUT_MS` 1000 -> 400 (a healthy chunk arrives in ~120 ms, so a lost tail costs 400 ms to retry) and `XFER_BUDGET_MS` 8000 -> 12000 (room for the largest frame under four-way load), with a static assert tying them together. Nodes untouched; retry, CRC, mutexes, stacks and scheduler unchanged. Rerun: 20/20 complete, 0 lost frames. The offset-8192 tail loss is reproduced under load, not fixed - only made cheap to recover. (`firmware/HARDWARE_VALIDATION.md`, "One shutter, four frames".)

- **The bench capture command reaches all four camera channels.** `CAMERA_TEST` was the last cam1-only door: `run_capture()` now takes the channel and uses the per-channel link calls end to end, the stored frame is `C<n>.JPG` in its own TC folder, the reply names the cam it measured, and `CAMERA_LINK_STATS(_RESET)` lose the Milestone 1B gate and answer for the asked channel. Diagnostic surface only; the product capture path is untouched. With it, the basic four-camera hardware proof ran on the bench 2026-09-02: all four nodes individually and together, three matching checksums per frame, zero link errors (`firmware/HARDWARE_VALIDATION.md`, "Four nodes on four wires", #159).

  **Per-camera exposure and gain reach a sensor for the first time.** QUAD slots have carried `exposureBias` and `gain` since the config schema existed and every look has a capture block, and none of it went anywhere: the node link had commands for quality and resolution only, and `capture.c` sent neither slot nor look values. `NL_CMD_SENSOR` (`0x15`) is the node-link command that closes it — `{aeLevel, gainCeiling, denoise, sharpness, quality?}` out, `{ok, applied:{…}}` back, with the node clamping to the driver's ranges and reporting what it actually set. It is node link, not KDP: no KDP command, payload or capability changed, and a host written against 0.4.8 needs nothing. Before each capture the P4 builds one request per camera in a fixed order — mode defaults, then the active look's capture block, then the QUAD slot's `exposureBias` and `gain`, the per-camera control winning over the shared one. `exposureBias` is an EV in -2..+2 and `set_ae_level()` takes an integer -2..2, so the EV rounds to the nearest step and -1.5 EV and -1.4 EV reach the same sensor; `gain` maps `auto` to AGC untouched, `low` to a 4x gain ceiling and `high` to 32x. Both mappings are pure C and host-tested. `META.JSON` records the echoed values per frame under `sensor`, so a photograph says what the sensor was told rather than what the config held at some later moment; `quality` there is the sensor's 5..63 scale, not the 60..95 wire percentage, the D12 conversion happening before the link.

  A sensor apply that NACKs or times out is logged and the trigger goes out anyway, with `sensor` omitted for that frame — a missed photograph is the wrong price for a settings write. So an absent `sensor` block has two causes, older firmware or a refused apply, and neither means the frame is bad. What still does not happen: the rest of a look — contrast, saturation, temperature and the other grading fields — stays Studio's at import, no grading runs on the camera, and `colorMode: 'mono'` is still not applied on the body. The slot stores mono, `META.JSON` carries it, and the conversion happens at import; that one is a product decision still open, not an oversight. Contract D19 records the command, the merge order, the two mappings, the failure rule, `brightnessControl` and `body.name`. The node image is built from the same `firmware/VERSION`, so a camera node reports 0.4.9 too.

  The P4 gets its own partition table. `CONFIG_PARTITION_TABLE_SINGLE_APP_LARGE` gave a 24 KB NVS, one 1500 KB `factory` slot and no OTA, and left about 12 MB of the 16 MB part unaddressed; at 0.4.8 the radio image measured 1451 KB in that slot, 3 percent free, and the next radio feature did not fit. `firmware/p4/partitions.csv` replaces it with two 3 MB OTA slots sized for the radio image plus real growth, a 256 KB NVS, `otadata`, `phy_init`, a 64 KB coredump partition, and 9.6 MB left unallocated for a future on-device data partition. `ota_0` starts at 0x10000, where `factory` did, so an image built before this change still flashes and boots there. The panic handler now writes to the coredump partition (`CONFIG_ESP_COREDUMP_ENABLE_TO_FLASH`), which costs 21 KB on both images: default 864 KB (0xd8110), radio 1472 KB (0x1702b0) with the new table. The CI size guards are re-derived from the 3072 KB slot, 1200 KB and 1600 KB. Flashing the new table erases NVS - config, hwv rows, saved Wi-Fi networks and the Roll device credential - so no unit carries it yet; `firmware/README.md` has the sequence and what restores what.

  `SET_RECIPE` takes an optional `cam` — absent writes `wiggle.recipeId` as before, `cam1`..`cam4` write one quad slot, `all` writes all four and wiggle — and refuses an id that is on neither the factory nor the custom list, because a config naming a look the device does not have renders as the wrong picture at import rather than as an error. `GET_CAPABILITIES` grows `recipes` and turns `customSounds` true; both come off the same predicates the dispatcher gates on, so the flag and the handler cannot disagree. `recipes` is optional in `Capabilities`: firmware older than 0.4.8 omits it, and an absent flag means the commands NACK, not that the answer is unknown. `SOUND_END` adds one refusal the mock does not have — `BAD_FORMAT` for anything that is not 16 kHz mono 16-bit PCM — because the playback path has one sample rate and no converter, and a clip that fails there would otherwise fail at a shutter press instead of at upload. Limits are the mock's: eight clips, 128 KB each, 8192-byte chunks.

  What the camera still does not do is grade. No look's capture block reaches a sensor register; a look is stored, selected, carried in `META.JSON` and applied at import, exactly as before. Contract D17 drops from 27 unimplemented commands to 17, D18 records the `cam` field, `BAD_FORMAT`, the parity rule and the card paths, and Studio's conformance suite is 33 cases with `GET_RECIPES` passing and a new read-only `GET_SOUNDS` beside it.

  Found on the bench while proving it: **every KDP reply over about 4 KB had been silently lost since the first firmware.** `usb_link_write()` handed a whole frame to `usb_serial_jtag_write_bytes()`, which copies the request into the driver's 4096-byte TX ring as one item; an item larger than the ring can never fit, the call returned 0 at once, and the loop read that as "host gone" and dropped the frame. Everything under 4 KB worked, which is why `GET_HW_VALIDATION` at 3.8 KB answered and `GET_LOGS` never did - the trap in the bench notes that read "4 KiB frames time out". Writes go to the driver in 1024-byte slices now; `GET_LOGS` answers 14 KB on the wire and `GET_RECIPES` was the command that finally made it visible. The console log still shares that USB port, which is what a host decoder's `discardedBytes` are.

  So the built-in constant-current direct-flash assembly leaves D4-V1. A separate external flash module will be used later; it has no P4 pin in this revision and its interface is not chosen. `flashControl` stays `true` in `GET_CAPABILITIES` because the command surface exists, `flashHardware` stays `false` because no flash board is fitted, and no KDP surface changed. `BOARD_FLASH_EN` is `BOARD_GPIO_NONE`, the `_Static_assert` set follows, `HWV_FLASH_EN_GPIO28` stays in the registry as an append-only row that can no longer flip, and `buttons.c` earns `HWV_BTN_SHUTTER` on the first debounced press.

  The wiring is one part: a 6 × 6 × 4.3 mm tactile switch between JP1 pin 21 and GND on JP1 pin 6 or 16, with no external resistor and no capacitor. The P4's internal pull-up holds the pin high, the input is active low, and firmware does the 25 ms debounce and the 600 ms long press. On a meter against pin 6 the pin reads 3.3 V idle and 0 V held. Twelve header GPIOs still carry eleven signals: the four TX/RX pairs, `SYNC_OUT`, `CAM_PWR_EN` and `BTN_SHUTTER`. `BTN_FN` and the mode slide still have no pin and will not get one in this revision. ECN-0003.

  Six images to get there, each one measured: the deinit hung/panicked when an RPC had been sent into the dead slave first; in-place re-enumeration read every frame as ~979 KB because the component's byte counters reset only in its own deinit/init; the re-init then asserted on its 15,872 B SW_AGGR buffer because the P4's PSRAM heap carries no `MALLOC_CAP_DMA` and internal RAM was down to a 7 KiB largest block - so `kdp_server`'s two 16 KiB frame buffers moved to PSRAM and a **recovery reserve** of two 16 KiB internal DMA blocks is held from bring-up and freed the moment before re-init; finally lwip asserted `netif already added` until teardown also ran the netif's stop action. `GET_RUNTIME_STATS` gains `internalFreeKB`, `internalMinFreeKB`, `largestInternalDmaKB`. On the board: five consecutive recoveries without a reboot in 9.8-21.8 s (one 122.9 s, spent in the component's own deinit RPC timeouts), and ROLL-C test 3 passing end to end - `firmware/HARDWARE_VALIDATION.md`.

  **A photograph did not know its Roll.** `meta.c` wrote `rollId: null` into every META.JSON, the capture path never told the upload queue about a finished capture (only UPLOAD_ENQUEUE did, and it used whatever Roll was current), and boot reconciliation stamped the current Roll onto every committed capture that had no record. On the bench card that was 102 captures with `rollId null` and 34 UPLOAD.JSON records all naming a Roll their photographs were never taken on. Now `capture_report_t` carries the backend `rollId` snapshotted at the shutter, META writes it (string, or `null` when the camera was not on a Roll), a capture-done listener enqueues with that id, `upload_queue_enqueue()` reads the Roll from META and refuses a capture that has none (`ESP_ERR_INVALID_STATE`; UPLOAD_ENQUEUE answers `INVALID_STATE`), and reconciliation compares the record's Roll with META's: a disagreement, or a record for a photograph whose META names no Roll, is **retired** (parked `FAILED`, `last_error` "no Roll provenance: capture …, record …") rather than uploaded. The 34 stale records on the bench card were parked that way; their photographs are untouched. `rq_reconcile_action()` gained `RQ_REC_RETIRE`; MEDIA_READ may return `UPLOAD.JSON` so a bench can back a queue up before it is touched.

  **A job resumed after a reboot waited on the previous boot's clock.** `next_attempt_ms` is a deadline on the boot's monotonic clock and the record keeps it; after a reset the resumed `RETRY_WAIT` job sat until the new uptime passed the old number - 27 minutes on the bench (CAP_000186, boot-412 to boot-413) while the API had been back for three. `rq_job_boot_resume()` voids the deadline on the RESUME path of `upload_store_inspect()`; attempts are kept. Host suites: 2,501 checks (roll-queue 806, meta 125, store 100, net-report 98, kdp_core 75, and the rest unchanged).

  Two were critical. **DELETE did not delete.** `storage_capture_delete()` unlinked five names and `rmdir()`ed; every capture also writes `THUMB.JPG`, so the directory was never empty, the picture reappeared in the gallery with no metadata, and every aborted capture became a permanent "kept for inspection" orphan. The six names live in one table now, `STORAGE_CAPTURE_FILES`, read by the delete path and by the `MEDIA_*` allow-list so they cannot drift again. **Three of the six `MEDIA_*` handlers checked for `/` but not `..`**, while the other three checked both; `MEDIA_DELETE {"id":".."}` walked one level up and removed `/sdcard/KINO/C1..C4.JPG` and `META.JSON`. All six go through `pure_is_capture_dirname()`, the rule the network path already used.

  The rest, briefly. The TLS gate read a cached "clock untrusted" reason instead of the clock, so a clock set from Studio never released it and uploads idled for the whole boot; it asks `clock_trustworthy_for_tls()` now, and the hold release is one guarded operation instead of a read-then-write that could resurrect `IP_READY` after a disconnect. `net_link`'s state was written from four tasks and read from three with no lock; it has one, compiled out on the host so the tests still build. A dropped AP made the event task call `esp_wifi_connect()` from inside its own disconnect handler with no delay — a full-band scan loop; it is an `esp_timer` backoff, 1 s doubling to 30 s. `cam_probe` guarded twelve seconds of HELLOs with a try-lock sample and called it exclusion; it holds `capture_lock()` for the sweep. `ESP_ERROR_CHECK(camlink_init())` was the one abort in a boot written to degrade, and it fired before the USB recovery channel existed; it logs. The gallery read `META.JSON` into 1 KB when a two-frame document is ~1076 bytes, so every multi-camera capture would have rendered as a UUID with zero frames; 4 KB, with a host test that measures a four-frame document. The log-drain task blocked on the USB FIFO while holding the TX mutex; events use a 250 ms bounded write and count a drop rather than wedge the server. The soak test passed `jpegQuality` to the sensor unconverted, the D12 inversion again. The node's frame buffer was sized once at UXGA while QXGA was selectable, so a bright 2048×1536 JPEG over 384 000 bytes overflowed it; it is sized for QXGA. A capture could spend two 4 s `fb_get` timeouts on the node's only task against an 8 s host budget; the discard is gated on a queued frame and the host waits 12 s. `taskmon` published a slot before filling it and read the table unlocked, the use-after-free it was written to prevent; it publishes last and reads under the lock, and its registry was exactly full at 20. A stored `apiBase` over 47 characters was truncated into a different, still-valid URL and used with the bearer token; over-long values fall back to the compiled default. Physical buttons drove the renderer from the buttons task — dormant only because no pin is assigned; they post to a queue the UI task drains. Plus: NVS return codes on the capture counter, a short `fwrite` that left a truncated frame in a committed capture, a viewfinder hold shorter than the pump it waited for, control bytes from a server error body that could make `UPLOAD.JSON` unreadable forever, thirty-two parked uploads blocking every new one, a per-pixel divide in the viewfinder blit, and a click sound re-synthesised with two thousand `expf` calls and 33 KB of internal heap on every tap.

  Documents were wrong about the board. `firmware-contract/README.md` D13 said `FLASH_EN` had no GPIO (it is GPIO28, JP1 21) and gave `SYNC_OUT` two different pins in one section (GPIO32, JP1 19); `power.c` and `hardware_validation.h` still described the pre-ECN-0002 map, telling a reader the camera-rail switch was inert while the idle path drives it. `firmware/README.md` said nothing was bench-validated under a ledger with six validated rows. The three C6 documents disagreed on whether anything had run on a board; `HARDWARE_VALIDATION.md` owns that now and the prose points at it. The two recorded SHA-256s for the same `kino-c6.bin` still disagree, and that is written down as a disagreement for the next build to settle rather than a pick. `firmware/*/sdkconfig.debug` — referenced by name, untracked by omission — is committed. Host tests: `kdp_core` 46 → 75 checks with four new decoder cases (exact `KDP_MAX_PAYLOAD`, a decoder smaller than the frame, discard accounting, magic inside a payload); new cases for `net_link_clear_clock_hold`, `rq_sanitise_detail`, an escape-heavy `last_error` under the 768-byte record cap, and the META.JSON size bound.

  Two more from the same audit. **The camera node now discards the queued frame before a photograph.** With `fb_count=1` the driver captures one frame the moment the buffer is returned and then stalls, so every capture after the first was handed a frame exposed just after the previous release — M1 measured 1.8 s, 3.4 s and 27.0 s before the shutter. `camsensor_discard_queued()` empties the buffer first, which bounds the frame start to one frame period after the command (~112 ms at UXGA); preview sizes skip it so the viewfinder keeps its rate, and the reply carries the cost as `discardMs`. This is a correctness fix, not synchronisation: the four sensors still free-run, and `SYNC_FEASIBILITY.md` still scopes that work. And **both images now build at `-O2`**: every one of the 1005 objects in the P4 image was compiling at IDF's default `-Og`, CRC loops and JPEG staging included. `sdkconfig.debug` is the overlay that puts `-Og` back for a debugger; a `sdkconfig` generated before this change keeps `-Og` until regenerated, and `firmware/README.md` says so. The first `-O2` build failed on `-Werror=stringop-truncation` and `-Werror=format-truncation`, which only fire with optimisation on: every `strncpy(dst, src, sizeof dst - 1)` in `p4/main` is `strlcpy` now (26 sites, five of them in the soak job with no `- 1` at all, which is the unterminated copy the warning exists for), and the Wi-Fi credential slot key grew from 8 to 12 bytes so `"n%u"` cannot truncate. The `-- USING O3` line in the configure output is ESP-IDF's own message, not a project flag; every object was `-Og` while it printed.

- The JP1 header map was wrong for the second time, and this time the board settled it. The previous entry replaced the recorded pinout with the manufacturer table for the `JC-ESP32P4-M3-DEV` — a different carrier that shares the ESP32-P4 module and nothing else, our board being the `JC4880P443C-I-W`. Under that map `CAM1` opened UART1 on GPIO1/GPIO2, which reach no connector here, so the camera link could not work and its failure looked exactly like a wiring fault: a node that was known good in isolation answered nothing across 113 frames, a diagnostic node image logging every byte on its link UART saw none, and a TX-to-RX loopback across JP1 7–9 with the node removed entirely received zero bytes while a continuity check on the same jumper read a clean logic 1.

  So the header was measured instead of transcribed. The P4 drove all 47 of its usable GPIOs in turn — everything except the console pair and the mounted card's six — each announcing its own index in binary as a six-pulse sync followed by six bit windows, one pulse for a 0 and three for a 1, while a camera node watched a single wire and reported what it counted. JP1 pin 13 answered as GPIO49; JP1 pin 7 answered as GPIO52, predicted from the drawing before the run. The map is back to GPIO52/51/50/49/35/34/32/28 on the left and GPIO33/31/30/29 on the right, which is what the repository recorded originally and could not justify at the time.

  Twelve header GPIOs carry eleven signals, so `FLASH_EN` (GPIO28) and `CAM_PWR_EN` (GPIO31) have pins again and the I²C expander the previous entry proposed for M2 is unnecessary — which matters for M1 §37, where cutting the camera bank is the whole test. `GPIO35` on pin 15 is the one spare, and it stays unconnected: it is the ESP32-P4's serial-bootloader strap, so a pin tied low there is a board that comes up in the ROM downloader instead of the application, which at a bench reads as dead firmware rather than as a wiring mistake. `GPIO34` carries `CAM3_TX` and is a strapping pin too, safe only because we drive it and a node's UART RX is high impedance; a camera's TX must never land on either. Both rules are now compile-time assertions.

  The rule that came out of it, and the reason this is the last time: do not edit these numbers from a datasheet, a photo of another board, or a vendor page. Measure the pin. A manufacturer document is evidence about *a* board; only the bench is evidence about *this* board. ECN-0002.
- **The D4 header map was fiction, and the camera UARTs were on pins that do not exist.** The repository recorded the Guition carrier's 2x13 expansion header as carrying GPIO52/51/50/49/35/34/32/28 down the left and GPIO33/31/30/29 down the right, and put the four camera UARTs on 52/51, 50/49, 34/33 and 30/29. The rows came in on 2026-08-21 as "hardware data" with no manufacturer source, and because rows 1-3 and the C6 block were right the table passed review. The JC-ESP32P4-M3-DEV pinout exposes exactly eleven P4 GPIOs on JP1 — 1, 2, 3, 4, 5, 20, 32, 33, 45, 46, 47 — and not one of the eight recorded camera pins is on any connector. A node wired to the old instructions could not have answered, and the failure would have read as a bad ground.

  GPIO3 and GPIO5 are the touch and panel resets, both validated on hardware, so nine header pins are free for ten wanted signals. The map is now CAM1 GPIO1/2 (JP1 pins 7/9), CAM2 GPIO47/46 (10/12), CAM3 GPIO32/33 (19/21), CAM4 GPIO45/4 (14/13), SYNC_OUT GPIO20 (17); FLASH_EN and CAM_PWR_EN have no header pin and are `BOARD_GPIO_NONE`, which the firmware honours by not driving them rather than by driving pin -1. None of the nine is a strapping pin (34-38), USB (24-27), SD (39-44), the C6 SDIO bus (14-19, EN 54), I2C, I2S or LCD. `board_d4v1.h` is the one source of truth: `_Static_assert`s prove uniqueness, header membership and column parity at compile time, a host test (`test-pins`, 293 checks) repeats them and dumps the map, and a vitest in `@kino/hardware-profiles` parses the header and fails if `d4-v1.json` drifts from it. The profile's gpio keys are `CAM1_TX`…`CAM4_RX` now, each with its JP1 pin. Every camera row in the validation ledger stays UNVALIDATED; the one row that had been marked validated, `CAM_PWR_EN GPIO31`, is void, because GPIO31 goes nowhere. Hardware design package 0.1.1, ECN-0001. Do not wire a XIAO from any document that names GPIO52/51.

- **The C6 routing is established, and finding it turned up a defect that was waiting for the bench.** The mapping came from outside the repository — Guition documentation for this carrier — and was reconciled against two sources inside the toolchain before any pin was written down. `espressif/esp_hosted` 3.0.6 pins all six SDIO signals to exactly GPIO14-19 for a P4 host with a C6 coprocessor, with `min == max` so it is one value rather than a range, and `ESP_HOSTED_HOST_RESET_GPIO` defaults to 54 for every P4 target rather than one board. Independent support that this carrier follows the reference pinout: the microSD block is exactly the P4's slot-0 IOMUX pad set from the SoC headers, and that set was already validated here by a real 29820 MB mount. CLK and CMD cross over between the two chips, which looks like a transcription error and is not.
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

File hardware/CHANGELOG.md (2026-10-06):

# D4 hardware changelog

This log tracks released design-package versions inside the physical revision named in [`REVISION`](REVISION). Numbered engineering change notices carry the reason, evidence, and compatibility decision for each change.

## 0.1.8 - 2026-09-30

Status: carrier A0.2 power rework under the ODD JOBS standard; no fabrication release.

- Charging now runs with the camera off. The BQ25798 CE pin is pulled low (TI pin 13 must be driven high or low). The charge-arm transistor and its expander output are removed, and expander P1.3 reads charger STAT instead. R1110 (DNP) is a bring-up charge inhibit.
- Fitted the 103AT-2 thermistor network: 5.23k / 30.1k gives a 1–60 °C window within 0.7 °C across 1 % corners. An open or shorted NTC suspends charging.
- The fuel gauge was wired against TI's pin table. It now has a high-side 5 mΩ shunt: SRP (pin 8) on the pack side, SRN (pin 7) on the system side, and BAT (pin 6) Kelvin-connected to the pack. 4.4 A reads 22 mV against a ±25 mV range, so firmware must write CC Gain for 5 mΩ. Added the GPOUT pull-up TI requires, and C703 is now the specified 1 µF.
- Pack connector J1100 moved from the top edge to the bottom edge beside the charger. The fuse and shunt now form a 12 mm front chain, where the 5 A path previously ran 70 mm. Pin 3 is plain GND with a solid pad connection. The connector clears the H4 fastener exclusion.
- Boost inductor L1200 changed to Coilcraft XAL7070-222MEC. Its 19.6 A saturation current exceeds the TPS61288's 17.1 A maximum current limit, per TI 9.2.2.2. Compensation is now 20.5k / 3.3 nF per TI equations 12–13: crossover 8–16 kHz, phase margin above 68° across battery voltage, capacitance and inductor tolerance. Loop measurement is still required.
- Charger inductor L1100 now uses a footprint drawn from the TDK SPM6530 land pattern: 1.85 × 3.4 mm pads with a 3.7 mm gap. The draft footprint had pads under the body.
- Moved the PMID bulk capacitors from 13 mm away to beside the charger, tied down with two vias clear of the In2 SW1 crossover (TI 8.4.1). Routed USB VBUS from the connector to the PD input FET, and the charger SYS bank to the boost inductor on In2 (3 mm; 1 oz inner copper required). Neither path previously existed.
- USB CC protection is now 24 V (PESD24VL1BA), because 5 V parts would conduct if CC shorted to 9 V VBUS. Fuse F1100 is now a Bourns 7 A 1206 part. C1202 is now 4.7 µF, and power controller U1300 is now I grade.
- Every BOM line now names a manufacturer part verified against its datasheet (design/part_selection.json), except the battery pack. The boost footprint was checked against TI RQQ0011A land pattern 4225610/A.
- Checks: ERC 0, DRC 0, schematic parity 0, 896 pads matched. 182 connections remain unrouted. A Freerouting pass stalled at 212 unrouted items and 309 violations, so it was not imported. Remaining routing is by explicit script, one net class at a time.

Engineering change notice: [ECN-0007](changes/ECN-0007-four-xiao-carrier-proposal.md). Tracking: [issue #232](https://github.com/b5463/kino-d4/issues/232).

## 0.1.7 - 2026-09-30

Status: carrier A0.2 engineering rework; no fabrication release.

- Reworked switching-power placement and protected critical routing, reserving In1 for ground. Spread 250 footprints across both faces while retaining the four 22 mm camera positions and P4 mounting geometry.
- Removed duplicate and component-covering assembly references, aligned capacitor-bank labels and moved camera names outside the fitted modules. Printed functional text now uses 1.0 mm height / 0.15 mm stroke and clears component footprints. Assembly references remain on Fab layers; full prototype silkscreen reference coverage remains a release gate.
- Added an asymmetric 12-pad sense/test area and optional I2C/sync interface for an external flash driver. Corrected BQ25798 VAC2 to CHG_VBUS from TI's single-input reference configuration and replaced the below-threshold 453k/100k current divider with 30.1k/10k. Full-power USB policy remains unresolved.
- Regenerated the 14-sheet capture, with 897 schematic/PCB pads compared. Current DRC and routing evidence are in the A02 reports. Outstanding power policy, BOM, firmware and physical-stack findings still reject ordering.

Engineering change notice: [ECN-0007](changes/ECN-0007-four-xiao-carrier-proposal.md). Tracking: [issue #232](https://github.com/b5463/kino-d4/issues/232).

## 0.1.6 - 2026-09-29

Status: carrier A0.1 partial routing review rejected; no fabrication release.

- Placed 39 footprints on the front and 208 on the back, with four XIAOs at the enclosure's 22 mm pitch. Added partial routing and ground pours in a separate working PCB, preserving the original capture.
- Applied black-mask / white-silk / ENIG intent and checked nominal 0.13 mm mask gaps. Added the supplied ODD JOBS symbol and visible A0.1 draft identity. Fixed through-hole mask-layer transfer and documented purpose-based ground vias and thermal relief.
- Current DRC: four USB hole-clearance errors, one starved thermal, one dangling trace and 67 unconnected items. ERC remains zero; 878 schematic/PCB pads agree. These are not manufacturing acceptance results.
- Applied the user's ODD JOBS standard and recorded rejecting power-startup, switching-layout, ground-reference, BOM, firmware and mechanical findings in the [release review](pcb/kino-d4-carrier-a0/RELEASE-REVIEW.md). No order files released.

Engineering change notice: [ECN-0007](changes/ECN-0007-four-xiao-carrier-proposal.md). Tracking: [issue #232](https://github.com/b5463/kino-d4/issues/232).

## 0.1.5 - 2026-09-29

Status: additive engineering draft; the D4-V1 physical revision and existing PCB/CAD releases are unchanged.

- Added the [four-XIAO carrier A0](pcb/kino-d4-carrier-a0/README.md): 14-page component-level KiCad capture, 247 placed footprints, BOM candidates and pin/net export. Includes the confirmed motion/clock/current/temperature/cover/remote-shutter/haptic features and integrated power-circuit draft.
- The carrier now fits the P4's 117.01 x 69.41 mm overall module envelope and targets its four inner M2 inserts on 61.9 x 54.8 mm centres. Guition's schematic and mechanical drawing were consulted. The -9.3 mm pattern offset is drawing-derived and still awaits physical fit; a full-size mounting template is included. Oversized placement studies are superseded.
- Corrected XIAO socket row spacing to the official 15.24 mm, with 2.54 mm pitch. Checked the 14-pad assignment against Seeed's native board file.
- Exported schematic and PCB agree on 878 pads; the measured firmware header map matches and KiCad ERC has zero violations with documented supply declarations. DRC has 51 violations and 499 unconnected items. The board has no tracks or planes and is not released for fabrication.
- Power review, final footprints, battery/NTC/retention, connector and stack fit, circuit-aware placement/routing and carrier firmware remain unfinished. Added an explicitly draft `carrierA0` manifest artifact; physical acceptance stays false.

Engineering change notice: [ECN-0007](changes/ECN-0007-four-xiao-carrier-proposal.md). Tracking: [issue #232](https://github.com/b5463/kino-d4/issues/232).

## 0.1.4 - 2026-09-05

Added after the 0.1.4 body was released, additive and not superseding it:

- **`twin/`: the field body's six shells assembled, for KINO Twin** (`cad` artifact revision 3 â†’ 4, additive). `generate-field-body.mjs` writes the shells in body coordinates with the lens cover open plus `field-body-twin-datums.json` - camera axes, XIAO seats, the module bay and standoffs, the hub board's box, the shutter, every bounding box - and `promote.mjs` releases them through the same validation as the print set. The Twin loads the STLs as its Tier A meshes and bakes its hardware profile from the datums (`npm run twin:body:bake`), so the 3D twin is this camera and not the provisional acrylic-and-skeleton box that predated it.
- **`BOM.csv` revision 1 â†’ 2.** The five built-in flash rows (`flash-led`, `flash-driver`, `flash-heatsink`, `flash-thermal-pad`, `flash-diffuser`) are gone - ECN-0003 dropped the assembly from D4-V1 and the BOM still listed it - and the `enclosure` row (PETG skeleton + acrylic, a 126 x 80 x 36 envelope no released part matches) is the field body print set.
- A **second body**, `hardware/cad/KINO_RESIN_BODY/`, printed entirely through JLCPCB, in three parts that separate the camera from its case ([`ECN-0005`](changes/ECN-0005-resin-body-skeleton-and-shell.md)). A **black MJF nylon skeleton** carries everything - four camera modules on the 22.00 mm optical datum, four XIAOs, the P4 module on the 61.9 x 54.8 standoff pattern with the same conical sockets, the loom - and is the only part with a thread. A **clear SLA shell**, 2.0 mm walls, is four walls and the rear frame: nothing electrical touches it and no tolerance depends on it, so it can be reprinted in another colour without re-qualifying an optical dimension. A **black tough-SLA face** carries the four lens cells. `KINO_FIELD_BODY` is untouched and stays the released body. The `cad` artifact goes to revision 2, and to revision 3 with the bench corrections below.
- The face is black and the shell is clear for an optical reason and not a cosmetic one: light entering a transparent wall travels inside it and reaches whatever the interior can see, so clear lens cells would put that light on the sensors and the firmware's cover-closed test - all four cameras dark means the cover is down - would never read dark. An opaque face makes the cells the baffle and an opaque skeleton blocks the path from inside; two gates probe a light path beside each cell on each part.
- The skeleton is nylon and not resin because it is the part that gets dropped: four camera modules, a display module and a strap load hang off it and standard SLA resin is brittle. It costs accuracy - MJF holds about Â±0.3%, so the 66 mm span across the four cameras can be out by 0.2 mm where SLA would hold 0.1 - and that is the right trade, because the camera baseline is calibrated in software and a cracked camera mount is not calibrated out of anything. Nylon is also a thermoplastic, so it takes heat-set inserts where cured resin cannot: four M2.5 countersunk screws pass through the face into brass inserts in the skeleton, trapping the shell's front rim. No glue anywhere, no thread in any resin part, and the face comes off again - which the field body's permanently glued shell cannot do, and which is what created its "fit the sensor first or never" trap.
- MJF removes the support-free rule, so the skeleton deliberately has NO support-free gate: a powder bed has no supports to be free of, and carrying the field body's 45-degree rule would forbid geometry this process prints perfectly well. What it needs instead is powder escape and features coarse enough to resolve, which is why the pinch ribs are 0.5 mm proud against the field body's 0.20 - at 0.20 they would not have appeared.
- 125 x 82 x 65.5 mm against 131 x 90 x 65.5, and the saving is entirely in the walls: 2.0 mm of resin where PETG needed 6.0. Depth does not move relative to the field body, because depth is set by the electronics stack and not by any wall - a gate re-adds the stack every build and checks the module's PCB back lands on the same plane as the field body's, so the post and socket geometry transfers unchanged. Both were 64.6 x PCB back 45.6 until the camera's stand-off was derived rather than chosen (see the bench evidence below); both are now 65.5 x 46.5. Skeleton 34.54 cm^3, shell 50.13, face 30.55.
- 27 gates, 0 failures. There is NO independent scan on this package, and `promote.mjs` prints that absence every run rather than skipping it silently: the field body's `verify-release.mjs` arrived after 262 gates existed and immediately found an 870 mm^2 overhang and a blind spot every one of them had walked past, so until the equivalent exists here a pass is weaker evidence and a coupon comes before any trusted fit. Staged: the lens cover and its track, the door, the shutter, coupons, and that scan. The door zone at Z 60.6-64.6 is reserved and gated empty.
- Four defects the gates caught while building it, each a class of mistake rather than a one-off: a XIAO pad placed under the camera module and straight across the lens axis (the field body puts its pads above the module's top edge; copying the board's centreline instead put 3 mm of nylon in the light path); four insert pilots closed at both ends, which are four internal voids reported as four loose components of MINUS 56.6 mm^3 and four pockets of unsintered powder with no way out; pinch ribs unioned before their pocket was cut, so the cut left nothing standing; and bosses abutting the plate on a shared plane rather than embedded in it, leaving the union as five shells. Three of the four were found only because a gate reported WHERE rather than how many - the one-part gate now lists the loose pieces' own bounding boxes.

## Released in 0.1.4

Status: prototype. No physical unit has passed the acceptance sheet. The first body print failed on the bed.

**Bench evidence, 2026-09-08.** Several parts of this version have now been printed and five faults reported off them. All five are answered below.

1. **The P4 posts miss the standoffs, and they SPLAY** - too far apart or too close, not all shifted the same way. Answered below: the 65.5 x 58.2 was an OUTSIDE SPAN written into a centre-pitch field.
2. **Both slides move freely and feel gritty** - not tight. Answered below; the clearances were deliberately NOT touched.
3. **The camera cannot reach its lens hole on the wiggle rig**, because the ribbon is too short - about 7 mm - from where the XIAO sits. Answered below: the rig's board stand-off was a chosen 7.0 mm and the camera stands 7.4 mm off the board face, so the lens stopped about 2 mm short of its pocket.
4. **The shutter button does not account for the switch's attachment points, or for leads leaving at OPPOSITE ends.** Answered below.
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

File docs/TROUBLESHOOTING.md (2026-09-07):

# Troubleshooting KINO

Start with the failure you can see. Record the Studio version or commit, P4 firmware, four camera firmware versions, browser, operating system, and whether KINO Twin shows the same fault.

## Studio does not start

Run from the repository root with Node.js 22 or newer:

```bash
node --version
npm ci
npm run dev -w @kino/studio
```

If dependency installation fails, keep the first error. Later workspace errors are often fallout. Do not replace `npm ci` with an unrecorded dependency upgrade.

If the page is blank, check the browser console and the terminal running Vite. Confirm the local address matches the one printed by Vite.

## Web Serial is unavailable

Physical camera access needs desktop Chrome or Edge in a secure context. `localhost` qualifies. Firefox and Safari do not expose Web Serial.

A KINO Twin connection should still work. Serve Studio and Twin from one origin with `npm run preview:all`, open Twin at `/dev/twin/`, and press **CONNECT KINO TWIN** in Studio. If that connects, Studio is running and the remaining fault is in browser support, permissions, USB, or the camera.

## The camera is missing from the port picker

1. Use a known data-capable USB-C cable.
2. Connect directly instead of through an unpowered hub.
3. Close other Studio tabs, serial monitors, and IDE terminals that may own the port.
4. Check the operating system's device list for a new serial device.
5. Try the other exposed USB-C port only after confirming the board documentation.
6. Reboot the camera, then reopen the port picker.

A charging indicator proves power. It does not prove the cable carries data.

## The port opens, then handshake fails

Studio tolerates ESP32 ROM boot text and resynchronizes on the KDP frame magic. Persistent failure usually means the wrong port, incompatible firmware, damaged framing, or a camera that never reached application firmware.

Collect:

- the exact handshake message;
- P4 boot output;
- Studio logs with tokens and private media removed;
- the claimed KDP protocol range;
- whether KINO Twin connects.

If Studio says the product is not KINO, stop. Do not run firmware or destructive commands against an unidentified serial device.

## Protocol mismatch

The current KDP protocol version is defined in `packages/kdp/src/protocol/commands.ts`. Studio and firmware negotiate during HELLO. A mismatch needs a compatible build, not a different cable.

Check [`firmware-contract/README.md`](../firmware-contract/README.md) before changing command values or payloads. Unknown commands should produce `UNSUPPORTED_COMMAND`; they should not crash the device.

## The camera disconnects under load

Treat an unexpected live-session disconnect as a hardware or power fault until measured otherwise.

1. Repeat with flash disabled.
2. Repeat with one camera powered, then add cameras one at a time.
3. Measure the 5 V rail at the main unit and the farthest camera.
4. Record the lowest rail voltage during capture and parallel transfer.
5. Inspect the fuse, battery connector, SW6106 carrier, camera switches, and bulk capacitors.
6. Check whether the failure follows USB, battery, or both.

The fitted battery harness is limited to 3 A sustained. The BMS's larger advertised number does not override the harness.

## One camera is offline

Power down before moving a harness.

Check the affected channel in this order:

1. connector polarity and seating;
2. switched 5 V at the XIAO;
3. common ground;
4. P4 TX to XIAO RX crossover;
5. XIAO TX to P4 RX crossover;
6. MOSFET, NPN, diode, and resistor orientation;
7. camera firmware and sensor detection.

Swap the camera module with a known channel. If the fault follows the module, inspect that module. If it stays on the channel, inspect the switch and harness. Record the swap; do not diagnose by appearance alone.

## Gallery or microSD failures

Originals land on microSD before derivatives or uploads.

- Confirm the card is detected and reports free space.
- Test with an expendable known-good card.
- Preserve a failing card before formatting it.
- Check whether existing files read before writing new captures.
- Compare file size and SHA-256 when a transfer completes but the image is damaged.
- Retry a media read from a new offset after an interruption.

Do not treat a successful thumbnail as proof that all four originals are intact.
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

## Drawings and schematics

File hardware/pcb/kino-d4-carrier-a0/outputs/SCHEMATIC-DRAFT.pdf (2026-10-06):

1 | 2 | 3 | 4 | 5 | 6 | 7 | 8 | 9 | 10 | 11

AB

C

D

E

## FGH

AB

C

D

E

# FGH Date: 2026-09-30

Size: A2 | Rev: A0-DRAFT
KiCad E.D.A. 10.0.6 | Id: 1/14

# Title: KINO D4 - four-XIAO carrier A0

# File: KINO_D4_Carrier_A0.kicad_sch

# Sheet: /

# KINO

# ENGINEERING DRAFT - NOT FOR FABRICATION

## Camera 1 socket, power and signal isolation

File: 02_camera1.kicad_sch

## 5V boost and main load disconnect File: 12_boost.kicad_sch

## Cover, shutter and haptic interfaces

File: 09_controls.kicad_sch

## P4 header and isolated control bus

## File: 01_p4.kicad_sch Camera 3 socket, power and signal isolation

## File: 04_camera3.kicad_sch Four camera currents and battery fuel gauge

File: 07_monitoring.kicad_sch USB-C PD sink and protected input File: 10_usb_pd.kicad_sch Hardware on/off and user indication

File: 13_power_button.kicad_sch

## Camera enables and GPIO expansion

File: 06_control.kicad_sch

## Camera 2 socket, power and signal isolation

File: 03_camera2.kicad_sch

## 1S charger and battery entry

# File: 11_charger.kicad_sch Motion, clock and board temperature

File: 08_sensors.kicad_sch

## Camera 4 socket, power and signal isolation

File: 05_camera4.kicad_sch

PACK_FUSED

RTC_BACKUP | CAM1_SHUNT_OUT MB_3V3 | CAM2_SHUNT_OUT USB_VBUS CAM1_3V3 | CAM2_3V3 | CAM3_SHUNT_OUT CHG_VBUS CAM4_SHUNT_OUT | CAM3_3V3 | CAM4_3V3

# SYS_5V GND

ERC supply declarations: intended connector/regulator sources; see each symbol source note. Not a power-validation result.

Manual checks before ordering, bring-up tests and the release matrix: A02-RELEASE.md. READY FOR FABRICATION WITH SPECIFIC MANUAL CHECKS - see A02-RELEASE.md.

# KINO D4 / CARRIER A0.2

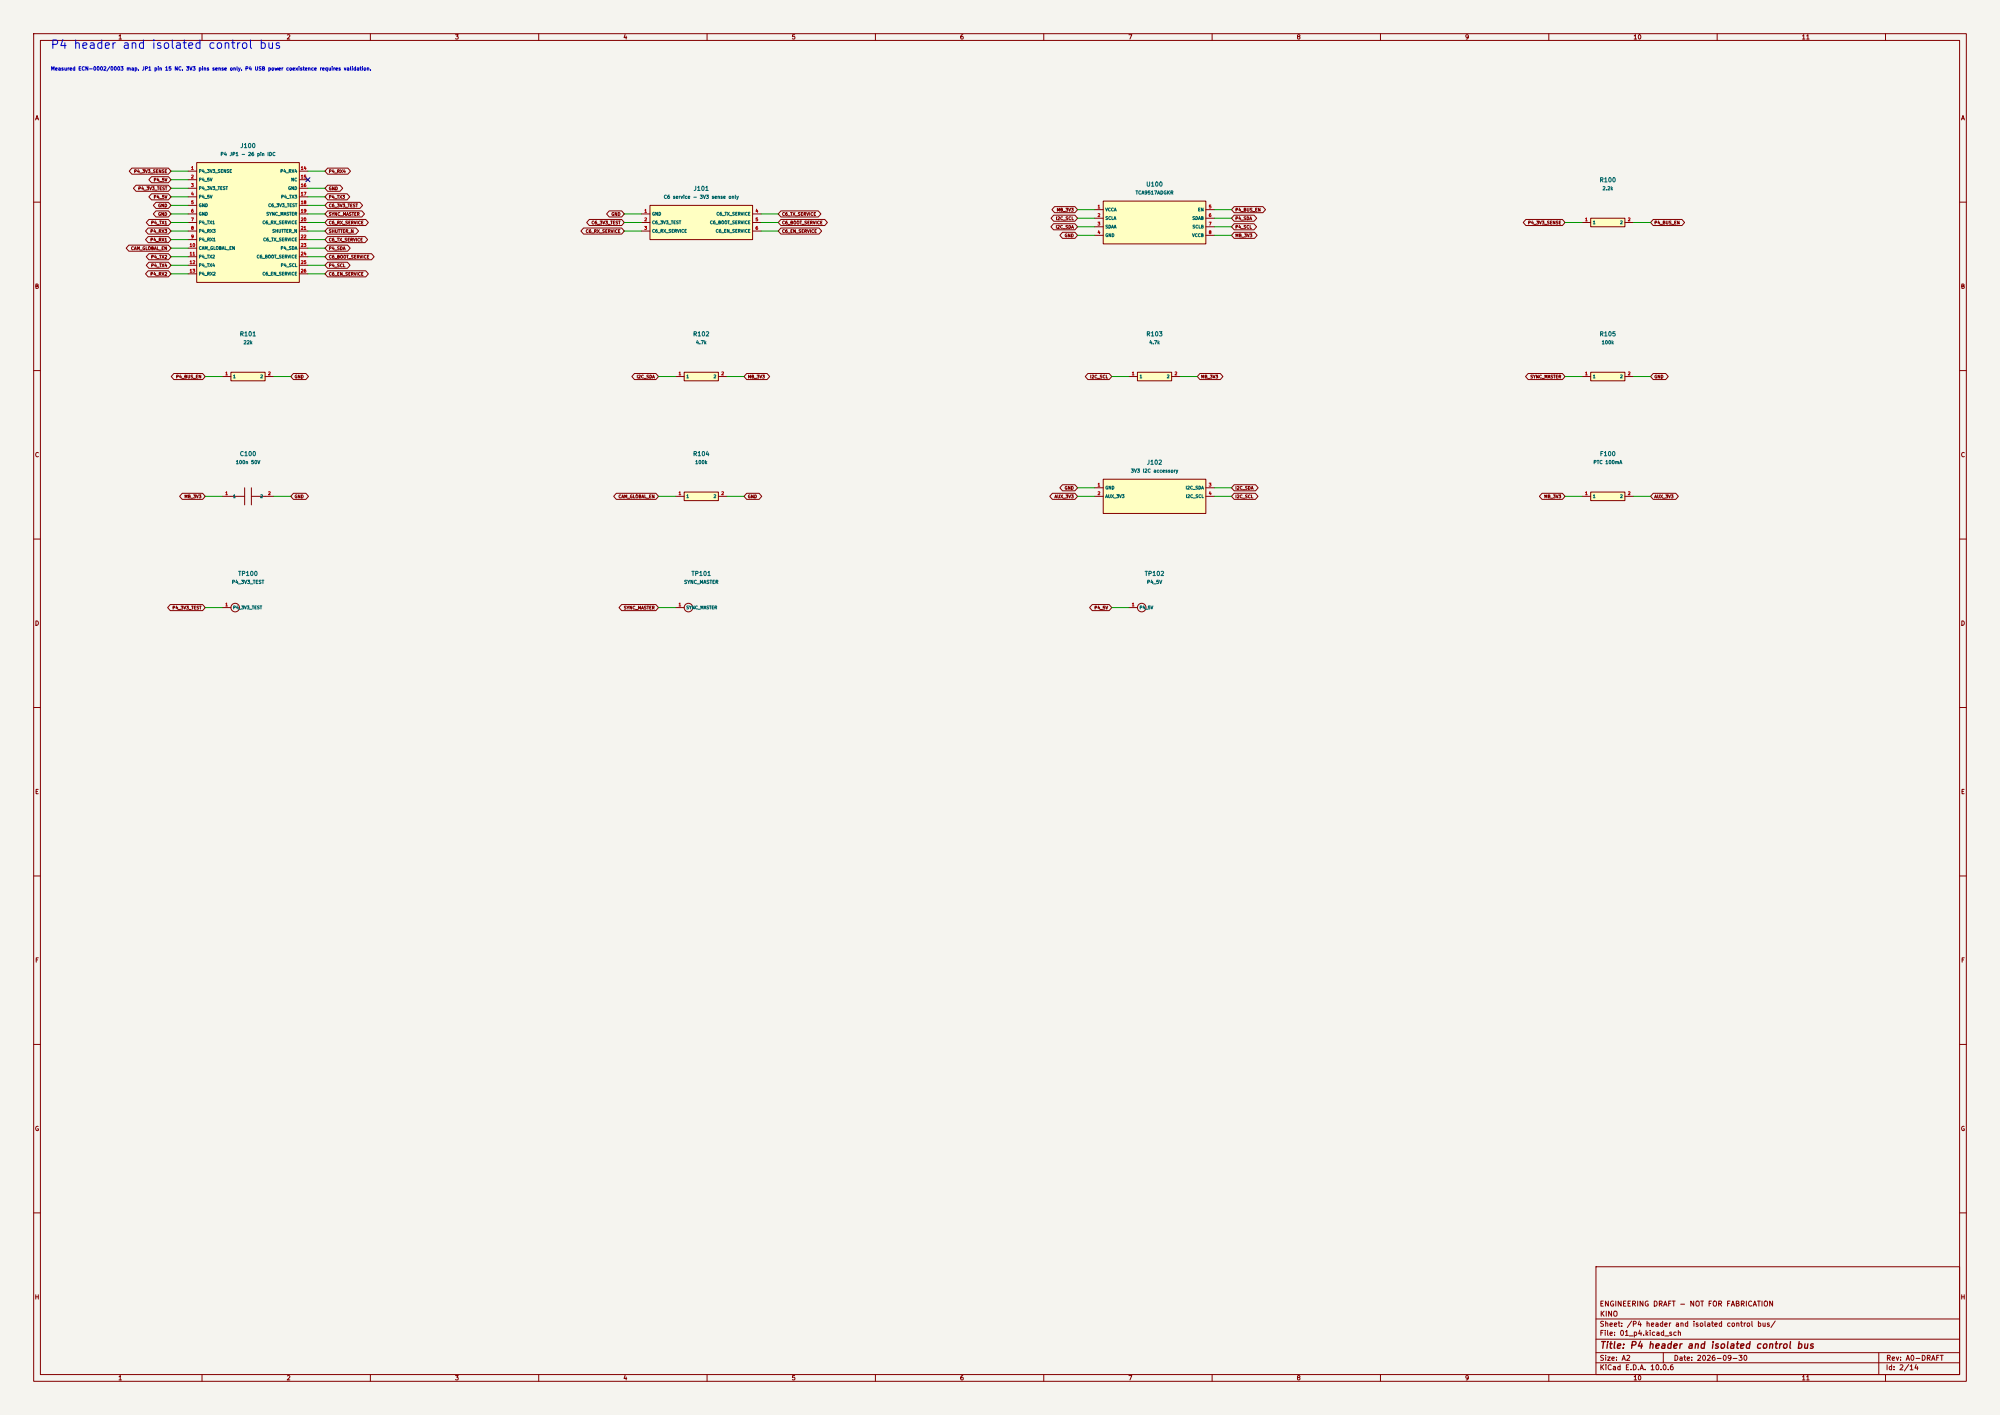
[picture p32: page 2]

I2C_SCL C6_EN_SERVICE C6_BOOT_SERVICE P4_RX4 Measured ECN-0002/0003 map. JP1 pin 15 NC. 3V3 pins sense only. P4 USB power coexistence requires validation. P4 header and isolated control bus

Sheet: /P4 header and isolated control bus/
File: 01_p4.kicad_sch
Title: P4 header and isolated control bus

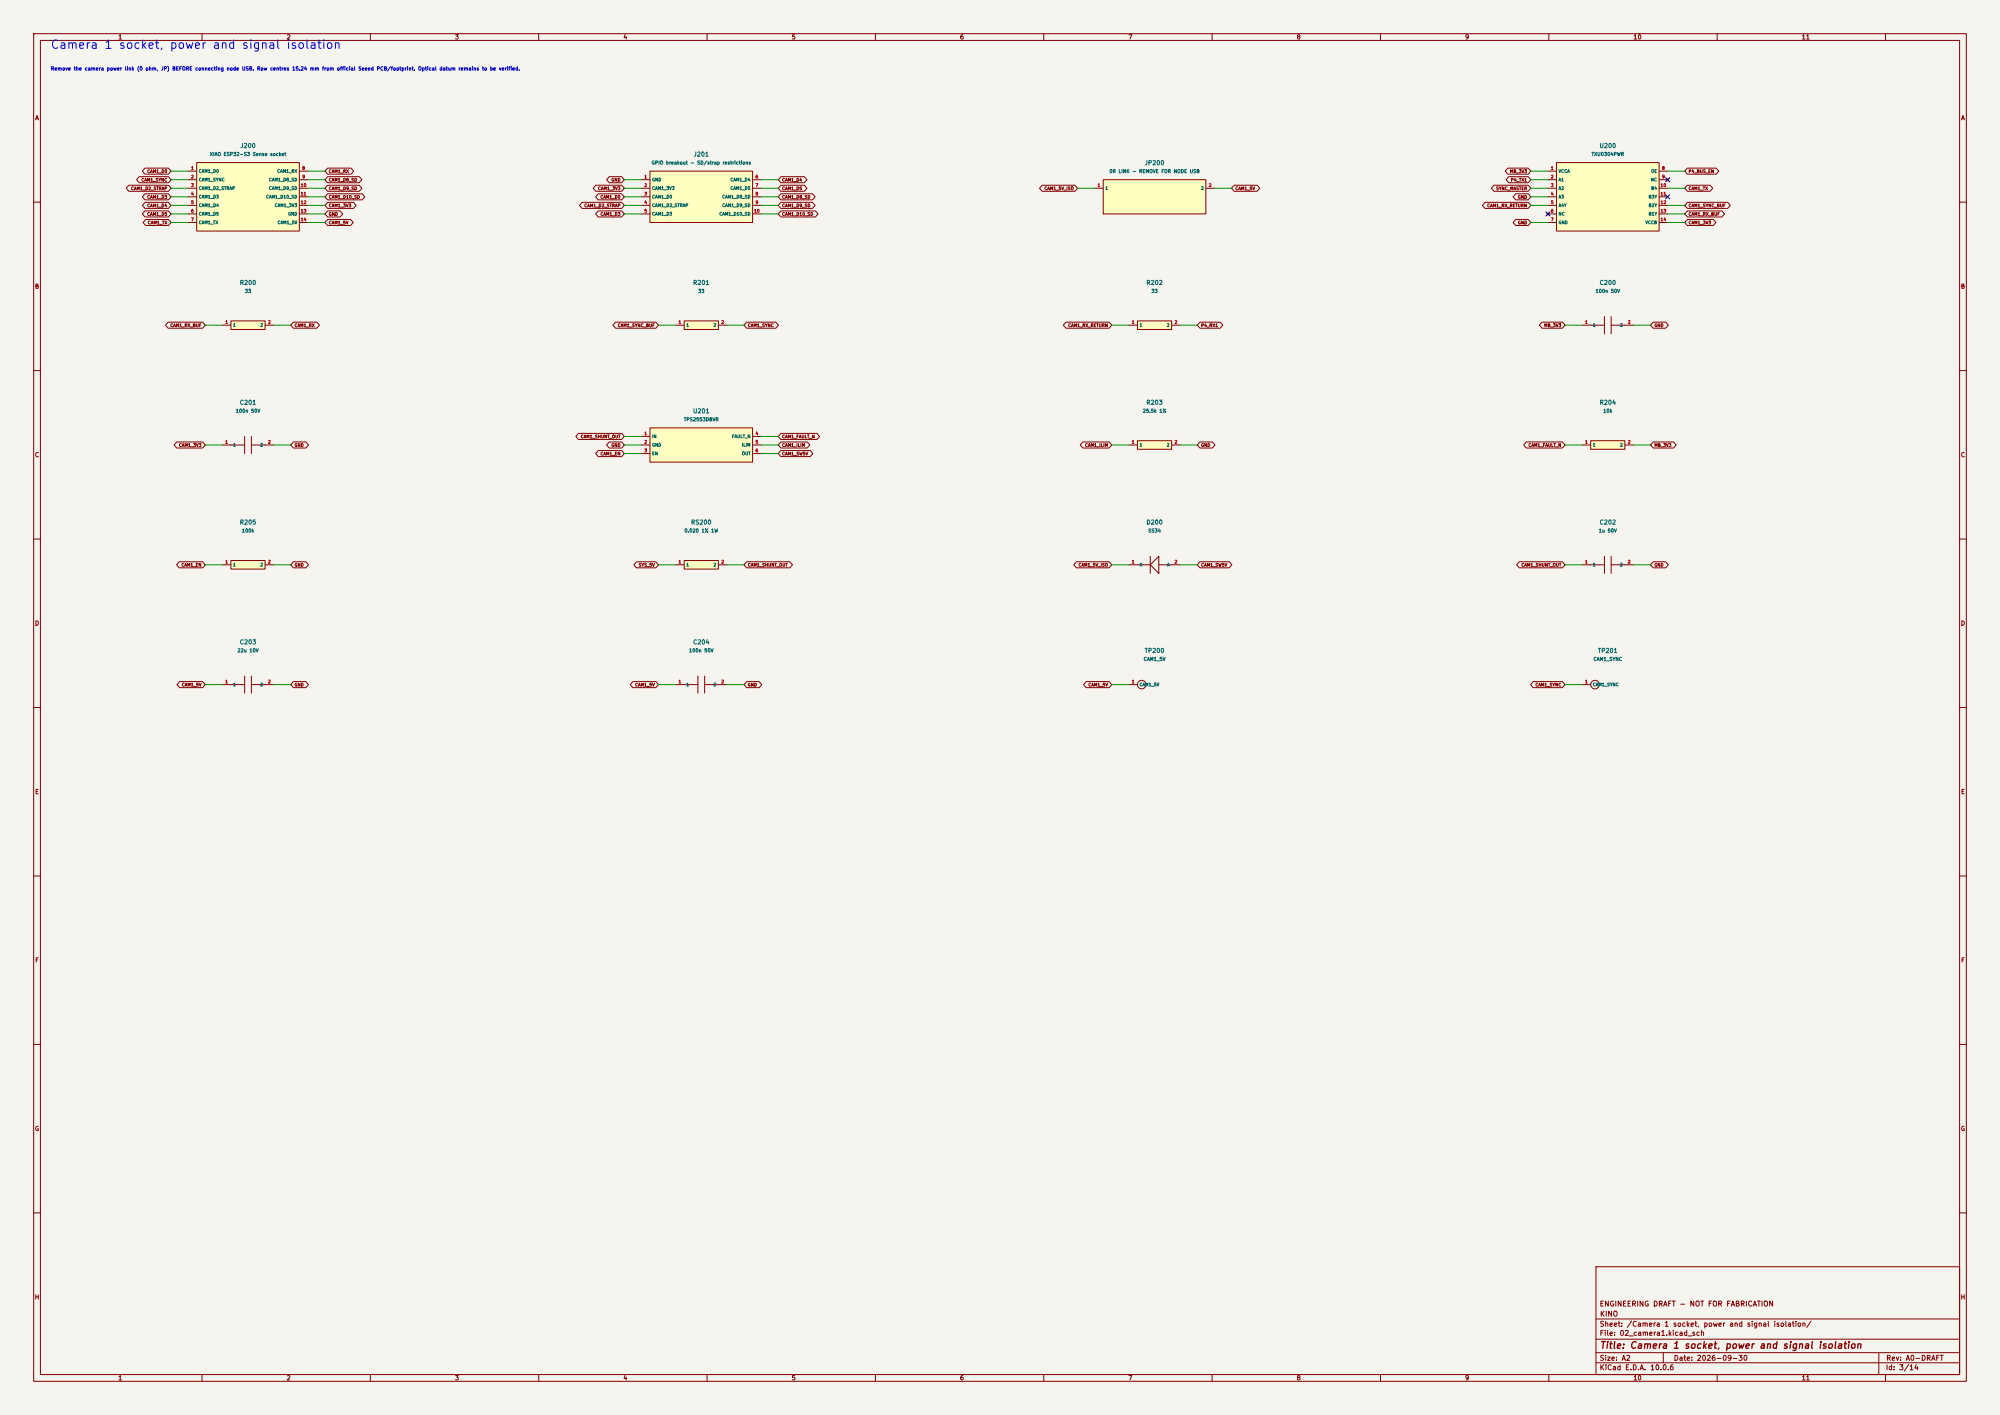
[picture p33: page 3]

Remove the camera power link (0 ohm, JP) BEFORE connecting node USB. Row centres 15.24 mm from official Seeed PCB/footprint. Optical datum remains to be verified. Camera 1 socket, power and signal isolation
XIAO ESP32-S3 Sense socket 1

0R LINK - REMOVE FOR NODE USB

Sheet: /Camera 1 socket, power and signal isolation/
File: 02_camera1.kicad_sch
Title: Camera 1 socket, power and signal isolation

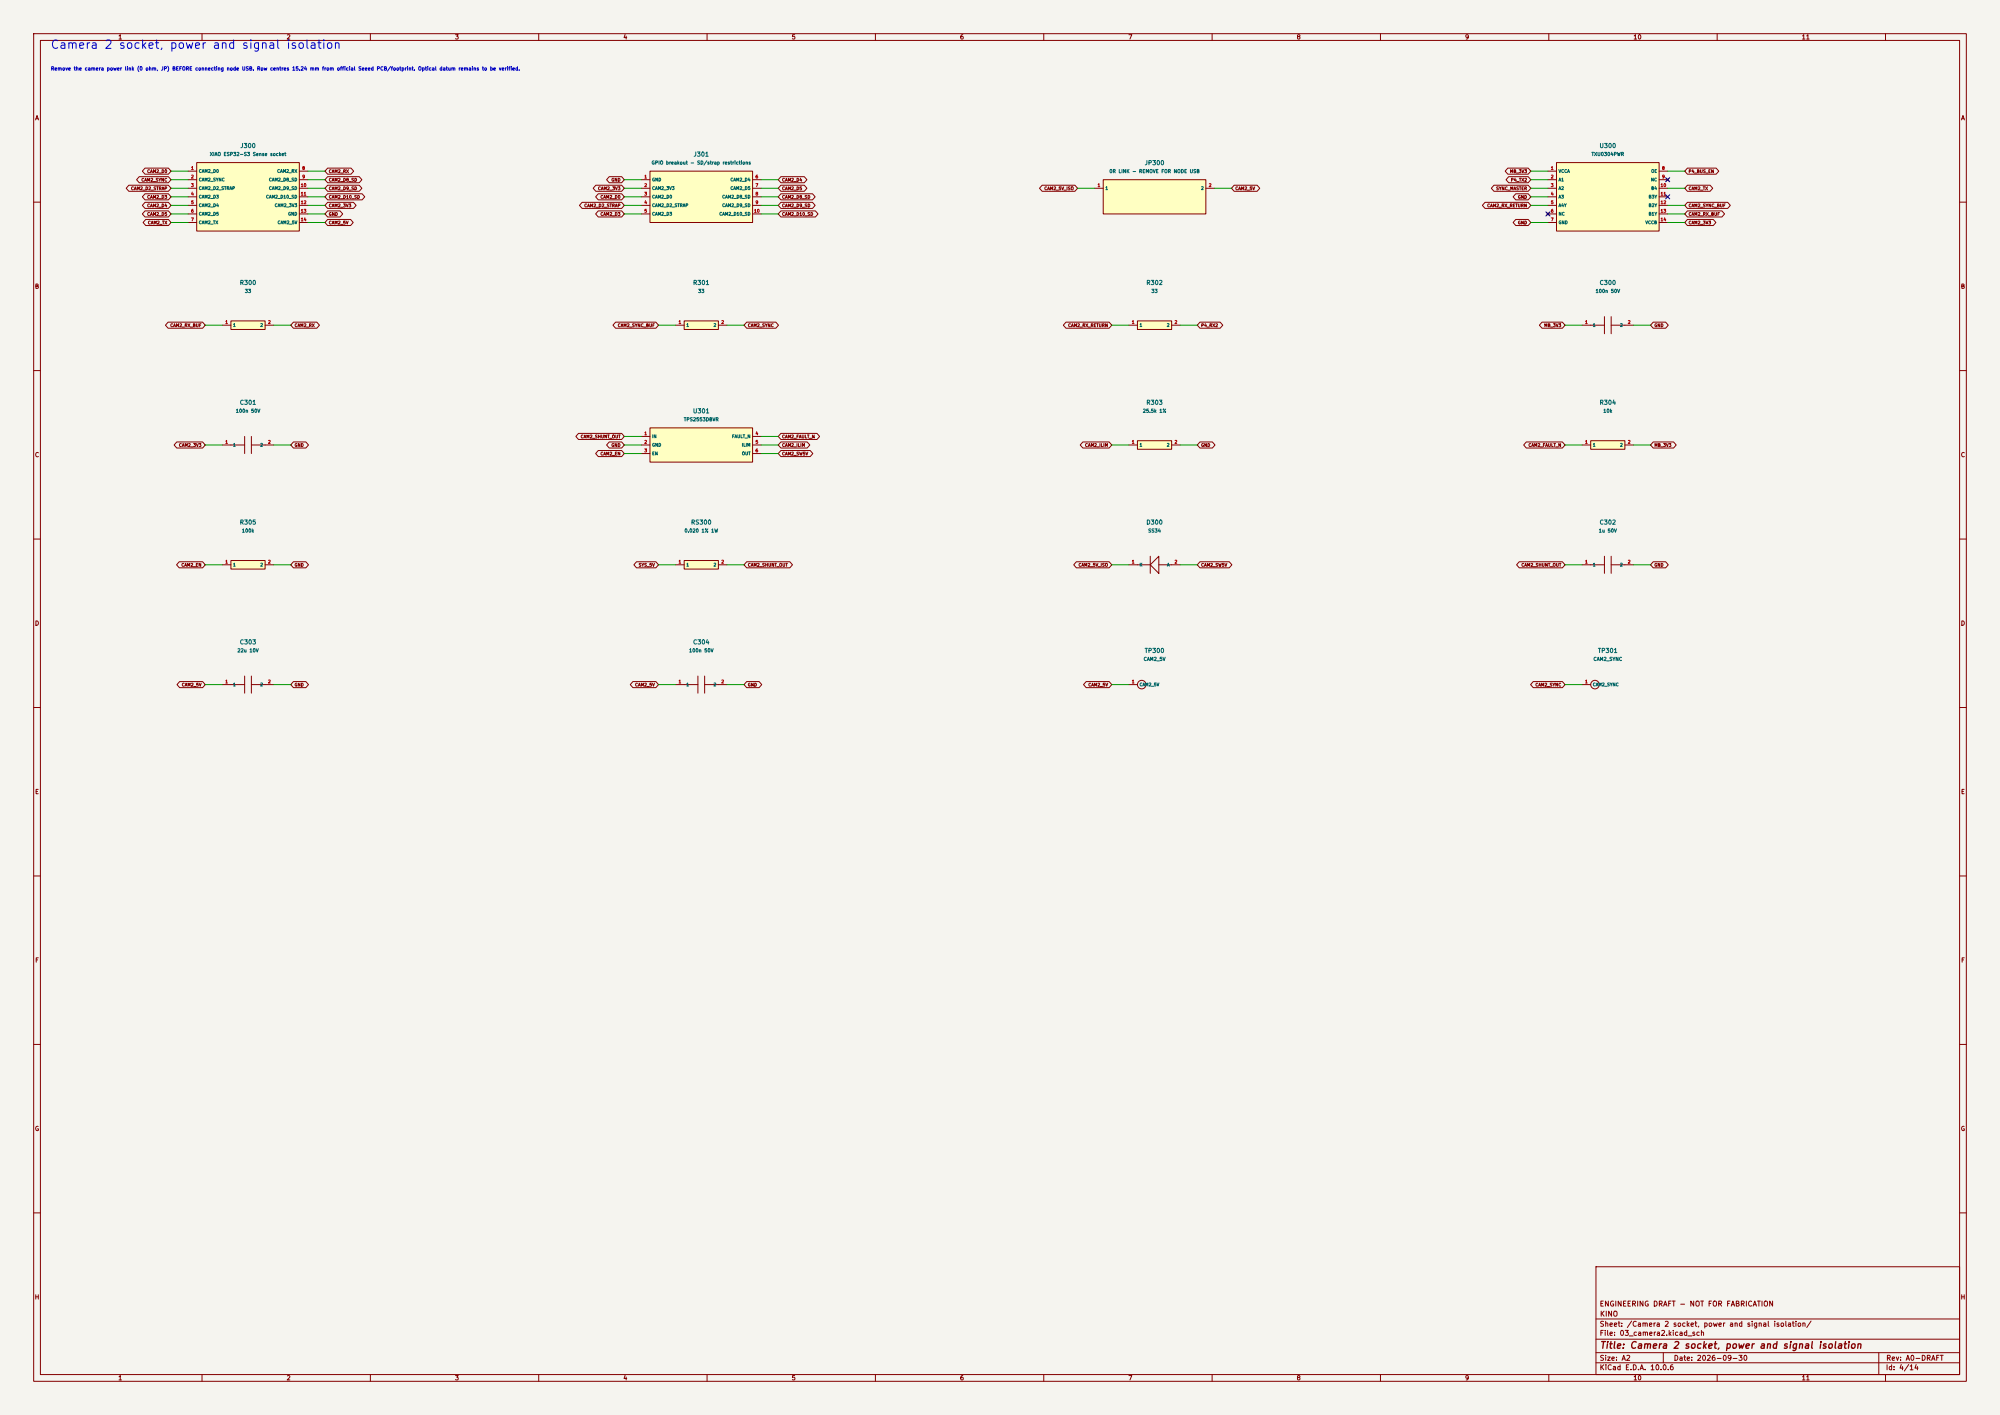
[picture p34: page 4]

Remove the camera power link (0 ohm, JP) BEFORE connecting node USB. Row centres 15.24 mm from official Seeed PCB/footprint. Optical datum remains to be verified. Camera 2 socket, power and signal isolation
XIAO ESP32-S3 Sense socket 1

0R LINK - REMOVE FOR NODE USB

Sheet: /Camera 2 socket, power and signal isolation/
File: 03_camera2.kicad_sch
Title: Camera 2 socket, power and signal isolation

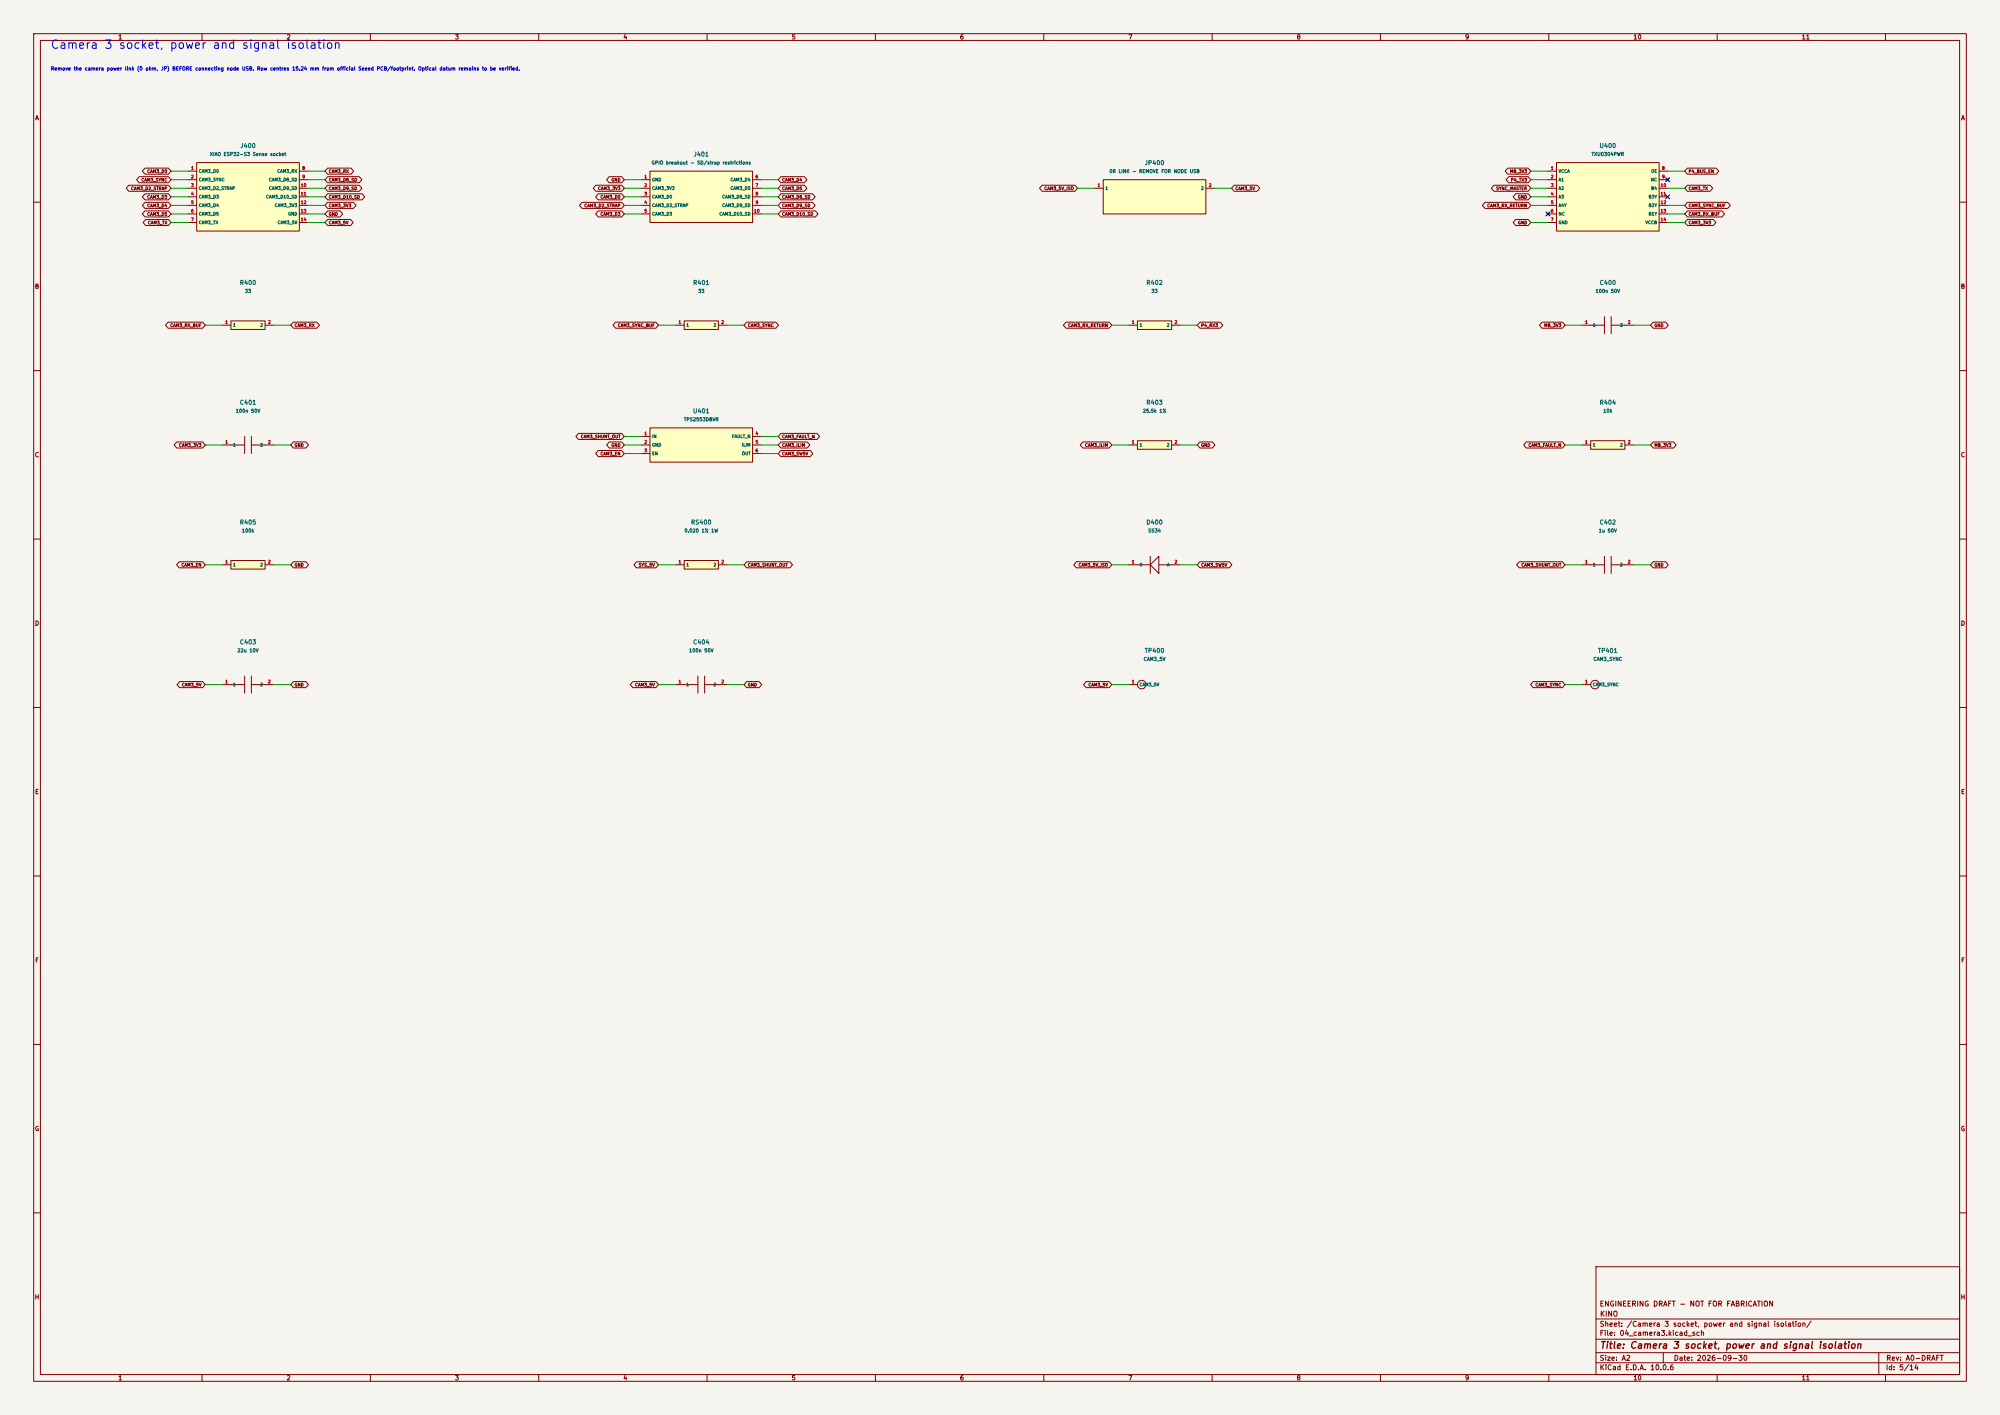
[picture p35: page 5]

Remove the camera power link (0 ohm, JP) BEFORE connecting node USB. Row centres 15.24 mm from official Seeed PCB/footprint. Optical datum remains to be verified. Camera 3 socket, power and signal isolation
XIAO ESP32-S3 Sense socket 1

0R LINK - REMOVE FOR NODE USB

Sheet: /Camera 3 socket, power and signal isolation/
File: 04_camera3.kicad_sch
Title: Camera 3 socket, power and signal isolation

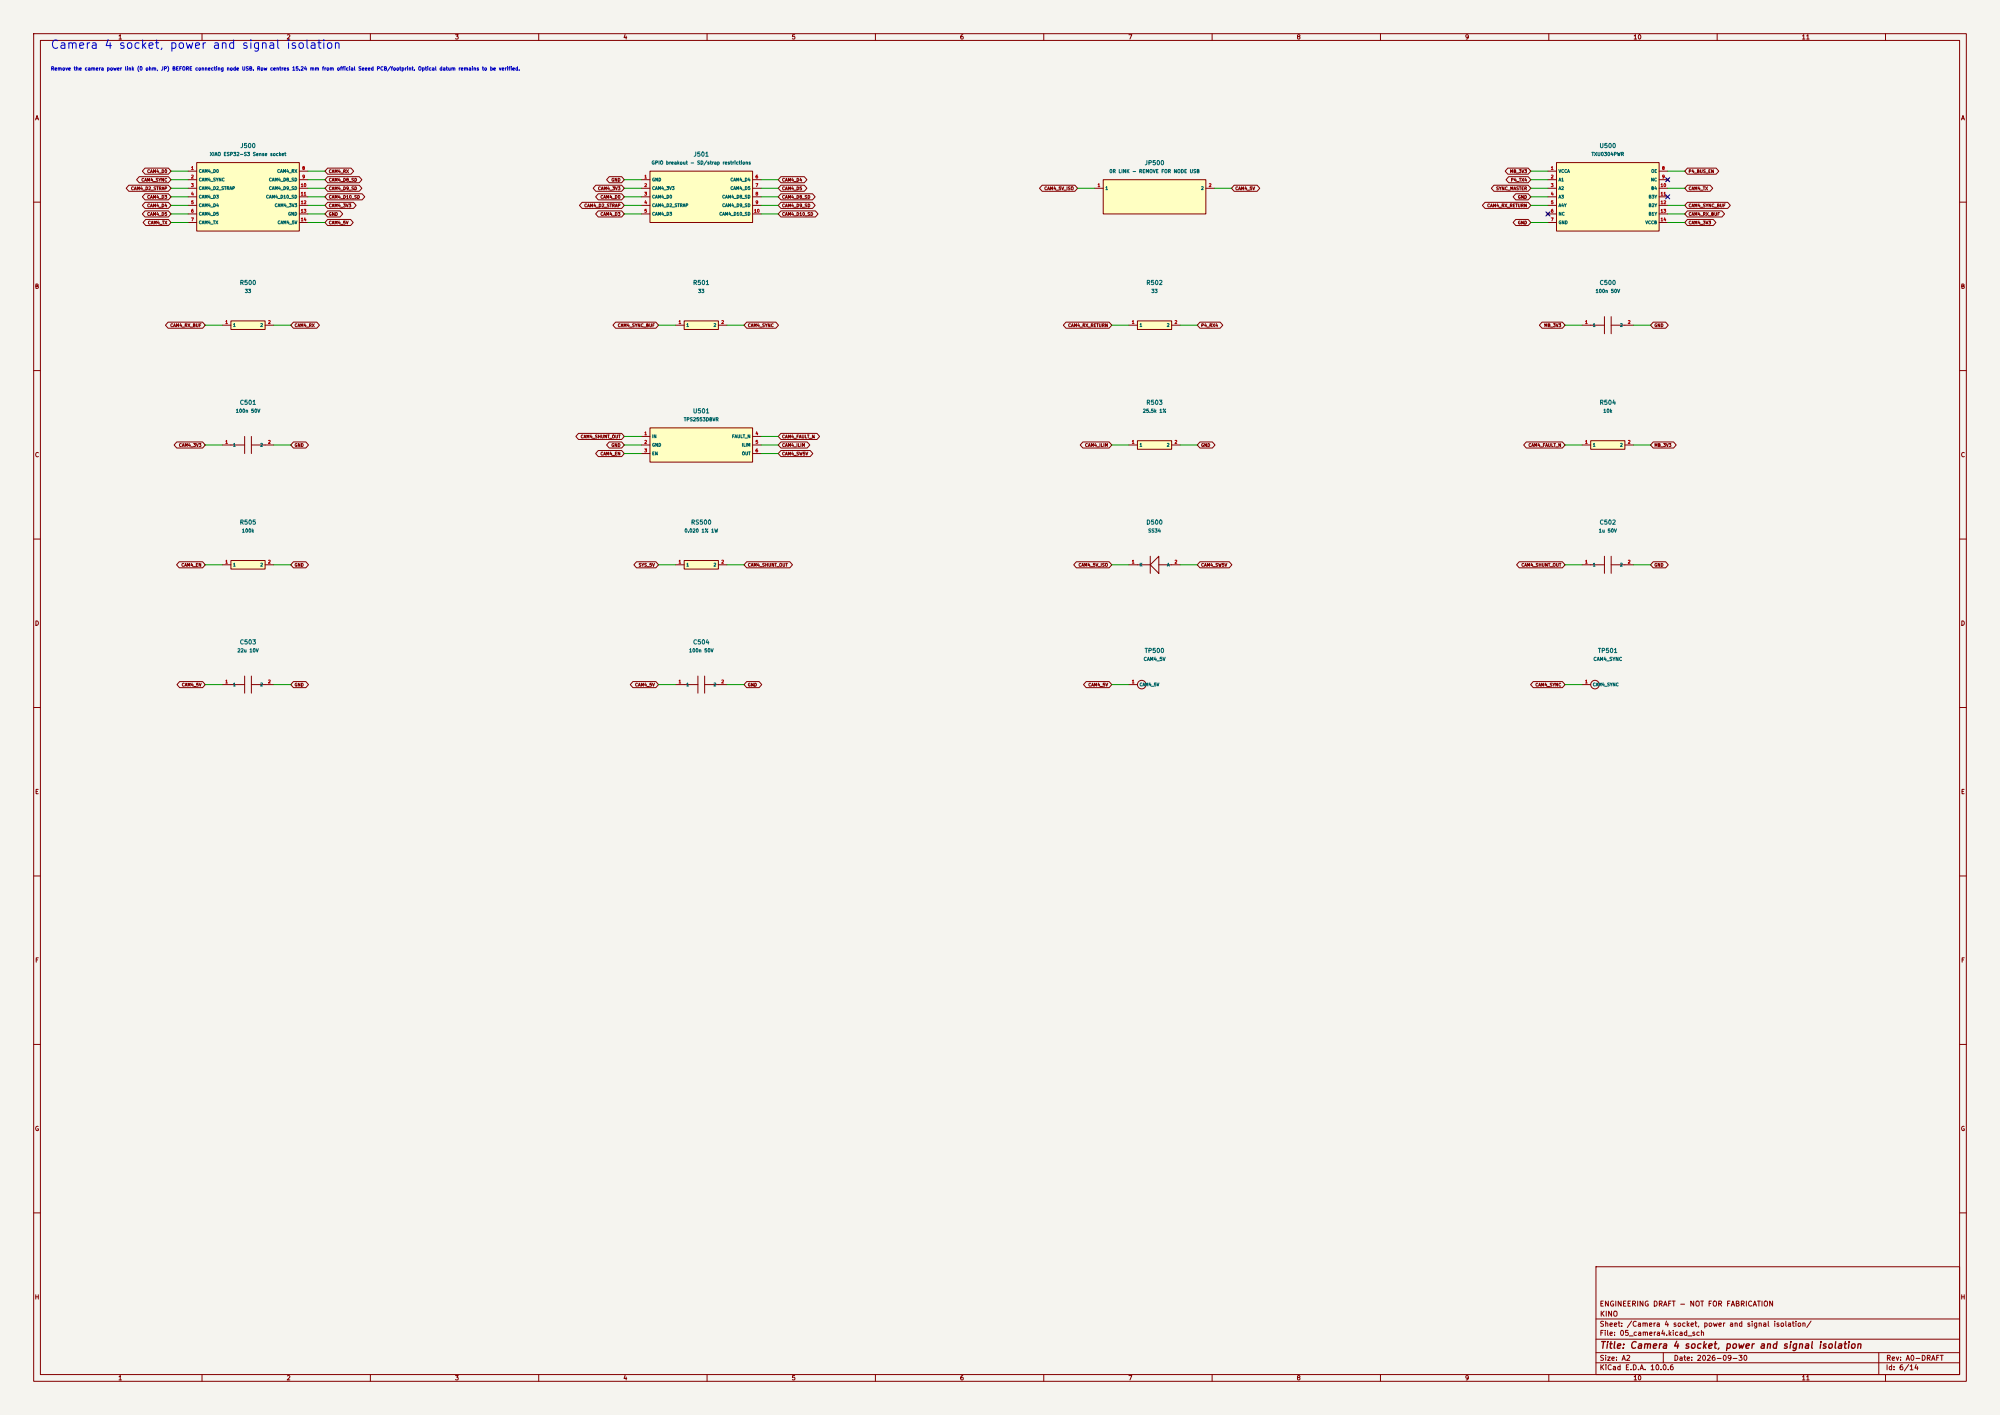
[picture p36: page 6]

Remove the camera power link (0 ohm, JP) BEFORE connecting node USB. Row centres 15.24 mm from official Seeed PCB/footprint. Optical datum remains to be verified. Camera 4 socket, power and signal isolation
XIAO ESP32-S3 Sense socket 1

0R LINK - REMOVE FOR NODE USB

Sheet: /Camera 4 socket, power and signal isolation/
File: 05_camera4.kicad_sch
Title: Camera 4 socket, power and signal isolation

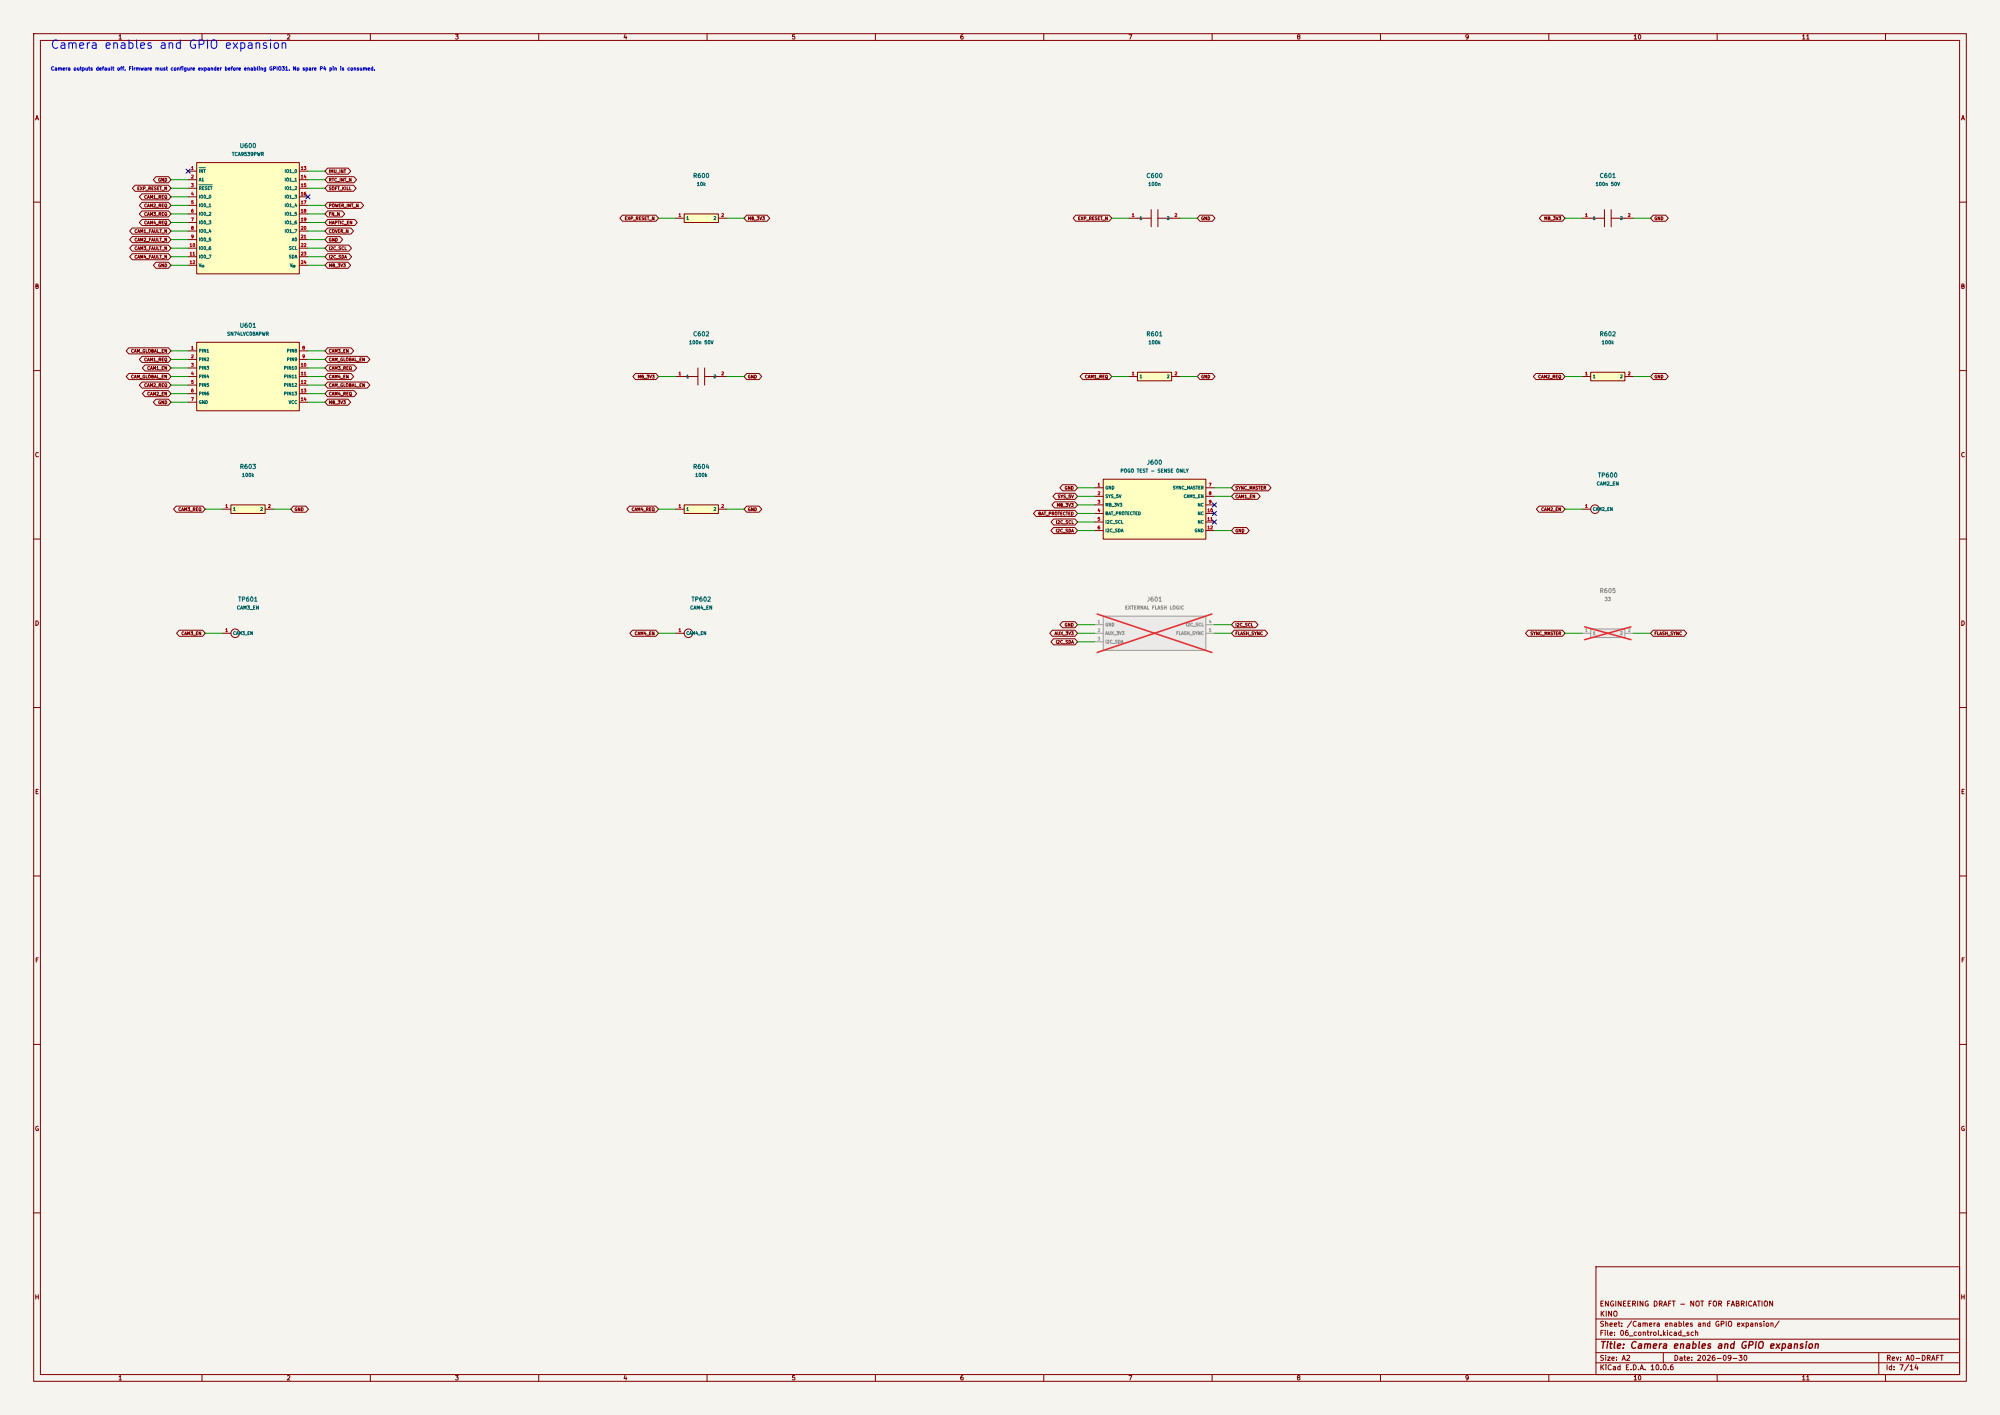
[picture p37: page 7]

Camera outputs default off. Firmware must configure expander before enabling GPIO31. No spare P4 pin is consumed. Camera enables and GPIO expansion

POGO TEST - SENSE ONLY

Sheet: /Camera enables and GPIO expansion/
File: 06_control.kicad_sch
Title: Camera enables and GPIO expansion

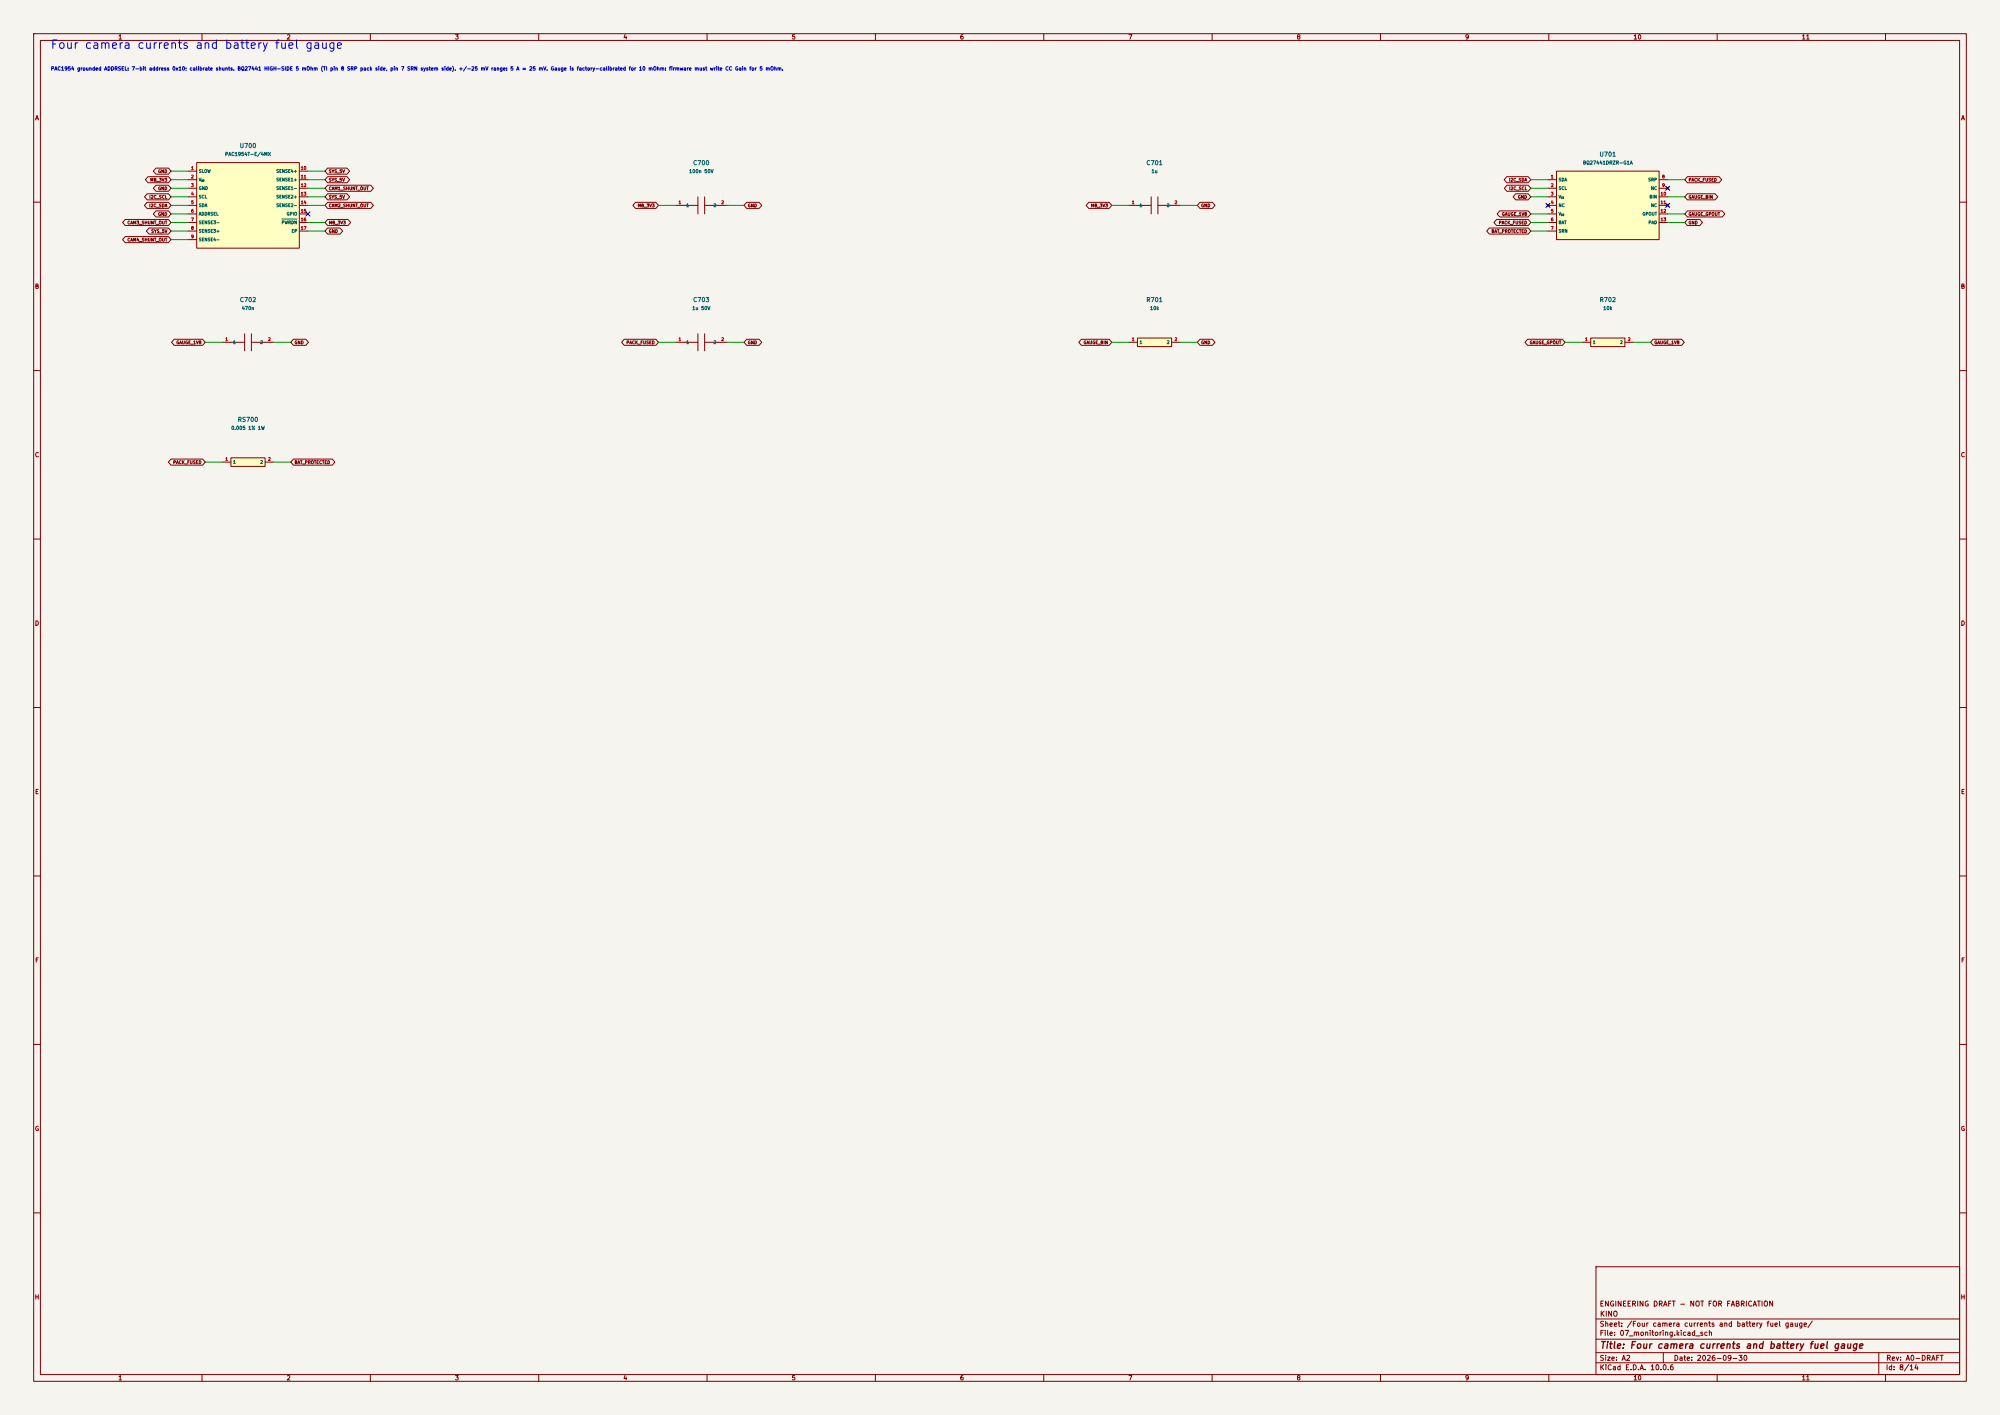
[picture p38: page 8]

PAC1954 grounded ADDRSEL: 7-bit address 0x10; calibrate shunts. BQ27441 HIGH-SIDE 5 mOhm (TI pin 8 SRP pack side, pin 7 SRN system side). +/-25 mV range: 5 A = 25 mV. Gauge is factory-calibrated for 10 mOhm: firmware must write CC Gain for 5 mOhm. Four camera currents and battery fuel gauge

Sheet: /Four camera currents and battery fuel gauge/
File: 07_monitoring.kicad_sch
Title: Four camera currents and battery fuel gauge

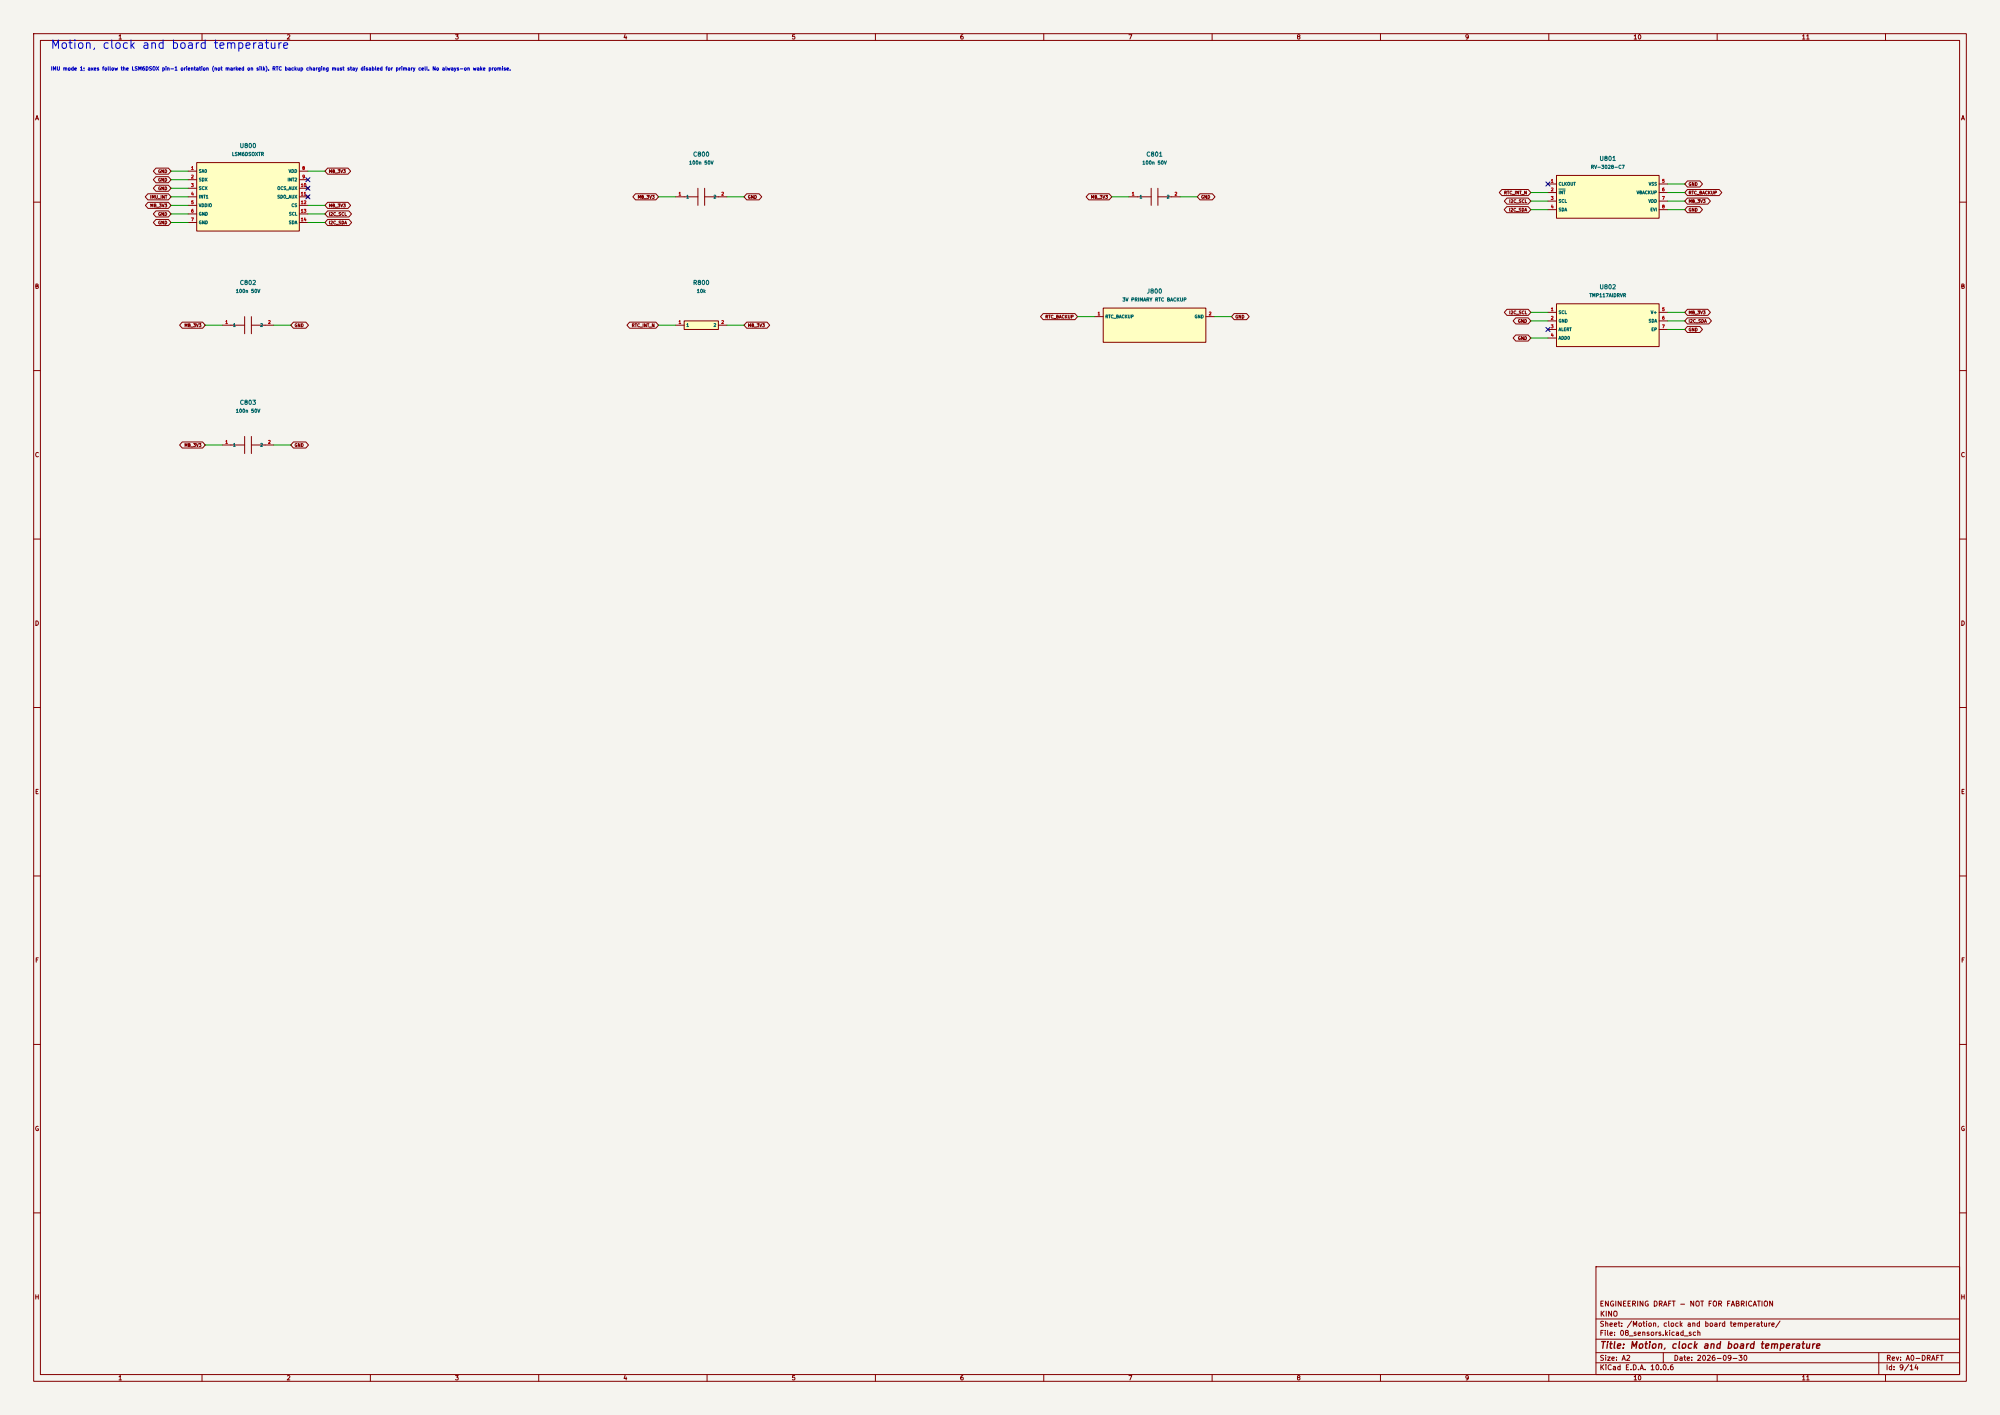
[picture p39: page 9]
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

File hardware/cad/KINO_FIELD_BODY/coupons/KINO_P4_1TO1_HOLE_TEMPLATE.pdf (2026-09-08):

## KINO D4 - P4 standoff 1:1 fit check

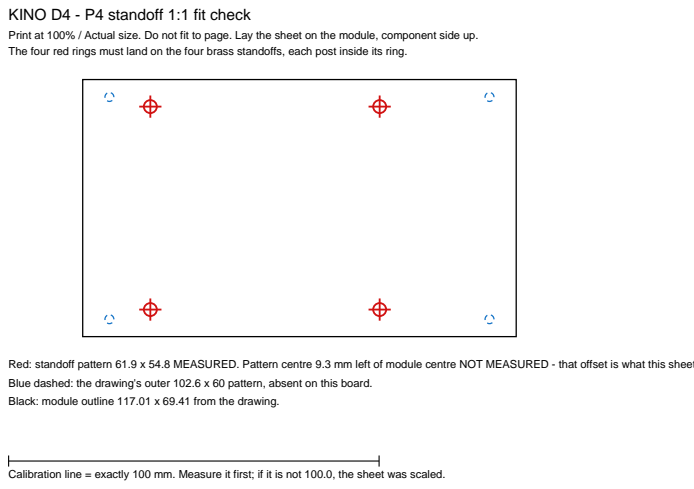
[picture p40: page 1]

Print at 100% / Actual size. Do not fit to page. Lay the sheet on the module, component side up.
The four red rings must land on the four brass standoffs, each post inside its ring.

Red: standoff pattern 61.9 x 54.8 MEASURED. Pattern centre 9.3 mm left of module centre NOT MEASURED - that offset is what this sheet decides.
Blue dashed: the drawing's outer 102.6 x 60 pattern, absent on this board.
Black: module outline 117.01 x 69.41 from the drawing.

Calibration line = exactly 100 mm. Measure it first; if it is not 100.0, the sheet was scaled.

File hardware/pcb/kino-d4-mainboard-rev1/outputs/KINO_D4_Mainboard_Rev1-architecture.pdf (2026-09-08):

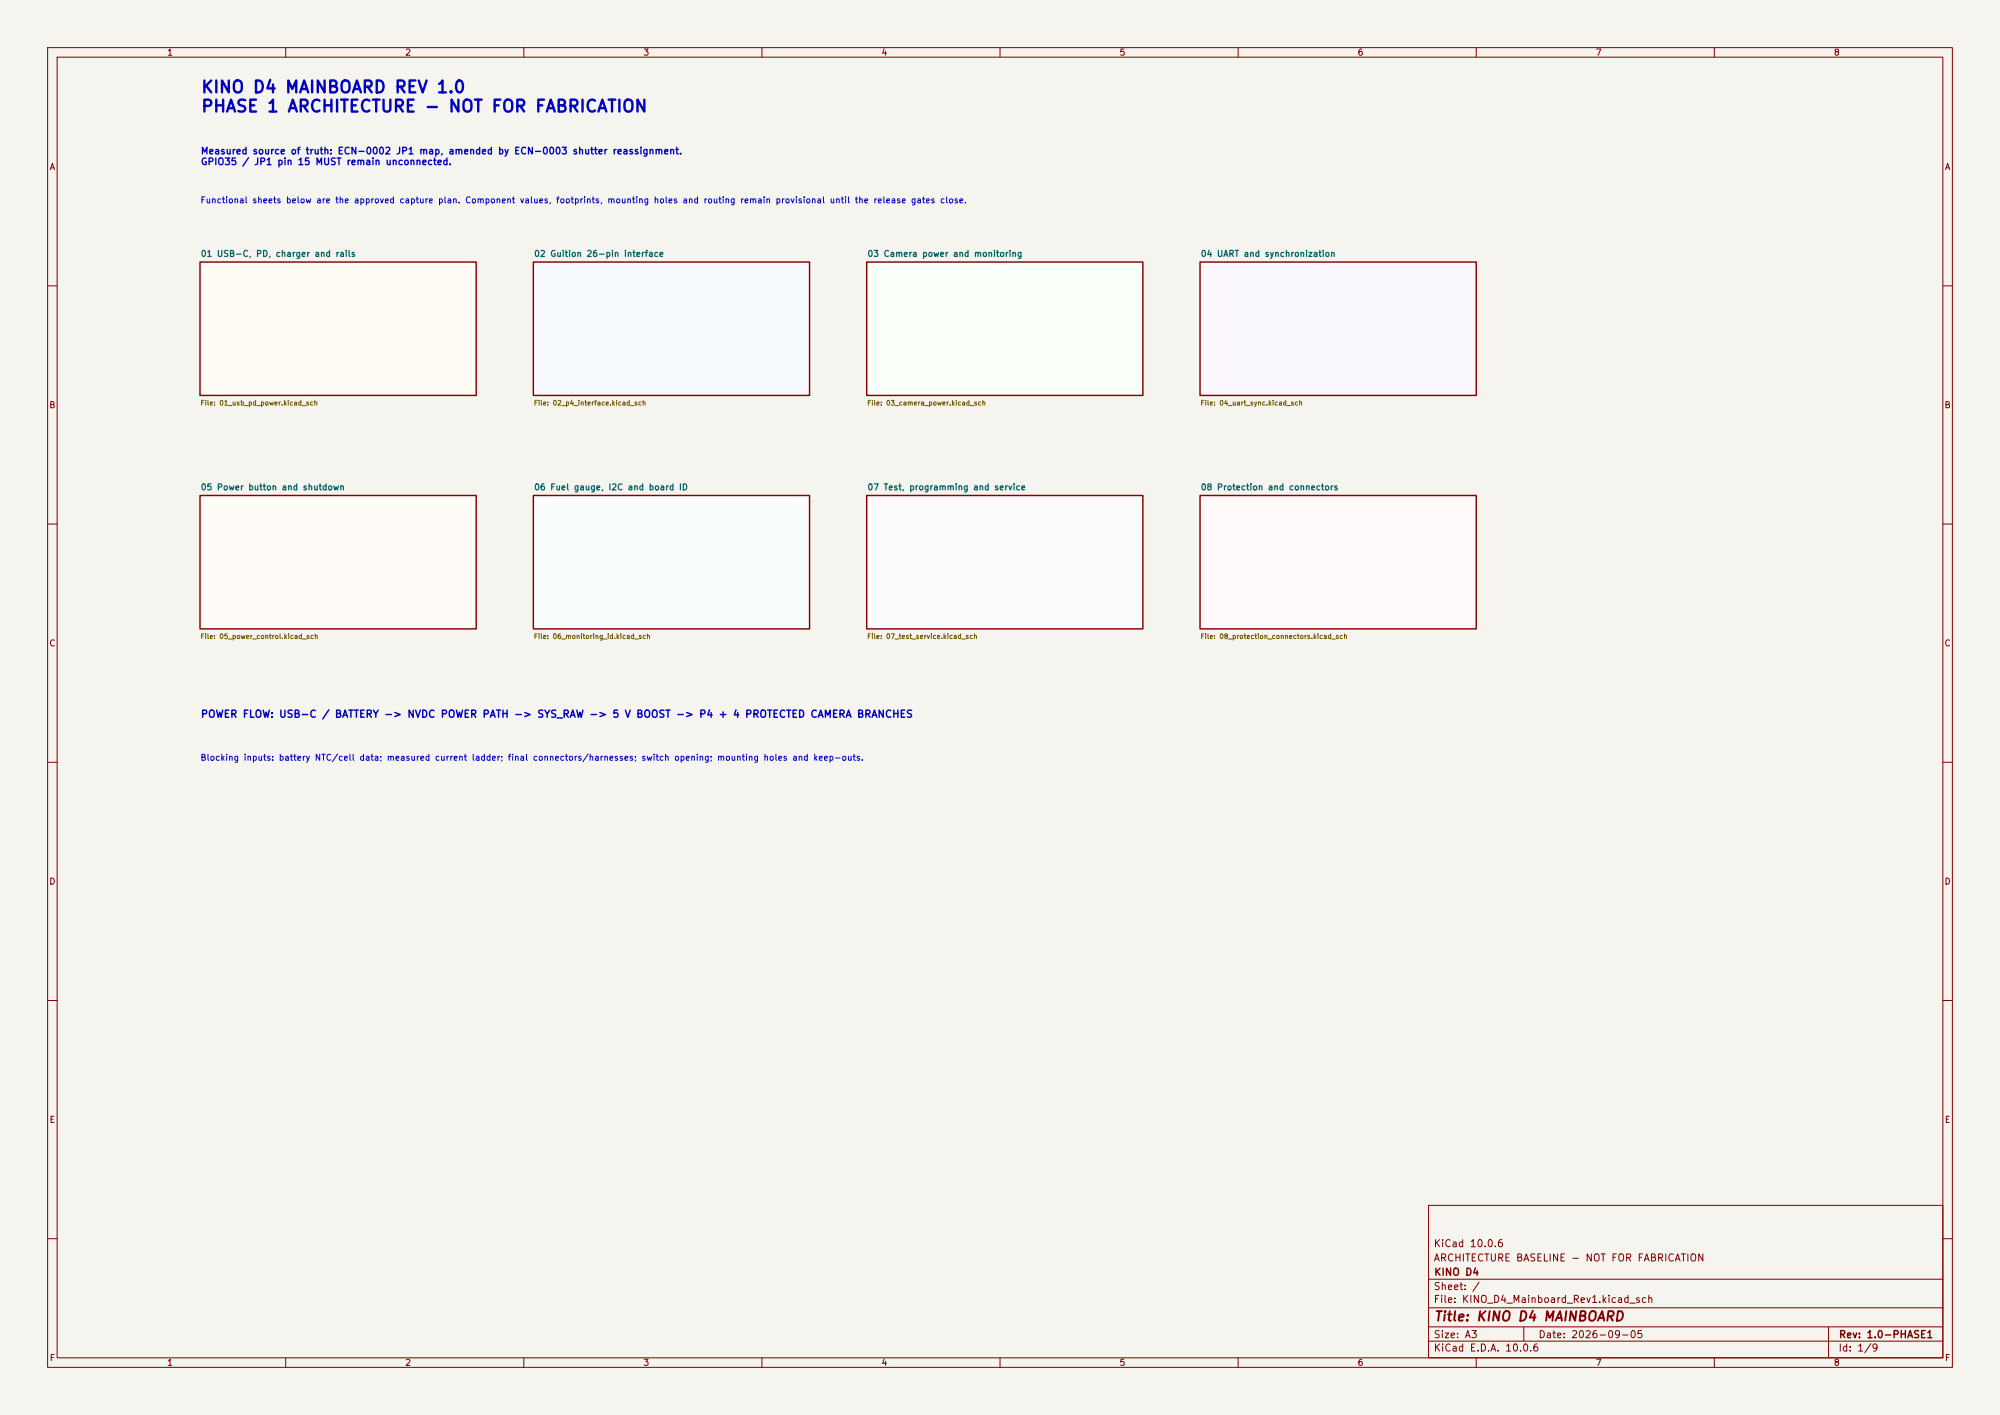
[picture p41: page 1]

File: 05_power_control.kicad_sch KINO D4 MAINBOARD REV 1.0
PHASE 1 ARCHITECTURE - NOT FOR FABRICATION

Measured source of truth: ECN-0002 JP1 map, amended by ECN-0003 shutter reassignment.
GPIO35 / JP1 pin 15 MUST remain unconnected. Functional sheets below are the approved capture plan. Component values, footprints, mounting holes and routing remain provisional until the release gates close. POWER FLOW: USB-C / BATTERY -> NVDC POWER PATH -> SYS_RAW -> 5 V BOOST -> P4 + 4 PROTECTED CAMERA BRANCHES

File: 08_protection_connectors.kicad_sch 01 USB-C, PD, charger and rails

File: 01_usb_pd_power.kicad_sch 05 Power button and shutdown

File: 04_uart_sync.kicad_sch 06 Fuel gauge, I2C and board ID

Blocking inputs: battery NTC/cell data; measured current ladder; final connectors/harnesses; switch opening; mounting holes and keep-outs.

KiCad 10.0.6
ARCHITECTURE BASELINE - NOT FOR FABRICATION
KINO D4
Sheet: /
File: KINO_D4_Mainboard_Rev1.kicad_sch
Title: KINO D4 MAINBOARD

Size: A3 | Rev: 1.0-PHASE1 | F Date: 2026-09-05
KiCad E.D.A. 10.0.6 | Id: 1/9

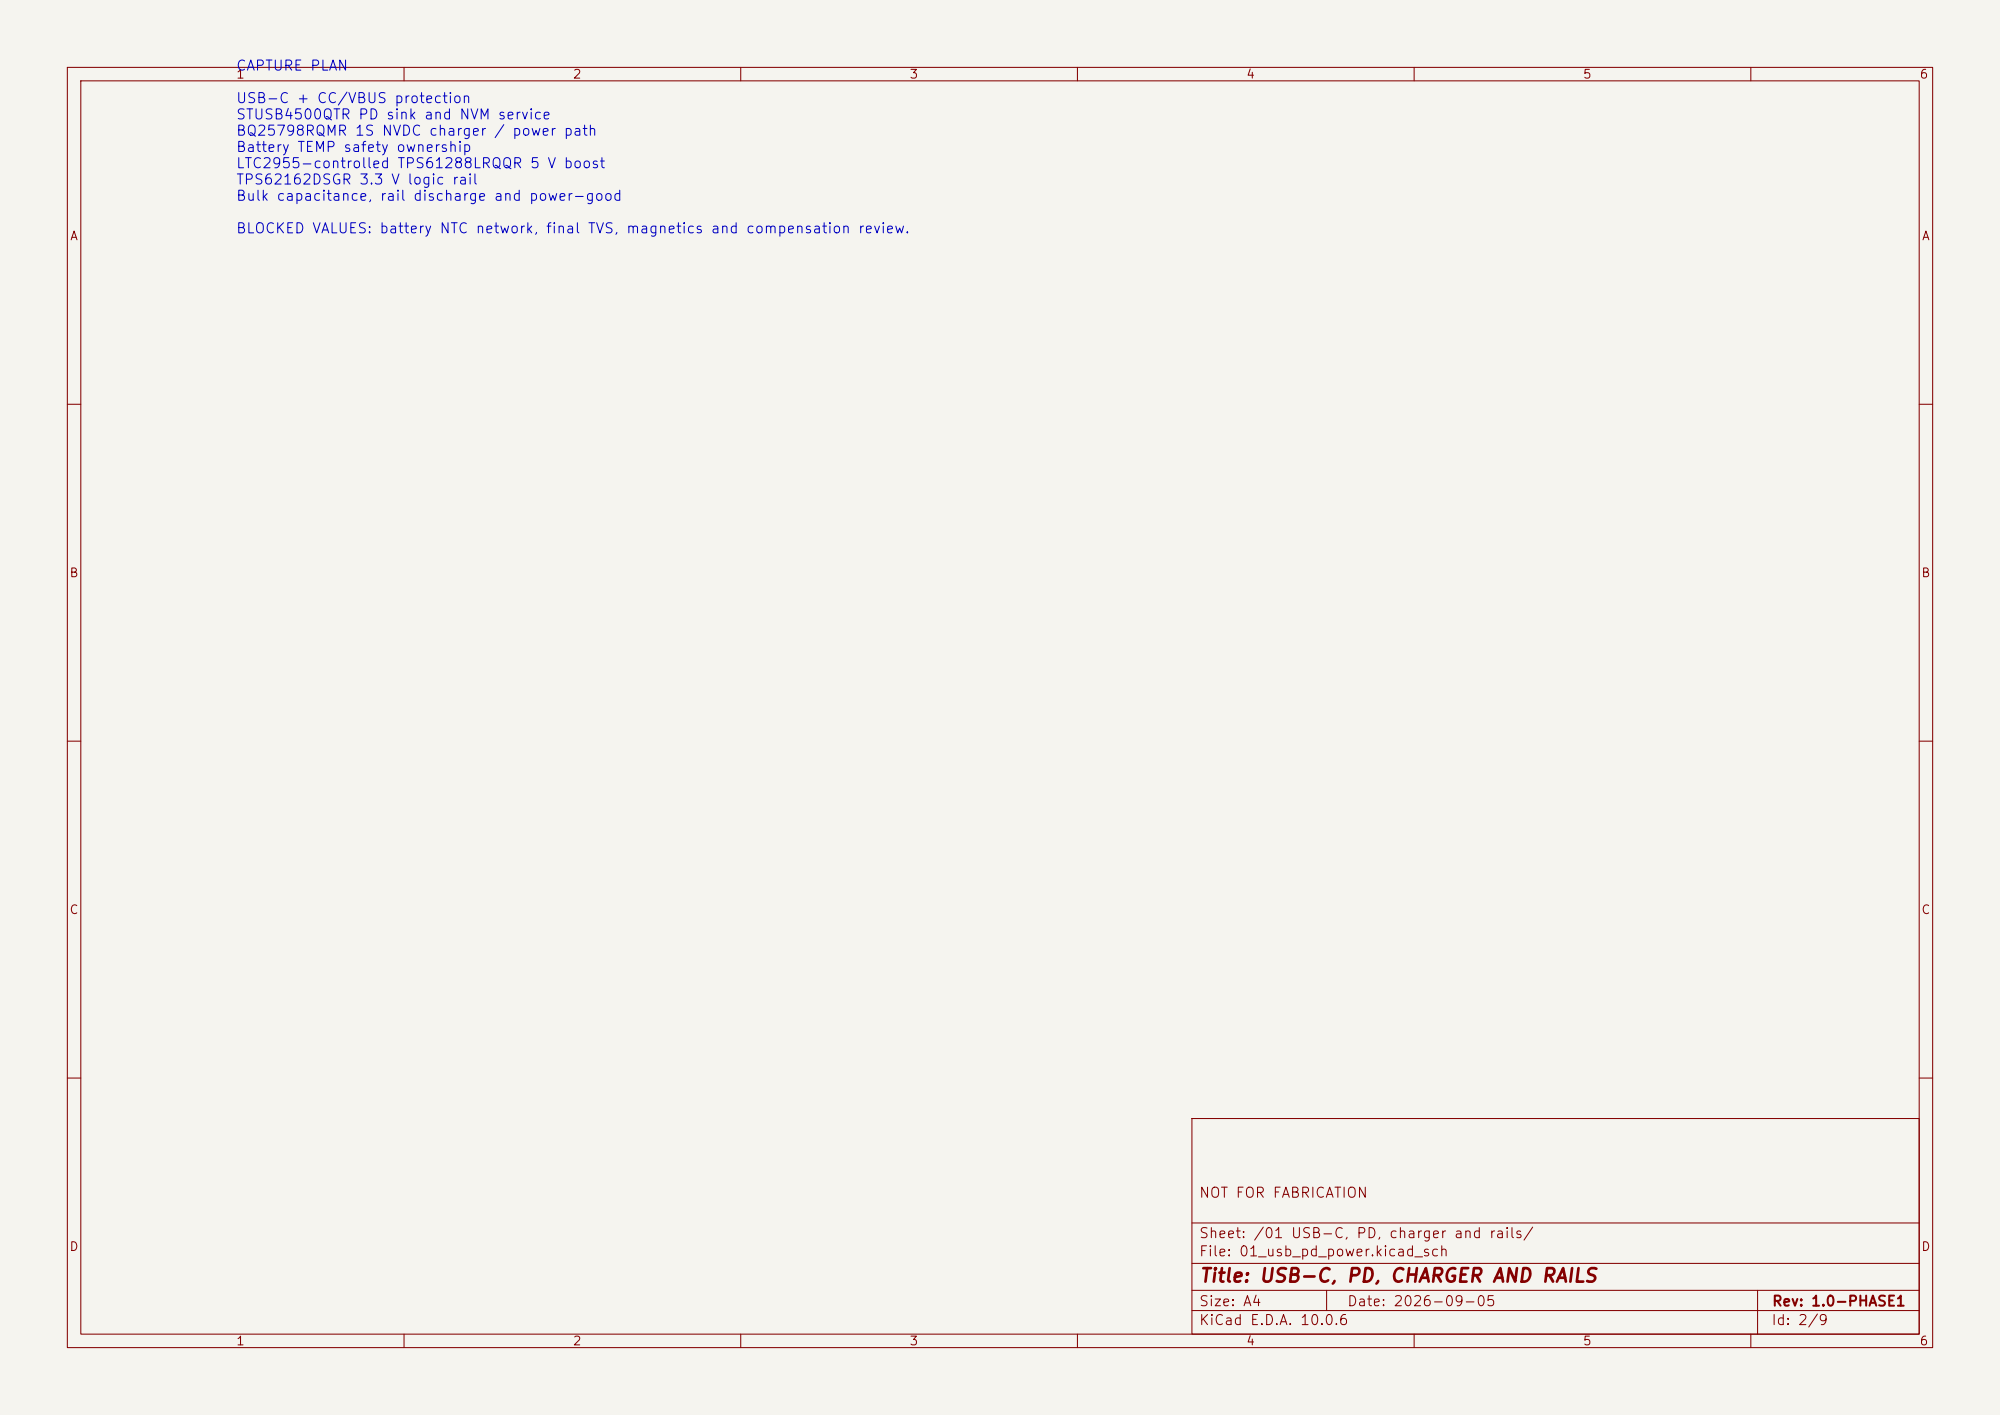
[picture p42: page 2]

CAPTURE PLAN
USB-C + CC/VBUS protection
STUSB4500QTR PD sink and NVM service
BQ25798RQMR 1S NVDC charger / power path
Battery TEMP safety ownership
LTC2955-controlled TPS61288LRQQR 5 V boost
TPS62162DSGR 3.3 V logic rail
Bulk capacitance, rail discharge and power-good

BLOCKED VALUES: battery NTC network, final TVS, magnetics and compensation review.

Sheet: /01 USB-C, PD, charger and rails/
File: 01_usb_pd_power.kicad_sch
Title: USB-C, PD, CHARGER AND RAILS

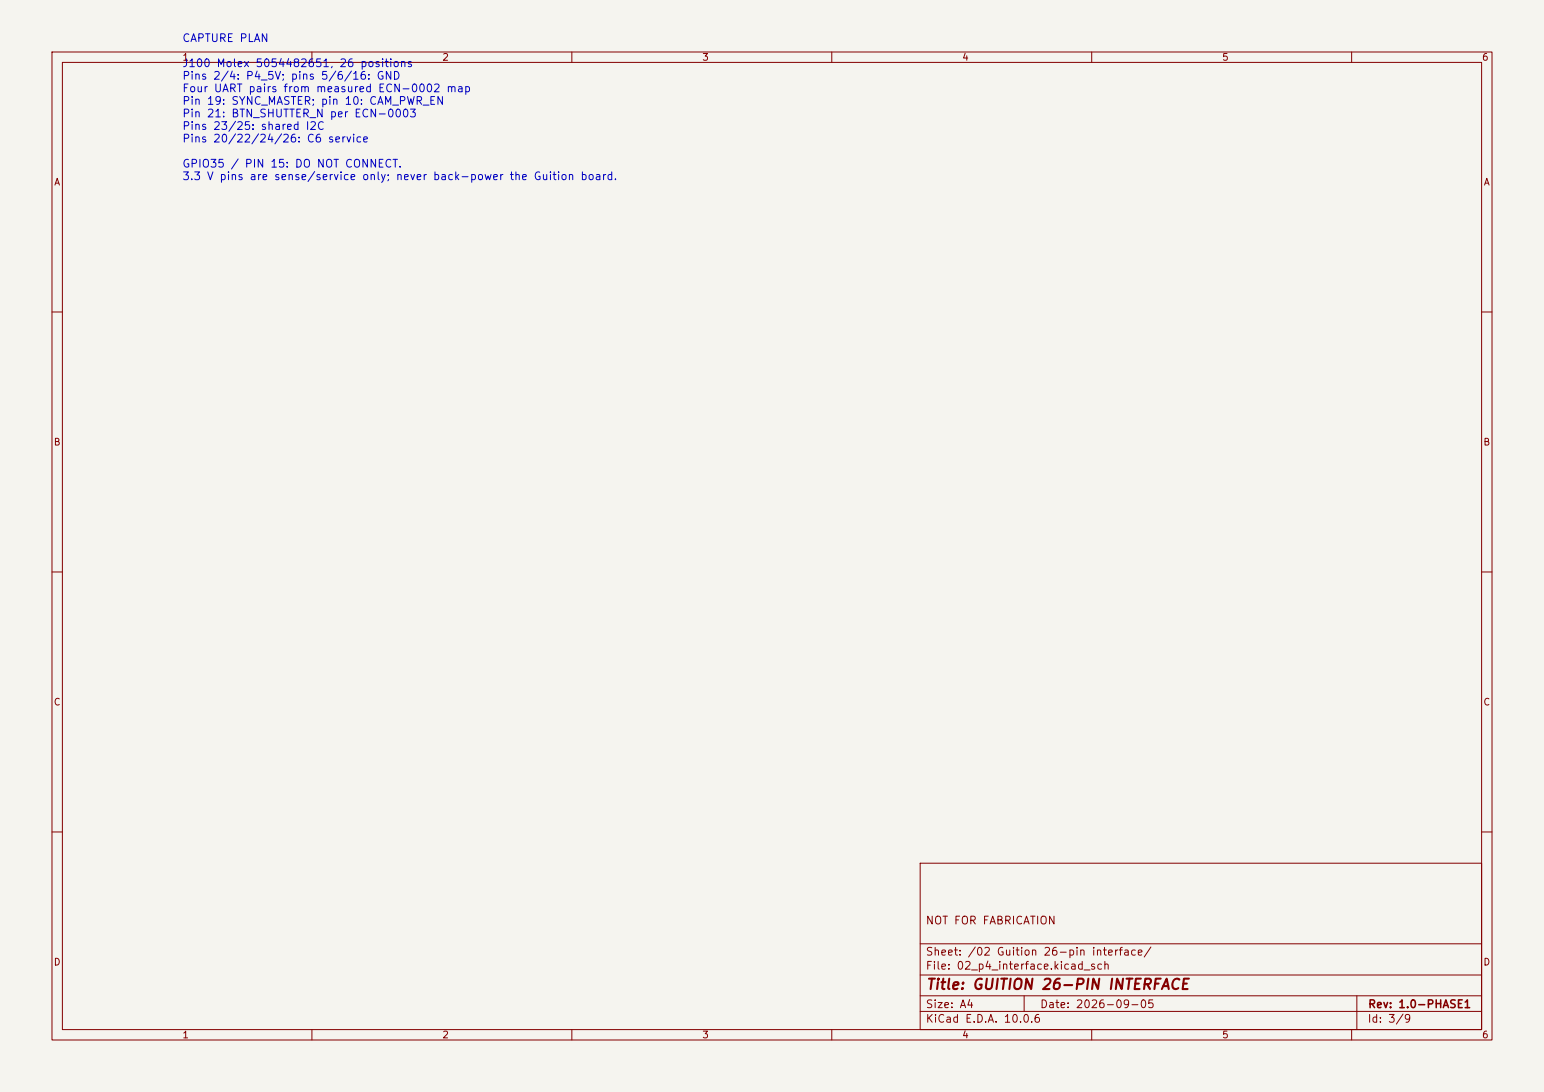
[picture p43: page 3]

J100 Molex 5054482651, 26 positions
Pins 2/4: P4_5V; pins 5/6/16: GND
Four UART pairs from measured ECN-0002 map
Pin 19: SYNC_MASTER; pin 10: CAM_PWR_EN
Pin 21: BTN_SHUTTER_N per ECN-0003
Pins 23/25: shared I2C
Pins 20/22/24/26: C6 service

GPIO35 / PIN 15: DO NOT CONNECT.
3.3 V pins are sense/service only; never back-power the Guition board.

Sheet: /02 Guition 26-pin interface/
File: 02_p4_interface.kicad_sch
Title: GUITION 26-PIN INTERFACE


PAC1954T-E/4MX and four Kelvin shunts
Four TPS2553DRVR current-limited branches
TCA9539PWR enables and FAULT_N inputs
SN74LVC08APWR gates every branch with CAM_PWR_EN
Per-branch effective bulk >= 22 uF plus local 100 nF
CAM1_5V through CAM4_5V rail test points

INITIAL LIMIT: about 1 A; final resistor from measured inrush/capture current.

Sheet: /03 Camera power and monitoring/
File: 03_camera_power.kicad_sch
Title: CAMERA POWER AND MONITORING


Eight 3.3 V UART signals with 33 ohm configuration footprints and test pads
CAM1 52/51; CAM2 50/49; CAM3 34/33; CAM4 30/29
SN74LVC125APWRG3 four-way SYNC fan-out from GPIO32 / JP1 pin 19
33 ohm branch source resistors, isolation links and test pads
CAMn_SYNC to XIAO D1 / GPIO2
CAMn_FSIN, CAMn_PWDN and CAMn_RESET future-interposer pads

Route every branch over continuous L2 ground and validate concurrent 921600 baud.

Sheet: /04 UART and synchronization/
File: 04_uart_sync.kicad_sch
Title: UART AND SYNCHRONIZATION


LTC2955CTS8-1#TRMPBF always-on controller
C&K KT11B0SAM35LFG edge-mounted side button
EN drives TPS61288L product-load boundary
INT status read through TCA9539
Open-drain KILL request from P4-controlled expander
Initial C_TMR 1.8 uF for nominal about 9.5 s hold
Optional USB-insertion auto-on configuration link

Bench requirement: graceful software shutdown plus 8-10 s forced off with P4 frozen.

Sheet: /05 Power button and shutdown/
File: 05_power_control.kicad_sch
Title: POWER BUTTON AND SHUTDOWN


BQ27441DRZR-G1A plus 10 milliohm Kelvin shunt
INA228AIDGSR plus 5 milliohm SYS_5V Kelvin shunt
24AA025E48T-I/OT board EEPROM and EUI-48
Shared MB_I2C_SDA/SCL configuration links and DNP pull-ups
Address straps, write protect, alert routing and test pads

Battery NTC is owned by charger safety loop; gauge uses internal or host temperature until curve is known.

Sheet: /06 Fuel gauge, I2C and board ID/
File: 06_monitoring_id.kicad_sch
Title: FUEL GAUGE, I2C AND BOARD ID


Bottom-side pogo pads for all required rails, UARTs, sync branches and I2C
Camera enable/fault and system power-management test access XIAO UART boot/reset recovery routes for CAM1-CAM4

C6 UART, IO9 and CHIP_PU service pads
STUSB NVM and board EEPROM production access Serial number and QR/UID programming record

Pogo geometry is blocked by mounting coordinates and fixture access.
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

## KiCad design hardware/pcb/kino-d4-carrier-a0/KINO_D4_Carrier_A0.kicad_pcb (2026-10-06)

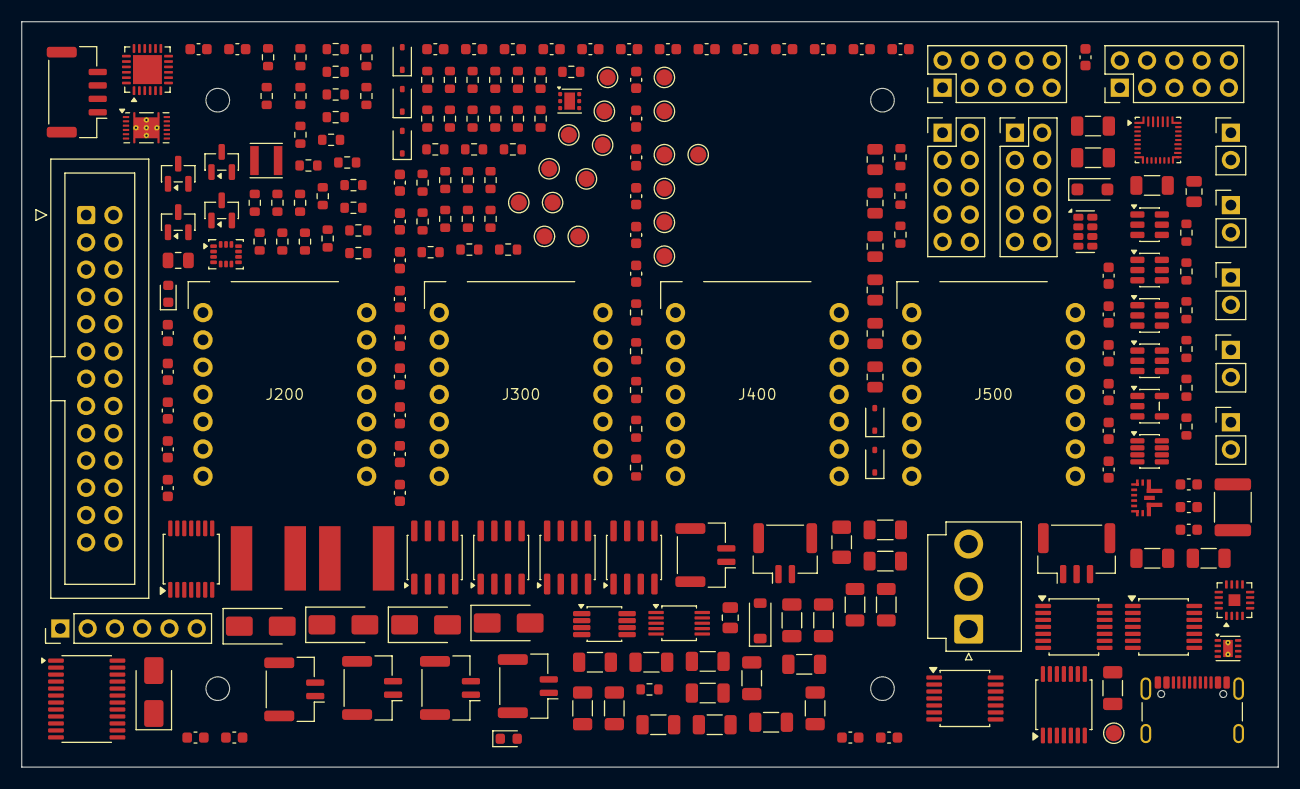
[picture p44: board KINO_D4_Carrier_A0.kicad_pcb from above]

Board: 4 copper layers, 117.0 x 69.4 mm, 247 parts (0 on the bottom side), 188 nets, no tracks yet.

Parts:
C100, C200, C201, C204, C300, C301, C304, C400, C401, C404, C500, C501, C504, C601, C602, C700, C800, C801, C802, C803, C905, C1205, C1300: 100n 16V; C_0603_1608Metric
C202, C302, C402, C502: 1u 16V; C_0603_1608Metric
C203, C303, C403, C503: 22u 10V; C_0805_2012Metric
C600, C703, C904, C1203: 100n; C_0603_1608Metric
C701, C900, C901, C1001, C1002: 1u; C_0603_1608Metric
C702: 470n; C_0603_1608Metric
C902, C1212: 10u; C_0805_2012Metric
C903, C1200: 10n; C_0603_1608Metric
C1000: 1u 35V; C_0805_2012Metric
C1100: 1n 50V; C_0603_1608Metric
C1101: 4.7u 10V; C_0805_2012Metric
C1102, C1103: 47n 16V; C_0603_1608Metric
C1104, C1105, C1107, C1108, C1109, C1111, C1112, C1113, C1114, C1115, C1117, C1118: 10u 35V X7R; C_1206_3216Metric
C1106, C1110, C1116, C1119: 100n 35V; C_0603_1608Metric
C1201: 100p; C_0603_1608Metric
C1202: 2.2u; C_0603_1608Metric
C1204, C1206, C1207, C1208, C1209, C1210, C1211: 22u 10V; C_1206_3216Metric
C1213: 22u; C_0805_2012Metric
C1301: 1.8u; C_0603_1608Metric
D200, D300, D400, D500, D1200: SS34; D_SMA
D900, D901, D902, D1002, D1003: PESD5V0S1BA; D_SOD-323
D1000: BZT52C10; D_SOD-123
D1001: SMF12A; D_SOD-123F
D1300: LED GREEN; LED_0603_1608Metric
D1301: LED AMBER; LED_0603_1608Metric
F100: PTC 100mA - select; Fuse_1206_3216Metric
F1100: FUSE 5A - select; Fuse_1812_4532Metric
H1, H2, H3, H4: P4 M2 insert mount; MountingHole_2.2mm_M2
J100: P4 JP1 - 26 pin IDC; IDC-Header_2x13_P2.54mm_Vertical
J101: C6 service - 3V3 sense only; PinHeader_1x06_P2.54mm_Vertical
J102: 3V3 I2C accessory; JST_GH_BM04B-GHS-TBT_1x04-1MP_P1.25mm_Vertical
J200, J300, J400, J500: XIAO ESP32-S3 Sense socket; XIAO_Socket_15.24mm
J201, J301, J401, J501: GPIO breakout - SD/strap restrictions; PinHeader_2x05_P2.54mm_Vertical
J800: 3V PRIMARY RTC BACKUP; JST_GH_BM02B-GHS-TBT_1x02-1MP_P1.25mm_Vertical
J900: HAPTIC MOTOR; JST_GH_BM02B-GHS-TBT_1x02-1MP_P1.25mm_Vertical
J901: COVER HALL SENSOR; JST_GH_BM03B-GHS-TBT_1x03-1MP_P1.25mm_Vertical
J902: LOCAL SHUTTER; JST_GH_BM02B-GHS-TBT_1x02-1MP_P1.25mm_Vertical
J903: REMOTE DRY CONTACT; JST_GH_BM02B-GHS-TBT_1x02-1MP_P1.25mm_Vertical
J904: FUNCTION BUTTON; JST_GH_BM02B-GHS-TBT_1x02-1MP_P1.25mm_Vertical
J1000: USB4105-GF-A; USB_C_Receptacle_GCT_USB4105-xx-A_16P_TopMnt_Horizontal
J1100: PROTECTED 1S PACK / NTC; JST_VH_B3P-VH_1x03_P3.96mm_Vertical
J1300: POWER PUSHBUTTON; JST_GH_BM02B-GHS-TBT_1x02-1MP_P1.25mm_Vertical
JP200, JP300, JP400, JP500: REMOVE FOR NODE USB; PinHeader_1x02_P2.54mm_Vertical
JP1200: REMOVE FOR P4 USB SERVICE; PinHeader_1x02_P2.54mm_Vertical
L1100: 1uH >=12A Isat; Inductor_6.5x6.5_DRAFT
L1200: 2.2uH >=12A Isat; Inductor_6.5x6.5_DRAFT
L1201: 2.2uH 1.5A; L_Taiyo-Yuden_NR-30xx
Q900, Q1100, Q1202, Q1300: 2N7002; SOT-23
Q1000, Q1001, Q1200, Q1201: AO4407A; SOIC-8_3.9x4.9mm_P1.27mm
R100, R204, R304, R404, R504, R600, R701, R800, R902, R903, R906, R1109, R1302: 10k; R_0603_1608Metric
R101: 1M; R_0603_1608Metric
R102, R103: 4.7k; R_0603_1608Metric
R104, R205, R305, R405, R505, R601, R602, R603, R604, R900, R905, R1000, R1003, R1102, R1103, R1203, R1300, R1301: 100k; R_0603_1608Metric
R200, R201, R202, R300, R301, R302, R400, R401, R402, R500, R501, R502: 33; R_0603_1608Metric
R203, R303, R403, R503: 25.5k 1%; R_0603_1608Metric
R700, R1108: 0; R_0603_1608Metric
R901, R1002, R1004: 1k; R_0603_1608Metric
R904: 47k; R_0603_1608Metric
R1001: 470; R_0603_1608Metric
R1100: 3.00k 1%; R_0603_1608Metric
R1101: 100; R_0603_1608Metric
R1104: 453k 1%; R_0603_1608Metric
R1105: 100k 1%; R_0603_1608Metric
R1106: 5.23k 1%; R_0603_1608Metric
R1107: 30.1k 1%; R_0603_1608Metric
R1200: 110k 0.1%; R_0603_1608Metric
R1201: 15k 0.1%; R_0603_1608Metric
R1202: 10k 1%; R_0603_1608Metric
R1303, R1304: 2.2k; R_0603_1608Metric
RS200, RS300, RS400, RS500: 0.020 1% 0.5W; R_1206_3216Metric
RS700: 0.010 1% 1W; R_1206_3216Metric
TP100: P4_3V3_TEST; TestPoint_Pad_D1.5mm
TP101: SYNC_MASTER; TestPoint_Pad_D1.5mm
TP102: P4_5V; TestPoint_Pad_D1.5mm
TP200: CAM1_5V; TestPoint_Pad_D1.5mm
TP201: CAM1_SYNC; TestPoint_Pad_D1.5mm
TP300: CAM2_5V; TestPoint_Pad_D1.5mm
TP301: CAM2_SYNC; TestPoint_Pad_D1.5mm
TP400: CAM3_5V; TestPoint_Pad_D1.5mm
TP401: CAM3_SYNC; TestPoint_Pad_D1.5mm
TP500: CAM4_5V; TestPoint_Pad_D1.5mm
TP501: CAM4_SYNC; TestPoint_Pad_D1.5mm
TP1000: USB_VBUS; TestPoint_Pad_D1.5mm
TP1001: PD_9V_OK_N; TestPoint_Pad_D1.5mm
TP1100: CHARGE_STAT_N; TestPoint_Pad_D1.5mm
TP1101: SYS_RAW; TestPoint_Pad_D1.5mm
TP1200: SYS_5V; TestPoint_Pad_D1.5mm
TP1201: MB_3V3; TestPoint_Pad_D1.5mm
TP1202: GND; TestPoint_Pad_D1.5mm
U100: TCA9517ADGKR; VSSOP-8_3x3mm_P0.65mm
U200, U300, U400, U500: TXU0304PWR; TSSOP-14_4.4x5mm_P0.65mm
U201, U301, U401, U501: TPS2553DBVR; SOT-23-6
U600: TCA9539PWR; TSSOP-24_4.4x7.8mm_P0.65mm
U601: SN74LVC08APWR; TSSOP-14_4.4x5mm_P0.65mm
U700: PAC1954T-E/4MX; VQFN-16-1EP_3x3mm_P0.5mm_EP1.1x1.1mm
U701: BQ27441DRZR-G1A; Texas_S-PDSO-N12
U800: LSM6DSOXTR; LGA-14_3x2.5mm_P0.5mm_LayoutBorder3x4y
U801: RV-3028-C7; MicroCrystal_C7_SON-8_1.5x3.2mm_P0.9mm
U802: TMP117AIDRVR; WSON-6-1EP_2x2mm_P0.65mm_EP1x1.6mm
U900: DRV2605LDGSR; TSSOP-10_3x3mm_P0.5mm
U901: SN74LVC1G14DBVR; SOT-23-5
U1000: STUSB4500QTR; QFN-24-1EP_4x4mm_P0.5mm_EP2.7x2.7mm
U1100: BQ25798RQMR; Texas_RQM0029A_VQFN-29_4x4mm_P0.4mm
U1200: TPS61288LRQQR; TPS61288_RQQ0011A_DRAFT
U1201: TPS62162DSGR; Texas_DSG0008A_WSON-8-1EP_2x2mm_P0.5mm_EP0.9x1.6mm_ThermalV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
U1300: LTC2955CTS8-1; TSOT-23-8

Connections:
AUX_3V3: F100.2, J102.2
BAT_PROTECTED: C703.1, C1117.1, C1118.1, C1119.1, F1100.2, R1101.1, U701.6, U1100.22, U1100.23
BOOST_5V: C1206.1, C1207.1, C1208.1, C1209.1, C1210.1, C1211.1, Q1200.5, Q1200.6, Q1200.7, Q1200.8, R1200.1, U1200.5
BOOST_BST: C1203.1, U1200.8
BOOST_COMP: C1201.1, R1202.1, U1200.2
BOOST_COMP_RC: C1200.1, R1202.2
BOOST_ENABLE: Q1202.1, U1200.6, U1300.7
BOOST_FB: R1200.2, R1201.1, U1200.1
BOOST_SW: C1203.2, L1200.2, U1200.4, U1200.9
BOOST_VCC: C1202.1, U1200.11
BUCK_SW: L1201.1, U1201.7
C6_3V3_TEST: J100.18, J101.2
C6_BOOT_SERVICE: J100.24, J101.5
C6_EN_SERVICE: J100.26, J101.6
C6_RX_SERVICE: J100.20, J101.3
C6_TX_SERVICE: J100.22, J101.4
CAM1_3V3: C201.1, J200.12, J201.2, U200.14
CAM1_5V: C203.1, C204.1, J200.14, JP200.2, TP200.1
CAM1_5V_ISO: D200.1, JP200.1
CAM1_D0: J200.1, J201.3
CAM1_D2_STRAP: J200.3, J201.4
CAM1_D3: J200.4, J201.5
CAM1_D4: J200.5, J201.6
CAM1_D5: J200.6, J201.7
CAM1_D8_SD: J200.9, J201.8
CAM1_D9_SD: J200.10, J201.9
CAM1_D10_SD: J200.11, J201.10
CAM1_EN: R205.1, U201.3, U601.3
CAM1_FAULT_N: R204.1, U201.4, U600.8
CAM1_ILIM: R203.1, U201.5
CAM1_REQ: R601.1, U600.4, U601.2
CAM1_RX: J200.8, R200.2
CAM1_RX_BUF: R200.1, U200.13
CAM1_RX_RETURN: R202.1, U200.5
CAM1_SHUNT_OUT: C202.1, RS200.2, U201.1, U700.12
CAM1_SW5V: D200.2, U201.6
CAM1_SYNC: J200.2, R201.2, TP201.1
CAM1_SYNC_BUF: R201.1, U200.12
CAM1_TX: J200.7, U200.10
CAM2_3V3: C301.1, J300.12, J301.2, U300.14
CAM2_5V: C303.1, C304.1, J300.14, JP300.2, TP300.1
CAM2_5V_ISO: D300.1, JP300.1
CAM2_D0: J300.1, J301.3
CAM2_D2_STRAP: J300.3, J301.4
CAM2_D3: J300.4, J301.5
CAM2_D4: J300.5, J301.6
CAM2_D5: J300.6, J301.7
CAM2_D8_SD: J300.9, J301.8
CAM2_D9_SD: J300.10, J301.9
CAM2_D10_SD: J300.11, J301.10
CAM2_EN: R305.1, U301.3, U601.6
CAM2_FAULT_N: R304.1, U301.4, U600.9
CAM2_ILIM: R303.1, U301.5
CAM2_REQ: R602.1, U600.5, U601.5
CAM2_RX: J300.8, R300.2
CAM2_RX_BUF: R300.1, U300.13
CAM2_RX_RETURN: R302.1, U300.5
CAM2_SHUNT_OUT: C302.1, RS300.2, U301.1, U700.14
CAM2_SW5V: D300.2, U301.6
CAM2_SYNC: J300.2, R301.2, TP301.1
CAM2_SYNC_BUF: R301.1, U300.12
CAM2_TX: J300.7, U300.10
CAM3_3V3: C401.1, J400.12, J401.2, U400.14
CAM3_5V: C403.1, C404.1, J400.14, JP400.2, TP400.1
CAM3_5V_ISO: D400.1, JP400.1
CAM3_D0: J400.1, J401.3
CAM3_D2_STRAP: J400.3, J401.4
CAM3_D3: J400.4, J401.5
CAM3_D4: J400.5, J401.6
CAM3_D5: J400.6, J401.7
CAM3_D8_SD: J400.9, J401.8
CAM3_D9_SD: J400.10, J401.9
CAM3_D10_SD: J400.11, J401.10
CAM3_EN: R405.1, U401.3, U601.8
CAM3_FAULT_N: R404.1, U401.4, U600.10
CAM3_ILIM: R403.1, U401.5
CAM3_REQ: R603.1, U600.6, U601.10
CAM3_RX: J400.8, R400.2
CAM3_RX_BUF: R400.1, U400.13
CAM3_RX_RETURN: R402.1, U400.5
CAM3_SHUNT_OUT: C402.1, RS400.2, U401.1, U700.7
CAM3_SW5V: D400.2, U401.6
CAM3_SYNC: J400.2, R401.2, TP401.1
CAM3_SYNC_BUF: R401.1, U400.12
CAM3_TX: J400.7, U400.10
CAM4_3V3: C501.1, J500.12, J501.2, U500.14
CAM4_5V: C503.1, C504.1, J500.14, JP500.2, TP500.1
CAM4_5V_ISO: D500.1, JP500.1
CAM4_D0: J500.1, J501.3
CAM4_D2_STRAP: J500.3, J501.4
CAM4_D3: J500.4, J501.5
CAM4_D4: J500.5, J501.6
CAM4_D5: J500.6, J501.7
CAM4_D8_SD: J500.9, J501.8
CAM4_D9_SD: J500.10, J501.9
CAM4_D10_SD: J500.11, J501.10
CAM4_EN: R505.1, U501.3, U601.11
CAM4_FAULT_N: R504.1, U501.4, U600.11
CAM4_ILIM: R503.1, U501.5
CAM4_REQ: R604.1, U600.7, U601.13
CAM4_RX: J500.8, R500.2
CAM4_RX_BUF: R500.1, U500.13
CAM4_RX_RETURN: R502.1, U500.5
CAM4_SHUNT_OUT: C502.1, RS500.2, U501.1, U700.9
CAM4_SW5V: D500.2, U501.6
CAM4_SYNC: J500.2, R501.2, TP501.1
CAM4_SYNC_BUF: R501.1, U500.12
CAM4_TX: J500.7, U500.10
CAM_GLOBAL_EN: J100.10, R104.1, U601.1, U601.4, U601.9, U601.12
CHARGE_ARM: Q1100.1, R1103.1, U600.20
CHARGE_CE_N: Q1100.3, R1102.1, U1100.13
CHARGE_LED_A: D1301.2, R1304.2
CHARGE_STAT_N: D1301.1, R1109.1, TP1100.1, U1100.1
CHG_BATP: R1101.2, U1100.18
CHG_BTST1: C1102.1, U1100.4
CHG_BTST2: C1103.1, U1100.19
CHG_ILIM: R1104.2, R1105.1, U1100.17
CHG_PMID: C1107.1, C1108.1, C1109.1, C1110.1, U1100.29
CHG_PROG: R1100.1, U1100.20
CHG_REGN: C1101.1, R1102.2, R1104.1, R1106.1, U1100.5
CHG_SDRV: C1100.1, U1100.24
CHG_SW1: C1102.2, L1100.1, U1100.28
CHG_SW2: C1103.2, L1100.2, U1100.26
CHG_TS: R1106.2, R1107.1, R1108.1, U1100.16
CHG_VBUS: C1104.1, C1105.1, C1106.1, Q1001.5, Q1001.6, Q1001.7, Q1001.8, R1002.1, U1100.2, U1100.3, U1100.9
COVER_N: C903.1, R901.2, R902.1, U600.13
COVER_RAW: D901.2, J901.3, R901.1
EXP_RESET_N: C600.1, R600.1, U600.3
FN_N: J904.1, R906.1, U600.16
GAUGE_1V8: C702.1, U701.5
GAUGE_BIN: R701.1, U701.10
GND: C100.2, C200.2, C201.2, C202.2, C203.2, C204.2, C300.2, C301.2, C302.2, C303.2, C304.2, C400.2, C401.2, C402.2, C403.2, C404.2, C500.2, C501.2, C502.2, C503.2, C504.2, C600.2, C601.2, C602.2, C700.2, C701.2, C702.2, C703.2, C800.2, C801.2, C802.2, C803.2, C900.2, C901.2, C902.2, C903.2, C904.2, C905.2, C1000.2, C1001.2, C1002.2, C1100.2, C1101.2, C1104.2, C1105.2, C1106.2, C1107.2, C1108.2, C1109.2, C1110.2, C1111.2, C1112.2, C1113.2, C1114.2, C1115.2, C1116.2, C1117.2, C1118.2, C1119.2, C1200.2, C1201.2, C1202.2, C1204.2, C1205.2, C1206.2, C1207.2, C1208.2, C1209.2, C1210.2, C1211.2, C1212.2, C1213.2, C1300.2, C1301.2, D900.1, D901.1, D902.1, D1001.2, D1002.2, D1003.2, D1300.1, J100.5, J100.6, J100.16, J101.1, J102.1, J200.13, J201.1, J300.13, J301.1, J400.13, J401.1, J500.13, J501.1, J800.2, J901.2, J902.2, J903.2, J904.2, J1000.A1, J1000.A12, J1000.B1, J1000.B12, J1000.SH, J1300.2, Q900.2, Q1100.2, Q1202.2, Q1300.2, R101.2, R104.2, R203.2, R205.2, R303.2, R305.2, R403.2, R405.2, R503.2, R505.2, R601.2, R602.2, R603.2, R604.2, R700.2, R701.2, R900.2, R905.2, R1000.2, R1100.2, R1103.2, R1105.2, R1107.2, R1201.2, R1301.2, RS700.2, TP1202.1, U100.4, U200.4, U200.7, U201.2, U300.4, U300.7, U301.2, U400.4, U400.7, U401.2, U500.4, U500.7, U501.2, U600.2, U600.12, U600.21, U601.7, U700.1, U700.3, U700.17, U701.3, U701.8, U701.13, U800.1, U800.2, U800.3, U800.6, U800.7, U801.5, U801.8, U802.2, U802.4, U802.7, U900.4, U900.8, U901.3, U1000.10, U1000.12, U1000.13, U1000.22, U1000.25, U1100.8, U1100.10, U1100.11, U1100.27, U1200.3, U1200.10, U1201.1, U1201.4, U1201.5, U1201.9, U1300.1, U1300.4
HAPTIC_EN: R900.1, U600.19, U900.5
HAPTIC_REG: C900.1, U900.1
I2C_SCL: J102.4, R103.1, U100.7, U600.22, U700.4, U701.2, U800.13, U801.3, U802.1, U900.2, U1000.7, U1100.14
I2C_SDA: J102.3, R102.1, U100.6, U600.23, U700.5, U701.1, U800.14, U801.4, U802.6, U900.3, U1000.8, U1100.15
IMU_INT: U600.17, U800.4
MAIN_COMMON: Q1200.1, Q1200.2, Q1200.3, Q1201.1, Q1201.2, Q1201.3, R1203.1
MAIN_GATE: Q1200.4, Q1201.4, Q1202.3, R1203.2
MB_3V3: C100.1, C200.1, C300.1, C400.1, C500.1, C601.1, C602.1, C700.1, C701.1, C800.1, C801.1, C802.1, C803.1, C901.1, C902.1, C905.1, C1213.1, F100.1, J901.1, L1201.2, R102.2, R103.2, R204.2, R304.2, R404.2, R504.2, R600.2, R800.2, R902.2, R904.2, R906.2, R1109.2, R1302.2, R1303.1, R1304.1, TP1201.1, U100.1, U100.8, U200.1, U300.1, U400.1, U500.1, U600.24, U601.14, U700.2, U700.16, U800.5, U800.8, U800.12, U801.7, U802.5, U900.6, U900.10, U901.5, U1201.6
MOTOR_N: J900.2, U900.9
MOTOR_P: J900.1, U900.7
P4_3V3_SENSE: J100.1, R100.1
P4_3V3_TEST: J100.3, TP100.1
P4_5V: J100.2, J100.4, JP1200.2, TP102.1
P4_5V_ISO: D1200.1, JP1200.1
P4_BUS_EN: R100.2, R101.1, U100.5, U200.8, U300.8, U400.8, U500.8
P4_RX1: J100.9, R202.2
P4_RX2: J100.13, R302.2
P4_RX3: J100.8, R402.2
P4_RX4: J100.14, R502.2
P4_SCL: J100.25, U100.2
P4_SDA: J100.23, U100.3
P4_TX1: J100.7, U200.2
P4_TX2: J100.11, U300.2
P4_TX3: J100.17, U400.2
P4_TX4: J100.12, U500.2
PACK_MINUS: J1100.3, RS700.1, U701.7
PACK_NTC: J1100.2, R1108.2
PACK_PLUS: F1100.1, J1100.1
PAC_ADDR: R700.1, U700.6
PD_1V2: C1001.1, U1000.21
PD_2V7: C1002.1, U1000.23
PD_9V_OK_N: TP1001.1, U1000.20
PD_COMMON_SOURCE: D1000.1, Q1000.1, Q1000.2, Q1000.3, Q1001.1, Q1001.2, Q1001.3, R1003.1
PD_DISCH: R1002.2, U1000.9
PD_GATE: D1000.2, Q1000.4, Q1001.4, R1003.2, R1004.1
PD_RESET: R1000.1, U1000.6
PD_SINK_EN_N: R1004.2, U1000.16
PD_VBUS_SENSE: R1001.2, U1000.18
POWER_INT_N: R1302.1, U600.14, U1300.8
POWER_KILL_N: Q1300.3, R1300.1, U1300.2
POWER_LED_A: D1300.2, R1303.2
POWER_PB_N: J1300.1, U1300.5
POWER_TMR: C1301.1, U1300.3
REMOTE_ACTIVE: Q900.1, R905.1, U901.4
REMOTE_CONTACT: D900.2, J903.1, R903.1
REMOTE_FILTER: C904.1, R903.2, R904.1, U901.2
RTC_BACKUP: J800.1, U801.6
RTC_INT_N: R800.1, U600.18, U801.2
SHUTTER_N: D902.2, J100.21, J902.1, Q900.3
SOFT_KILL: Q1300.1, R1301.1, U600.15
SYNC_MASTER: J100.19, TP101.1, U200.3, U300.3, U400.3, U500.3
SYS_5V: C1212.1, D1200.2, Q1201.5, Q1201.6, Q1201.7, Q1201.8, RS200.1, RS300.1, RS400.1, RS500.1, TP1200.1, U700.8, U700.10, U700.11, U700.13, U1201.2, U1201.3
SYS_RAW: C1111.1, C1112.1, C1113.1, C1114.1, C1115.1, C1116.1, C1204.1, C1205.1, C1300.1, L1200.1, R1300.2, TP1101.1, U1100.25, U1200.7, U1300.6
USB_CC1: D1002.1, J1000.A5, U1000.1, U1000.2
USB_CC2: D1003.1, J1000.B5, U1000.4, U1000.5
USB_VBUS: C1000.1, D1001.1, J1000.A4, J1000.A9, J1000.B4, J1000.B9, Q1000.5, Q1000.6, Q1000.7, Q1000.8, R1001.1, TP1000.1, U1000.24

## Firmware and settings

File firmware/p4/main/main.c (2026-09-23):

// KINO D4 P4 main controller — Milestone 1. Boots, mounts SD, serves KDP on
// USB-Serial-JTAG, probes CAM1 in the background. Capture priority over
// background work arrives with the capture coordinator in milestone 2.
#include <stdio.h>

#include "audio.h"
#include "buttons.h"
#include "cam_link.h"
#include "node_link/node_link.h"
#include "capture.h"
#include "gallery.h"
#include "thumb.h"
#include "clock.h"
#include "config_store.h"
#include "display.h"
#include "touch.h"
#include "ui.h"
#include "viewfinder.h"
#include "esp_log.h"
#include "esp_app_desc.h"
#include "fw_update.h"
#include "esp_core_dump.h"
#include "esp_heap_caps.h"
#include "esp_mac.h"
#include "freertos/FreeRTOS.h"
#include "freertos/task.h"
#include "hardware_validation.h"
#include "kdp_server.h"
#include "klog.h"
#include "lid.h"
#include "esp_timer.h"
#include "net_hosted.h"
#include "net_link.h"
#include "nvs.h"
#include "nvs_flash.h"
#include "power.h"
#include "roll_state.h"
#include "safe_mode.h"
#include "storage.h"
#include "storage_watch.h"
#include "taskmon.h"
#include "upload_queue.h"
#include "wifi_creds.h"

static const char *TAG = "kino_p4";

/*
 * A capture just landed, so the card has one more photograph on it.
 *
 * Told, not discovered. This used to call gallery_refresh(), which walked the
 * whole captures directory and read a META.JSON per folder to work out where
 * the new picture belonged in the newest-first order - on the capture task,
 * with the next shutter press behind it. The capture already knows both facts
 * the order needs, so it hands them over: the folder name and the instant.
 *
 * `r->captured_at_ms` is the same value the capture writes into META.JSON as
 * `capturedAtMs`, which is the field the gallery sorts on - so a told order and
 * a rebuilt order agree by construction rather than by luck. `r->uuid` is the
 * folder name.
 *
 * Only when a capture actually reached the card: a report with nothing stored
 * has no folder to show, and gallery_note_added would name a directory that
 * does not exist. gallery_refresh() after it, because the page on screen still
 * has to be redrawn.
 */
static void gallery_on_capture(const capture_report_t *r) {
  if (r != NULL && r->ok && r->stored > 0 && r->uuid[0] != '\0') {
    gallery_note_added(r->uuid, (uint64_t)(r->captured_at_ms > 0 ? r->captured_at_ms : 0));
  }
  gallery_refresh();
}

/** HELLO timeout for a channel that answered nothing last time. */
#define OFFLINE_PROBE_MS 300u

static uint32_t next_boot_count(void) {
  nvs_handle_t nvs;
  uint32_t count = 0;
  if (nvs_open("kino", NVS_READWRITE, &nvs) == ESP_OK) {
    nvs_get_u32(nvs, "boot", &count);
    count++;
    nvs_set_u32(nvs, "boot", count);
    nvs_commit(nvs);
    nvs_close(nvs);
  }
  return count;
}

/*
 * The rate to drive the link to, from the config, checked against the rates a
 * node will actually accept.
 *
 * A value that is not one of them - a typo, a stale key, a zero left behind by
 * something trying to clear it - would otherwise be handed to
 * camlink_resync_baud_ch(), which would ask every node for a rate each one
 * refuses and then put them all back. Anything unrecognised means the
 * preferred rate, and says so once.
 */
static uint32_t link_baud_from_config(void) {
  static const uint32_t supported[NL_BAUD_SUPPORTED_N] = NL_BAUD_SUPPORTED_LIST;
  const uint32_t want = (uint32_t)config_int("body.linkBaud", NL_BAUD_PREFERRED);
  for (int i = 0; i < NL_BAUD_SUPPORTED_N; i++) {
    if (supported[i] == want) return want;
  }
  klog("P4", "body.linkBaud %lu is not a rate a node takes; using %d", (unsigned long)want,
       NL_BAUD_PREFERRED);
  return NL_BAUD_PREFERRED;
}

/*
 * Bring every channel to `want`, or leave them all on the default.
 *
 * All four together on purpose. A capture ends when its slowest link ends, so
 * one camera stuck at 921600 makes the whole shutter as slow as it was and the
 * other three gain nothing - a mixed link is all cost and no benefit, and a
 * state nobody can read at a glance.
 *
 * A channel with nothing fitted answers at no rate at all and is not a
 * failure; a channel whose node is found and will not move is. The first of
 * those stops the sweep, because a body that cannot hold the rate should find
 * that out in one channel's time rather than four.
 *
 * Returns false when a capture owns the cameras, so the next sweep tries again
 * rather than leaving the link half-set.
 */
static bool settle_link_baud(uint32_t want) {
  bool demote = false;
  for (int cam = 0; cam < CAMLINK_CAMS; cam++) {
    if (!capture_probe_begin(cam)) return false;
    const esp_err_t err = camlink_resync_baud_ch(cam, want);
    capture_probe_end(cam);
    if (err == ESP_ERR_NOT_FOUND) continue; /* nothing fitted on this channel */
    if (err != ESP_OK) {
      demote = true;
      break;
    }
  }
  if (!demote) return true;

  klog("P4", "a camera would not hold %lu baud; all four back to %d", (unsigned long)want,
       NL_DEFAULT_BAUD);
  for (int cam = 0; cam < CAMLINK_CAMS; cam++) {
    if (!capture_probe_begin(cam)) continue;
    camlink_resync_baud_ch(cam, NL_DEFAULT_BAUD);
    capture_probe_end(cam);
  }
  return true;
}

// Keep CAM1 identity fresh: probe every 2 s while offline, every 10 s while
// online. GET_CAMERA_INFO reads the cached result instead of blocking.
/**
 * Keep every camera's online state current, not just CAM1's.
 *
 * This used to greet CAM1 alone, which was right when one node was all the
 * harness had. It stopped being right the moment a capture asked which
 * cameras to fire: a channel that has never been greeted reports offline, so
 * a body with four nodes wired would have taken a one-frame photograph and
 * called three cameras missing. The viewfinder happens to exercise all four,
 * but only while its screen is showing, which is not a state the shutter can
 * depend on.
 *
 * Channels are greeted in turn rather than at once. Four HELLOs on four UARTs
 * would be faster and would also mean four timeouts landing together every
 * two seconds on a bench unit with one node fitted.
 */
static void cam_probe_task(void *arg) {
  (void)arg;
  bool was_online[CAMLINK_CAMS] = {false};
  /*
   * The link's rate, settled once per boot, for all four channels.
   *
   * The nodes do not share the body's reset, so after a restart the body's
   * UARTs are back at NL_DEFAULT_BAUD and the nodes are wherever they were
   * left. Two cases and one answer (#221): the stored rate is not what this
   * end is on, so the nodes have to be moved to it; or the stored rate is the
   * default and a node is still somewhere else, so it has to be found.
   * camlink_resync_baud_ch() handles both - it tries the intended rate first,
   * which is one HELLO on every boot where nothing moved.
   *
   * All four in one go rather than per channel, because the rate is only
   * worth having if every link takes it (settle_link_baud).
   *
   * Here rather than in app_main() because a body with no nodes fitted pays
   * three extra probes per channel, and that belongs in the background sweep
   * rather than in front of the splash.
   */
  bool baud_settled = false;
  const uint32_t link_baud = link_baud_from_config();
  for (;;) {
    /*
     * Maintenance, one bounded transaction at a time, and never in the
     * shutter's way.
     *
     * Two hazards shaped this loop. A HELLO slipping between two chunk reads
     * of a live transfer opens with uart_flush_input() and loses the chunk -
     * the per-chunk byte loss the bench once recorded. And a HELLO into an
     * empty socket holds that channel's mutex for its whole timeout, so a
     * capture starting behind it waited seconds. The first answer to both was
     * to take capture_lock() for the whole sweep, which made a CAMERA_CAPTURE
     * arriving mid-sweep answer BUSY "A capture is already running" with no
     * capture running (Gate F bench 2026-08-30: 14 of 20 idle requests, then
     * 5 of 41 after the probe was shortened).
     *
     * capture_probe_begin() is the scheduler's answer (cam_sched.h): a probe
     * may start only while no capture is admitted, so nothing lands inside a
     * transfer; a capture admitted while one probe is on the wire waits for
     * that transaction alone - 300 ms on an empty socket, milliseconds on a
     * node that answers - and starts. The channel mutex in cam_link.c still
     * keeps the wire serial. The sweep holds nothing between channels, so a
     * shutter press lands in the gap and maintenance stands aside; a deferred
     * sweep simply comes back.
     */
    /* The rate, before anything asks a node a question at the wrong one. */
    if (!baud_settled) baud_settled = settle_link_baud(link_baud);

    int online_count = 0;
    bool deferred = false;
    for (int cam = 0; cam < CAMLINK_CAMS; cam++) {
      if (!capture_probe_begin(cam)) {
        deferred = true;
        break;
      }
      /* A channel believed empty gets a short HELLO: the default 3000 ms per
       * absent channel cost ~9 s of probing every ~19 s on a one-camera body.
       * A node that is present answers in a few milliseconds; one that has
       * stopped answering costs one 3000 ms transaction before it is marked
       * offline, and that is the longest a capture can ever wait here. */
      const uint32_t probe_ms = was_online[cam] ? 3000u : OFFLINE_PROBE_MS;
      const bool online = camlink_hello_ch_timeout(cam, probe_ms) == ESP_OK;
      capture_probe_end(cam);
      if (online) {
        online_count++;
        /* A node that answered HELLO gets one STATUS too: that is the reply
         * carrying its die temperature (and heap), which HELLO does not, and
         * nothing else asked for it - GET_RUNTIME_STATS tempC.cams held
         * whatever the last bench capture happened to leave on cam1 and null
         * for the rest. Its own probe window, so a shutter press between the
         * two transactions still lands in the gap; a deferral here leaves
         * the previous sample standing, which is what "cached" means. */
        if (capture_probe_begin(cam)) {
          (void)camlink_ping_ch(cam, NULL);
          capture_probe_end(cam);
        }
      }
      if (online == was_online[cam]) continue;

      char tag[4];
      snprintf(tag, sizeof tag, "C%d", cam + 1);
      if (online) {
        camlink_info_t info;
        camlink_get_info_ch(cam, &info);
        klog(tag, "node online — fw %s, sensor %s, boot %s", info.firmware,
             info.sensor_detected ? info.sensor : "none", info.reset_reason);
      } else {
        klog(tag, "node offline — stopped answering");
      }
      was_online[cam] = online;
    }
    if (deferred) {
      /* A capture has the cameras. Come back when it is likely done: one
       * capture is ~1.5 s on this body. No lock is held while waiting. */
      vTaskDelay(pdMS_TO_TICKS(500));
      continue;
    }
    /* Slow down once anything has answered. A body that is up needs its
     * cameras confirmed occasionally; an empty bench harness needs a retry
     * often enough that plugging a node in feels immediate. */
    vTaskDelay(pdMS_TO_TICKS(online_count > 0 ? 10000 : 2000));
  }
}


/*
 * The last panic, said out loud at boot.
 *
 * The console is UART0 only since 0.4.43 (KDP owns USB-Serial-JTAG), so the
 * panic handler's backtrace reaches nobody on the bench. The coredump in
 * flash has it: the crashing task, its PC, and the RISC-V trap cause and
 * value, which espcoredump does not print for this chip. One line per boot
 * while a dump exists, so GET_LOGS carries the cause of the last crash until
 * the next one overwrites it. The 2026-09-05 panic (capture task, inside
 * sprintf while writing UPLOAD.JSON, 1.5 KB of stack free) is the case this
 * would have answered.
 */
static void log_last_panic(void) {
  if (esp_core_dump_image_check() != ESP_OK) return;
  esp_core_dump_summary_t *s = heap_caps_calloc(1, sizeof *s, MALLOC_CAP_SPIRAM | MALLOC_CAP_8BIT);
  if (s == NULL) return;
  if (esp_core_dump_get_summary(s) == ESP_OK) {
    /*
     * Whose dump this is. A dump from a different image cannot be decoded
     * against this build's ELF, and the bench read "last panic: task vf_cam3"
     * for weeks from an image long since replaced. It is reported once, named
     * as the older firmware's, and erased, so the line that stays in the ring
     * is always about the firmware that is running.
     */
    char running[APP_ELF_SHA256_SZ + 1] = "";
    esp_app_get_elf_sha256(running, sizeof running);
    const bool ours = strncmp((const char *)s->app_elf_sha256, running, APP_ELF_SHA256_SZ - 1) == 0;
    klog("P4", "last panic%s: task %s pc 0x%08lx mcause 0x%lx mtval 0x%08lx ra 0x%08lx sp 0x%08lx",
         ours ? "" : " (older firmware, dump erased)", s->exc_task, (unsigned long)s->exc_pc,
         (unsigned long)s->ex_info.mcause, (unsigned long)s->ex_info.mtval,
         (unsigned long)s->ex_info.ra, (unsigned long)s->ex_info.sp);
    if (!ours) esp_core_dump_image_erase();
  }
  free(s);
}

void app_main(void) {
  esp_err_t err = nvs_flash_init();
  if (err == ESP_ERR_NVS_NO_FREE_PAGES || err == ESP_ERR_NVS_NEW_VERSION_FOUND) {
    /* These were the last two ESP_ERROR_CHECKs in the firmware, on the first
     * statements of a boot written from end to end to degrade. The branch is
     * entered by design after a partition-table change (#143), and inside it
     * nvs_flash_erase() answers ESP_ERR_NOT_FOUND on a table with no nvs
     * partition and nvs_flash_init() can fail on a corrupt key partition -
     * each of which aborted before kdp_server_start() and display_init(), so
     * the panic took the recovery channel and the screen with it, and
     * PANIC_REBOOT_DELAY 0 made it a tight loop. Every NVS consumer already
     * treats a failed open as "no key": a camera with no NVS still takes
     * photographs to the card, and says why it has no settings. */
    const esp_err_t erase = nvs_flash_erase();
    err = erase == ESP_OK ? nvs_flash_init() : erase;
  }
  if (err != ESP_OK) {
    ESP_LOGE(TAG, "NVS unavailable: %s - booting without persisted settings",
             esp_err_to_name(err));
  }

  /* Settings load before any subsystem reads one. Power management, the UI
   * and the KDP config commands all sit on top of this. */
  config_init();

  kdp_identity_t id;
  uint8_t mac[6] = {0};
  esp_efuse_mac_get_default(mac);
  snprintf(id.serial, sizeof id.serial, "KD4-%02X%02X%02X", mac[3], mac[4], mac[5]);
  snprintf(id.device_id, sizeof id.device_id, "kino-%02x%02x%02x", mac[3], mac[4], mac[5]);
  snprintf(id.session_id, sizeof id.session_id, "boot-%lu",
           (unsigned long)next_boot_count());

  /* The clock before anything that timestamps: config_init is settings only,
   * but the first capture can happen the moment KDP is up. */
  clock_init();

  klog_init();
  /* Telemetry off unless this body has been asked for it. See klog.h for what
   * belongs on which channel (#202). */
  klog_set_telemetry(config_bool("body.log.telemetry", false));
  klog("P4", "boot %s serial %s session %s", KINO_FW_VERSION, id.serial, id.session_id);
  log_last_panic();
  safe_mode_boot();
  ESP_LOGI(TAG, "P4_BOOT %s serial %s session %s transport usb-serial-jtag",
           KINO_FW_VERSION, id.serial, id.session_id);
  hwv_init();
  storage_init(); /* mount failure is a reported state, not a boot failure */

  /* Clean up captures that never got their META.JSON.
   *
   * META.JSON is written last, so a folder without one is an interrupted
   * commit - a reboot, a brownout, or a card pulled between the last frame
   * and the metadata. It can never become a valid capture and nothing will
   * ever explain the JPEGs inside it. Here, at boot, is the only moment
   * nothing else is writing to the card.
   *
   * Bounded and conservative: only UUID-shaped directories, only the names in
   * STORAGE_CAPTURE_FILES, and an orphan containing anything else is
   * preserved rather than forced. See storage_sweep_orphans.
   *
   * Time-bounded, which matters HERE rather than in storage.c: this line is
   * ahead of kdp_server_start() and of the display, so its cost is dead time
   * with nothing on the screen and no host able to connect. A card carrying
   * 520 captures spent about a minute here. The sweep now stops at its budget
   * and reports what it left for the next boot. */
  storage_sweep_t sweep;
  storage_sweep_orphans(&sweep);

  /* The camera link, and its failure is reported like every other line here.
   *
   * This was ESP_ERROR_CHECK, which aborts - the one abort in a boot sequence
   * written from end to end to degrade. It also fired twenty lines BEFORE
   * kdp_server_start(), so the failure it caught took the recovery channel with
   * it: a body that panicked here had no KDP, no console commands and nothing
   * to diagnose it with except the backtrace.
   *
   * Nothing downstream needs the link to have come up. camlink_init() reports
   * a port that will not install per channel and carries on, and every
   * per-channel entry point tests valid_cam() first - which is false for a
   * channel with no mutex, including all four when this never ran. The camera
   * then behaves exactly as it does with no nodes fitted: offline cameras, a
   * capture that fails CAMERA_OFFLINE, and a screen that says so. */
  esp_err_t cl_err = camlink_init();
  if (cl_err != ESP_OK) {
    ESP_LOGE(TAG, "camera link unavailable: %s - every camera reads offline",
             esp_err_to_name(cl_err));
  }

  /* Capture before the KDP server, because CAMERA_CAPTURE is dispatched the
   * instant the server is listening and a NACK saying "not ready" on the
   * first frame after boot would be this firmware's own fault. */
  /* Thumbnails are optional: a camera whose JPEG codec will not start still
   * takes and stores photographs, and every reader treats a missing
   * THUMB.JPG as absent rather than as damage. */
  esp_err_t th_err = thumb_init();
  if (th_err != ESP_OK) {
    ESP_LOGW(TAG, "thumbnails unavailable: %s - captures are unaffected",
             esp_err_to_name(th_err));
  }

  esp_err_t cap_err = capture_init(id.device_id);
  if (cap_err != ESP_OK) {
    ESP_LOGE(TAG, "capture unavailable: %s - the camera cannot take pictures",
             esp_err_to_name(cap_err));
  }

  esp_err_t kdp_err = kdp_server_start(&id);
  if (kdp_err != ESP_OK) {
    // No silent boot hang: the device keeps running, the console says why
    // Studio cannot connect, and the camera/SD paths stay debuggable.
    ESP_LOGE(TAG, "KDP server unavailable: %s", esp_err_to_name(kdp_err));
  } else {
    ESP_LOGI(TAG, "KDP_READY session %s", id.session_id);
  }
  TaskHandle_t probe = NULL;
  /* 8192, not 4096. Measured on the first P4 bring-up (firmware 0.3.0, no
   * nodes fitted): cam_probe sat at 356 free bytes of 4096 — steady across
   * six GET_RUNTIME_STATS calls — while doing nothing but timing out on four
   * channels. The online branch is the expensive one: it puts a
   * camlink_info_t (~128 B) on this stack, fills it through
   * camlink_get_info_ch(), then formats a klog line through varargs. That
   * path first runs the instant CAM1 answers, so the overflow would land on
   * the node-greeting checkpoint and read as a link or node fault. */
  /* Checked, like capture.c checks its own xTaskCreate calls. A task that was
   * not created still leaves a NULL handle here, and taskmon_register() would
   * then list a task that does not exist - so the stack report that exists to
   * find this kind of fault would be the thing hiding it. */
  if (xTaskCreate(cam_probe_task, "cam_probe", 8192, NULL, 5, &probe) != pdPASS) {
    ESP_LOGE(TAG, "camera probe unavailable: %s - online state will not refresh",
             esp_err_to_name(ESP_ERR_NO_MEM));
  } else {
    taskmon_register("cam_probe", probe);
  }

  /* The panel comes up last, deliberately, and its failure is never fatal.
   * It is the newest and least proven peripheral on this board, and KDP over
   * USB is the only way to diagnose or recover the device — so a display
   * that cannot start must leave a camera that can still be talked to. The
   * same ordering the camera bench tool learned: bring up the thing that
   * lets you look at the problem before the thing that might be one. */
  esp_err_t lcd_err = display_init();
  if (lcd_err != ESP_OK) {
    ESP_LOGE(TAG, "display unavailable: %s — KDP and storage are unaffected",
             esp_err_to_name(lcd_err));
  } else {
    display_test_pattern();
    /* Audio BEFORE touch, and the order is load-bearing.
     *
     * The ES8311 shares one I2C bus with the GT911, and the touch driver
     * starts a task that polls it every 20 ms. Bringing the codec up behind
     * that failed every transaction with a NACK at 0x18, while a bus scan on
     * a quiet bus saw 0x18 answer perfectly well. The codec gets the bus
     * while it is still calm; the touch poll can contend with nothing
     * afterwards.
     *
     * A camera with no sound is still a camera, so failure is reported and
     * ignored rather than gating the screen. */
    esp_err_t au_err = audio_init();
    if (au_err != ESP_OK) ESP_LOGE(TAG, "audio unavailable: %s", esp_err_to_name(au_err));
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

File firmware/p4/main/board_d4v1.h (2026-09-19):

// KINO D4 V1 pin map for the Guition JC4880P443C-I-W (ESP32-P4 + ESP32-C6).
// Every P4 pin assignment lives in this file — no raw GPIO numbers elsewhere.
// packages/hardware-profiles/src/profiles/d4-v1.json mirrors this file, not
// the other way round; host_tests/test_board_pins.c --dump is the cross-check.
//
// The camera/sync assignments below are header-correct (the pins exist and
// are free) and electrically UNVALIDATED until a node answers on each one
// (issue #2). The SD block was validated by a real 4-bit mount on 2026-08-26.
#ifndef BOARD_D4V1_H
#define BOARD_D4V1_H

// --- JP1, the 2x13 2.54 mm header, MEASURED on the board ---
//
// Odd pins are the LEFT column, even the RIGHT, pin 1 at the top.
//
//     pin  left            right       pin
//      1   3V3             5V           2
//      3   3V3             5V           4
//      5   GND             GND          6
//      7   GPIO52          GPIO33       8
//      9   GPIO51          GPIO31      10
//     11   GPIO50          GPIO30      12
//     13   GPIO49          GPIO29      14
//     15   GPIO35          GND         16
//     17   GPIO34          ESP_3V3     18
//     19   GPIO32          C6_U0RXD    20
//     21   GPIO28          C6_U0TXD    22
//     23   I2C_SDA         C6_IO9      24
//     25   I2C_SCL         C6_CHIP_PU  26
//
// Twelve P4 GPIOs reach the header: 52, 51, 50, 49, 35, 34, 32, 28 on the
// left and 33, 31, 30, 29 on the right. Eleven signals are wanted -- four
// TX/RX pairs, SYNC_OUT, CAM_PWR_EN, BTN_SHUTTER -- so GPIO35 (pin 15) is
// still the one spare. Eleven, not twelve: FLASH_EN held GPIO28 / pin 21
// under ECN-0002 and handed it to the shutter button on 2026-08-30
// (ECN-0003). Right column pins 20/22/24/26 are the C6 programming and
// recovery lines and stay reserved; pin 18 is the C6's own supply.
//
// THIS TABLE IS MEASURED, NOT TRANSCRIBED. It has been wrong twice, both
// times from copying someone's table:
//
//   1bc8a7e  entered from an assumed third-party expansion list
//   944b68e  "corrected" to the JC-ESP32P4-M3-DEV pinout -- a DIFFERENT
//            carrier that happens to use the same P4 module. That map put
//            CAM1 on GPIO1/GPIO2, which reach nothing here, and the bench
//            spent a session proving it: a node that never answered, then a
//            TX-to-RX loopback on JP1 7-9 that received zero bytes.
//
// It was then settled electrically. The P4 drove every GPIO in turn, each
// announcing its own index in binary, while a node watched one wire:
//
//   JP1 13 (7th down, left)  -> GPIO49
//   JP1  7 (4th down, left)  -> GPIO52   (predicted before the run)
//
// Both agree with the manufacturer PIN DEFINITIONS drawing for the
// JC4880P443C-I-W, which is the board we actually have. ECN-0002.
//
// Do not edit these numbers from a datasheet, a photo of another board, or a
// vendor page. Measure the pin. firmware/p4/host_tests/test_board_pins.c
// and board_d4v1_checks.h hold the table to itself; only the bench can hold
// it to the copper.
//
// UART TX/RX on the P4 go through the GPIO matrix on every port; there is no
// IOMUX restriction, so any header GPIO can carry any of UART1-4.

// Unassigned control line. Numerically equal to GPIO_NUM_NC (-1); every user
// must skip gpio_config and gpio_set_level for a pin equal to this.
#define BOARD_GPIO_NONE (-1)

// --- Camera nodes, one UART each ---
// UART0 is the console, so the four remaining ports carry the four cameras,
// which is what lets four transfers overlap instead of queueing.
// BOARD_*_JP1 is the header pin the wire lands on.
#define BOARD_CAM1_UART_NUM 1
#define BOARD_CAM1_TX 52
#define BOARD_CAM1_RX 51
#define BOARD_CAM1_TX_JP1 7
#define BOARD_CAM1_RX_JP1 9

#define BOARD_CAM2_UART_NUM 2
#define BOARD_CAM2_TX 50
#define BOARD_CAM2_RX 49
#define BOARD_CAM2_TX_JP1 11
#define BOARD_CAM2_RX_JP1 13

#define BOARD_CAM3_UART_NUM 3
#define BOARD_CAM3_TX 34
#define BOARD_CAM3_RX 33
#define BOARD_CAM3_TX_JP1 17
#define BOARD_CAM3_RX_JP1 8

#define BOARD_CAM4_UART_NUM 4
#define BOARD_CAM4_TX 30
#define BOARD_CAM4_RX 29
#define BOARD_CAM4_TX_JP1 12
#define BOARD_CAM4_RX_JP1 14
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

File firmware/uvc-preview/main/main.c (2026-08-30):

// KINO D4 bench tool — look at one camera module over USB-C, before any
// harness exists to look at it through.
//
// This is not product firmware and never ships in a camera. `camnode` serves
// the P4 over UART1 and captures one JPEG when asked, which is the wrong shape
// for judging a module you are holding: focus, the OV3660's colour cast,
// framing and dropped frames are things you watch, not things you sample. So
// the board presents itself as a plain USB webcam and any camera app on the
// host is the viewer. No host tooling, no Wi-Fi, no P4.
//
// Two consequences of TinyUSB owning the one USB PHY, both deliberate:
//   * The console is on UART0 (GPIO43/44), not USB-Serial-JTAG. Plugging this
//     board in gives you a camera, not a serial port.
//   * Reflashing needs the ROM download mode — hold BOOT, tap RESET. The
//     README spells this out; it is the first thing that catches people.
// The LED is therefore the only feedback you get without a UART adapter, so it
// carries the boot verdict.

#include <assert.h>
#include <stdarg.h>
#include <stdio.h>
#include <string.h>

#include "board_xiao_s3.h"
#include "driver/gpio.h"
#include "driver/usb_serial_jtag.h"
#include "esp_camera.h"
#include "esp_heap_caps.h"
#include "esp_log.h"
#include "esp_memory_utils.h"
#include "esp_timer.h"
#include "freertos/FreeRTOS.h"
#include "freertos/task.h"
#include "usb_device_uvc.h"

/* The XIAO's BOOT button. Pressed during the window after boot it selects
 * console mode below. Held DURING power-up it does something else entirely:
 * GPIO0 low at reset is the ROM's own download-mode strap. */
#define BOOT_BUTTON_GPIO 0

static const char *TAG = "uvc-preview";

/**
 * One JPEG frame has to fit here whole, and a frame that does not fit is
 * dropped by the driver — which on a bench reads as "this module is bad".
 *
 * Measured rather than guessed: VGA at quality 12 produces 7.7-30.4 KB over
 * 210 frames in console mode. The first figure here was 160 KB, five times
 * what the default mode needs, and internal RAM is the budget that matters:
 * USB DMA streams out of this buffer so it cannot live in PSRAM, and bulk
 * transfer mode failed to boot for want of internal memory. 96 KB still
 * covers a host requesting one of the larger descriptor sizes while handing
 * that budget 64 KB back.
 */
#define UVC_BUFFER_SIZE (96 * 1024)

/* Seeed wires the user LED active-low. */
#define LED_ON 0
#define LED_OFF 1

static camera_fb_t *s_cam_fb; /* held between fb_get and fb_return */
static uvc_fb_t s_uvc_fb;
static uint32_t s_frames;
static uint32_t s_empty;
static int64_t s_started_us;

static void led_init(void) {
  gpio_config_t cfg = {
      .pin_bit_mask = 1ULL << BOARD_LED,
      .mode = GPIO_MODE_OUTPUT,
      .pull_up_en = GPIO_PULLUP_DISABLE,
      .pull_down_en = GPIO_PULLDOWN_DISABLE,
      .intr_type = GPIO_INTR_DISABLE,
  };
  gpio_config(&cfg);
  gpio_set_level(BOARD_LED, LED_OFF);
}

static void led_blink(int times, int period_ms) {
  for (int i = 0; i < times; i++) {
    gpio_set_level(BOARD_LED, LED_ON);
    vTaskDelay(pdMS_TO_TICKS(period_ms / 2));
    gpio_set_level(BOARD_LED, LED_OFF);
    vTaskDelay(pdMS_TO_TICKS(period_ms / 2));
  }
}

/**
 * The board has no console on the port you just plugged in, so the LED is the
 * verdict: a fast blink forever means the sensor never answered, and no amount
 * of staring at a camera app tells you that. Never returns, by design — there
 * is nothing else useful for this firmware to do.
 */
static void led_fault_forever(void) {
  for (;;) led_blink(1, 200);
}

/* Defined below, next to the reasoning for each value it sets. */
static void tune_sensor(sensor_t *s);

static framesize_t framesize_for(int width, int height) {
  if (width <= 320) return FRAMESIZE_QVGA;
  if (width <= 480) return FRAMESIZE_HVGA;
  if (width <= 640) return FRAMESIZE_VGA;
  if (width <= 800) return FRAMESIZE_SVGA;
  if (height <= 720) return FRAMESIZE_HD;
  return FRAMESIZE_FHD;
}

/* Host opened the stream. It picks from the descriptors, so honour what it
 * asked for rather than whatever the last session left behind. */
static esp_err_t on_stream_start(uvc_format_t format, int width, int height, int rate,
                                 void *cb_ctx) {
  (void)cb_ctx;
  if (format != UVC_FORMAT_JPEG) {
    ESP_LOGE(TAG, "host asked for a format this build does not produce (%d)", (int)format);
    return ESP_ERR_NOT_SUPPORTED;
  }

  sensor_t *sensor = esp_camera_sensor_get();
  if (sensor == NULL) return ESP_FAIL;
  if (sensor->set_framesize(sensor, framesize_for(width, height)) != 0) {
    ESP_LOGE(TAG, "sensor refused %dx%d", width, height);
    return ESP_FAIL;
  }
  /* A framesize change rewrites the sensor's window, so the tuning goes on
   * after it and not once at boot — otherwise the first stream looks right
   * and every resolution change after it looks untuned. */
  tune_sensor(sensor);

  s_frames = 0;
  s_empty = 0;
  s_started_us = esp_timer_get_time();
  gpio_set_level(BOARD_LED, LED_ON);
  ESP_LOGI(TAG, "stream open: %dx%d @ %d fps, mjpeg", width, height, rate);
  return ESP_OK;
}

static uvc_fb_t *on_frame_get(void *cb_ctx) {
  (void)cb_ctx;
  s_cam_fb = esp_camera_fb_get();
  if (s_cam_fb == NULL) {
    /* Counted rather than ignored: an empty frame buffer while the host is
     * still asking is the signature of a sensor or a DVP bus struggling, and
     * the count at stream close is the only place it surfaces. */
    s_empty++;
    return NULL;
  }
  s_uvc_fb.buf = s_cam_fb->buf;
  s_uvc_fb.len = s_cam_fb->len;
  s_uvc_fb.width = s_cam_fb->width;
  s_uvc_fb.height = s_cam_fb->height;
  s_uvc_fb.format = UVC_FORMAT_JPEG;
  s_uvc_fb.timestamp = s_cam_fb->timestamp;
  s_frames++;
  return &s_uvc_fb;
}

static void on_frame_return(uvc_fb_t *fb, void *cb_ctx) {
  (void)fb;
  (void)cb_ctx;
  if (s_cam_fb != NULL) {
    esp_camera_fb_return(s_cam_fb);
    s_cam_fb = NULL;
  }
}
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

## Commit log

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2026-08-21 feat(firmware): D4-V1 Milestones 1+1B — P4 + camnode firmware, bench diagnostics
    New firmware/ tree (ESP-IDF v5.5.1, MIT): portable KDP C core with 42
    host-test checks against the contract fixtures, ESP32-P4 app (KDP server on
    USB-Serial-JTAG, SDMMC storage, CAM1 node-link client) and the shared
    ESP32-S3 camnode app (runtime SCCB sensor detect, JPEG capture, chunked
    CRC-verified read-out). Both build clean in espressif/idf:v5.5.1.
    Milestone 1B bench surface (issue #66), gated by the benchDiagnostics
    capability: measured CAMERA_TEST with per-stage timing buckets and three
    agreeing CRC-32 checksums (node / transfer / stored read-back),
    STORAGE_SELF_TEST with exact failing phase, CAMERA_LINK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
    [board_d4v1.h, cam_link.c, camera.c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]
2026-08-21 feat(firmware): runtime stats, device log ring, honest self-test
    GET_RUNTIME_STATS now answers with real numbers only: uptime, reset reason,
    heap/PSRAM, die temperatures from the actual P4 and S3 on-chip sensors, and
    protocol counters from the live decoder/link/storage state. The contract
    tempC shape widens to number|null so an offline camera reports null instead
    of an invented figure; Studio renders the dash.
    GET_LOGS/CLEAR_LOGS serve a 200-entry structured log ring (contract
    LogEntry) that also pushes live Evt.LOG frames, so Studio LogViewer works at
    the bench. Log hooks cover boot, SD mount, node online/offline transitions,
    capture complete/failed, self-test, and soak completion.
    SELF_T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
    [cam_link.c, kdp_server.c, main.c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]
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2026-08-22 fix(firmware,kdp,studio): hardware-readiness hardening (#80)
    GET_LOGS could never answer once the 200-entry log ring filled: the
    serialized reply exceeds the 16 KB KDP payload cap, kdp_encode_frame
    dropped it silently, and every log fetch timed out forever. klog now
    budgets the reply to the newest entries that fit (oldest-first order
    kept), send_json NACKs INTERNAL_ERROR instead of going silent if a
    reply is still too large, the reference mock applies the same rule
    (shared fitLogEntries), the TS encoder refuses oversized payloads
    loudly, and the contract documents the cap.
    Invisible failures made refusals look like success: the updater's
    fatalError was never rendered anywhere, FACTORY RESET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
    [kdp_server.c]
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2026-08-22 fix(firmware,daemon,ci,docs): firmware dev-readiness audit fixes (#90)
    Daemon manifest now declares the hardware string devices report (V1) -
    compatibleHardware D4-V1 made every built package BLOCKED. Hardware-
    validation NVS status keys are indexed (three item ids exceeded the
    15-char key limit and reverted to UNVALIDATED every reboot); old keys
    still read. link_stats_reset NACKs match link_stats. Daemon: missing
    tooling reported as TOOLING_MISSING with the spawn error in the log,
    WSL distro no longer hardcoded (KINO_FWD_WSL_DISTRO), VITE_KINO_FWD_URL
    mirrors KINO_FWD_PORT into Studio, CORS restricted to localhost origins
    with a Host rebinding guard, docker runs as the invoking user on Linu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
    [hardware_validation.c, kdp_server.c]
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2026-08-23 feat(kdp): decide the six protocol questions physical firmware needs
    The firmware contract listed six items as "firmware team decision
    required". They were open because a physical bring-up cannot guess them,
    and a bench is the wrong place to meet a design question. Closes #5.
    Three are ratifications, not inventions: where the client, the reference
    device and the P4 dispatcher already agreed, the decision is to keep that
    behavior and forbid firmware from being stricter, because changing it
    would break a host that is entitled to the old one.
    - Sequence IDs wrap to 1, never to 0. 0 is the events' sentinel, so a
    uint32 left to overflow starts minting requests that read as events.
    nextSeq()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
    [cam_link.c]
2026-08-23 feat(firmware): make bring-up failures carry their measurement
    Every timeout and failure on the capture path reported a static string.
    On a first bench run that is the least informative outcome available:
    "Chunk read failed mid-transfer" does not say whether the link died at
    4 KB or at 400 KB of a 500 KB JPEG, and the constants it tripped on were
    all chosen before any hardware existed. Closes #119.
    - cam_link request() snapshots the link counters before it waits, so a
    timeout logs elapsed against budget plus the bytes, frames, duplicates
    and CRC errors that arrived during that one request. Silence, a stalled
    transfer and a late reply to an abandoned request needed different
    fixes an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
    [cam_link.c, kdp_server.c]
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2026-08-25 feat(firmware): see one camera module over USB-C before any harness exists
    The XIAO boards arrived and need checking one at a time. camnode cannot
    do it: it serves the node link on UART1 and captures one JPEG on
    request, so nothing it does reaches the USB-C connector, and a still
    frame is the wrong instrument for what is actually wrong with a bad
    module — soft focus, an OV3660 colour cast, a mismatched field of view,
    frames the sensor fails to produce under load. Those are watched, not
    sampled. Closes #123.
    firmware/uvc-preview makes the board a plain USB webcam through
    usb_device_uvc, so any camera app on the host is the viewer: no harness,
    no P4, no Wi-Fi, no host tooling. Bench firmwar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
    [main.c]
2026-08-25 fix(firmware): OV3660 corrupts frames at 20 MHz XCLK; 16 MHz and real tuning
    Measured on the first physical XIAO ESP32-S3 Sense, with
    firmware/uvc-preview as the instrument.
    XCLK 20 MHz corrupted 77 of 160 frames (48%), each carrying a
    chroma-damaged band in a fixed ~12-pixel zone around x=498 - JPEG MCU
    column 31. At 16 MHz, 1 of 200 (0.5%). Corrupted JPEGs at xclk 20 MHz
    are a known esp32-camera problem (espressif/esp32-camera#244) and the
    community guidance is to avoid multiples of 10 MHz on this part.
    This is a product fix, not a bench-tool one. camnode reads the same
    BOARD_CAM_XCLK_HZ and captures over the same DVP bus, so the real D4 was
    configured to corrupt roughly a third of its p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
    [main.c]
2026-08-25 chore(firmware): record the first hardware bench run; close the tuning items
    Module 1 is measured and the loose ends are decided rather than left
    open. Closes the frame-rate question; the two residuals are filed as
    issues (#126, #127) instead of living in chat.
    HARDWARE_VALIDATION.md finally says something true. It read "No physical
    bench run has happened yet" while 200 frames had been measured on real
    hardware. CAM1_SENSOR_DETECT and CAM1_CAPTURE move to VALIDATED on
    observation - PID=0x3660 at SCCB 0x3c, 210 JPEGs into node PSRAM. Only
    those two move: the run was a standalone module over USB with no P4 and
    no harness, so the pin map, the baud and the node link stay UNVALIDATED.
    A row that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
    [main.c]
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2026-08-26 fix(firmware): panel lights - board init table, PSRAM bandwidth, SLPOUT
    First light on the 4.3in ST7701S. Five colour bands on the screen,
    confirmed on hardware. Three faults, found in this order, each hiding
    the next behind the same symptom of a lit backlight over black.
    1. PSRAM at 20 MHz. A DPI panel streams its framebuffer out of PSRAM
    continuously rather than on demand, and the panel said so:
    "can't fetch data from external memory fast enough, underrun happens",
    forever. The requirement is arithmetic - 576x976 clocks per frame at
    34 MHz is ~60 Hz, and 480x800 at 16 bpp is 768 KB, so ~46 MB/s
    sustained. Hex PSRAM moves 2 bytes per clock: 40 MB/s at 20 MHz, just
    short,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
    [display.c]
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2026-08-27 firmware: decouple physical controls and power from display init
    buttons_init() and power_init() sat inside the `if (display_init() == ESP_OK)`
    branch, on the reasoning that power management's job is turning a backlight off
    and a backlight needs a panel.
    That reasoning covered half of what power.c does and none of what buttons.c
    does. The other half drops CAM_PWR_EN, which is what stops four idle camera
    nodes draining the cell, and the buttons are the physical shutter. So a panel
    that failed to initialise took the shutter and the battery protection with it -
    the two things that matter most on a camera whose screen is dead, in a bag, on
    a battery. It would have bitten during exactly the brin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
    [main.c]
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2026-08-27 fix(firmware): the task monitor was reading a deleted task's stack
    The icon builder ends with vTaskDelete(NULL). The registry kept its handle
    and went on calling uxTaskGetStackHighWaterMark() on a freed TCB, so
    GET_RUNTIME_STATS reported freed memory as a stack measurement: 0, then
    1460, then 1380 across three calls seconds apart on the first P4 bring-up,
    drifting as the heap underneath was reused. Zero reads as a task that all but
    overflowed, which is the worst lie this instrument could tell during a
    bring-up.
    A self-deleting task now calls taskmon_task_done() while its own stack is
    still valid; the reading is frozen and the row reports `exited` so nobody
    takes a boot-time number for live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
    [kdp_server.c]
2026-08-27 fix(firmware): cam_probe had 356 bytes of stack left
    Measured on the first P4 bring-up, no nodes fitted, while the task was doing
    nothing but timing out on four empty channels - 356 free of 4096, steady
    across six GET_RUNTIME_STATS calls.
    The branch taken when a node answers is the expensive one: a camlink_info_t
    (~128 B) on this stack, filled through camlink_get_info_ch(), then a klog
    line through varargs. It runs the instant CAM1 first replies, so the overflow
    would have landed on the node-greeting checkpoint and read as a link or node
    fault rather than as a stack that was always too small.
    8192 now. The same measurement reports 4452 free.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
    [main.c]
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2026-08-27 feat(firmware): the C6 radio coprocessor image
    A second image to build, flash and version, as issue #133 notes. It exists now
    rather than after the schematic because the C6's half of the problem is fixed
    in silicon: its SDIO *slave* pads are not routable through the GPIO matrix —
    CLK GPIO19, CMD GPIO18, DAT0-3 GPIO20-23 — so the slave image is correct
    independently of the carrier routing that is still unknown. Waiting would only
    mean writing it later against the same datasheet.
    Not `esp_hosted`, and the reason is measured rather than assumed. The component
    resolves for esp32c6, but its slave is shipped as a standalone IDF project
    rather than a composable component: sourcing `slave/main/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
    [main.c]
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2026-08-27 feat(firmware): a durable Roll upload queue, and the network and roll commands
    Everything issue #133 asks for that does not need the radio, which is most of
    it. `NETWORK_LIST/SET/DELETE/STATUS`, `ROLL_STATUS/JOIN/LEAVE`,
    `UPLOAD_QUEUE_STATUS/RETRY/ENQUEUE` and `FW_QUERY` answer for real; the two
    that are HTTP calls to the Roll API — `ROLL_CREATE` and the slug-only form of
    `ROLL_JOIN` — refuse with `NETWORK_UNAVAILABLE` naming the actual radio state,
    because a specific refusal is a diagnosis and `UNSUPPORTED_COMMAND` is not.
    The queue is the hard part, as the contract says, and it is the part that runs
    with no network at all. `UPLOAD.JSON` lives inside each capture's own folder,
    written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
    [capture.c, kdp_server.c, main.c]
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2026-08-27 fix(firmware): the C6 routing is known, and the card was on the radio's slot
    The previous revision of the hardware map blocked this work because the
    repository recorded no P4-side pin for the C6. An external identification
    against Guition documentation for this carrier supplied one, and rather than
    take it on trust it is reconciled here against two sources inside the
    toolchain. Both agree.
    SDMMC slot 1, GPIO14-17 as D0-D3, GPIO18 CLK, GPIO19 CMD, GPIO54 as the C6's
    CHIP_PU. `espressif/esp_hosted` 3.0.6 pins all six to exactly those numbers for
    a P4 host with a C6 coprocessor — `min == max`, so it is one value and not a
    range — and `ESP_HOSTED_HOST_RESET_GPIO` defaults to 54 for *every*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
    [board_d4v1.h]
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2026-08-27 feat(firmware/c6): the official ESP-Hosted coprocessor, not a bespoke radio app
    The previous attempt concluded that `esp_hosted`'s slave "does not compose as a
    component on IDF 5.5.1" and shipped a hand-written Wi-Fi STA application with a
    marked seam instead. That conclusion was measured against **esp_hosted 0.0.10**,
    a stale package. `espressif/esp_hosted` 3.0.6 resolves for IDF 5.5.1 and is
    restructured: the coprocessor firmware is part of the same component, selected
    by `CONFIG_ESP_HOSTED_CP_*`. So the bespoke application was wrong, and it is
    gone rather than kept because it existed.
    `radio.c`, `transport.c` and `board_c6.h` are deleted. The component owns the
    radio, the RPC server and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
    [partitions_eh_cp_ota_4m.csv]
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2026-08-28 feat(firmware): the C6 registry rows, so the bench has somewhere to write
    Thirteen rows appended to `hwv_item_t`: the slot change, the enable line, the
    SDIO pins, the handshake, the version comparison, scan, associate, DHCP, DNS,
    SNTP, TLS, coexistence, and one capture reaching a Roll.
    Appended, never inserted. The enum ordinal is the NVS key, so shifting it would
    make a unit flashed across the change read its old evidence against the wrong
    rows — a panel that lit coming back as a camera UART that answered. A
    `_Static_assert` keeps the name table in step with the enum, which is the only
    thing that catches a row added in one place and not the other.
    They exist before the bench run rather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
    [hardware_validation.c]
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2026-08-28 fix(hardware): correct JC-ESP32P4-M3 D4 pin map
    The 2x13 expansion header was recorded with GPIO52/51/50/49/35/34/32/28 down
    the left and GPIO33/31/30/29 down the right, and the four camera UARTs were
    assigned to 52/51, 50/49, 34/33 and 30/29. The manufacturer JP1 pinout
    exposes eleven P4 GPIOs — 1, 2, 3, 4, 5, 20, 32, 33, 45, 46, 47 — and none
    of the eight recorded camera pins is on any connector. The rows entered on
    2026-08-21 (1bc8a7e) as hardware data with no manufacturer source; rows 1-3
    and the C6 block matched, so the table passed review.
    GPIO3 and GPIO5 are the touch and panel resets, validated on hardware, so
    nine header pins are free for ten wanted signals. New map, all PROVIS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
    [board_d4v1.h, cam_link.c, capture.c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]
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2026-08-28 fix(hardware): the JP1 map, measured on the board this time
    ECN-0001 replaced the recorded pinout with the manufacturer table for the
    JC-ESP32P4-M3-DEV. That is a different carrier; it shares the ESP32-P4 module
    with our JC4880P443C-I-W and not the expansion header. Under it CAM1 opened
    UART1 on GPIO1/GPIO2, which reach no connector here, so the camera link could
    not work and the failure looked exactly like a wiring fault.
    The bench spent a session on that: a node known good in isolation - camnode
    0.4.1, OV3660 at SCCB 0x3c, PSRAM test OK, listening on UART1 at 921600 -
    answered nothing across 113 frames with 0 CRC errors and 0 resyncs; a
    diagnostic node image logging every byte on its link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
    [board_d4v1.h, cam_link.c, hardware_validation.c]
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2026-08-28 wip(firmware): the frame-ownership race, and the link budgets it hid behind
    NOT FINISHED. Committed because the mechanism is proven and the instruments
    are worth keeping, not because the product path works.
    What is proven. A camera node holds exactly ONE frame: node_server's
    handle_capture releases whatever it held and bumps the frame id, and
    handle_read rejects a stale id with BAD_ID. The viewfinder takes frames on the
    same camera whenever its screen is up, so it destroys the frame a capture is
    mid-way through transferring. The controlled experiment: viewfinder parked in
    MENU, five captures, 5/5 passed with matching CRCs; viewfinder live, four of
    five failed with the transfer dying at 0% a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
    [cam_link.c, capture.c, kdp_server.c]
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2026-08-28 fix(firmware): the link poll was a busy-wait, at 100 Hz a 1 ms delay is no delay
    CONFIG_FREERTOS_HZ is 100, so a tick is 10 ms and pdMS_TO_TICKS(1) rounds to
    zero. vTaskDelay(0) does not block. The "read what has arrived, sleep 1 ms
    otherwise" loop that bought the 10x link speedup therefore never slept: it span
    at task priority for the whole timeout.
    With one camera fitted, three absent channels span out their 900 ms viewfinder
    timeout on repeat. That starved IDLE0 into a task watchdog - the log carries a
    core register dump with cam_probe on CPU 0 - and starved the UI task that feeds
    the DPI panel, which is what was felt as stutter and a flat blue flash.
    Blocking for ONE byte and then drai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
    [cam_link.c, node_server.c]
2026-08-28 fix(firmware): one framebuffer made the preview beat against the sensor clock
    The node ran fb_count=1 with CAMERA_GRAB_WHEN_EMPTY, so the driver filled its
    single buffer after each return and then stalled until the next fb_get. The
    P4's preview pump free-runs against the sensor's frame clock, so a request
    either caught a frame already waiting or blocked for a whole frame period.
    Instrumenting the pump showed it directly. Frame bytes, transfer time and
    decode time were all flat while the hand moved in front of the lens - so
    neither JPEG size nor the wire nor the decoder was responsible - and the
    capture request was bimodal with nothing in between:
    cap 10ms or cap 62-75ms
    which alternat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
    [camera.c]
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2026-08-28 fix(firmware): the capture path was losing UART bytes, invisibly
    The product capture path failed on large frames where CAMERA_TEST succeeded at
    the same size on the same wire. The link reported ~8060 of the 8210 bytes a
    full chunk needs, zero CRC errors, zero resyncs - data that never arrived
    rather than data that arrived wrong. That is an overrun, and two things were
    hiding it.
    uart_driver_install was called with queue size 0 and a NULL queue, which
    discards UART_FIFO_OVF and UART_BUFFER_FULL. Those events are the only report
    the driver makes of a byte it could not keep, so an overrun and a node that
    went quiet looked identical from the P4. Installing an event queue and draining
    it inside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
    [cam_link.c, capture.c]
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2026-08-28 fix(firmware): register C6 hardware validation evidence, at events that prove it
    The 13 C6 rows had no marking sites at all. Adding them exposed the question
    that matters more than the wiring: which event actually proves each row.
    The obvious site for the transport rows was esp_hosted_init() returning 0. It
    is also wrong. Measured on KD4-D121BC this session: init returns 0 and
    rx_ready is 0 - nothing has ever answered on that bus. Had that shipped, the
    registry would have carried C6_SDIO_PINS as VALIDATED on a board whose radio
    has never enumerated, and every later reader would have believed it. The rows
    now key off eh_host_mcu_transport_state_is_rx_ready(), which esp_hosted sets
    from one p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
    [hardware_validation.c]
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2026-08-28 fix(firmware): a viewfinder hold the UI could overwrite, and captures at full size
    viewfinder_hold() never worked, and the reason is one line in ui.c: the UI task
    calls viewfinder_run(s_screen == SCR_SHOOT) on every pass, into the same
    variable the hold cleared. A capture parked the finder and the next UI pass
    restarted it, microseconds later.
    The consequence was not a cosmetic race. On the shoot screen the finder kept
    pumping cam1 while a capture was reading it, so the capture's chunk reads
    interleaved with preview reads on the same channel - visible in the log as
    reads failing at the finder's 600 ms budget rather than the capture's, with
    sequence numbers jumping by ten between chunks. It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
    [cam_link.c, camera.c, capture.c]
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2026-08-28 fix(firmware): the preview stick was a counter that could not recover
    viewfinder_release() guarded its decrement with "if (load() > 0)". The load and
    the subtract are separately atomic and jointly are not, so two releases that
    both observe 1 both decrement and leave -1. vf_may_run() tests for exactly 0
    and the guard then stops any later release from raising a negative value, so
    the finder was off until reboot. The counted veto that replaced the old
    absolute assignment removed an accidental self-heal - the UI's next
    viewfinder_run() used to fix it - and nothing put one back. Decrement first,
    repair and log if it underflows.
    The stutter is a separate fault in the same file. The backoff after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
    [capture.c]
2026-08-29 fix(firmware): CONFIG_UART_ISR_IN_IRAM was the regression, not the fix
    Setting it in 0e2df96 was meant to keep the link ISR running while the flash
    cache is off. It did the opposite. The handler goes to IRAM but the driver's
    ring-buffer code does not, so during a cache-disabled window the ISR runs and
    then cannot store what it just read - bytes dropped by the change meant to stop
    bytes being dropped.
    Found by bisect rather than by reasoning, after the preview degraded from 8.7
    fps to about 1 and CAMERA_TEST went from passing to failing outright. Building
    d505174 and flashing it restored the link, which placed the fault in this
    session's own commits rather than in the wiring:
    d505174 (kno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
    [cam_link.c, capture.c]
2026-08-29 fix(firmware): the compositor was blacking out the link ISR, and captures work
    A capture lost a handful of bytes out of nearly every chunk - 8137 to 8196 of
    the 8210 a full chunk frame needs, zero CRC errors - while CAMERA_TEST moved
    the same frame over the same wire flawlessly. The arithmetic is what found it.
    Losing 14 to 73 bytes past a 128-byte FIFO at 921600 baud means the interrupt
    was off for 1.5 to 2.2 ms. That is far too short for a flash erase, which would
    have cost thousands of bytes, and exactly the length of a cache writeback.
    capture_fire sets s_stage; run_capture never does. ui_task treats a non-idle
    capture stage as "busy" and repaints and presents every 60 to 90 ms for the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
    [cam_link.c, capture.c, main.c]
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2026-08-29 fix(firmware): the gallery showed the oldest first and the photo covered its buttons
    Gallery order. Both listings sorted capture folders by name, and the names are
    UUIDs, so the card came back alphabetical - 007f5d03, 049c0c3e, 05089a35. The
    first page was the oldest pictures on the card and a shot just taken could be a
    hundred entries down. Sorting now uses capturedAtMs out of each META.JSON, read
    with a bounded fread and a strstr rather than a parse.
    The obvious key was the directory timestamp, and it does not work here: stat()
    on the folder AND on its META.JSON both returned times that sorted every
    capture equal, leaving the order exactly as wrong. That is recorded in the
    comment so the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
    [cam_link.c, capture.c, kdp_server.c]
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2026-08-29 fix(firmware): opening the gallery overflowed the UI task's stack
    Sorting the gallery newest-first added capture_taken_ms(), and its char
    path[200] and char head[512] went on the stack of whichever task called
    scan(). That task is not the gallery task: scan() has one caller,
    gallery_refresh(), and its three call sites are all in ui.c - go(), the delete
    dialog, and the post-capture repaint. So 712 bytes of locals, plus snprintf and
    the fopen/esp_vfs/f_open chain, landed about 1.6-2.0 KB deep under the UI
    task's touch handler, and pressing GALLERY panicked and rebooted.
    CONFIG_ESP_SYSTEM_HW_STACK_GUARD catches it the instant SP crosses the base and
    CONFIG_ESP_SYSTEM_NO_BACKTRACE is set, so it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
    [kdp_server.c]
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

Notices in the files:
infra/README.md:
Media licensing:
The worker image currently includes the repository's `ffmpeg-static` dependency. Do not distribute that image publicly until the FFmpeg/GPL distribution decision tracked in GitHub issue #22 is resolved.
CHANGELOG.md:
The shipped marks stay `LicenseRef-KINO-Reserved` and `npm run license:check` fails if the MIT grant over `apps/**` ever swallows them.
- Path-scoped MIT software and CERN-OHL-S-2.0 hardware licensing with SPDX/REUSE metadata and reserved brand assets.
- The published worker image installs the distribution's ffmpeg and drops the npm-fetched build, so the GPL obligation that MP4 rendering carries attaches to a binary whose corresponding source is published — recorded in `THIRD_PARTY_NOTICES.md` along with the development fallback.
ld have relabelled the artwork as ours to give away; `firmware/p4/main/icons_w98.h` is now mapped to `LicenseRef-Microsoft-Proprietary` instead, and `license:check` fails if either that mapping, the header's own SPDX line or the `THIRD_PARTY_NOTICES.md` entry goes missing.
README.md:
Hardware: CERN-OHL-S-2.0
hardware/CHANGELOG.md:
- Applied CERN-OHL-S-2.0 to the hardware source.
